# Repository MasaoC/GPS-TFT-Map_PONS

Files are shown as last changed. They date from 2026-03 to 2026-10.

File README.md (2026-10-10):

# GPS(GNSS)-TFT-map_PONS=Pilot Oriented Navigation System v7
ponsv6image


人力飛行機のパイロットが使いやすいことを目標とした航法装置です。琵琶湖の鳥人間コンテストに特化しています。
GPS/GNSS navigation for human-powered aircraft, specialized for the Japan International Birdman Rally at Lake Biwa, Japan.

 * **現在開いている「v7」は2027、2028年向けに開発設計中のブランチで、正常に動作しない可能性があります。**
 * **このブランチ（`PONSv7.1`）が v7 系の開発先です。** BNO085 を降ろし、
   SCH16T を FPC で外付けした v7.1 基板用。BNO085 を搭載した初代 v7 基板用は
   [`PONSv7`](https://github.com/MasaoC/GPS-TFT-Map_PONS/tree/PONSv7) ブランチです。
 * **v3〜v6が実際にフライト利用したことがある安定版です。**

---

## PONS を導入するメリット

**飛んでいる間の道具であり、飛んだあとの計測器でもあります。**
当日の誘導と、次の機体の設計の両方に活用できます。

### 鳥人間コンテストに特化している点
* すべての機能において、パイロット中心の志向で作られています。
* コース取りはパイロットが画面を見る必要はなく、音声だけで左右の指示が分かります。必要な時に必要なだけ音で変化を知らせます。
  * **Auto 10km** が折返しを認識し、誘導する（→ [大会本番での使い方](#大会本番での使い方auto-10km-モード)）
* 付随機能が豊富
  * **バンク角警告**と**昇降計**が、高度を失う前に気づかせる
* 風を読んでルートを選ぶ。対気速度センサーなしで、機上で**風向・風速を推定**します（→ [風の推定](#風の推定)）。 飛行中も更新されるので、追い風帯を選ぶ・向かい風を避ける根拠になる
* **v7 では PONS Link で、ボートにも同じ画面/数字が出る**

### 次の機体の設計に返す

SD に残るログを `tools/` の解析にかけると、機体特性の分析やパイロット証言の裏付けができます
（→ [ツール (tools/)](#ツール-tools)）。実際に分かったことの例:

* **縦の癖** フゴイド運動の周期、操縦によるものか機体によるものか。
* **横の癖** 2026 機体「陽還」には周期 12.5 秒のはっきりした揺れがあり、
  2025 機体「白夜」には無かった。上反角とラダーの違いが癖として出ていた → 上反角や尾翼まわりの見直しへ
* **構造の設計荷重。** 巡航中の鉛直加速度は実測で最大 +0.18 / −0.25 G（荷重倍数 1.17 / 0.77）
  → 桁の設計荷重の裏取りへ

---

## ドキュメントの役割

| | 中身 |
|---|---|
| **[PONS_HPA v7 説明書](https://docs.google.com/document/d/1KvTG9RTmQfcqMZj5Lb0X9cOWW-vuLJjpPzH3PTkBcsk/)**（Google Docs） | パイロット / ボートマン向け。使い方 — 画面の見方、設定手順、警告音の意味、大会当日の運用。画面写真つき |
| **この README** | 開発者 / 自作する人向け。中身の話 — 設計判断とその理由、部品と発注、生成ツール、ログの形式、実測データ |
| **[ナビゲーション仕様](docs/pons_navigation.md)** | 開発者向け。ロジックの要約 — 方位と距離の出し方、Auto 10km、コース警報 |
| **[音仕様](docs/pons_sound.md)** | 開発者向け。音の仕様 — WAV / トーン / バリオの 3 系統、優先度、同時再生 |
| **[無線 PONS Link仕様](docs/pons_link.md)** | 開発者向け。無線の仕様書 — プロトコル・電波法・実測 |
| **[立ち上げ試験](docs/pons_link_bringup.md)** | 開発者向け。基板到着後の立ち上げ試験手順 |

**使い方だけ知りたい方は説明書をご覧ください。** 取り扱い上の注意、スイッチ・LED の説明、
バッテリーの充電手順もそちらにあります。この README は「なぜそう作ったか」を残す場所です。

---

## 目次

- [PONS を導入するメリット](#pons-を導入するメリット)（誘導 / 風 / 設計へのフィードバック）
- [概要 / Abstract](#概要--abstract)
- [スペック (v7)](#スペック-v7)
- [設計と根拠](#設計と根拠)（姿勢推定 ESKF / 風の推定 / PONS Link 無線）
- [画面と機能の仕様](#画面と機能の仕様)
- [警告音・警報](#警告音警報)
- [大会本番での使い方（Auto 10km モード）](#大会本番での使い方auto-10km-モード)
- [設計上の留意事項](#設計上の留意事項)
- [ハードウェア](#ハードウェア)（発注受付 / 使用部品 / 自作の手順）
- [ソフトウェアのビルド](#ソフトウェアのビルド)
- [SD カードの構成](#sd-カードの構成)（ログ形式 / 目的地・パイロン座標の追加）
- [ツール (tools/)](#ツール-tools)
- [着水（水没）後の処理](#着水水没後の処理)
- [開発者向け](#開発者向け) / [ライセンス](#ライセンス)

---

## 概要 / Abstract

* Arduino（arduino-pico）で書かれた、TFT に GNSS マップ・位置・速度・方位・姿勢を表示する航法装置です。
* 大阪大学 albatross にて使用実績あり
  （2024 追走ボート: v3 / 2025 追走ボート: v4 / 2025 機体搭載「白夜」: v5 / 2026 追走ボート: v6 / 2026 機体搭載「陽還」: v6β）。2025 年大会優勝。
  * **v7 はまだ実戦投入していません。** 基板製作中で、実結線試験もこれからです。
* 最新のソフトウェアバージョンは **0.987**（Build 20261010）。
* 3D プリントケースおよび基板データ（KiCad）あり。ケースは PLA_LW が軽量でおすすめです。
  **v7 用ケースは作成中**で、現状 `case_3Dmodel/` には v6 用のデータしか入っていません。
* PONS for HPA = Pilot Oriented Navigation System for Human-powered aircraft。

### v7 での主な変更点（v6 から）

* **PONS Link（機体⇄ボート テレメトリ無線）を追加。** 920MHz LoRa。
  同じ機体を 3 台つくり、設定で送信機（機体 1 台）と受信機（ボート／プラットフォーム 2 台）を切り替えます。
  パイロットに出ている航法画面を、ボート側でそのまま再現できます（→ [PONS Link](#pons-link機体ボート-テレメトリ無線)）。
* **BNO085 を標準搭載**にし、**気圧計とは別のバス（i2c1）**へ分離。v6 では BNO085 と気圧計が
  i2c0 を共用しており、BNO085 のクロックストレッチでバスがロックすると気圧計も道連れになる
  故障モードがありました。バスを分ければ道連れは起きません。
  ※ v7 の設計当初は SPI 接続にしていましたが、**基板に触れるとジャイロが化ける現象が
  SPI でしか起きなかった**ため、0.976 で **i2c1 固定**にしました
  （→ [docs/imu_i2c_bringup.md](docs/imu_i2c_bringup.md)）。
* **FLASH を 16MB**（W25Q128）に拡張。

## スペック (v7)

| 項目 | 値 |
|---|---|
| サイズ / 重量 | W59 × H81 × D20 mm。重量は **v7 実機での計測待ち**（参考値：v6β 62.4g） |
| TFT | 2.8 インチ **1000 ニト**（v5 の 600 ニトから向上し、晴天下でも視認可）。スイッチで輝度調整可 |
| GNSS | u-blox SAM-M10Q（基板天面配置）。位置精度 1.5m / 速度精度 0.05m/s / 更新レート 2Hz / Cold start 23 秒 |
| 気圧センサー | MS5611。温度・気圧を 2Hz で SD へ記録 |
| モーションセンサー | BNO085 **標準搭載**（v6 では 2 個中 1 個の β 試験版）。i2c1 接続（気圧計とは別バス） |
| 姿勢推定 | **ESKF**（GNSS + BNO085）。実験時の精度はロール・ピッチ 約 1°(95%)、ヨー 約 5°(95%) |
| バリオメーター | **KF**（BNO085 + MS5611）。標準で使用可 |
| 無線 | **PONS Link**。920MHz LoRa（E220-900T22S(JP)、技適取得済・免許不要）。1Hz 送信、実測到達距離 **350m**（要求 200m の 1.75 倍） |
| バッテリー | 860mAh。USB Micro-B で充電（5V1A で十分、空から満充電まで 2〜3 時間）。充電ステータス LED あり |
| 電池持続 | 高輝度 約 3 時間 / 低輝度 約 12 時間 |
| FLASH | 16MB（W25Q128）。ベクタ地図・起動ロゴ・フォントを内蔵 |
| SD 記録 | 緯度・経度・対地速度・時刻・GNSS 精度・捕捉数を 2Hz、気圧・温度、IMU 生ログ、設定と状態と電圧（→ [SD カードの構成](#sd-カードの構成)） |

PONS Link は受信モードで常用すると **+8.2mA**（低輝度で 1 時間ぶん短くなる計算）、
送信モードは **+4.3mA**（SF8・1Hz）です。受信モードのスリープは今後の実装予定で、実装すれば 8.2mA より下がります。

---

## 設計と根拠

ここから先は「なぜこの実装になっているか」の記録です。使い方は説明書を参照してください。

### 姿勢推定（ESKF）

BNO085 内蔵の姿勢推定は、加速度計が測る「比力」を鉛直とみなすため次の 2 つで系統的に誤ります。

* **定常旋回中はロールを過小評価する**（協調旋回では比力の横成分が厳密に 0 になり、加速度計にバンクが見えない）
* **加減速中はピッチがずれる**

また BNO085 単独の YAW 角の基準は「磁場のみ」で推定していましたが、磁場は機体や周辺電子機器の影響で
簡単に 30 度以上の誤差が出てしまい、YAW 角の絶対精度は著しく悪く使えませんでした
（0.983 で地磁気は初期ヨーからも外しました。下記）。

そこで GNSS の TT（航跡角度）と GS（対地速度）を観測に入れた自前の姿勢推定
（誤差状態カルマンフィルター＝ESKF）を実装しました。
対地加速度が分かると比力から遠心力・加減速分を差し引けるので、真の重力方向が求まります。
同時にセンサーの真方位角も求められます。

* 車載実測での単位前後加速度あたりのピッチ誤差：**BNO085 4.4〜5.6 → ESKF 0.2〜0.5 deg/(m/s²)**
* 傾斜台での絶対精度：**-0.46〜-0.63 度**、直交軸への漏れは 0.6 度以下

#### 初期化（0.983 で BNO085 の融合出力への依存を外しました）

0.982 までは初期姿勢を BNO085 の融合出力（GAME_ROTATION_VECTOR）から、初期方位を
地磁気補正付きの ROTATION_VECTOR から貰っていました。0.983 で両方やめ、
**生のジャイロと加速度だけで初期化する**ようにしています。

1. **ロール・ピッチ** … 静止（2 秒）中の平均加速度が重力方向なので、そこから水平を作ります。
   実ログ 5 セッションで GAME_RV とロール・ピッチが **0.05 度以内**で一致したので、
   BNO085 の融合出力は初期姿勢に何も足していませんでした。
2. **ヨー** … 対地速度が 3m/s を超えた最初の測位の**航跡**から入れます。しきい値が
   飛行速度（対気 5.8〜9.0m/s）より十分低いので、注入の瞬間に機体は必ず接地しており、
   **航跡＝機首方位が厳密に成立します**（横滑りできないのでクラブ角が入らない）。
   2025 大会の実機体ログでは発進から 2〜3 秒で条件を満たしていました。
   ヨーが入るまでは `yaw acc` が 180 度のままなので、画面は自動的に方位を灰色にします。
3. **待機中** … ヨーが入るまでは GNSS 速度観測を通しません（ヨー誤差がロール・ピッチへ
   転嫁されるため）。そのあいだ観測が無いので、静止しているあいだ重力方向へ寄せ続け、
   同時にジャイロのゼロ点を測ります。**プラットホーム上で何分待ってもロール・ピッチが保たれます。**

地磁気をやめたのは精度の理由です。2026-09-30 の実測で、地磁気由来の方位は
GNSS 航跡から **57.8 度**ずれていました（BNO085 自身は「25 度以内」と申告）。
GNSS 航跡は真方位なので磁気偏角の補正も要らなくなりました。

副産物として、この経路は**融合出力も地磁気も持たないセンサー**でもそのまま動きます
（→ [docs/imu_sch16t_plan.md](docs/imu_sch16t_plan.md)）。

#### 重力観測（0.984 で足しました）

0.983 で GRV をやめたことで、**GNSS が途絶している間はロール・ピッチを引き戻すものが
1 つも無くなりました**（ジャイロ積分だけになる）。そこを埋めるのがこれです。

準定常のとき、比力をワールド系へ回した値は (0, 0, g) になるはずなので、
**その水平 2 成分を「0 であるべき観測」として入れます**（2Hz）。

* **主ゲートは旋回レート。** `|f| ≒ g` では人力機のバンクを判別できません
  （5 度バンクの `|f|-g` は 0.0375 m/s² で、加速度計のスケール誤差 0.098 m/s² に埋もれる）。
  旋回レートなら 5 度バンクで 6.14 deg/s あり、ジャイロのゼロ点 0.1〜0.3 deg/s に対して
  20〜61 倍の余裕があります。**ジャイロだけで作れるので GNSS 断中も働きます**
* 2026-10-03 の走行 2 時間で検証：GNSS を途中で打ち切ると姿勢誤差の中央値が
  **21.3 → 1.3 度 / 74.9 → 1.8 度**。ゲートは走行中 58〜61%・静止中 97% 開いていました
* 60 秒ログの `gobs=` が観測を入れた累計回数です。**増えていなければゲートが閉じています**

#### Roll/Pitch/Yaw 機能の一括 ON/OFF（マスタースイッチ）

IMU/ESKF 画面の `Roll/Pitch/Yaw func` を OFF にすると、姿勢に関する機能が全て止まり、
見た目も動作も ESKF 導入前と同じ状態に戻ります（設定は SD に保存されます）。対象は次のとおり。

* **表示（8 項目）**：`Avg10s P`（10 秒平均ピッチ・大きい字）/ `P`（瞬時ピッチ）/ `R`（ロール）/
  `Rtrim`（自動トリム累積量）/ 風ベクトル矢印（中心の風向 3 桁を含む）と `W x.xm/s` / `Y95`（ESKF ヨー精度）/
  自機アイコンの機首向き回転 / 偏流角の点線
* **警報（4 項目）**：バンク警報（4°・1 秒継続）/ 地上ロールチェック（SET ROLL から 3°・60 秒）/
  地上ピッチチェック（SET PITCH から 3°・60 秒）/ `REMOVED FROM MOUNT` と赤ステータス丸
* **裏で走る処理（3 項目）**：自動ロールトリム / 風推定 / `imu_replaydata/` への 5Hz 記録

ESKF の計算自体は止めません（2 ページ目の診断表示を生かすためと、ON に戻した瞬間から使えるようにするため）。

### 風の推定

「ピッチ 0 度で 7.0m/s で飛ぶ」という設計前提からピッチ→対気速度を引き、
`風ベクトル = 対地速度ベクトル - 対気速度ベクトル` で求めます（対気速度の向き＝機首方位と仮定）。

ピッチ θ [度] から対気速度 V [m/s] への換算は次の式です。

```
V(θ) = V0 * sqrt( K / (K + θ) )        既定: V0 = 7.0 m/s, K = 10 度
```

近似曲線ではなく、定常飛行の釣り合いそのものです。揚力 = 重量 より
`½ρV²S・CL = W` なので `V ∝ 1/sqrt(CL)`、CL が迎角に対して直線なら
`CL(θ) ∝ (θ + K)` と書けます。**K は「揚力がゼロになるピッチまでの角度」**で、
K = 10 は「ピッチ -10 度で揚力ゼロ」を意味します。
0.969 までの区分線形（+5 度/5.8、0 度/7.0、-4 度/9.0 の 3 点）とは
最大 0.17m/s しか違いませんが、当てはめた範囲の外でも形が崩れません。

**係数は機体・重量・重心で変わるので、SD の `settings.txt` から機体ごとに設定できます。**
既定値は `settings.h` の `AIRSPEED_*` です。

| キー | 意味 | 既定 | 受け付ける範囲 |
|---|---|---|---|
| `airspeed_v0` | V0：ピッチ 0 度での対気速度 [m/s] | 7.00 | 3〜20 |
| `airspeed_k` | K：揚力がゼロになるピッチまでの角度 [度] | 10.00 | 3〜60 |
| `airspeed_min` | 推定の下限 [m/s] | 5.80 | 1〜20 |
| `airspeed_max` | 推定の上限 [m/s] | 9.00 | 1〜25 |

* 範囲外の値は端でクランプし、理由を `log.txt` に残します（黙って既定へ戻すと
  「書いたつもりで効いていない」状態になるため）。数値として読めない行は無視します。
* 読み込み後の実効値は起動時に `log.txt` へ残ります
  （`AIRSPEED MODEL v0=7.00 k=10.00 range 5.80..9.00`）。**まずここを見てください。**
* `settings.txt` は**装置が保存のたびに書き直します。** 書き込んだコメント行は消えるので、
  メモは別ファイルに残してください。値そのものは保持されます。
* 上下限は「この機体で起こり得ない対気速度を出さない」ための安全弁です。
  K を小さくしすぎると `K + θ` がゼロに近づいて発散しますが、そのときは上限で打ち切ります。

* **直進中しか更新しません。** 旋回中の人力飛行機は横滑りが大きく、横滑り角 beta があると
  風速の誤差が `対気速度 × sin(beta)` になります（beta=30 度なら 3.5m/s）。旋回中は直前の値を保持します。
* 表示されるまでに**直進が累計 10 秒**必要です（`WIND_LPF_SEC`）。
* ヨー精度の 95% 値が 10 度未満のときだけ表示されます。条件を満たさない間もその値（`Y95`）は常に見えます。
* **ヨーは補正対象外です。** 対気速度センサーが無いため、風によるカニ角を原理的に補正できません。
  またヨーは水平加速度がある間しか可観測にならないので、等速直進が続くと精度が落ちます。
  信頼できないと判定した間はグレー表示にし、自機アイコンも機首方向へ回しません。

### PONS Link（機体⇄ボート テレメトリ無線）

同じファームウェアの PONS を **3 台**つくり、SD カードの設定で役割を決めます。

| 置き場所 | モード | 役割 |
|---|---|---|
| 機体 | TX | パイロットの航法装置。これが本番 |
| 追走ボート | RX | 機体の画面を再現する。ボートマンが見る |
| プラットフォーム | RX → 途中で OFF | **予備機**。機体の PONS が壊れた／電池切れのとき TX へ切り替えて載せ替える |

目的は **パイロットに出ている航法画面をボート側でそのまま再現すること**です。
地図・対地速度・高度・姿勢・風・平均ピッチまで、送信側の画面がそのまま映ります。
コース警報やバンク角警告も、受信側が**受け取った値から自分で計算し直して**鳴らすので、
機体側と同じタイミングで同じ音が出ます。

これによって次の 3 つが得られます。

1. **飛行ログの冗長化。** 機体の水没・ロストでデータを失いません。受信側は姿勢・風まで
   `received/` に記録するので、機体の SD が失われても ESKF の解析ができます。
2. **風の共有。** ボートの PONS 単体では風を推定できません（対気速度が測れないため）。
   機体で推定した風速・風向を受け取ることで、**アシストするボートマンが風の状況を把握できます。**
3. **トリム量の共有。** 機体のピッチは刻々と変動しますが、その**平均値＝トリム量**は平均対気速度に
   対応します。これを見て**ボートマンが的確なエレベータートリム量を指示できます。**

#### 設計上の決めごと

* **通信は下り一方向だけ**で、ボートから機体へ返すものは何もありません。
  受信側の不具合が飛行中の機体へ波及する経路が**原理的に存在しません**。
  大会レギュレーション上も「操作には使えない」ことを設計で示せます。
* **受信が 10 秒途切れると**「RECEIVER MODE. NO SIGNAL.」を表示し、自機の情報表示へ戻ります。
  このとき**バリオを含めて全機能が動きます**。万一受信機モードのまま離陸しても使えるようにするためです。
* プラットフォーム機は機体が離れると当然ロストします。**これは想定どおり**で、ロストを画面と音声の
  両方で知らせたあと、人が OFF にする運用です。予備機である以上、電波が来ているかどうかは
  常にはっきり分かるほうがよいと考え、自動で静かにする仕掛けは入れていません。
* **受信モードでは色付きの枠**を出します。数値の意味が「機体」と「自機」で入れ替わるため、
  どの画面にいても分かるようにしてあります。切り替わりは音でも知らせます。
* 電池は `S50R40%` の形で**送信側と受信側の両方**を表示します。
* 目的地とナビモードは**送信側に自動で合わせます**（RAM 上のみ）。食い違うとコース警報だけが
  静かにずれるためです。上書きしたことは音声で知らせます。
* **送信機が 2 台いる**（機体用とボート用の取り違え）と受信側が検出して警報します。
* **ボート自身の位置**を明るい緑の小さな点で地図に重ねます（受信中のみ）。地図は機体を中心に
  描かれるため、そのままではボートが地図上に存在しないためです。2m/s 以上で進んでいるときは
  進行方向へ短い線が伸びます。ボート自身の航法には v6 以前の機体を併用してください。
* 地図の左上に**アンテナ本数（0〜3 本）**を出します。ロスト時は 0 本の上に赤い×が重なります。
  本数は「感度限界からの余裕」で決めているので、SF を変えても意味が保たれます。
  送信モードでは本数ではなく、飛行機アイコンから電波が出ている絵にしてあります
  （受信していないので強度を測れず、測ったように見せるべきでないため）。
* **リプレイ中とデモ中は無線を OFF として扱います**（0.985〜）。画面の数字が電波と
  無関係なので、枠・アンテナ本数・`NO SIGNAL` のポップアップ・`S50R40%` の 2 本立て電池は
  どれも出しません（出すと、そのとき送信機／受信機だったかのような画面になります）。
  送信も止まるので、デモの仮想機体が電波に乗ることもありません。理由は WIRELESS 画面の
  `Hold` 行に出ます。設定値は書き換えないので、デモを切れば次のスロットから戻ります。
* **受信したデータはリプレイできます。** リプレイ画面の `SOURCE` を `RECEIVED` に切り替えると、
  `received/` のログ（電源を入れるごとに 1 ファイル）を選べます。姿勢・風もそのまま再生され、
  再生中は `REPLAY RX` と表示されます。なお受信モード中はルートの飛行 CSV に**ボート自身の**
  データが記録されているので、画面に出ていなかったボート自身の画面もあとから再生できます。

#### 無線の設定

| 項目 | 値 |
|---|---|
| モジュール | E220-900T22S(JP)（920MHz LoRa、技適取得済・免許不要） |
| 帯域幅 / 拡散率 | 500kHz / **SF8**（設定で SF7〜SF11） |
| チャンネル | CH0〜12（920.8〜923.2MHz） |
| 送信出力 | 13dBm（20mW）。アンテナ 2dBi、EIRP 15dBm |
| 送信周期 | 1Hz |
| 1 回の送信時間 | 98.4ms（SF8・65 バイト。メーカーの送信時間計算表による） |
| 消費電流 | 送信機 平均 4.3mA（瞬間 43mA）／受信機 8.2mA 連続（スリープは実装予定） |

設定項目は `link_mode`（OFF / TX / RX）、`link_radio_ch`、`link_radio_prof`、`link_group` の 4 つです。

`link_group` は同じ会場に別チームの PONS がいても取り違えないための識別子で、**既定は 0**。
CH と SF が偶然一致すると他チームの機体を受信してしまうため、**0 以外を各機の SD に設定してください**
（3 台とも同じ値。値は SD の `settings.txt` にだけ書き、git には既定 0 しか入れていません）。
グループ違いの電波を受けたときは「無信号」ではなく `GROUP n FOUND` と表示します。
無信号と区別できないと、SD が飛んでグループが 0 に戻った事故に気づけないためです。

CH / SF / Group のどれかを変えて設定画面を出ると、
**「送信機と受信機の設定が一致していることを確認してください」**と音声で確認を促します。
送信側が電波状況を見て勝手に設定を変え、受信側へ伝え忘れる事故を想定しています。**送信機・受信機の両方で鳴ります。**

起動時とモード切替時に「送信機モード」「受信機モード」「リンクオフ」を
**音声で読み上げます**（0.985 から 3 状態すべて）。読み上げない状態があると
「何も言わない＝正常」と受け取られてしまうためです。0.984 までは OFF を無音にして
「無音＝OFF」と取り決めていましたが、無音は音量を絞っているだけの場合と区別が
付きませんでした。

#### 実測（2026-09）

| 条件 | 設定 | 到達距離 |
|---|---|---|
| 芝生（凹凸あり） | 500k SF5 | 約 100 m |
| 同上 | 500k SF8 | 約 190 m |
| **海辺・平坦なコンクリート・夜間** | **500k SF7** | **約 350 m** |

* 環境雑音は熱雑音 +7dB（BW500kHz で約 −104dBm）。屋内外でほとんど変わりません。
* **アンテナの置き方が拡散率より効きます。** 角度が 60° ずれると 6dB 失いますが、
  SF を 1 段上げても 2.5dB しか稼げません。アンテナは高く、偏波を揃えて設置してください。
* **水面での挙動は未確認**です（試験はコンクリートと芝生のみ）。

#### 電波法について

E220-900T22S(JP) は技適取得済みで、免許は不要です。ARIB STD-T108 の CH0〜12 を使います。
ボートから機体へ「操作」を送る機能は作りません。通信は下り一方向だけで、
上りの通信路そのものが存在しないため、遠隔で機体を変更する経路は物理的にありません。

設計の詳細・データシートの落とし穴・電波法の扱いは [docs/pons_link.md](docs/pons_link.md) に、
基板到着後の立ち上げ手順は [docs/pons_link_bringup.md](docs/pons_link_bringup.md) にまとめてあります。

---

## 画面と機能の仕様

しきい値と色の一覧です。画面写真つきの説明は説明書を参照してください。

* **画面上部**：左に対地速度 (m/s)。右の大きい枠は **平均ピッチ**（ラベル `Pavg`）。
  対地進路は地図を見れば分かるがピッチは他に得る手段が無いため、一番目立つ枠をこちらに使う。
  BNO085 非搭載機・姿勢機能 OFF・平均が未収束のときは従来どおり真方位（ラベル `TT`）。
  対地速度は 2.0m/s 未満でグレー表示。左上に `GS` と `sAcc`（速度精度、色分け）。
* **画面中央**：地図（ファームウェア内蔵のベクタ地図 ＋ SD の `mapdata.csv`）と TT の針。
  右上の枠が `Pavg` のときは、画面中央上部に真方位を `TT 232` の形で表示する。
  * 旋回角速度表示（1.5 秒平均 deg/sec）。1.0deg/s 超えで着色、左右端に表示。
  * 旋回すべき修正方向の表示（赤矢印）。コースズレ 15° 以上で表示・点滅。55° 超でもう 1 本出る。
  * コース警報 Arc：向かうべき方位 (TC=True Course) への赤線円弧。10〜60 秒放置で音声警報。
  * 過去の航跡は緑色の線。最大 500 地点（約 25km 分）を表示。
  * 琵琶湖付近にいる場合、タケシマ・北パイロン・南パイロンに向けて自動で線が引かれる。
    パイロンが表示され、折り返し目安の 10.975km 円が描かれる。
  * NORTH UP / TRACK UP 切替対応。
  * 30 度範囲表示：針の先の三角形（薄い線）が過去の針路から左右 15 度の範囲を示す。
    15 度を超えるたびに三角形が更新され、警告音＋「トラック」音声が鳴り 8 秒間点滅する。
* **画面左下（姿勢表示）**：上から順に、**風ベクトルの矢印** → `W 1.5m/s`（風速）→
  `Y95 4°`（ヨー精度の 95% 値）→ `P`（瞬時ピッチ）→ `R`（ロール）→ `Rtrim`（自動ロールトリムの累積補正量）。
  平均ピッチはヘッダー右の大きい枠へ移したので、ここには出ません。
  * ロールがバンク角警告のしきい値（4 度）を超えると**赤**。
  * ロールまたはピッチの絶対値が 10 度以上だと**グレー**（設置ミスを疑うべき値）。赤より優先。
  * `Rtrim` は累積が 1.5 度以上でオレンジ、3.0 度以上で赤。
  * 風の矢印は**風が吹いていく方向**を指し、地図と向きが揃う。長さは固定で強さは色で表す
    （2m/s 以下=緑 / 4m/s 以下=青 / 超=紫）。
  * 矢印の回転中心に**風向（真方位・3 桁）**を出す。こちらは気象通報と同じ
    **風が吹いてくる方向**なので、矢印の指す先とは 180 度逆を向く（南西の風なら `230`）。
    字の大きさと色は機首方位（自機アイコン下の 3 桁）に合わせてある。表示条件は矢印と同じ。
  * ヨーが十分信頼できるとき（95% 値 <10 度）、機首の先に**偏流角を示す点線**が出る。
  * 自機アイコンは、ESKF のヨーで機首を向けているとき**黒**、対地進路を向けているだけのとき**グレー**。
  * 較正が必要なときは `ESKF CALIBRATION REQUIRED!` を赤字で、未収束のときは `ESKF Not ready` を表示。
* **画面下部**：時刻（JST）と 最大 GS（過去 5 分・累計）と発生時刻。
  緯度・経度は v0.94 で削除した（飛行中に読む場面が無いため）。sAcc は左上へ移動。
* **画面下部 2**：目的地コース (True Course) / 目的地までの距離（km、直線距離）/ 捕捉衛星数（10 以上で緑）/ 電池残量 (%)
* **画面最下部**：目的地モード（FLY INTO / FLY AWAY / 10K INTO / 10K AWAY）/ 目的地名 / SD 認識表示（正常=緑、エラー=赤）
* **状態表示**：`Acc: XXm`（水平位置精度 1σ、10m 以上のとき表示）、`Scanning GNSS Signal`（起動直後）、
  `Weak GNSS Signal`（衛星数 0）、`NO GNSS connection !!`（GNSS 通信不可＝要再起動）
* **ロガー**：緯度/経度/対地速度/時刻を SD へ保存（GNSS 位置捕捉時、1 秒に 2 回）。気圧データも記録。
* **バリオメーター**：昇降計。設定画面でボリューム 0 にすると無音・非表示。
  デッドバンドは ±0.25m/s（BNO085+MS5611 の KF 融合時。BNO085 が応答しない場合は MS5611 単独へ
  フォールバックし ±0.6m/s）。v7 は BNO085 標準搭載なので全機で使えます。

### 設定画面

NAV 画面でスイッチ長押しで入ります。**項目の一覧と操作手順は説明書を参照してください。**
ここには、あとから理由を思い出せなくなる部分だけを残します。

各行の右端の丸が設定状態を示します。
**緑**＝本番推奨設定、**赤**＝本番では不可（デモ/リプレイが有効など）、
**オレンジ**＝本番でも許容だが既定から外れている。**本番前に赤が無いことを確認してください。**

* 地図の拡大率は NAV 画面でボタンの**ダブルクリック**でも変更できます
  （誤操作防止のためシングルクリックでは変わりません）。通常使用する zoom11 のとき緑、それ以外は赤。
* 設定は SD カードに保存し、次回起動時に自動読込します。ただし **DEMO / REPLAY モードは保存しません**。
  電源を入れ直せば必ず本番設定に戻る、という安全側の作りです。NAV 画面の scale（拡大率）は保存されます。
* 画面下部にバッテリーの目安持続時間と CPU 温度を表示します。
  CPU 55 度（外気温 35 度）までは動作確認済み。2026 年大会では CPU 最大 48 度でした。

#### リプレイモード

SD カードに保存された**飛行 CSV をそのまま再生**します。操作は説明書を参照してください。

* v5 までのように Python で NMEA へ変換する必要はありません。**列名で解釈する**ので、
  v5〜v6 のログも、後から列を足したログもそのまま読めます。
* **一覧の並びはファイル名順ではなく、SD カードへ書き込まれた順（ディレクトリの登録順）です。**
  過去大会のログなど上に出しておきたいものは、カードへ**最初にコピー**してください。
* 設定用の CSV はルート直下にあり、リプレイ一覧は `data/` と `received/` しか見ないので、
  設定ファイルを誤って再生対象にする経路がそもそもありません。
* **再生を続けられなくなったら、音を鳴らして取り消し、通常の GNSS に戻ります。**
  黙ってファイルを開き直し続けると、地図が固まったまま SD を叩き続けることになるためです。
  理由は `log.txt` に残ります。
  * `REPLAY canceled: file is not a flight log` … 開けない / ヘッダが無い / 空
  * `REPLAY canceled: SD not available` … SD カードが読めなくなった

#### IMU / ESKF 画面

2 ページ構成（短押し=カーソル移動、長押し=実行）。

1 ページ目は飛行前の点検手順の順に並べてあります。

1. `SET PITCH`：「いま機体のピッチは何度か」の申告値（-3.5〜+2.0 度、0.5 度刻み）
2. `SET ROLL`：同じくロールの申告値（±3.0 度、既定 0）。通常は 0 のままにする。
   横風でウィングロー保持のまま較正せざるを得ないときだけ使う。0 以外はオレンジ表示＋音声で警告。
3. `APPLY`：上の申告値で機体ゼロ点を較正。本番プラットホーム（-3.5 度）でもその値を申告すれば正しく較正できる。
   **ボタンを離してから 1 秒後に実行される**（スイッチを押す力でマウント上のデバイスが傾くため）。飛行中は実行できない。
4. `Roll/Pitch/Yaw func`：姿勢に関する機能の一括 ON/OFF

各行の右端に状態の丸が出ます。画面右上の丸が緑にならない原因をここで辿れます。
緑の条件は「ESKF が収束」「Roll/Pitch/Yaw func が ON」「Roll trim during flight が ON」
「自動トリムの累積が 1.5 度未満」の 4 つ。較正が必要なときは赤。

2 ページ目はセンサー生値と ESKF の内部状態（診断用）、および
`Roll trim during flight` / `Wind estimate` の ON/OFF（既定はどちらも ON）。

---

## 警告音・警報

旋回・航路系の警報:

* **旋回率警告音**：旋回率が 2deg/s を超えるとピピと高音（v6 では音程固定）。2.0m/s 以下では鳴らない。
* **航路 (TRACK) 警報**：左右 15° 範囲を超えて航路が変わると Chime 音＋「Track！」音声。
* **コース警報**：針路のズレが 10〜60 秒放置されると 4Chime ＋「針路、右(左)に旋回」音声。
  コース警報 Arc がピンク線 (TC) に到達すると鳴る。
  * 15° 未満のズレでは鳴らない。15° で 60 秒、90° 以上で 10 秒放置が条件。
    修正操作中は鳴らない。前回警報から 30 秒以内は再警報しない。GS が 2m/s 以下でも鳴らない。

目的地系の警報:

* **目的地自動更新音**：Auto 10km モードで 10K AWAY ↔ 10K INTO 切替時に 4Chime ＋音声。切替時に 1 回のみ。
* **目的地確認**：目的地まで 100km 以上あると 120 秒に 1 回、確認を促す音声。

電源系の警報:

* **電圧低下警報**：3.5V 未満で音声案内（60 秒に 1 回）。この警告のみ強制的に最低音量 60 で鳴る。
  * 画面モードにも無線モードにも依存せず鳴る。USB 充電中とリプレイ中は鳴らない。
  * **受信モードでは、機体（送信機）の電池低下も別の音声で知らせる**（`battery_low_sender.wav`）。
    本番では飛行中に交換できないが、試験飛行ではボートが先に気づいて降ろす判断ができる。

### バンク角警告と姿勢まわりの警報

* ロールの絶対値が 4 度を超えた状態が 1 秒以上続くと音声警報。
  2026 年大会の実測（45 分）では 3 回鳴る計算です（継続条件を付けないと 31 回鳴ってしまいます）。
  * 誤警報の連発を防ぐため、一度鳴ったら**ロールが 3 度未満に戻り、かつ 10 秒（音声の再生時間）経つまで**再警報しません。
    センサーのズレで 4 度超過が続いている場合は、時間が経っても鳴りません。
    起動時も「発報済み」の状態から始まるので、電源投入時点で既に 4 度を超えていても鳴りません。
* **待機中（静止・対地 1m/s 以下）は別建てで見張ります。** SET ROLL / SET PITCH からのズレが
  3 度を超えた状態が 60 秒続くと音声で知らせます（2 分に 1 回上限）。自動ロールトリムは対地 3m/s 超で
  しか働かず地上では動かないため、マウントのズレを直せる唯一のタイミングを別の仕組みで補います。
* **マウントから外すと検出します。** ロールかピッチが 30 度（右バンクのみ 40 度）を超えると
  「手に持って外した」とみなし、次に APPLY するまで地図と設定画面に赤で警告を出します。
  この状態は SD に保存され、電源を切って充電しても保持されます。
* **ただしこの検出は ESKF が回っている間しか働きません。** 電源を切ったまま外して付け直すと、
  傾きを観測できないので検出できません。そこで **最後に APPLY した日（JST）** を SD に残し、
  **日付をまたいでいたら** IMU / ESKF 画面の注意書きを `! CALIB IS FROM MM/DD` に変え、
  地上で一度だけ `eskf_calib_oldday.wav` を鳴らします。日付は 2 ページ目の
  `level offset` 行の右にも常に出ます（`--/--` は不明）。
  断定はしません（付けっぱなしで日をまたぐこともあるため）。地図表示・ヘッダの取り消し線・
  PONS Link の fault には**乗せません**。音を繰り返さないのは、プラットホームの上で鳴ったときに
  「止めるために APPLY」されると、正しかった較正が台の姿勢で上書きされてしまうためです。
  測位できていない場所で APPLY した場合は日付が「不明」になり、この判定は働きません。
* 同じ理由で **Roll trim during flight**（直進中のロール自動トリム、2 ページ目）があります。
  直進が 60 秒続くごとに評価し、**2 回続けて同じ向きに 0.5 度以上**のズレが出たときだけ
  0.5 度ずつゼロへ寄せます（累積上限 5 度）。2 回の一致を要求するのは、60 秒窓の平均ロールが
  実測で std 0.27 度ばらつき、1 回だけの判定ではノイズで補正してしまうためです。
  補正量は `log.txt` に記録されます。旋回中は一切働かないので、真のバンクは消えません。
* どちらも設定画面で OFF にできます。OFF にすると IMU / ESKF 行の丸がオレンジになります。

### 無線（PONS Link）関連（v7〜）

* 起動時とモード切替時に「送信機モード」「受信機モード」「リンクオフ」を読み上げ（3 状態すべて）。
* ミラー ⇄ NO SIGNAL の切り替わりを音で通知。復帰は短い和音、喪失は音声。
* 目的地を送信側に合わせて自動変更したとき、音声で通知。
* 送信機が 2 台いることを検出したとき、低音 3 回＋音声（設定ミスは飛ぶ前に気づく必要があるため）。
* CH / SF / Group を変更して設定画面を出たとき、設定一致の確認を促す音声。
* 無線モジュールが応答しないとき、音声。音声は本体 FLASH にあるので SD が無くても鳴ります。
  **飛行中にモジュールが死んだ場合も検出します**（10 秒ごとに応答を確かめ、
  30 秒で無応答と判定）。上りが無いので、これが無いと「送れているつもり」のまま
  飛び続けることになります。
* **機体の電池が低下したとき、受信側で音声**（60 秒に 1 回）。受信が切れれば止まります。
* 機体の SD / IMU / 較正未適用の異常は、立ち上がりで低音 2 回のみ（内訳は WIRELESS 画面）。
* **送信モードに入った直後、5 秒間チャンネルを聴いてから送り始めます**（送信前チェック）。
  合格なら上昇 2 音。問題があれば音声で知らせますが、**送信は止めません**
  （予備機を緊急で載せ替える場面で送信が始まらないほうが危険なため）。
  * `link_ch_busy.wav` … 同じチャンネルに他の送信機がいる（**送信機が 2 台**／他チームの PONS）
  * `link_ch_noisy.wav` … 雑音が高い。チャンネルを変える
  * 結果は WIRELESS 画面の `Preflt` 行と `log.txt` の `LINK PREFLIGHT:` に残ります

---

## 大会本番での使い方（Auto 10km モード）

* 目的地はパイロンではなく **PLATHOME** を選択し、Navigation Mode を **Auto 10km** にする。
* 自動で FLY AWAY（表示は `10K AWAY`）で始まる。プラットホーム上や上昇中はプラットホームから
  離れる方角（南東）を指すが正常で、数秒飛べば北西方面の指示に変わる。
* このモードはパイロンへは誘導せず、**プラットホームから離れる最短距離の方角（マゼンタ線=TC）** に
  誘導する設計。風は考慮していない。
* パイロンに向かいたい場合は、画面上の北パイロン・南パイロンへの線と True Track (TT) を見て
  パイロット自身が判断する。**2026 ルール**ではプラットホームから各パイロンへの TC はそれぞれ
  **328°（北）** と **258°（南）**（真方位。`navdata.h` の座標から計算した値）。
* 目的地から 10.475km 離れると自動更新音が鳴り `10K INTO` に切替。以降はパイロンを旋回したかに
  関係なくプラットホームへ戻る警告が出るので、**目視で折り返しを終えるまではコース警報を無視する**。
* 復路で目的地から 1.5km 以内に入ると再び `10K AWAY` に切替。同様に警告を無視して目視で
  1km パイロンを探して旋回する。
* 実際のパイロン位置は目安の 10.975km 円からズレる（2025 大会では 5km 通過で膨らんだ）。
  6km 過ぎたあたりから目視で探すこと。
* 目的地の `N_PILON` / `S_PILON` は、飛行中に急遽反対側のパイロンへ向かう場合に FLY INTO で
  直接誘導するためのもの（主にボート側での操作を想定）。
* 折り返しの状態（10K AWAY / 10K INTO）は SD カードに保存することで保たれます。飛行中/乗船中に
  再起動しても、直前のモードに復帰し、再開します。10K INTO のままプラットホームで電源を入れた場合には
  「1.5km 以内なら AWAY」のルールで自動的に復路→往路へモードが切り替わります。
  このとき目的地が変更された警告音声が鳴りますので、AWAY か INTO か正しいモードか確認を促します。

## 設計上の留意事項

使用者（パイロット/ボートマン）に向けた留意事項は、ここには記載しません。Google Docs の説明書を確認してください。

* 方位はすべて真方位（True）で、磁方位を廃止しました。機体に磁気コンパスを載せない方針になったため、
  磁方位と真方位が混在する意味が無くなったからです。
* **方位の精度は対地速度に依存する。** 移動速度が遅いと方位が大きく変化しやすい。
  徒歩ではばらつくが、ジョギング (3m/s) 以上で安定する。
* **航路 (TRACK) 警報が鳴っても、すぐに画面を注視しないこと。** 警告音は航路変化＝姿勢変化を
  知らせている。まずバンクなど機体姿勢の安定が最優先。姿勢が落ち着いてから修正方向・修正量の確認に使う。
* 稼働時は捕捉衛星数が 10sats 以上（緑色）、`sAcc: 0.2m/s` 以下になっていることを確認するとよい。
* パイロン座標は 2026 ルールに合わせてありますが、現実のパイロン位置はズレることがあるようです
  （SD カードで上書きできます。後述）。

---

## ハードウェア

### 発注受付

個人事業主として受注します。

* **フル機能**（GNSS ナビ・バリオ・無線・姿勢推定すべて）：1 個 4 万円（SD カード・ケース込）
* **GNSS ナビ機能のみ**（バリオ・無線・姿勢推定なし）：1 個 2 万円（製造・材料費が安くなるため）
* 2 個以上ご注文の場合は相応に割引します。
* 価格・納期・送料は個別にご案内します。見積もりをご希望の方は masaochiguchi@gmail.com までお問い合わせください。
* 納品前に動作確認します。納品後のサポートを希望される場合は別途ご相談ください。

### 使用部品 (v7)

| 部品 | 型番 | 備考 |
|---|---|---|
| マイコン | RP2350B (QFN-80) | 外付け FLASH 16MB（W25Q128） |
| GNSS | ublox SAM-M10Q | 基板表面実装 14 ドル |
| TFT | Newhaven NHD-2.8-240320AF-CSXP-F-ND Rev1B | 2.8 インチ 1000 ニト 29 ドル |
| バッテリー | マルツ DTP603048 860mAh | 1s、過充電・過放電保護回路付き 1850 円 |
| 充電コントローラー | MCP73831 | 秋月 90 円 |
| 気圧センサー | MS5611 | 気圧を 2Hz で記録 |
| モーションセンサー | BNO085 | v7 は標準搭載。i2c1 接続（気圧計の i2c0 とは別バス） |
| **無線モジュール** | **E220-900T22S(JP)** | 920MHz LoRa。技適取得済・免許不要。手実装 |
| **無線アンテナ** | **TX915-FPC-4510** | 2dBi。EIRP 上限 16dBm のため利得 3dBi 以下であること |

円安もあって部品総額は 1.3 万円程度、ケース・基板・細かい部品を入れると 1.6 万円ぐらいです（基板製造費を除く）。
GNSS 機能だけ残し、無線機能・KF 機能・バリオなど全て除去すれば、半額ぐらいにはなりそうです。

### 自作の手順

工夫して外注費を節約すれば１個あたり 1 万円と 10 時間程度の作業時間で作れそうですが、
時短と確実性を優先し JLC にて PCBA での発注を強く勧めます。PCBA を使うと１個あたりの材料費は約 2 万円です。
電子工作（PCBA とリフロー含む）経験者でないと苦戦すると思いますが、各自の責任で自作する場合は次の手順で作れます。

1. **JLCPCB に基板を 3 種類発注します。**
   * KiCad の JLCPCB プラグインを使うと、production フォルダに発注に必要な zip ファイル等が生成されます。
     kicad フォルダに 3 つプロジェクトがあります。
   * `mainboard` は PCBA Standard で片面発注をお勧めします。手で実装するには困難なパーツが多いです。推奨する発注設定は次のとおりです。
     * 軽量化とコスト削減：0.8mm,FR4 TG135,OSP
     * インピーダンス：JLC04081H-3313
     製造費の削減のため手実装が難しいパーツは裏面に集中させ、表面は手実装がしやすいパーツのみにしています。
     1 枚あたり約 1.4 万円になります。
     かなり工夫して手作業を増やせば 1 枚あたり約 5 千円に減らせますが作業時間が著しく増えてしまいます…。
   * `GNSSboard_SAM-M10Q` は Economy で発注し自身で実装ができます。節約できます。
     ただし SAM-M10Q はリフローが必要です。
   * `FPC` も JLCPCB で発注してください。ガーバー出力時には、必ず Stiffener も出力してください。
2. **Digikey・マルツ・秋月電子通商で部品を発注します**（→ 下の表）。
3. **基板が到着したら、残りの部品を手実装します。**
   * `mainboard` の `U12` E220-900T22S(JP) は、技適対応パーツが JLC にないため手実装。
     アンテナ (TX915-FPC-4510) は IPEX コネクタへ接続し、**カーボンや金属の陰にならない位置**へ固定します。
   * `mainboard` の `U6`,`U7` CUS-12TB Switch は、定格電流の都合で JLCPCB にないパーツのため手実装。
   * `GNSSboard_SAM-M10Q` のパーツ（リチウム二次電池・GNSS モジュール・コンデンサ・抵抗）は全て手実装。
     その際、SAM-M10Q は最初に**リフロー**してください。
4. `case_3Dmodel` にあるケースを 3D プリントします。**v7 用ケースは作成中で、現状は v6 用のデータしかありません。**
5. mainboard にリチウム電池 (860mAh) を接続します。mainboard をプラネジでケースに固定し、
   mainboard と GNSSboard_SAM-M10Q を FPC で繋ぎます。GNSSboard を隙間に固定します。
   アンテナを右側面の適当な部分に固定します。

### PCBA とは別に発注する部品（v7）

JLCPCB の PCBA では実装されないため、**別途購入して手実装する部品**の一覧です。数量は **PONS 1 台ぶん**です。

#### Digikey

| 用途 | 品名・型番 | 注文番号 | 数量 |
|---|---|---|:--:|
| TFT ディスプレイ | NHD-2.8-240320AF-CSXP-F | `NHD-2.8-240320AF-CSXP-F-ND` | 1 |
| GNSS モジュール | u-blox SAM-M10Q | `672-SAM-M10Q-00BCT-ND` | 1 |
| スピーカー | — | `GC0351M-ND` | 1 |
| スライドスイッチ | CUS-12TB | `563-1102-1-ND` | 2 |
| FPC コネクタ | Molex 2005280040 | `2005280040` | 1 |
| チップコンデンサ 0603 | 0.1µF `C0603C104K5RACTU` | — | 2 |
| チップ抵抗 0603 | 220Ω `RC0603FR-07220RL` | — | 1 |
| チップ抵抗 0603 | 470Ω `CRGCQ0603F470R` | — | 1 |
| プラスチックネジ | — | `145-50M025045I005-ND` | 4 |

* FPC コネクタは**基板側の反対側だけ**が必要です（もう一方は PCBA で実装済み）。
* 0603 のコンデンサ・抵抗は **GNSSboard 用**です。

#### マルツ

| 用途 | 品名・型番 | 数量 |
|---|---|:--:|
| LoRa モジュール（920MHz・技適取得済） | `E220-900T22S(JP)R2` | 1 |
| リチウムポリマー電池 860mAh | `DTP603048(PHR)` | 1 |
| LoRa アンテナ（2dBi） | `TX915-FPC-4510` | 1 |

* LoRa モジュールは技適対応品が JLCPCB に無いため、必ずここで買って手実装します（`U12`）。

#### 秋月電子通商

| 用途 | 品名・型番 | 数量 |
|---|---|:--:|
| MS リチウム二次電池（GNSS バックアップ） | `MS621FE FL11E` | 1 |
| ショットキーダイオード | `RB520S-30` | 1 |

* どちらも **GNSSboard 用**です。

## ソフトウェアのビルド

基板が組み上がったら、Arduino IDE で `GPS_TFT_map.ino` を開いてビルド・書き込みします。
ボードは **Generic RP2350** / Flash **16MB (no FS)** を選択してください。
必要なライブラリは `TFT_eSPI` / `SdFat` / `Adafruit_BNO08x` です。

* **`TFT_eSPI` は `User_Setup` を書き換えないと映りません。** サンプルは
  [TFT_eSPI/CopySetupFile_TFT_eSPI.h](TFT_eSPI/CopySetupFile_TFT_eSPI.h) にあります。
  パネル種別（ST7789 / ILI9341）の選択もここで行い、`settings.h` 側には分岐がありません。
* BNO085 は **i2c1 固定**です（0.976 で SPI 対応を削除）。詳細は [docs/imu_i2c_bringup.md](docs/imu_i2c_bringup.md)。
  普段使わない側は普段コンパイルされないため、壊れていても気づけません。

### 書き込み前の確認（`settings.h` 冒頭）

自分の機体に書き込む前に、`settings.h` 冒頭にある次の項目を確認してください。

* `RELEASE` — 有効にする。無効のままだと `setup1()` が `while(!Serial)` で待ち続け、実機が起動しません。
* `RELEASE_GNSS` — GNSS シミュレーション用の `DEBUG_GNSS_SIM_*` がすべてコメントアウトされているか。
* `BUILDDATE` / `BUILDVERSION` — 実際にビルドした日付・バージョンに更新する。
* どちらか抜けていると `#warning NOT RELEASE!` が出ます。これが唯一の保険なので、警告が出ていないか確認してください。

---

## SD カードの構成

| 場所 | 中身 |
|---|---|
| ルート直下 | **設定ファイルだけ**（`settings.txt` / `mapdata.csv` / `destinations.csv` / `override_pilon_coordinate.csv` / `logo.bmp`） |
| `data/` | 自機の飛行 CSV。**過去大会のデータもここに置きます** |
| `received/` | 無線で受け取った機体のログ（受信モードのときだけ） |
| `imu_replaydata/` | 姿勢（ESKF）の記録 |
| `imuraw/` | 生 IMU のバイナリ |
| `euler/` | 0.93 以前の姿勢ログ（読み込みのみ） |

リプレイ対象は `data/` と `received/` です。

**カードが無い・読めないときも飛べます。** 設定は `settings.txt` を読めないので
ファームウェアの既定値（**TRACK UP** / Navigation Mode **Auto 10km** / 目的地 **PLATHOME**）
になり、飛行ログと設定の保存だけが行われません。音声は本体 FLASH にあるので警報は鳴ります。

> **v6 以前のカードから移行する場合**：ルート直下にある飛行 CSV を `data/` フォルダへ移動してください。
> 移動しないとリプレイ一覧に出てきません。

microSD カードスロットはバネ式です。取り出す時は指で押し込めばカチッと音がして取れます。

### ログの記録項目

* **`data/` の飛行 CSV**（例：`data/2026-03-26_1519.csv`）：2Hz
  ```
  latitude, longitude, gs, TrueTrack, GNSS_Altitude, KF_Altitude, KF_Vspeed, pressure, voltage, numsat, date, time
  ```
  * `GNSS_Altitude` は GNSS のみ。`KF_*` は Kalman filter による推定（MS5611+BNO085+GNSS 融合）。
* **`imu_replaydata/`**（例：`imu_replaydata/20260324.txt`）：5Hz。
  ```
  time, roll, pitch, yaw, pitch_avg, roll_trim, yaw_acc95, wind_mps, wind_dir
  ```
  * ESKF の結果＝**画面に出ていた値そのもの**。リプレイ時にこれを読んで、そのとき画面に何が出ていたかを再現します。
  * 列名で解釈するので、後から列を足しても古いファイルが読めなくなることはありません。
* **`imuraw/`**（例：`imuraw/20260324.bin`）：生 IMU の 28 バイト固定長バイナリ。
  ジャイロ・加速度（各 50Hz）、GNSS 速度（2Hz）、気圧（約 4Hz）。PC 側の解析は `tools/imulog/` を参照。
  **地磁気（`id=0x03`）は 0.984 で記録をやめました**（方位は真方位だけを使うため）。
  過去ログを読めるよう ID は欠番として残してあり、**別の用途に再利用してはいけません**。
  * **測位できるまでは `imuraw/nofixNNN.bin`** に書き、日付が決まった時点で日付ファイルへ切り替えます。
    番号は起動ごとに繰り上がるので、複数日・複数起動が 1 ファイルに混ざることはありません。
  * ファイルを開くたびに先頭へ **BOOT レコード**（`id=0x00`）が 1 件入ります。起動ごとの
    ランダムな `boot_id` が入っており、**どこからが別の電源投入かを推測なしに判定**できます。
    測位前後で 2 ファイルに分かれても、同じ `boot_id` で突き合わせられます。
  * **`seq` の飛び＝取りこぼし ではありません。** ファイルが切り替わった箇所でも飛びます。
    実際に捨てられた件数は `/log.txt` の 60 秒ごとの `dropped=` が正です。
* **`euler/`**：**0.93 以前**の形式（`time, roll, pitch, yaw`、BNO085 由来）。現在は書き出しません。
  過去のログをリプレイするために読み込みだけ対応しています（`imu_replaydata/` が無い日はこちらを探します）。
* **`received/`**（v7〜）：**受信モードのときだけ**、無線で受け取ったテレメトリを記録します。
  列は飛行 CSV と同じ並びで、末尾に `rssi, seq, age_ms`、姿勢・風、
  そして `own_lat, own_lon, dist_m` が付きます。
  姿勢の列名は `imu_replaydata/` と同じにしてあるので、機体の SD が失われてもこちらで ESKF の解析ができます。
  * **原則として自機の GNSS は混ぜません**（無線で得た情報だけを置く場所です）。
    唯一の例外が末尾の `own_lat / own_lon / dist_m` で、**受信した瞬間のボート自身の位置と
    機体までの距離**です。RSSI と距離が同じ行に揃っていないと「距離 vs RSSI」が引けず、
    別ファイルに分けると `seq` で突き合わせる手間が増えるため、ここだけ例外にしています。
    測位できていなければ空欄になります。
  * これによりフライトログが二重化されます。機体が着水して SD が読めなくなっても、ボート側に同じ航跡が残ります。
* **`/log.txt`**：起動からの秒数、電圧、センサー類の初期化結果や GNSS 精度などのイベントログ。
  60 秒ごとに電圧・CPU 温度・センサーの受信レートを記録し、無線が有効なときは
  **通信レポート**（受信数・取りこぼし・RSSI）も残します。
  ```
  0:SD INIT
  2:BNO085 init OK
  2:MS5611 init OK
  2:VARIO: BNO085+MS5611 Kalman fusion enabled
  4:GNSS TIME: 2026-03-26 06:16:52 UTC
  6:SETUP DONE Battery: 4.15V
  6:Initial airdata: Temp=33.18 C, Press=1009.49 hPa, Alt=31.4 m
  60:volt=4.15V cpu=41.2C --:-- JST      ← 測位前は時刻を書かない
  120:volt=4.14V cpu=42.0C 15:18 JST
  148:GNSS FIXED fix=3 sats=0 hAcc=60.2m
  1303:ACC hAcc=1.4m vAcc=1.9m sAcc=0.19m/s fix=3 sats=21
  1480:ESKF APPLY done R+0.83 P-1.24 at 2026-03-26 06:41:03 UTC
  ```
  * 時刻は **GNSS の日時が確定してから**しか書きません。確定前は `--:--` になります
    （以前は 0 時として扱っていたため、測位していなくても `09:00 JST` と記録されていました）。
  * 行頭は**起動からの秒数**であって時刻ではありません。絶対時刻が要る行は
    それ自体に日時を持たせています（`GNSS TIME:` と `ESKF APPLY done`）。
    較正のオフセットは 60 秒ごとの `eskf ... lvl R+0.8 P-1.2` 行でも追えます。

### ログを Google Earth で可視化する方法

SD カード内の CSV ファイルを Google Earth に読み込むことができます。
`tools/logcsv2kml4earth.py` を使うと、指定フォルダにある複数の CSV をまとめて KML に変換できます。

### 目的地の追加（destinations.csv）

SD カードのトップディレクトリに `destinations.csv` を作成し、1 行に 1 目的地を
**名前（英語）, 緯度, 経度** のコンマ区切りで記述します。ヘッダー行は不要です。

```
KASAOKA03,34.495000,133.495000
TESTPOINT,35.412300,136.123413
```

* 名前は設定画面の Destination にそのまま表示されるので、画面幅に収まる短い英字が無難です。
* 緯度・経度は 10 進度（DD）。南緯・西経は負の値。
* `#` で始まる行と空行は無視されます。
* **内蔵の目的地（PLATHOME / N_PILON / S_PILON / TAKESHIMA）の後ろに追加されます。**
  同じ名前を書いても内蔵側は上書きされず、両方が並びます。
* 内蔵 4 件と合わせて最大 100 件（`MAX_DESTINATIONS`）。
* 読み込みは起動時の 1 回のみ。編集したら PONS を再起動してください。
* **次のいずれかに当てはまる行は捨てられます。** 打ち間違いが「(0,0) の目的地」として
  静かに登録されると、選んだときに誘導がギニア湾を指すためです。
  * コンマが足りない / 名前・緯度・経度のどれかが空
  * 緯度が ±90、経度が ±180 の範囲外
  * `0,0`（数値でない文字列も `0` になるため、ここで一緒に弾いています）
* 読み込み結果は `log.txt` に残ります（`DESTINATIONS: 6 added, 1 ignored` のような行）。
  **書いたはずの目的地が出ないときはここを見てください。**
* 配布 SD には `KASAOKA03` / `KASAOKA21` / `SHIRAHAMA34` / `SHIRAHAMA16` / `KARASU30` / `KARASU12` を初期登録済みです。

### パイロン座標の変更（override_pilon_coordinate.csv）

パイロンの座標は毎年変わり得ますが、大会直前にファームウェアを再ビルドするのは現実的ではありません。
SD カードのトップディレクトリに **`override_pilon_coordinate.csv`** を置くと、起動時にその値で上書きします。

```
# name,latitude,longitude
PLATHOME,35.294222,136.254333
N_PILON,35.377878,136.189907
S_PILON,35.274220,136.136183
PILON_1KM,35.297961,136.243624
```

* `#` で始まる行と空行は無視されます。
* 使える名前は `PLATHOME` / `N_PILON` / `S_PILON` / `PILON_1KM` / `TAKESHIMA` の 5 つ。
  **書いた地点だけが上書き**され、書かなかった地点はファームウェアの既定値のままです。
* `TAKESHIMA` は島そのものなので通常は書く必要がありません（仕組み上は指定できます）。
* 緯度・経度は 10 進度（DD）。緯度 ±90、経度 ±180 の範囲外や `0,0` は打ち間違いとみなして無視します。
* 適用結果は `log.txt` に記録されます（`PILON OVERRIDE S_PILON 35.274220 136.136183` のような行）。

**適用されたことの確認方法**：設定画面 → `Map data detail >` を開くと、`OSM(ODbL)` の内訳と
`FLSH` の一覧の間に、実際に使われている座標が表示されます。

```
COURSE SD OVERRIDE        ← 上書きが効いていればマゼンタで OVERRIDE、既定なら灰色で built-in
 PLA   35.294222, 136.254333
 NPIL  35.377878, 136.189907
 SPIL  35.274220, 136.136183
 1KM   35.297961, 136.243624
 TAKE  35.296584, 136.178054
```

上書きした座標は次の 2 つに同時に反映されます。

1. 設定画面で選べる内蔵目的地（`PLATHOME` / `N_PILON` / `S_PILON` / `TAKESHIMA`）
2. 地図上に描かれるパイロンのアイコンと、プラットホームからの基準線

なお **Auto 10km モードの折り返し判定はパイロン座標を使いません。**
「選択中の目的地（通常は PLATHOME）からの距離」で判定するので、影響するのは `PLATHOME` の座標だけです。

恒久的な変更としては [navdata.h](navdata.h) の `#define`（`PLA_*` / `PILON_NORTH_*` /
`PILON_SOUTH_*` / `PILON_1KM_*` / `TAKESHIMA_*`）を直してビルドし直すのが正しい手順です。
SD での上書きは、ビルドが間に合わない場合の運用手段という位置づけです。

### 地図データ

日本地図および琵琶湖周辺（沖島・竹生島・多景島など）の地形は、
**OpenStreetMap から生成したベクタ地図をファームウェアの FLASH に内蔵**しているため、
SD カードが無くても表示されます（`src/flashdata/vectormap_data.cpp`、`tools/vectormap/build_vectormap.py` で生成）。

* v6 の途中（0.93）で、Google Map API の bmp タイルを SD カードから読む方式は**廃止**しました。
  SD の読み出し待ちが無くなり、拡大率によらず描画が軽くなっています。
* 設定画面の `Map data detail >` で、FLASH 内蔵地図と SD (`mapdata.csv`) から読み込んだ地図の一覧を確認できます。
* Map data © OpenStreetMap contributors（ODbL 1.0）

#### 追加地図（独自地図）の作り方

独自地図とは、SD カードから読み込んだ緯度経度の列を地図（線）として表示する機能のことです。色の指定が可能。

1. Google Earth で PATH を作成し KML ファイルをダウンロード。**PATH の名前は英語で登録**してください。
2. `tools/kml_to_mapcsv.py` で KML から `mapdata.csv` を生成。
3. `mapdata.csv` を SD カードのトップディレクトリに配置。

**PATH 名の 1 文字目で線の色が決まります**：`r`=RED / `o`=ORANGE / `g`=GRAY / `m`=MAGENTA / `c`=CYAN / `b`=BLUE。
該当色がない場合は黒。例：`b_river` と指定すれば青色の線になります。

### WAV 音声ファイルの変更

**音声は本体 FLASH に焼き込んであります（0.982 以降）。SD カードには置きません。**
SD が無い・壊れている機体でも警報の音声が鳴るようにするためです。合計 32 本・
約 2.0MB・126 秒ぶんで、16MB FLASH のうち約 12% を使っています。

差し替えの手順:

1. リポジトリ直下の `wav/` にあるファイルを置き換える（16kHz / Unsigned 8bit PCM /
   メタ情報なし）。書き出しには Audacity を推奨します。設定から品質・ディザリングを
   「無し」にしてください。これをしないとノイズが入ります。ファイル長さは関係ありません。
2. `python3 tools/clean_wav8.py wav/*.wav` で無音トリムとラウドネスを揃える（任意）
3. **`python3 tools/gen_wav_flash.py` を実行**して `src/flashdata/wav_data.cpp` を作り直す
4. ファームウェアを書き込む

3 を忘れると音は変わりません。リリース前に `python3 tools/gen_wav_flash.py --check` を
走らせると、`wav/` と焼き込み済みデータが CRC32 で一致しているか確認できます。

焼き込んでいるファイル名は次のとおりです。

| 分類 | ファイル名 |
|---|---|
| ナビゲーション | `track.wav` / `course_left.wav` / `course_right.wav` / `destination_change.wav` / `destination_toofar.wav` / `fixed.wav` |
| 姿勢（ESKF） | `bank_warning.wav`（バンク角警告）/ **`eskf_calib_required.wav`（較正のやり直しが必要。地上でのみ 120 秒ごと）** / `guide_eskf_setting.wav`（IMU/ESKF 画面に入ったときの注意案内）/ `eskf_apply_done.wav`（較正完了）/ `eskf_calib_oldday.wav`（較正した日から日付をまたいだ。地上で起動ごとに 1 回）/ `roll_check.wav`・`pitch_check.wav`（待機中のロール・ピッチのズレ）/ `change_setroll_caution.wav`（SET ROLL を 0 以外にしたときの警告） |
| 無線（PONS Link） | `sender_mode.wav` / `receiver_mode.wav` / `link_no_signal.wav` / `link_no_module.wav` / `link_dup_sender.wav` / `link_override_dest.wav` / `link_setting_changed.wav` / `battery_low_sender.wav`（機体の電池低下を受信側で知らせる）/ `link_ch_busy.wav`・`link_ch_noisy.wav`（送信前チェック） |
| その他 | `battery_low.wav` / `opening.wav` |
| ネタ | `matane.wav` / `arigato.wav` / `baibai.wav` / `makenna.wav` / `tsuyoi.wav` |

---

## ツール (tools/)

* `tools/logcsv2kml4earth.py`：複数のフライトログ CSV をまとめて KML に変換（Google Earth 用）
* `tools/logcsv2tourkmz.py`：ログ CSV を Google Earth のツアー (KMZ) に変換
* `tools/kml_to_mapcsv.py`：Google Earth の KML から独自地図用 `mapdata.csv` を生成
* `tools/createmovie_csv2mp4.py`：ログ CSV からフライト動画を生成
* `tools/flight_preprocess.py` / `tools/flightanalysis/`：ログの前処理と飛行解析（スペクトル、横・方向安定性など）のプロット
  * `plot_vertical_accel.py`：鉛直加速度（G）と荷重倍数の推定。G は直接記録していないので
    `KF_Vspeed` の差分から出す（気圧の 2 階微分はノイズが信号を上回るため使えない）。
    平均化窓ごとの最大値・地上で実測したノイズ床・生の気圧列での裏取りまで出す
* `tools/vectormap/build_vectormap.py`：OpenStreetMap から内蔵ベクタ地図 `vectormap_data.cpp` を生成
* `tools/png2bmp.py`：PNG 画像を起動ロゴ用 bmp へ変換
* `tools/gen_link_icons.py`：PONS Link の電波アイコン（アンテナ本数・送信の弧）を生成
* `tools/gen_wav_flash.py`：`wav/*.wav` を本体 FLASH 用の `src/flashdata/wav_data.cpp` へ変換
  * `--check` で `wav/` と焼き込み済みデータを CRC32 照合（リリース前チェック用）
  * ソース中の `"wav/*.wav"` を全部突き合わせ、`wav/` に無い名前があればビルド前に止める
* `tools/clean_wav8.py`：`wav/` の音声の無音トリム・ヒス除去・ラウドネス統一
  （**実行後は `gen_wav_flash.py` を回すこと**。焼き直さないと音は変わらない）
* `tools/imulog/`：生 IMU ログ (`imuraw/*.bin`) の解析一式
  * `decode_imulog.py`：バイナリのデコード、セッション分割、時刻の復元
  * `eskf.py`：PC 上で動く ESKF（機上の `attitude.cpp` と同じ数式・同じマウント補正）
  * `compare_grv.py`：0.983 の変更（GRV/RV 依存の除去・重力観測）を実ログで検証する。
    走行後にこれを回すと、初期水平化と GRV の差／地磁気ヨーと GNSS 航跡の差／
    バリオ V/S の差／GNSS 断時の姿勢ドリフト／重力観測のゲート開口率が出る。
    **GRV と RV は推定に使わなくなった後も生ログに記録し続けているので比較できる。
    BNO085 を降ろすと比較対象が無くなるため、それまでに測っておく。**
  * `merge_flight.py`：生 IMU と飛行 CSV の結合、`plot_response.py` / `pitchtest_plot.py`：応答の可視化
  * `road_geometry.py`：走行データから路面の傾斜を逆算、`yaw_kml.py`：ヨーを KML で地図に重ねる
* `tools/sch16t_test/`：SCH16T-K01 の単独立ち上げスケッチ（**Raspberry Pi Pico 2** 用。
  機上のファームとは別物）。SPI を叩く前にフレーム組み立ての自己テストを走らせ、
  48bit フレームと CRC8 を Murata の事前計算値と照合する。**ここが NG なら配線を見るのは
  時間の無駄。** 読み出しレートとフィルターの決定もこれで実測する（→ `tools/sch16t_test/README.md`）
* `tools/attitude_test/`：`attitude.cpp` を PC 上で検証するテスト（`make` でビルドと実行）
  * 協調旋回でバンクを復元できるか / 加速度だけの水平化と GNSS 航跡によるヨー注入 /
    待機中の再水平化とジャイロバイアス学習 / 水平化前でもバリオ用の上方向が出るか /
    重力観測が直進では入り **5 度バンクの旋回では入らない**か / BNO085 断線時に安全側へ倒れるか

---

## 着水（水没）後の処理

1. 分解して取れる水分をすべて拭き取り、ネジのサビを除去する。
2. バッテリー端子と TFT 端子を取り外し、可能な範囲で拭いた後エタノール洗浄する。
   バッテリーはテープと回路部分を分解洗浄し、テープ保護して戻す。
3. 乾燥剤を入れたジップロックで TFT 内部などの水分を抜く（湿度 20% で 2〜3 日放置推奨）。
4. DIP スイッチは内部で錆が発生し接触不良になる恐れがあるため交換推奨。
   GNSS バックアップのリチウム二次ボタン電池は腐食するので、交換を推奨。
5. バッテリーは基板部分をクリーンナップして保護しなおし。異常な電圧値の履歴がなければ再利用可。

## 開発者向け

* 問い合わせ：開発者 大阪大学 albatross OB 7 期 MasaoC（masaochiguchi@gmail.com / LINE, X: masao_mobile）

## ライセンス

本リポジトリは 4 種類のライセンスで構成されています。

| 対象 | ライセンス |
|---|---|
| ソースコード（`*.ino` / `*.cpp` / `*.h` / `tools/*.py`） | MIT License（[LICENSE](LICENSE)） |
| 地図データ（`vectormap_data.cpp`） | ODbL 1.0（[LICENSE.ODbL](LICENSE.ODbL)） |
| `src/bno08x/Adafruit_BNO08x.{h,cpp}` | BSD 3-Clause（[src/bno08x/license.txt](src/bno08x/license.txt)） |
| `src/bno08x/sh2*` `shtp*` | Apache License 2.0（[src/bno08x/NOTICE.txt](src/bno08x/NOTICE.txt)） |

`src/bno08x/` は BNO085 のライブラリをリポジトリに取り込んだものです（Adafruit BNO08x v1.2.7 +
Hillcrest の SH-2 ドライバ）。**ライブラリ側に手を入れないと直せない不具合があり、その修正を
git で共有するため**に取り込みました。改変点は
[src/bno08x/PONS_VENDORING.md](src/bno08x/PONS_VENDORING.md) にすべて記録してあります。
再配布時は各ライセンスの帰属表示を保持してください。

地図データは OpenStreetMap 由来です。

> Map data (c) OpenStreetMap contributors — https://www.openstreetmap.org/copyright
> Licensed under the [Open Database License (ODbL) v1.0](https://opendatacommons.org/licenses/odbl/1-0/)

`vectormap_data.cpp` は座標列を格納したベクタ形式のため、ODbL における **Derivative Database**
（派生データベース）に該当し、share-alike の対象になります。再配布時は ODbL のままとし、
帰属表示を保持してください。ODbL 4.5(a) の Collective Database 免除により、
ファームウェアのソースコード本体は MIT のままで問題ありません。詳細は [LICENSE.ODbL](LICENSE.ODbL) を参照。

地図データの生成方法は [tools/vectormap/build_vectormap.py](tools/vectormap/build_vectormap.py) を参照してください。

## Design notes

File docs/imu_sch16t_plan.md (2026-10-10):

# SCH16T-K01-10 導入計画 — 変更が必要な箇所の洗い出し

BNO085 の加速度・ジャイロ精度に課題があるため、Murata **SCH16T-K01-10**（SPI）を導入し、
**設定で BNO085(I2C) / SCH16T(SPI) を選べる**ようにする。

この文書は**実装前の準備**。モジュールが届いたら
[tools/sch16t_test/](../tools/sch16t_test/) で単独テストを済ませ、そのあとここの順番で融合する。

**0.983 で §2.2（ESKF の GRV/RV 依存）と §2.3（バリオの GRV 依存）は先に片付けた。**
どちらも BNO085 のままで実ログによる無回帰確認ができたため、SCH16T が届く前にやっておいた。

- 単独テストのスケッチと手順 → [tools/sch16t_test/README.md](../tools/sch16t_test/README.md)
- 現状（BNO085 I2C）の立ち上げ記録 → [imu_i2c_bringup.md](imu_i2c_bringup.md)

---

## 0. 前提 — 「ドライバの差し替え」では済まない

2 つのセンサーは**出てくるものが違う**。

| | BNO085 | SCH16T-K01 |
|---|---|---|
| 生ジャイロ・加速度 | あり | あり（20bit, 1600 LSB/(°/s), 3200 LSB/(m/s²)） |
| 融合クォータニオン | **GRV / RV** | **無し** |
| 地磁気 | あり | **無し** |
| 動的校正（DCD）と申告精度 | あり | **無し** |
| 故障・飽和ステータス | quat の健全性のみ | **STAT_* が 10 本。CRC 付き 48bit フレーム** |
| ODR | レポートごとに要求 | 11.8kHz を間引いて 738Hz〜 |

**消えるものが 4 つある。うち 3 つは片付けた（1・2 は 0.983、3 は 0.984）。**

1. ~~**GRV** … バリオ KF の重力除去と姿勢 ESKF の初期化~~
   → **0.983 で依存を除去**（§2.2 / §2.3）。生の加速度から水平化する
2. ~~**RV** … ESKF の初期ヨー（磁北基準）~~
   → **0.983 で依存を除去**。GNSS 航跡から入れる。**精度も上がった**（磁気は 57.8 度ずれていた）
3. ~~**地磁気** … 生ログと比較表示に残るだけ~~
   → **0.984 で購読をやめた**。`IMULOG_ID_MAG`（0x03）は欠番（§2.4）
4. **DCD と申告精度** … 画面（IMU/ESKF 2/3 ページ）と長押し保存、EEPROM の保存記録。**未着手**

逆に**増えるもの**もあり、そちらは画面とログに出す先が必要になる
（STAT_SUM 系の故障ビット・飽和カウンタ・CRC エラー数・実 ODR）。

---

## 1. 抽象化の切り方 — **0.986 で完了**

分割前の `imu.cpp` は 1918 行で、大半が **BNO085 固有の「壊れやすい約束」**
（`sh2_close()`、i2c バス復旧、未使用ピンの park、レポート飢餓対策）だった。
0.984 で境界（[imu_sensor.h](../imu_sensor.h)）を作り、0.986 でファイルを割った。

| ファイル | 行数 | 中身 |
|---|--:|---|
| [imu.cpp](../imu.cpp) | 801 | バリオ KF・気圧/GNSS 観測・`imu_feed_*()`・V/S と高度のゲッター。**チップ非依存** |
| [imu_bno08x.cpp](../imu_bno08x.cpp) | 1248 | BNO085 ドライバ。バス・リセット・レポート受信・DCD 校正・復旧・融合出力のゲッター |
| [imu_sch16t.cpp](../imu_sch16t.cpp) | 127 | **骨組みだけ**（0.987）。全部「載っていない」を返す。中身は §4 の 6 |

★ **移動は行範囲のコピーで行い、本文は 1 行も書き換えていない**（挙動を変えないため）。
両者に跨る `imu_update()` だけ組み直し、`imu_drv_poll()` の戻り値
DEAD / WAIT / SERVICED を分割前の 3 分岐に 1 対 1 で対応させた。

★ **新しいドライバもファイル全体を `#if IMU_SENSOR_DEFAULT == ...` で囲うこと。**
Arduino は .cpp を全部コンパイルするので、囲わないと `imu_drv_*` が多重定義になる。

★ 副産物として **park 処置が v7.1 では自動的に消えた**（§3 の残り 1 件）。
`imu_bus_park_unused_pins()` はドライバの中だけで、外から呼ばれていない。

### 0.984 で入れた境界 — [imu_sensor.h](../imu_sensor.h)

1. **能力ビット** `imu_caps()` … そのチップから何が出るか
   （`IMU_CAP_QUAT` / `MAGYAW` / `MAG` / `LINACC` / `CAL` / `STATUS`）。
   **融合出力に触る画面とログを全部これで囲んだ**ので、SCH16T でビットを落とせば
   表示とログが自動的に縮退する。囲まないと「0 を本物として出す」ことになり、
   姿勢比較の行は **0 が「水平で北向き」というもっともらしい値**になる
2. **feed の口** `imu_feed_gyro()` / `imu_feed_accel()` …
   ドライバはこの 2 つを正しいレートで呼べばよい。中で姿勢 ESKF の伝播と
   バリオの蓄積へ配る。**SCH16T のドライバが書くべきチップ非依存のコードは無い**
3. 生ログの `imulog_push()` は**ドライバ側に残した**。レコードの `s_us` と `acc` が
   チップ固有で、境界へ移すと退避済みの過去ログとバイト互換でなくなる

### 0.986 で入れた口 — `imu_drv_*`（[imu_sensor.h](../imu_sensor.h)）

`imu_drv_setup` / `imu_drv_poll` / `imu_drv_service_if_due` / `imu_drv_present` /
`imu_drv_alive`、それに `imu_feed_reset`（復旧時に溜めた比力を捨てる）。

★ **当初案の `recover` は入れなかった。** BNO085 では復旧が途絶判定と同じ状態機械で
動くので `imu_drv_poll()` の中に収まり、外から復旧だけ叩く用途も無い。
`setup` も戻り値を持たせず、成否は `imu_drv_present()` が答える。

### まだやっていない

- **`imu_sch16t.cpp` の中身**（§4 の 6）。骨組みは 0.987 で置いたので
  **`PONS_BOARD` を V71 にするとリンクまで通る**（基板が届く前に新基板向けの
  ビルド全体を確かめられる）。`#warning` が「飛ばすな」の見張り
- `settings.txt` の `imu_sensor` キー。**値が効かない設定を先に作ると嘘になる**ので
  ドライバと同時。
  ★ そもそも要るかを再検討すること。0.986 で `IMU_SENSOR_DEFAULT` は
  `PONS_BOARD` から導くようにしたので、**基板が決まればセンサーも決まる**。
  「3 台で混在させるための宣言」という当初の動機は、基板ごとにファームを分ければ消える

### ★ ドライバが実装すべき surface（0.986 に実測）

`PONS_BOARD` を V71 にしてリンクすると、未定義は **28 個だけ**だった。
これが `imu_sch16t.cpp` の仕事の全量で、**BNO085 の内部に触っているコードは
他に 1 つも残っていない**（境界が閉じている証拠）。内訳は
`imu_drv_*`(5) / `imu_caps` / `imu_sensor_name` / 融合出力 3（euler・linaccel・
mag_accuracy）/ レート 5 / 校正と申告精度 9 / 健全性 4。

★ SCH16T では能力ビットが落ちるので、**融合出力系は「無い」を返す実装でよい**
（画面とログは `imu_caps()` で囲ってある）。0.987 の骨組みがその形になっている。

★ **生ジャイロ・生加速度のレート（`get_imu_gyro_hz` / `get_imu_accel_hz`）は
能力ビットで囲っていない**（どのチップにも必ず有るため）。骨組みは 0 を返すので、
本物のドライバで**必ず埋めること**。でないと 60 秒ログの `raw GYR=0.0 ACC=0.0` が
「飢餓」に見える。

★ 能力ビットと feed の口の**実際の定義は [imu_sensor.h](../imu_sensor.h) にある**。
ここに写すと必ず食い違う（0.984 の実装で `IMU_CAP_LINACC` が増えて番号がずれ、
この計画書の案だけが古いままになっていた）。

★ **`imu_service_if_due()` の役割が変わる。** BNO085 では
「読まないとレポートが溜まってジャイロが化ける」ための飢餓対策だが、
SCH16T は**こちらが SPI で取りに行く**方式なので飢餓が起きない
（読まなければ DRY が立ったままになるだけ）。
**ただし CLAUDE.md とコード中の飢餓対策コメントは消さないこと。** BNO085 に戻す可能性がある。

---

## 2. 変更が必要な箇所

### 2.1 設定・ビルド

| 場所 | 変更 | 状態 |
|---|---|---|
| [settings.h](../settings.h) | `IMU_SENSOR_BNO085` / `IMU_SENSOR_SCH16T` の列挙、既定値、感度・CRC・初期化待ち・COMP_ID、SPI ピンの枠 | **0.984 で実装**（ピンは未定のまま `#error` で止める） |
| [mysd.cpp](../mysd.cpp) | `settings[]` に `imu_sensor` キー。setter/getter は `link_mode` と同じ形 | ドライバと同時 |
| [display_tft.cpp](../display_tft.cpp) | 設定画面に選択 UI | ドライバと同時 |

★ 読み出しレートとフィルターは**まだ決めていない**（§5 の (2)）。単独テストで実測して決める。

★ **切替は「起動時のみ有効」にすること。** 動作中に切り替えると `imu_setup()` のやり直しになり、
バス初期化・ESKF リセット・バリオ KF の再初期化が絡む。
`link_mode` と同じく「SD に保存して次回起動から」が安全。

### 2.2 姿勢 ESKF — **0.983 で完了**

GRV / RV への依存は外した。**生のジャイロと加速度だけで初期化できる。**

| | 0.982 まで | 0.983 |
|---|---|---|
| 初期ロール・ピッチ | GRV の静止平均 | **静止中の平均加速度から水平化**（`level_toward_gravity`） |
| 初期ヨー | RV（地磁気）＋偏角補正 | **GNSS 航跡から注入**（`init_yaw_from_track`） |
| 待機中の維持 | 不要だった（GRV が常時重力基準） | **静止中の再水平化＋ジャイロバイアス学習** |
| 速度観測 | 初期化直後から | **ヨー設定までゲート** |

削除したもの: `attitude_on_grv()` / `attitude_on_rv()` / `apply_declination()` /
`ESKF_INIT_USE_RV` / `ESKF_RV_ACC_MAX_DEG` / `ESKF_MAG_DECLINATION_DEG` /
`ESKF_INIT_YAW_SIGMA_DEG`（→ `ESKF_YAW_UNKNOWN_SIGMA_DEG` と `ESKF_YAW_INIT_SIGMA_DEG` に分割）。
`attitude_yaw_from_mag()` は `attitude_get_yaw_source()` に置き換えた。

#### 実ログでの検証（20260930 の 52 分 + 20260818 の 5 セッション）

| 項目 | 結果 |
|---|---|
| 加速度水平化 vs GRV のロール・ピッチ | **差 0.05 度以内**（最大 0.4 度）。GRV は初期姿勢に何も足していなかった |
| 航跡ヨーの注入 | 要求方位に厳密一致。**ロール・ピッチの変化 0.0000 度** |
| 地磁気ヨー vs GNSS 航跡 | **57.8 度ずれ**（20260930・現マウント。BNO085 は「25 度以内」と申告） |
| eskf.py 新旧比較（現ファームのログ） | ロール・ピッチ差の中央はほぼ 0。ヨーは GNSS 航跡基準で**散らばりが改善**（s5: sd 23.8→13.3 度） |

★ **ヨーには両経路に共通の +14〜24 度の系統オフセットが残る。** 車載時の
デバイスの取り付けヨー角（車軸と平行でない）で説明がつき、**新旧で同じなので回帰ではない**。
機体では airframe に合わせて取り付けるので出ないはず。**実機で確認する項目。**

#### 残る挙動差（既知・許容と判断）

- **GNSS があるのに対地速度が 3m/s を超えない状態が続くと、ESKF に観測が 1 つも入らない。**
  0.982 までは測位が来た時点で観測が入っていた。ボートがアイドルで漂っているときなどに該当する。
  運用速度（追走ボートは 7〜8m/s）に乗れば自動的に解消する。**§6 の Phase 2 で消える。**
- **注入した航跡が間違っていれば（受信不良・取り付けヨー角）、その誤差はロール・ピッチにも回る。**
  σ=15 度ぶんは吸収するが、それ以上は収束待ちになる。`ESKF_YAW_INIT_ARM_FIXES=2` で
  単発の化けは弾いている。

### 2.3 バリオ KF — **0.983 で完了**

[imu.cpp:397 付近](../imu.cpp) の上方向の出どころを GRV から ESKF の姿勢へ移した。
**式は変えていない** — `attitude_get_up_sensor()` が返すのは回転行列の第 3 行で、
`compute_earth_z_accel()` が GRV から作っていた係数と同じもの。

実ログでの V/S の差:

| ログ | V/S 差 sd | \|max\| | \|差\|>0.1m/s | 高度差 \|max\| |
|---|---|---|---|---|
| **20260930 s1（52 分・トンネル込み）** | **0.021** | **0.432** | **0.81%** | **0.15 m** |
| 20260818 s1 | 0.025 | 0.176 | 1.02% | 0.12 m |
| 20260818 s2 | 0.012 | 0.073 | 0% | 0.02 m |
| 20260818 s3 | 0.060 | 0.319 | 8.99% | 0.26 m |

V/S 自体の sd は GRV 0.320 / ESKF 0.319 で同一（20260930）。
20260930 s1 だけ「静止中の再水平化＋バイアス学習」を入れた実装どおりで測り直してある
（入れる前は sd 0.030 / >0.1 が 1.66% / 高度差 0.33m だった。**維持ロジックが効いている**）。
20260818 の 3 件は維持ロジック無しの値なので、実装どおりならもう少し良くなる。

★ **最大差の 2 件はどちらも「その前後 3 秒に使える測位が 0 件」の瞬間だった。**
ESKF の観測は速度だけなので、GNSS が無い間ロール・ピッチには重力の錨が無い
（GRV には BNO085 内部の重力融合が常時あった）。傾き誤差 θ の a_k への効きは
g(1−cosθ) で θ=1 度 → 0.0015、5 度 → 0.037 m/s² と**二乗で効く**ので、
数度までなら無害。バリオ KF のバイアス状態もゆっくりした誤差を吸う。

#### 残る挙動差（既知・許容と判断）

- ~~ESKF が水平化できていないあいだ、バリオは気圧のみに劣化する~~
  ★★ **これは誤りだった。劣化ではなく「完全停止」で、2026-10-01 に実機で発覚した。**
  機序: **バリオ KF の初期 P は対角なので、predict を一度も通らないと P[1][0] が 0 の
  ままになる。気圧観測のゲインは K[1] = P[1][0]/S なので 0 で、速度状態が構造的に
  1 度も動かない。** 高度 kf_x[0] は K[0] で追従するため「センサーは生きているのに
  V/S だけ 0 で固まる」という見え方になった。既存の縮退経路は**高度にしか効かない。**
  しかも水平化は静止 2 秒が条件なので、**手持ちテストでは成立しない**
  （実ログ 38 秒で |ω| 中央 5.13deg/s、2 秒連続の静止区間が 1 つも無かった）。
  → **対策済み**（`up_lp_` による常時の重力方向＋「上方向が無くても predict は止めない」）。
  再発防止テストは `tools/attitude_test/yaw_test.cpp` の E。

  ★ 教訓として残す: **「観測だけで状態が動く」と思ってはいけない。**
  共分散の非対角は predict でしか作られないので、predict を止めると
  その状態は観測から切り離される。

**Phase 2（別途・任意）: ESKF に重力観測を足す。** → 詳細は §6。

★ **`KF_R` / `KF_Q_VEL` / `KF_Q_BIAS` の再測定は SCH16T へ切り替えるときに行う。**
0.983 の時点では重力除去の出どころが変わっただけで、上表のとおり V/S はほぼ同一なので
BNO085 のままなら再調整は不要と判断した（走行中の V/S sd も 0.263 → 0.263 で変化なし）。
SCH16T はノイズ特性が違うので、そのときに測り直す。

### 2.4 生 IMU ログ

[src/imulog.h](../src/imulog.h) の ID のうち **MAG / GAMERV / RV / LINACC が出なくなる**。
**MAG（0x03）は 0.984 で先に止めた**（地磁気は推定にも表示にも使っていないため）。

- 形式は変えず「出ない」だけにするのが安全。`decode_imulog.py` は種別ごとに分けているので空になるだけ
- ★★ **止めた ID を別の用途に再利用してはいけない。** 退避済みの過去ログ
  （〜2026-10-03）は id でレコードを解釈するので、別の意味を割り当てると
  **古いログが静かに誤デコードされる**。`src/imulog.h` に欠番として残してある
- ★ **BOOT レコードに「どちらのセンサーで録ったか」を残すこと。**
  でないと後から解析するときスケールも単位も判断できない。
  `s_us` の枠は `BUILDDATE` で埋まっているので、`acc` の枠か新 ID を使う
- [tools/imulog/decode_imulog.py](../tools/imulog/decode_imulog.py) … `KINDS` の追加とスケールの扱い

### 2.5 画面（[display_tft.cpp](../display_tft.cpp) — `BNO085` の言及 35 箇所）

| 箇所 | 変更 |
|---|---|
| `display_tft.cpp:1182,1215` | 起動診断の `print_boot_check("BNO085:", imu)` → センサー名を可変に |
| `display_tft.cpp:2036-2150` | **IMU/ESKF 2/3 ページを SCH16T 用に差し替える。** 申告精度 acc/gyr/mag・`cal cfg`・DCD 保存 UI が全部意味を失う。代わりに STAT_SUM 系の故障ビット・飽和カウンタ・CRC エラー数・実 ODR を出す |
| `display_tft.cpp:3975,4094-4153` | `"Mode: BNO085 only"` / `"-- BNO085 IMU --"` / GRV・LACC・RV のレート表示 / `mag_acc` |
| `display_tft.cpp:1765-1916` | ESKF と BNO085 の比較ページ。SCH16T では比較対象が無いので**意味が変わる**（残すなら「生値 vs ESKF」に） |
| `display_tft.cpp:1549,1871` | 「BNO085 非搭載機」の分岐 → 「姿勢センサー非搭載」に一般化 |

校正関連 UI（長押し SAVE）は SCH16T では無効化する。

★ **この差し替えは基板を待たずに確かめられる**（0.987 から）。`settings.h` の
`IMU_CAPS_DEBUG_MASK` を `0` にすると、**BNO085 を載せたまま**「融合出力の無い
チップ」を再現できる。見るのは 3 点 — IMU/ESKF 2/3 ページが**真っ白にならないか**
（早期 return すると下の `pushSprite` に届かず操作不能になる）、融合出力の欄が
**0 を本物として出さないか**（姿勢比較の 0 は「水平で北向き」に見える）、
校正の行が消えず `(n/a)` になるか（消すとメニューの添字がずれる）。
既定でないと `#warning` が出るので、戻し忘れは気づける。

★ 0.987 に静的監査を通した結果、**融合出力のゲッターに未ガードの呼び出しは無かった**
（`display_tft.cpp` の 2 箇所は値を埋めてから `imu_caps()` の中でしか使っていない）。

### 2.6 校正・EEPROM

- `imu.cpp` の `ImuCalRec`（EEPROM に DCD 保存記録）は SCH16T では不要
- `settings.txt` の `calib_date` の意味が変わる
- ★ **自前のジャイロ ZRO は 0.983 で入れた（実装済み・PC テスト済み）。
  ただし実機検証は SCH16T を載せてからでないとできない。**
  BNO085 は静止出力が厳密に 0 なので、学習しても `bg_ = 0` になって変化が見えない。
  **SCH16T に替えた瞬間に初めて意味を持ち、同時に必須になる。**
  フラッシュ保存はしない。
  `attitude.cpp` の `learn_gyro_bias()` が静止中に毎回測り直す（→ `settings.h` の
  `ESKF_BIAS_LEARN_SAMPLES`）。
  **保存しない理由**: SCH16T の offset drift velocity は ±0.01(deg/s)/min（0.5K/min 時）で、
  起動後の昇温（実測 CPU 20→36℃）で動く。焼いた定数は次の起動では合わない。
  一方 bias instability は 0.3〜0.5 deg/h しかないので、**その飛行の中では一度測れば
  最後まで有効**。毎回測り直すのが正しく、EEPROM を触らないので実装も軽い。

### 2.7 ログ・診断出力

[GPS_TFT_map.ino:1031 付近](../GPS_TFT_map.ino) の 60 秒ログ。

- `rate GRV=.. LACC=.. RV=..` / `cal cfg=..` / `quat grvbad=.. grvjump=.. rvbad=..`
  → SCH16T では別の指標（実測 ODR / CRC エラー / STAT ビット / 飽和回数）
- `imu gapmax=` は **SCH16T でも有用**（SPI を叩けていない時間）。そのまま残す

### 2.8 無線（PONS Link）

- [lora_link/link_proto.h](../lora_link/link_proto.h) に IMU 種別は入っていない。
  ミラーは roll/pitch/yaw を送るだけなので**影響は小さい**
- 受信側で「送信機がどっちのセンサーか」を出したいなら `status` の空きビットを 1 つ使う

### 2.9 ドキュメント

- **CLAUDE.md の「破ると静かに壊れる約束」のうち BNO085 関連 7 項目**
  （`sh2_close()`、GPIO42/44 の park、GPIO41、i2c 固まり、レポート飢餓など）は
  **BNO085 を選んだときだけ有効**。見出しにその条件を書く
- [README.md](../README.md) のスペック表と「v7 での主な変更点」
- [imu_i2c_bringup.md](imu_i2c_bringup.md) は BNO085 専用として残す
- 新規 `docs/imu_sch16t_bringup.md`（実機立ち上げの記録用）

---

## 3. ハードウェア — **v7.1 基板で確定（2026-10-07）**

**SCH16T 実装時は BNO085 をセンサーごと基板から降ろす**（2026-10-01 決定）。
これでピンの競合が消えたので、空いた SPI1 の正規割り当てをそのまま使う。
**ネットリストから確認済みで、`settings.h` の `SCH16T_PIN_*` が正本。**

★ **基板の選択は `settings.h` の `PONS_BOARD`**（`PONS_BOARD_V7` / `PONS_BOARD_V71`）。
下の表と同じ対応がそこに 1 つだけ置いてあり、ピン定義と `IMU_SENSOR_DEFAULT` は
そこから分かれる。0.986 までは「新基板では〜」という散文の断り書きが
5 ファイル 20 箇所に散っていた。

| GPIO | ネット | 役割（v7.1） | v7 では |
|---|---|---|---|
| 41 | `SPI1_CS` | SCH16T の CS | E220 の M0/M1 |
| 42 | `SPI1_SCK` | SCK | i2c1 と 0Ω 連結（R46/R47 は消滅） |
| 43 | `SPI1_TX_MOSI` | MOSI | `IMU_I2C_SA0_PIN` |
| 44 | `SPI1_RX_MISO` | MISO | i2c1 と 0Ω 連結 |
| 45 | `SCH16T_RESET` | EXTRESN（負論理） | BNO_INT |
| 46 | `SCH16T_SYNC` | DRY_SYNC（入力） | BNO_NRST |
| 47 | `LORA_M01` | **E220 の M0+M1 を結線して 1 本で駆動** | BNO_PS0/WAKE |

- SCH16T は基板実装ではなく **J7（Molex 200528-0080, 8pin FPC）経由の外付け**。
  `kicad/IMU_murata/` のブレイクアウトと 1:1 ケーブルで繋がる
- 41〜44 は RP2350 の SPI1 の正規割り当てなのでハードウェア SPI が使える。
  arduino-pico では **`SPI1`**（`SPI` は spi0）。GPIO46 が SPI1_SCK の代替機能でもあるので
  **`SPI1.setSCK(42)` を明示する**

### v7.1 で動かす前に直すコード

**4 つとも済んだ**（0.986）。3 つは `PONS_BOARD` のスイッチ、1 つはファイル分割で。

| 場所 | 状態 |
|---|---|
| `e220.h` の `E220_MODE_PIN`（41 → 47） | **済**。`#if PONS_BOARD == PONS_BOARD_V71` |
| `settings.h` の `IMU_PS0_WAKE_PIN` ほか BNO085 のピン | **済**。v7 だけで定義し、v7.1 では存在しない（使うと未定義で止まる） |
| CLAUDE.md の GPIO41 / 42・44 の約束 | **済**。【v7 のみ】を付け、正本を `PONS_BOARD` の表にした |
| `imu_bus_park_unused_pins()` の 42/44 を `INPUT_PULLUP` | **済**（0.986）。§1 のファイル分割で `imu_bno08x.cpp` の中だけになり、v7.1 ではファイルごと `#if` で消える。外から呼んでいる箇所は無い |

★ `PONS_BOARD` を `PONS_BOARD_V71` にすると、いまは
**`#error`（ドライバが無い）で止まる**。これが切替点の見張りになっている。

★ **「設定で BNO085 / SCH16T を選べる」の意味。** センサーを物理的に降ろすので
同一基板で両方を切り替えることはできない。設定は「この機体にどちらが載っているか」の
宣言になる（3 台の機体で混在させるため）。§2.1 の「起動時のみ有効」はそのままでよい。

## 4. 進め方の順番

1. ~~`tools/attitude_test` にテストを足し、`attitude.cpp` の GRV 依存を外す~~ → **0.983 で完了**
2. ~~バリオ KF の重力除去を ESKF 由来に切替~~ → **0.983 で完了**（§2.3）
3. ~~Phase 2（§6）: ESKF に重力観測を足す~~ → **0.984 で完了**
   （2026-10-03 の走行 2 時間で検証。GNSS 断時の姿勢誤差 中央 21.3→1.3 / 74.9→1.8 度）
3.5. ~~MAG の購読停止と、抽象化の境界（[imu_sensor.h](../imu_sensor.h)）~~ → **0.984 で完了**（§1）
4. 単独テスト（[tools/sch16t_test/](../tools/sch16t_test/)）で SCH16T の性能を確定。
   **読み出しレートの選択（§5 の (2)）もここで決める**
5. ~~残りの抽象化（ファイル分割・`imu_drv_*`）を入れて、**BNO085 のまま無回帰を確認**~~
   → **0.986 で完了**（§1）。`imu_sensor` 設定キーだけ据え置き（要否の再検討つき）。
   ★ 「抽象化しただけで挙動が変わっていない」状態をここでコミットしてある。
   SCH16T を足したあとの不具合を切り分けるための足場なので、**先に進む前に
   実機で一度飛ばしておくこと**
6. SCH16T ドライバを足す → **`KF_R` / `KF_Q_VEL` 再測定**
7. 画面・ログ・ドキュメント（§2.4〜2.9）

★ **Phase 2 を SCH16T より前に置く理由（2026-10-01 に判断）:**

- **BNO085 が載っているうちにやるほうが検証できる。** GRV は「常時重力基準」の
  参照値なので、重力観測が正しく働いているかを突き合わせられる。
  降ろしてしまうと比較対象が無くなる
- 0.983 で GRV を外した結果、**GNSS 断中はロール・ピッチに錨が 1 つも無い**状態に
  なっている（§6.1 の実測で 2 分 2〜4 度）。この穴を抱えたまま
  センサー交換という大きな変更を重ねたくない
- Phase 2 は**両センサー共通で効く**ので、先にやれば SCH16T 側で作り直す必要がない

★ 5 と 6 を分けるのが重要。**「抽象化しただけで挙動が変わっていない」状態を作っておくと、
SCH16T を足したあとの不具合が「抽象化のせい」か「SCH16T のせい」か切り分けられる。**

## 5. SCH16T の仕様（実装に必要な分）

**2026-10-01 にフルデータシート（Doc.No.11624 Rev.6, 65 ページ）で全件照合済み。**
検証の詳細と、PX4 / 先駆者ライブラリとの相違点は
[tools/sch16t_test/README.md](../tools/sch16t_test/README.md) の「検証状況」節にある。

| 項目 | 値 |
|---|---|
| SPI | mode 0（CPOL=0/CPHA=0）、48bit フレーム、SCK **0.095〜10.5MHz**（下限もある） |
| フレーム | `TA[47:38]`（上位 2bit=CS / 下位 8bit=レジスタ）`\| RW[37] \| FT[35] \| DATA[27:8] \| CRC8[7:0]` |
| CRC8 | 多項式 0x2F・初期値 0xFF・XOR out なし・bit 47〜8 が対象 |
| **応答** | **1 フレーム遅れて返る**（SafeSPI アウトオブフレーム）。先頭に捨てフレームが必要 |
| ステータス | 応答の [36]IDS [35]CE [34:33]S1:S0（00=正常 01=エラー 10=飽和 11=初期化中） |
| 感度（20bit 既定） | ジャイロ 1600 LSB/(°/s)、加速度 3200 LSB/(m/s²)、ACC3 1600、温度 100 LSB/°C |
| レンジ | ±327.68 °/s、±163.84 m/s²（ACC3 ±260 m/s²）。**設定 `'000'` は書いてはいけない** |
| ODR | 間引きなし 11.8kHz / 5.9k / 2.95k / 1.475k / **737.5Hz** |
| フィルター | LPF0 68Hz（既定）/ LPF1 30 / LPF2 13 / LPF3 280 / LPF4 370 / LPF5 235 / LPF7 バイパス |
| 初期化 | リセット → **32ms**（NVM）→ 設定 → `EN_SENSOR` → **215ms** → ステータス 1 周 → `EOI` → **3ms** → ステータス 2 周 → 検証 |
| 品種 ID | **`COMP_ID = 0x0023` が SCH16T-K01。** `ASIC_ID` はシリコンのリビジョンなので品種判定に使えない |
| 出力 | `*_1` = 補間（実効 ODR 極大・ジッタ<2.6µs）、`*_2` = デシメーション（DRY が紐づく）、`*_3` = 広レンジ補助加速度 |

### ★ 統合設計に効く 2 点（今回の照合で判明）

**(1) `EOI` を書くとソフトリセットと `SYS_TEST` 以外の R/W レジスタが全部ロックされる**（Table 80）。
リセットしない限り解除できず、ロック後に書くと `CE`（コマンドエラー）が立つ。

→ **設定画面からフィルターやレンジを実行中に変えることはできない。**
`imu_sensor` の切替を「起動時のみ有効」にする方針（§2.1）と同じ扱いにする。
逆に言えば **EOI を立てておけば設定が壊れない**ので、立てない選択はしないこと。

**(2) LPF ごとに「最小推奨読み出しレート」がある**（§5.5 Table 16）。
下回るとフィルター阻止域のノイズが折り返して帯域内に入る。

| LPF | カットオフ | 最小推奨読み出しレート |
|---|---|---|
| LPF2 | 13Hz | 150Hz |
| LPF1 | 30Hz | 200Hz |
| **LPF0（既定）** | **68Hz** | **500Hz** |
| LPF3/LPF5 | 280 / 235Hz | 1000Hz |
| LPF4 | 370Hz | 2000Hz |

→ **現状の BNO085 は 50Hz でレポートを要求している。同じ感覚で SCH16T を 50Hz で読むと
折り返す。** 選択肢は 3 つあり、実装前に決める必要がある。

1. **LPF2（13Hz）にして 150Hz 以上で読む** — HPA の運動帯域は 5Hz 以下なので帯域は足りる。
   Core0 の負荷は 150Hz × 8 フレーム。素直
2. LPF0 のまま 500Hz 以上で読み、ソフトで間引く — 帯域は広いが Core0 の負荷が増える
3. デシメーション出力（`*_2`）を DRY 割り込みで読む — ジッタ最小。ただし 737.5Hz が下限で、
   その全数を読むのは PONS には過剰

データシートが「水平検出・測位用の IMU」に推奨しているのは
**「既定設定（LPF0・補間出力）を最小推奨レートで読む」**＝ 選択肢 2。
ただし PONS の用途では 1 が妥当に見える。**単独テストで両方のノイズを実測して決める。**

### まだ触っていないもの

- **`CTRL_ST`（セルフテスト）** — ビット配置は判明済み（Table 78）。`RATE_STC_CTRL[11:9]` の
  リセット値が `3b111` など 0 でないビットがあるので、ここも read-modify-write が必要。
- `CTRL_*_FLAG_*`（飽和フラグのフィルター設定）— 既定 0 のまま。

### ★ 破ると静かに壊れる約束（SCH16T 側。CLAUDE.md に足す候補）

- **`CTRL_USER_IF` と `CTRL_ST` は read-modify-write すること。** リセット値が 0 でない
  ビットがある。`CTRL_USER_IF` を素で書くと `MISO_SR_CTRL` / `DRY_SR_CTRL` を 0 に落とし、
  データシートが *"not supported by Murata"* と書いている側の設定になる。
  **PX4 のドライバはこれを踏んでいる**ので、あちらを参考にするときは注意。
- **読み出しは 1 フレーム遅れる。** 先頭の捨てフレームを落とすと、
  全軸が 1 つ前のレジスタの値になる（`gx` に前回の何かが入る、という形で静かに壊れる）。
- **`DYN_*` に `'000'` を書かないこと**（CTRL_RATE / CTRL_ACC12 では "Undefined"）。
- **`DRY_SYNC` を出力にしないこと。** SYNC 入力との兼用ピン。
- **`EOI` 後は設定を変えられない。** 変えたければリセットからやり直す。

### 期待される改善（比較の基準）

| 項目 | BNO085 実測 | SCH16T データシート typ |
|---|---|---|
| `\|a\|/g` | 0.985〜0.992（約 −1%） | 1.000 に乗るはず |
| 加速度ノイズ | σ = 0.0008 g（2Hz LPF 後） | オフセット ±0.01 m/s² |
| ジャイロ | 申告精度 0 のまま・ZRO 温度ドリフト | オフセット XY ±0.1 / Z ±0.01 °/s、ノイズ密度 XY 0.0004 °/s/√Hz |

BNO085 側の数値は `tools/imulog/` の解析より
（→ `memory/vertical-g-estimation.md`）。`|a|` はノルムなので回転不変で、
マウント角のずれに依らずスケール誤差を比較できる。

---

## 6. Phase 2 — ESKF に重力観測（levelling update）★ **0.984 で完了・実機検証済み**

0.983 で GRV を外したときに**残した穴**を埋める作業。**両センサー共通で効く**ので
SCH16T より先にやった（BNO085 が載っているうちなら GRV を参照値にして検証できる）。

### 6.1 なぜ必要だったか

ESKF の観測は **GNSS 速度だけ**（`H = [0 I 0 0]`）なので、ロール・ピッチは
`d(dv)/dt = −[Rf]×dθ` の結合を通して*間接的に*しか拘束されない。
つまり **GNSS が無い間、重力の錨が 1 つも無い**（BNO085 の GRV が内部で担っていた）。
`eskf.py` の `gnss_cutoff` で測ると GNSS 断 2 分で 2〜4 度ずれ、
**バンク警報のしきい値 4 度**（`BANK_WARN_DEG`）に届く。誤警報にも見逃しにも効く。

同時に消えた穴が 2 つ:

1. トンネル等の GNSS 断（0.983 のバリオ V/S 差の最大値 2 件は、どちらも
   「前後 3 秒に測位 0 件」の瞬間だった）
2. 「GNSS はあるのに対地速度が 3m/s に届かない」と観測ゼロ（§2.2 の残存挙動差）

### 6.2 何をしたか

準定常のとき、比力をワールドへ回した `f_w` は `(0,0,g)` になるはずなので、
**その水平 2 成分を期待値 0 の観測として入れる**（2Hz）。実体は `attitude.cpp` の
`level_update()`、定数は `settings.h` の `ESKF_LEVEL_*`。

★ **ゲートが本体。** 無条件に入れると協調旋回でバンクを過小評価し、GRV と同じ
間違い＝ ESKF が存在する理由を壊す。主ゲートは**旋回レート**で、`|f| ≒ g` は
粗い健全性チェックにしか使わない（5 度バンクの `|f|-g` は 0.0375 m/s² で、
加速度計のスケール誤差 0.098 m/s² に埋もれる）。**導出と数値はすべて
`settings.h` の `ESKF_LEVEL_*` のコメントにある**（ここには書き写さない）。

60 秒ログに `gobs=` で累計回数が出る。**0 のままならゲートが閉じている。**

### 6.3 検証結果

| 検証 | 結果 |
|---|---|
| **実機 2 時間（2026-10-03 走行）GNSS 断時の \|誤差\|** | 中央 **21.3° → 1.3°** / **74.9° → 1.8°** |
| 同・ゲート開口率（実機 `gobs=` 実測） | 走行中 **58〜61%** / 静止中 **97%** |
| オフライン（20260818 s1、短い窓） | 中央 5.04° → 2.44° |
| 協調旋回 20 度（`main.cpp`、真値既知） | **19.34° で Phase 2 前と完全に同一** |
| 5 度バンク相当の旋回レートで観測が入るか（`yaw_test` F2） | **30 秒で 0 回** |
| 直進・静止で観測が入るか（F1） | 10 秒で 20 回（2Hz どおり） |
| GNSS 無しでロール・ピッチの錨になるか（F3） | 0.5°/s のオフセットで 2 分、ロール変化 **0.00°** |
| GNSS 常時のときの姿勢変化 | 中央 0.21〜0.29°。**旋回レートで層別しても一様**＝ゲート漏れなし |

★ **「静止中の再水平化」(0.983) は残した。** 役割が違う:

- 再水平化（相補フィルタ・50Hz・時定数 1 秒）… 待機中の維持。同ブロックの
  `reset_covariance` が毎サンプル P を戻すので `level_update` が溜めた情報はどうせ
  捨てられる。実効の引き戻しはこちらが担う
- `level_update`（正式な観測・2Hz）… 飛行中と GNSS 断中の錨

1 つに統合するのは、待機中の挙動（`yaw_test` の D1/D2）を再検証してからにする。

### 6.4 実装時に踏んだもの（記録）

- **ヨーレートの更新をゲートより後ろに置いていた。** ゲートが 1 サンプル前（20ms 前）の
  値で判定し、**旋回の入り口で観測が 1 回漏れた**（F2 が捕まえた）。伝播の直後・
  ゲートの直前へ移した
- **`f_w` が下向きのときのガードが無かった。** H は `f_w ≒ (0,0,+g)` のまわりで
  線形化してあるので、下向きだと符号が逆になり補正が誤差を広げる。`fw[2] < 0.5g` で弾く
- **`bg_` が学習クランプを超える。** `level_update` が相関経由で `bg_` を微調整するため
  （実測 +0.003 deg/s）。クランプは「学習器が書く値」に対するものなので正常。
  D3 の判定を実態に合わせた

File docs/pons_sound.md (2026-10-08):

# PONS の音 — 仕様の要約

PONS の音は **3 系統**あり、**1 つのスピーカーで同時に鳴る**。
この文書はその 3 つの関係と、どれがどれを止めるのかだけを短くまとめたもの。
音声ファイルの一覧は §9、音声を持たない音は §10 にある。
どんなときに何が鳴るかの説明は [../README.md](../README.md) の「警告音・警報」にもある。

実装は [../src/sound.cpp](../src/sound.cpp)、キューは [../mysd.h](../mysd.h)。

---

## 1. 3 つの音

| 系統 | 何の音か | 出し方 |
|---|---|---|
| **WAV** | 「バッテリー低下」などの日本語音声 | 本体 FLASH に焼いた音声を再生（0.982 以降。SD ではない） |
| **トーン** | 操作音・警告のピピッ音 | Sin 波を指定の周波数・長さで |
| **バリオ** | 昇降計。上昇＝断続ビープ / 下降＝連続低音 | Sin 波を常時 |

**3 つとも 16kHz の割り込みの中で足し算して 1 本の PWM に出している。**
だから基本は**全部同時に鳴る**。止め合うのは
**WAV 対 WAV**（§3）と **WAV 対 `solo_play` トーン**（§4）の 2 つだけ。

## 2. どの Core が何をするか

```
Core0（画面・センサー・判断）              Core1（SD・音）
  enqueueTask(createPlayWavTask(...))  ──▶  タスクキュー ──▶ 再生開始
  update_vario()  ← バリオだけ Core0 が直接パラメータを書く
```

- **Core0 は「鳴らして」と頼むだけ。**実際に鳴らすのは Core1。
- **音声のために SD は読まない（0.982 以降）。** それでも Core1 専用なのは、
  再生バッファとタイマー割り込みの状態を動かすから。Core0 から呼ぶと
  `loop_sound()` と衝突して音が壊れる。見張りは `ASSERT_CORE1`
  （SD 用の `ASSERT_SD_CORE1` とは別。流用すると「SD access from Core0」と
  嘘のログが出て、読む人を SD の方へ誤誘導する）。
- キューは 40 本。溢れると**捨てられて二度と鳴らない**（USERLED が点灯して知らせる）。
- **バリオだけ例外**で、Core0 の `update_vario()` が 100ms ごとに周波数と断続周期を
  直接書き換える。キューを通らないので、キューが混んでいてもバリオは遅れない。
- 音を出す 16kHz の割り込みは（Core1 で登録しても）**Core0 で動く**。

## 3. 優先度

WAV とトーンは `priority`（数字が大きいほど優先）を持つ。実際に使っている値:

| 値 | 例 |
|---|---|
| 4 | 測位完了 `fixed.wav` |
| 3 | 目的地切替、バンク警告、ESKF 関連の案内 |
| 2 | コース逸脱 `course_left/right.wav`、無線モードの通知 |
| 1 | 電池低下、目的地が遠すぎる、操作音 |

優先度で止め合うのは **WAV 対 WAV** と **WAV 対 `solo_play` トーン**（§4）の 2 つだけ。
**通常のトーンとバリオは優先度で止まらない**（どちらも WAV と足し算されるだけなので、
潰し合わない）。

### WAV 対 WAV

```
新しい WAV を鳴らしたい
  ├ 同じ音声を再生中              → 何もしない（頭から鳴り直さない）
  ├ 再生中の方が高優先            → 新しい方を pending に置いて待つ
  └ 新しい方が同等以上            → 再生中を pending に退避して割り込む
                                     （終わったら pending の中で一番高いものを再生）
```

- pending は **2 件まで**。両方埋まっているときは、新しいほうが既存の最低優先度より
  高ければ入れ替え、そうでなければ**新しいほうを捨てる**。
- pending から復帰した WAV は**もう一度は退避されない**。
  退避すると必ず先頭から鳴り直すので、放っておくと冒頭の断片だけが繰り返される。
- **pending は優先度だけでなく `min_volume` も運ぶ。** 落とすと復帰時に既定の 0 に
  戻り、`battery_low.wav` の最低音量 60 が消える（§5 の★を参照）。
  0.981 までこれが落ちていた。
- **「同じ音声か」の判定は `WAV_ENTRIES[]` の添字で見る。名前のポインタでは比べない。**
  同じ `"wav/track.wav"` でも別の .cpp に書かれたリテラルは別アドレスになり得るので、
  ポインタ比較では**いつ静かに外れてもおかしくない**（0.981 まで `strcmp` と
  ポインタ比較が混在していた）。

### 排他グループ — 言い替えられた音声は pending に残さない

pending は「割り込まれた音声をあとで鳴らし直す救済」だが、**いまの状態を読み上げる
音声にとっては救済が害になる**。古い読み上げがあとから流れると、機体が**もう事実では
ないことを喋る**。

そこで `startPlayWav()` / `createPlayWavTask()` は `excl_group`（`settings.h` の
`WAV_EXCL_*`）を取る。同じグループの音声は「ひとつの状態の言い替え」とみなし、

- 新しい方が来たら、**同じグループの pending を捨てる**
  （新しい方自身が pending に回る場合も捨てる。残すと 2 回喋る）
- 新しい方が古い方に割り込むとき、古い方を**pending に退避しない**

`WAV_EXCL_NONE`（既定）は従来どおりの救済。**「鳴らさない」指定ではない** —
自分が割り込まれる側になる判定（優先度）は何も変わらない。

| グループ | 対象 |
|---|---|
| `WAV_EXCL_LINKMODE` | `sender_mode.wav` / `receiver_mode.wav` / `link_off.wav`（無線モードの読み上げ） |

★ 入れた経緯: 無線モードは設定画面で OFF→SENDER→RECEIVER の回転式なので、
**RECEIVER へ行くには SENDER を必ず通る。** 0.984 まで通過した `sender_mode.wav` が
`receiver_mode.wav` に割り込まれて pending に入り、**受信モードにした直後の機体が
「送信モード」と読み上げていた。** 読み上げは飛行前の操作ミスに気づく手段なので、
これは目的の反転。**状態を読み上げる音声を足すときは排他グループを付けること。**

## 4. 同時に鳴るか、止まるか

| 組み合わせ | どうなる |
|---|---|
| WAV ＋ バリオ | **同時に鳴る** |
| トーン ＋ バリオ | **同時に鳴る** |
| WAV ＋ 通常トーン | **同時に鳴る**（優先度も見ない。短い操作音が音声を潰さないため） |
| WAV ＋ `solo_play` トーン | **排他**。下記 |

`solo_play` は「この音を先に聞かせてから音声を流したい」ときに使う。
コース逸脱警告が `ピピピ → course_left.wav` の順で鳴るのはこれ。
使っているのは **コース逸脱警告** と **Auto10km の折返し通知（往路→復路・復路→往路の両方）** だけ。
Auto10km の 2 つは**必ず同じ指定にすること。**片方だけ通常トーンにすると、同じ
「目的地が切り替わった」通知なのに一方は音声と重なって鳴り、聞き分けを誤る。

```
solo_play トーン中に WAV が来た
  ├ WAV の方が高優先  → トーンを一時停止 → WAV → トーン再開
  └ WAV が同等以下    → WAV を pending へ → トーン完走 → WAV
```

## 5. 音量

設定画面に **音量**（`sound_volume`）と **バリオ音量**（`vario_volume`）があり、独立している。

- `sound_volume = 0` … WAV とトーンが鳴らない。
  WAV はアンプも ON にしない（ポップノイズ防止）が、**トーンはアンプを ON にしてから
  無音を出す**（`startNextToneEntry()` が音量を見ていない）。実害はポップ音だけ
- `vario_volume = 0` … バリオが鳴らない
- `vario_inhibit = true` … バリオを完全に無効化。**SD の `settings.txt` でしか設定できず、
  設定画面からは変更できない**（バリオ非搭載機向け）

**`min_volume`（最低保証音量）** を指定した音は、`sound_volume` が小さくても
その値まで引き上げて鳴らす。

★ **これを付けてよいのは電池切れの警告だけ**（`battery_low.wav` と
`battery_low_sender.wav`、値は 60）。**持ち主が機体から離れていても電池切れに
気づけるように**という目的だけで入れた仕組みで、他の警告にも付けると
「音量を絞ったのに全部の警告が大音量で鳴る」ことになり、絞った意味が無くなる。

★ **pending を経由しても `min_volume` を落とさないこと。** `battery_low.wav` は
優先度 1（最低）なので、他の WAV とぶつかれば**必ず** pending を通る。そこで 60 が
抜けると `sound_volume = 0` の機体ではアンプが上がらず、**電池切れの警告が完全に
無音になる**。0.981 まで pending が `min_volume` を持っておらず、復帰再生は既定の 0 に
なっていた。0.982 で SD 無しのときの代替ビープ（トーン側は音量を保持していた）を
消したので、この経路が唯一の警告になった。

上昇音は下降音より小さく出る。小型スピーカーは高音の能率が高く、
同じ振幅だと上昇側だけうるさくなるため `VARIO_ASCEND_VOL_PCT` で絞ってある。

## 6. バリオの鳴り方

`update_vario()` が 100ms ごとに昇降率を見て決める。

```
上昇率 > デッドバンド   → 断続ビープ。速いほど高く、間隔が短い
下降率 > デッドバンド   → 連続低音。  速いほど低い
その間（デッドバンド内）→ 無音
```

実際の値（KF 融合時。デッドバンド ±0.25m/s）:

| 昇降率 | 上昇 | 下降 |
|---|---|---|
| 0.25 m/s | 804Hz　ON 120ms / OFF 2572ms | 554Hz 連続 |
| 0.5 m/s | 900Hz　ON 120ms / OFF 1280ms | 530Hz 連続 |
| 1.0 m/s | 1100Hz　ON 120ms / OFF 580ms | 480Hz 連続 |
| 1.5 m/s 以上 | 1300Hz　ON 120ms / OFF 346ms | 430Hz 連続 |

- **デッドバンドは 2 段階**。BNO085 と MS5611 が両方生きていれば ±0.25m/s、
  BNO085 が応答しなければ MS5611 単独にフォールバックして ±0.60m/s に広げる。
- **上昇・下降とも 1.5m/s で振り切り**（それ以上速くても音は変わらない）。
- **この定数は音と画面で共用している。**VSI のグレー線も同じデッドバンドを見るので、
  片方だけ変えると「線は出ているのに鳴らない」になる。
- **V/S の供給元とデッドバンドの選択は `imu.cpp` の `vario_vspeed_mps()` /
  `vario_deadband_mps()` / `vario_source_ok()` に集約してある。**
  0.983 までは定数だけ共用で、**どちらを選ぶかの判定式が音（`get_imu_alive()`）と
  画面（`get_imu_ok()`）で別**だった。`update_vario()` と `draw_vsi()` から
  センサーの生死を直接見ないこと。
- **無線のミラー中は送信機（機体）の V/S で鳴る。** 受信モードは送信機の画面と音を
  再現するもので、自機のセンサーの有無で分岐してはいけない。0.983 まで受信機の
  BNO085 が応答しないと自機の気圧 V/S へ落ちており、**ボートの波の上下動で
  バリオが鳴った**（デッドバンドは送信機の `LINK_ST_IMU_ERROR` で選ぶ）。
  詳細は [pons_link.md](pons_link.md) §5。

## 7. WAV の持ち方と条件

**16kHz / 8bit unsigned PCM / モノラル。**
**音声は本体 FLASH に焼いてある（0.982 以降）。SD は読まない。**
SD が無い・壊れている機体でも警報の音声が鳴るようにするため。
32 本・約 2.0MB・126 秒で、16MB FLASH の約 12%。

**この 2.0MB のせいで Arduino IDE の Flash Size が 2MB だとリンクが通らなくなった。**
16MB（no FS）にすること。詳しくは [../CLAUDE.md](../CLAUDE.md) のビルド節。

- 原本はリポジトリ直下の `wav/`。実機が読むのは
  `src/flashdata/wav_data.cpp`（`tools/gen_wav_flash.py` の生成物）。
  **音声を差し替えたら生成し直すこと。忘れると古い音のまま焼ける。**
  リリース前は `tools/gen_wav_flash.py --check` で CRC32 照合できる。
- RIFF ヘッダは生成時に取り除いてある。0.981 までのように
  「先頭 44 バイトを読み飛ばす」処理は実機側に無い。
  ヘッダ長は固定ではない（`LIST` や `fact` チャンクが入ると 44 にならない）ので、
  生成側で `data` チャンクを正しく切り出している。
- 16KB（約 1 秒）ずつダブルバッファへ `memcpy` する。**割り込みは RAM だけを読む。**
  FLASH はメモリマップされているので割り込みから直接読むこともできるが、
  16kHz の割り込みハンドラ（`__not_in_flash_func`）が XIP を触る形にしたくないので、
  供給元だけを差し替えてバッファ構成は残してある。
- アンダーラン（次チャンクが間に合わない）経路は残っているが、`memcpy` なので
  原理的には起きない。Core1 が長時間止まったときに無音で固まらないための受け皿。
- **`good_sd()` で音の出る条件を絞らないこと。** 0.982 までは 7 箇所に
  「SD が無ければビープで代替」があり、**SD が壊れた機体では警報がぜんぶビープになって
  種類が区別できなかった**。いまは SD の有無に関係なく全部喋る。
  - ただし起動時の 500Hz ×10（`display_tft.cpp`）は別物で、
    **SD 故障を音で知らせる唯一の手段**。起動音と重なって鳴る。消さないこと。
- **焼いていない音声名を要求した**場合だけ 500Hz ×2 と
  `ERR wav not in flash` のログ。生成ツールがソース中の `"wav/*.wav"` を
  全部突き合わせてビルド前に止めるので、通常は起こらない。

## 8. 触るときの注意

- **警報を描画関数の中に書かない。** その画面を出しているときしか鳴らなくなる。
  発報は `loop()` の最上位へ（[../CLAUDE.md](../CLAUDE.md)）。
- **同じ音を連続で積まない。** WAV は同一ファイルの再要求を弾くが、
  トーンは弾かないのでキューが埋まる。
- `enqueueTaskWithAbortCheck()` は**キューにある同じ種類のタスクを消してから**積む。
  古い警告が残って二重に鳴るのを防ぐためのもの。
  - ★ **消す範囲は「自分と同じか、自分より低い優先度」まで**（0.970 から）。
    種別だけで消していたころは、設定画面の**音量確認音（優先度 1）が、コース逸脱警報や
    Auto 10km の折返しチャイム（優先度 2/3）まで巻き添えで消していた**。
    0.965 で警報が画面によらず鳴るようになり、音量をいじっている最中に警報が来る
    組み合わせが現実に起こるようになったので直した。
  - ★ **トーン列にはもう使っていない**（0.970 から）。消す側に回ると、チャイムの 2 秒の間に
    別の警報が発報したとき、**向こうの 4 音だけが消えて音声だけが残る**。
    コース逸脱と Auto 10km の折返しは、いまはどちらも普通の `enqueueTask()` で積んでいる。
    Core0 は単スレッドなので、4〜5 音は必ず連続してキューに入る。
  - いまの唯一の利用者は設定画面の音量確認音（[../src/button.cpp](../src/button.cpp)）。

## 9. 音声ファイル一覧

原本はリポジトリ直下の `wav/`（SD には置かない）。
`min` は最低保証音量（空欄 = 指定なし）。「内容」は実際に喋っている文言。

### 起動・操作

| ファイル | 優先度 | min | いつ鳴るか | 内容 |
|---|:--:|:--:|---|---|
| `opening.wav` | 1 | | 起動時。起動アニメーションの最初 |ポンズ|
| `matane.wav` | 1 | | 設定画面を抜けるとき。下の 5 つから起動秒数で 1 つ選ぶ |またね|
| `baibai.wav` | 1 | | 〃 |ばいばい|
| `arigato.wav` | 1 | | 〃 |ありがとう|
| `makenna.wav` | 1 | | 〃 |負けんな|
| `tsuyoi.wav` | 1 | | 〃 |強い|

### 航法・警報

| ファイル | 優先度 | min | いつ鳴るか | 内容 |
|---|:--:|:--:|---|---|
| `fixed.wav` | **4** | | GNSS が測位した瞬間（未測位→測位のエッジ） |測位しました|
| `track.wav` | 1 | | 真方位が基準から 15° 以上変化（対地速度 2m/s 以上のときだけ） |トラック|
| `course_left.wav` | 2 | | コース逸脱の積算値が上限に達した（左へ修正） |進路左に旋回、進路左に旋回|
| `course_right.wav` | 2 | | 〃（右へ修正） |進路右に旋回、進路右に旋回|
| `destination_change.wav` | 3 | | Auto 10km の折返し。往路→復路・復路→往路の両方 |自動で目的地が更新されました、ご注意ください。|
| `destination_toofar.wav` | 1 | | 目的地が 100km 以上離れている（120 秒ごと） |目的地から100km以上離れています。適切な目的地を設定してください。|
| `bank_warning.wav` | 3 | | ロールがバンク角警告のしきい値を超えた |バンク！バンク！|
| `battery_low.wav` | 1 | 60 | 自機のバッテリー低下 |バッテリー低下|

### 姿勢・較正

| ファイル | 優先度 | min | いつ鳴るか | 内容 |
|---|:--:|:--:|---|---|
| `eskf_calib_required.wav` | 3 | | 較正のやり直しが必要な状態が続いている。**地上で静止しているときだけ** 120 秒ごと |姿勢の較正をやり直してください|
| `roll_check.wav` | 3 | | 地上でロールが大きい（搭載の傾きを疑う値） |長時間のロールを検出しています。設定は合っていますか。|
| `pitch_check.wav` | 3 | | 地上でピッチが申告値から外れている |長時間のピッチを検出しています。設定は合っていますか。|
| `guide_eskf_setting.wav` | 3 | | 設定画面で ESKF 較正メニューに入ったとき |セットピッチが現在の地面の傾斜角と一致しているかどうか。セットロールが現在の機体の角度と一致しているかどうか。本体の向きが進行方向に向いていて固定されているか。これら3軸が合っているか確認してから、校正を実行。APPLYしてください。|
| `change_setroll_caution.wav` | 3 | | 設定画面で申告ロールを 0 から動かした瞬間（1 回だけ） |これはロール画を0度以外で校正する機能です。ウィングローで待機中にロール角を再校正しなければいけない状況で使います。機体が水平でロール角を0度に校正することを基本としてください。|
| `eskf_apply_done.wav` | 3 | | ESKF の較正（APPLY）が完了した |現在の機体姿勢とESKFピッチ・ロール角が一致しているか確認してください。|
| `eskf_calib_oldday.wav` | 3 | | 最後に較正した日から**日付をまたいでいる**（JST）。**地上で静止しているとき、1 回の電源投入につき 1 度だけ**。直前に 1319Hz ×2 が鳴る |最後の校正から時間が経過しています。一度マウントから外した場合は再度校正してください。|

### 無線（PONS Link）

`link_*` はすべて `link_alert()` 経由なので **優先度 3 で固定**。
最低音量を付けているのは `battery_low_sender.wav` だけ（上記の理由）。

`link_alert()` は第 2〜4 引数にトーンの周波数・長さ・回数も取るが、これは
**`wav` に `nullptr` を渡す「音声を用意していない警告」専用**（送信機の異常フラグ受信）。
0.982 までは「SD が無ければこのトーンで代替」という役割も兼ねていた。
音声が FLASH に移って代替が不要になったが、**引数ごと消さないこと。**

| ファイル | 優先度 | min | いつ鳴るか | 内容 |
|---|:--:|:--:|---|---|
| `sender_mode.wav` | 2 | | 送信（TX）モードで起動した／TX へ切り替えた |パイロット用・送信モード|
| `receiver_mode.wav` | 2 | | 受信（RX）モードで起動した／RX へ切り替えた |観測用・受信モード|
| `link_off.wav` | 2 | | 無線 OFF で起動した／OFF へ切り替えた（0.985〜） |リンクオフ|
| `link_no_signal.wav` | 3 | | 受信機で、機体からの電波が途絶えた。**リプレイ中・デモ中は鳴らさない** |受信が途切れました。自機の情報を表示します。|
| `link_dup_sender.wav` | 3 | | 受信機で、同じグループの送信機が 2 台いると判定した。**続いている間は 1 分ごとに繰り返す**（1 回きりだと聞き逃したら二度と鳴らないため） |送信機が２台あります|
| `link_no_module.wav` | 3 | | 無線モジュールが応答しない（リプレイ中・デモ中も鳴る） |無線モジュールが応答しません|
| `link_setting_changed.wav` | 3 | | CH / SF / グループを変えたまま設定画面を出た |送信機と受信機の設定が一致していることを確認してください。|
| `link_override_dest.wav` | 3 | | 受信機で、機体側の目的地・ナビモードに自動で合わせた |警告。送信機に合わせるため目的地と誘導モードを自動で変更しました。|
| `link_ch_busy.wav` | 3 | | 送信前チェックで、同じチャンネルに他の送信機を見つけた |同じチャンネルに他に送信機がいます。設定を確認してください。|
| `link_ch_noisy.wav` | 3 | | 送信前チェックで、チャンネルの雑音が高かった |このチャンネルはノイズが多いです。チャンネル変更を検討してください。|
| `battery_low_sender.wav` | 3 | 60 | 受信機で、**送信機（機体）の**バッテリー低下を検知した |送信機側のバッテリーが低下しています。|

★ モードの読み上げ 3 つ（`sender_mode` / `receiver_mode` / `link_off`）には約束が 2 つある。
**OFF を無音に戻さないこと**（理由は [pons_link.md](pons_link.md) §1）と、
**`WAV_EXCL_LINKMODE` を必ず付けること**（理由は §3「排他グループ」）。

### 注意

- **音声名はコードに直接書いてある。**名前を変えると、その音声は二度と鳴らない。
  ただし **`tools/gen_wav_flash.py` がソース中の `"wav/*.wav"` を全部突き合わせ、
  `wav/` に無い名前があればビルド前に止める**ので、打ち間違いは実機まで届かない。
  0.981 までは実機で `ERR wav missing` が出るまで気づけなかった。
- **焼いていない音声名を要求したときだけ** 500Hz ×2 のエラー音が鳴り、
  `log.txt` に `ERR wav not in flash: <名前>` が残る（SD があれば）。
  上のビルド前チェックを通していれば起こらない。
- 0.982 で SD 由来のエラー経路（`ERR wav missing` / `ERR wav open` /
  `ERR wav too small`、およびカード層エラーコードでの切り分け）は**まとめて消えた**。
  音声は FLASH にあるので「無い」「開けない」「壊れている」が原理的に起こらない。
- 全 31 ファイルがコードから参照されていて、未使用のものは無い
  （未参照があると生成ツールが警告する）。

## 10. 音声ファイルを持たない音

**音声の無い音のほうが種類は多い。**下は WAV を使わない音の一覧。

### 操作音（優先度 1。設定画面の操作を確かめるためのもの）

| 音 | 何のとき |
|---|---|
| 1046Hz ×1（80ms） | 短押し |
| 1046Hz ×2（50ms） | 長押し |
| 1568Hz ×1（80ms） | ダブルクリック／設定項目の決定 |
| 1568Hz ×1（60ms） | 設定値を変更した |
| 440Hz ×1（200ms） | いまは実行できない操作（飛行中の APPLY など） |
| 2793 → 1046 → 440Hz | 音量設定。高中低を鳴らして音量を体感させる |
| 294Hz ×2（優先度 2） | Auto 10km と目的地の組み合わせが禁止されていた |

### 警報・状態（音声を用意していないもの）

| 音 | 優先度 | 何のとき |
|---|:--:|---|
| 500Hz ×10（150ms） | 1 | 起動時に SD カードを読めなかった。**起動音に重なって鳴る**（SD 故障を音で知らせる唯一の手段） |
| 500Hz ×2（200ms） | 1 | 焼いていない音声名を要求した（通常は起こらない。上の §9 参照） |
| **2093Hz ×1（60ms）** | 1 | **ESKF 較正の受付**。ボタンを離した合図（ここから 1 秒静止で較正） |
| **1568 → 2093Hz** | 1 | **ESKF 較正（APPLY）完了**。`eskf_apply_done.wav` の直前に鳴らす |
| **1319Hz ×2（90ms）** | 1 | **較正した日から日付をまたいだ**。`eskf_calib_oldday.wav` の直前に必ず鳴らす（代替ではなく常に鳴る。「これから何か言う」という注意の引き方） |
| **784 → 392Hz（下降）** | 3 | **GNSS モジュールの断線**。`GNSS_LOST_ALERT_MS`（30 秒）ごとに繰り返す。★ 下降はこれ専用。他の警報はすべて上昇か同音の連打なので、「何かが失われた」と形で分かる |
| **392 → 784Hz（上昇）** | 2 | **GNSS モジュールの復帰**。上の下降と同じ 2 音を逆向きにして対にしてある |
| 330Hz ×2 | 3 | リプレイを中止した（ファイルが飛行ログでない／SD が無い） |
| 370Hz ×2 | 3 | 送信機の異常フラグを受信した |
| 880 → 1318Hz | 2 | 受信機で、途絶えていた電波が復帰した |
| 1568 → 2093Hz | 2 | 送信前チェックに合格した |
| 392Hz ×2 | 2 | 送信前チェックを実行できなかった（モジュール無応答など） |
| 3136Hz ×3 または ×5 | 1 | 真方位が 15° 変化。`track.wav` と一緒に鳴らす（30° 超で 5 回） |
| 2093Hz ×2（80ms） | 1 | 旋回角速度が 2.0deg/s 以上（対地速度 2m/s 以上） |
| 2793 / 3136Hz ×4（solo） | 2 | コース逸脱。`course_left/right.wav` の直前 |
| 2793 / 3136Hz ×4（solo） | 3 | Auto 10km の折返し。`destination_change.wav` の直前 |

## 11. 音で知らせていない警告

画面には出るが**音は一切鳴らない**ものがある。飛行中は画面を注視できないので、
ここに挙がっているものは「見ていなければ気づけない」と考えること。

| 表示 | 状態 |
|---|---|
| `ESKF Not ready` | 姿勢推定がまだ収束していない（通常は数秒で消える） |
| `Rtrim` がオレンジ／赤 | 自動ロールトリムの累積が大きい（1.5°／3.0°） |
| `Acc: XXm` | 水平位置精度が 10m 以上 |

自動ロールトリムが適用された瞬間も、ログと設定保存だけで音は鳴らない。

### ★ 充電中かつマウント外れのときは、音を止める（0.979〜）

**`USB 接続` かつ `マウントから外れた姿勢`**（`OFF_MOUNT_DEG` = 30 度／右バンクのみ 40 度）の
あいだ、次の 4 つは**音だけ**止める。机に置いて充電すると、ロール +78 度・ピッチ −80 度の
ような姿勢になって延々と鳴ってしまうため。

| 止める音 |
|---|
| `bank_warning.wav`（バンク角） |
| `roll_check.wav`（地上ロール） |
| `pitch_check.wav`（地上ピッチ） |
| `eskf_calib_required.wav`（較正のやり直し） |

- **表示とログは止めない。** ログには `(MUTED: charging + off mount)` を付けるので、
  「条件は成立していたが鳴らさなかった」ことが後から分かる
- 地図に **`IN MUTE DUE TO` / `CHARGING + OFF MOUNT`** を赤枠で点滅表示して、
  なぜ静かなのかを画面で示す
- **解除操作は無い。** 機体に載せて水平に戻した瞬間に自動で復活する。
  覚えて解除するミュートは、当日に忘れると全ての警報が無音になるため作らない
- **USB を AND 条件にしてあるのは、机の上で意図的に回して音を確認したいため。**
  充電せずに置けば従来どおり鳴る
- **ミラー中は抑制しない。** ミラー中の `BANK WARN` は機体のロールで判定するので、
  ボート自身の姿勢で黙らせてはいけない
- GNSS 断線のトーンは**抑制しない**（マウントに依存しない故障なので）

**`ESKF CALIBRATION REQUIRED!` だけは例外で、音も鳴らす。**
姿勢表示・バンク角警告・自動ロールトリムがまとめて信用できなくなる状態で、
地上で気づかないまま飛ぶと取り返しがつかないため。
ただし **鳴るのは地上で静止しているときだけ**で、飛行中は鳴らさない
（飛行中に較正はできず、対処できない警告で注意をそらすほうが危険）。
画面表示のほうは 3 秒のうち 1 秒だけ点滅させ、万一飛行中にこの状態になっても
地図を隠し続けないようにしてある。あわせて **ヘッダーの `Pavg` に赤い横バーを重ねて**、
その数字が信用できないことを示す（GNSS 0 個で速度・方位が無効になるときと同じ見た目）。

### 較正した日から日付をまたいだとき（0.970〜）

こちらは上とは**わざと強さを変えてある**。マウントから外したことを検出したのではなく、
「**電源を切っている間に外して付け直したかもしれない**」という推測でしかないためで、
付けっぱなしで日をまたぐことも普通にある。

| | `ESKF CALIBRATION REQUIRED!` | 日付をまたいだ |
|---|---|---|
| 根拠 | ロール/ピッチ 30 度超を**観測した** | 日付が違うだけ（**推測**） |
| 音 | 地上で 120 秒ごとに繰り返す | 地上で**起動ごとに 1 回だけ** |
| 地図表示 | 赤字で点滅 | **出さない** |
| 設定画面 | 赤字 `!! REMOVED FROM MOUNT` | オレンジ `! CALIB IS FROM MM/DD` |
| ヘッダーの `Pavg` | 赤い取り消し線 | **引かない**（値は読める） |
| PONS Link | ボートへ fault として飛ぶ | **飛ばさない** |

★ **音を繰り返さないのは意図的。**2 分おきに鳴らすと、プラットホームの上で鳴ったときに
「止めるために APPLY する」人が出る。APPLY は静止していれば通ってしまうので、
**正しかった較正が台の姿勢で上書きされる**。一度伝えたら、あとは人の判断に任せる。

---

初版 2026/09/14 / 更新 2026/09/21（0.971）

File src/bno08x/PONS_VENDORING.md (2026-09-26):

# Adafruit_BNO08x をリポジトリに取り込んだ理由と、ローカル改変の一覧

## 取り込み元

| | |
|---|---|
| ライブラリ | **Adafruit BNO08x v1.2.7**（Arduino ライブラリマネージャ版） |
| 同梱 | CEVA/Hillcrest の SH-2 ドライバ（`sh2*.c/h` `shtp.c/h`）。Adafruit がそのまま同梱している |
| 取り込み日 | 2026-09-22（PONS 0.972） |
| 置き場所 | `src/bno08x/`（Arduino は `src/` 以下を再帰的にコンパイルする） |

`Adafruit_BusIO` は**取り込んでいない**。一般的なライブラリで、ここで問題を踏んだことが 1 度も無いため。
インストール済みのものがそのまま使われる。

## なぜ取り込んだか

このライブラリの内部に対して、**ソース側で直さないと解決しない問題を複数踏んでいる**。
ライブラリフォルダを直接編集しても git に残らず、他の機体・他の PC で再現できない。
3 台運用で「この 1 台だけ挙動が違う」は最悪の壊れ方なので、リポジトリに入れて固定した。

**`#include <Adafruit_BNO08x.h>` と書いてはいけない。**山括弧だと Arduino が
インストール済みの方を拾い、ここの改変が効かないまま静かにビルドが通る。
`imu.cpp` のように `#include "src/bno08x/Adafruit_BNO08x.h"` と相対で書くこと。
**ビルドが正しいかは `<build-path>/sketch/src/bno08x/*.o` があることで確かめられる**
（インストール版が使われていると `<build-path>/libraries/Adafruit_BNO08x/` 側に出る）。

## ローカル改変の一覧

**改変したら必ずここに追記すること。**上流へ戻す/更新するときの唯一の手掛かりになる。

### (1) `Adafruit_BNO08x.cpp` — `spihal_wait_for_int()` の待ちの粒度

`delay(1)` 刻みをやめ、最初の 3ms はスピン、その先は 200µs 刻みにした。総予算 500ms は据え置き。

元の実装は 1ms 刻みで待つ。`spihal_read()` が 1 パケットにつき **2 回**、
`spihal_write()` でも 1 回通るので、**145 パケット/秒では最大 290ms/秒 Core0 が止まる**。
I2C 経路（`i2chal_read`）は INT を待たず `delay` も無いため、この負荷は
**SPI へ移ってから初めて現れた**（0.944 の I2C 構成では起きていなかった。
レート・ポーリング周期・クロックはすべて同一で、違いはバスだけ）。

実害は次のとおり。

- GRV が要求 15Hz に対し **11Hz** まで痩せる。GRV はバリオの**重力方向の基準**そのもの
  （`VARIO_USE_RAW_ACCEL=1` の経路で生比力を地球座標へ回すのに使う）。
  遅れると重力の引き算が斜めになり、傾けたときに**偽の鉛直加速度**が入って V/S が暴れる
- Core0 が遅くなるので、同じく Core0 が回している **MS5611 のレートも道連れ**で落ちる（44→36Hz）

転送そのものは 1MHz × 約 30 バイト = 0.25ms で、待ちが 8 倍重い。
**SPI クロックを上げても効かない。速度ではなく待ち方の問題。**

### (2) `Adafruit_BNO08x.cpp` — `spihal_read()` の計測カウンタ

`pons_pkt_max` / `pons_pkt_toobig` / `pons_hdr_change` を追加した。
60 秒ログの `spi pktmax=… toobig=… hdrchg=…` に出る。**消さないこと。**

- `pktmax` … 観測した最大パケット長。**384 → 768 に広げた根拠がこれ**（実測 276）
- `toobig` … `packet_size > len` で**読み出さずに戻った**回数。**1 でも出たら異常**
- `hdrchg` … ヘッダ読みと本体読みで長さが食い違った回数。SPI は ① ヘッダ 4 バイト
  ② INT 待ち ③ 本体、と別トランザクションなので、その隙に中身が変わりうる

### (3) `sh2_hal.h` — 受信バッファを 384 → 768 へ

`SH2_HAL_MAX_TRANSFER_IN` と `SH2_HAL_MAX_PAYLOAD_IN`。

**上流の既定 384 では余裕が 39% しか無い**（実測 pktmax=276）。
Core0 が長く止まるとレポートが溜まってパケットが大きくなる。
そして超えたとき、両 HAL とも

```c
if (packet_size > len) return 0;   // ★ パケットを排出しない
```

で戻るため、**パケットがデバイス側に残り、次も同じ判定になる**。
排出する実装に直すのが本筋だが、SPI は 1 トランザクションで読み切る必要があり
（部分読みしても次の CS アサートで先頭に戻る）、捨てるための一時バッファが
結局同じ大きさ要る。**広げるほうが素直**と判断した。
RAM は shtp.c の `inPayload[]` と `inTransfer[]` が各 +384 バイト増えるだけ。

> ### ★ (1) と (2) は 0.976 で撤去した（SPI をやめたため）
> PONS は BNO085 を **i2c1 固定**で運用することに決めた（触るとジャイロが化ける
> 問題が SPI でしか起きなかった）。SPI HAL の改変はすべて死んだコードになったので、
> **上流のままに戻した**。上流を更新するときに当て直す必要はない。
> 中身が必要になったら `git show 0.975 の commit -- src/bno08x/Adafruit_BNO08x.cpp`。
>
> - **(1) `spihal_wait_for_int()` の待ちの粒度** … `delay(1)` 刻みだと
>   145 パケット/秒で最大 290ms/秒 Core0 が止まり、GRV が 15Hz→11Hz へ痩せた。
>   最初の 3ms をスピン、その先を 200µs 刻みにして解消していた。**SPI 限定の問題。**
> - **(2) `pons_pkt_max` / `toobig` / `hdr_change` カウンタ** …
>   `spihal_read()` の中だけで更新されるため **i2c1 では常に 0** で、
>   「0 だから健全」と誤読される表示になっていた。`.ino` の 60 秒ログからも外した
>   （`imu gapmax=` だけ残した）。

### (4) `Adafruit_BNO08x.cpp` / `.h` — `_init()` の失敗箇所を外へ出す

上流の `_init()` は `sh2_open()` でも `sh2_getProdIds()` でも `false` を返すだけで、
どちらで落ちたのか分からない。実機の `[IMU] BNO085 recovery FAILED` から
原因を絞れなかったので、グローバル 2 つに記録するようにした。

```c
uint8_t pons_init_fail_step;    // 0=成功 1=spi/i2c begin 2=sh2_open 3=sh2_getProdIds
int32_t pons_init_fail_status;  // SH2 のステータスコード（sh2_err.h）
```

`imu.cpp` が復旧失敗ログに載せる。**これが次の (5) の発見に直結した。**

### (5) 改変なし — `sh2_close()` を呼ぶのは PONS 側（重要）

**上流のライブラリは、2 回目以降の `begin_SPI()` / `begin_I2C()` が必ず失敗する。**

`shtp.c` の SHTP インスタンスプールは

```c
#define MAX_INSTANCES (1)
static shtp_t instances[MAX_INSTANCES];
static shtp_t *getInstance(void) {
    for (int n = 0; n < MAX_INSTANCES; n++)
        if (instances[n].pHal == 0) return &instances[n];   // 空きの判定は pHal==0
    return 0;
}
```

で、`pHal` を 0 に戻すのは `shtp_close()`（＝`sh2_close()`）だけ。ところが
`Adafruit_BNO08x::_init()` は `sh2_open()` を呼ぶだけで close しない。
したがって 2 回目は `getInstance()` が 0 → `shtp_open()` が 0 →
`sh2_open()` が `SH2_ERR` → `_init()` が false。

**実機 2026-09-23 で `[IMU] BNO085 recovery FAILED` が毎回出ていたのはこれ。**
リセット後に INT は返っていた（＝チップは生きていた）のに、再初期化だけが
構造的に失敗していた。**つまり通信途絶からの復旧は一度も成功したことがなかった。**

ライブラリ側は直していない。**`imu.cpp` の `imu_bus_begin()` が再オープンの前に
`sh2_close()` を呼ぶ**ことで回避している。上流を更新してもこの回避は残すこと。
`spihal_close()` / `i2chal_close()` は実質何もしないので、相手が無応答でも安全。

## 手を付けていない既知の問題

**`packet_size > len` でパケットを排出しない**（上流のまま。上記 (3) 参照）。
768 に広げて当たりにくくしたが、当たったときに抜けられない構造は残っている。
`toobig` が 1 でも出たら、そこを直す必要がある。

**`sh2.c` の全オペレーションが `timeout_us` を宣言していない**（= 0 = 無限待ち）。
`sh2_getFrs` / `sh2_setFrs` / `sh2_getMetadata` などが応答しないと戻ってこない。
現状は呼ぶ側で回避している（メタデータ読み出しは `#ifndef RELEASE` に隔離、
FRS は使わない）。取り込んだので直せる状態にはあるが、**必要になるまでは触らない**。

## 上流を更新するときの手順

1. 新しい版の `src/*` を `src/bno08x/` へ上書き
2. 上の「ローカル改変の一覧」を 1 件ずつ当て直す
3. `<build-path>/sketch/src/bno08x/*.o` が出ていることを確認
4. 実機で `rate GRV=15.0 LACC=15.0 RV=5.0` が出ることを確認
5. 通信途絶からの復旧が効いているかを確認する（上の (5) の回避が効いている証拠）。
   `imu_update()` で一時的に `bno085_ok = false` にすれば復旧経路に入るので、
   `[IMU] BNO085 recovery OK` が出ることを見る。**ここが
   `FAILED ... init_step=2` なら `sh2_close()` の呼び出しが外れている。**

## ライセンス

- `Adafruit_BNO08x.{h,cpp}` … **BSD 3-Clause**（`license.txt`。Copyright (c) 2019 Bryan Siepert for Adafruit Industries）
- `sh2*.{c,h}` `shtp.{c,h}` … **Apache License 2.0**（Hillcrest Laboratories, Inc.。`NOTICE.txt` と各ファイル冒頭）

どちらも原文を同梱してある。**帰属表示を消さないこと。**

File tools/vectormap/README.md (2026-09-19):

# 内蔵ベクタ地図の生成

`vectormap_data.cpp`（ファームウェアに焼き込む地図データ）を OpenStreetMap から生成する。

以前の `tools/mapimage/`（Google Maps API で BMP タイルを作り SD カードに置く方式）を
置き換えたもので、**API キー不要・SD カード不要**になっている。

## できあがるもの

| | |
|---|---|
| 出力 | `../../src/flashdata/vectormap_data.cpp`（軽量版・約 1.3 MB）または `vectormap_data_hires.cpp`（16MB 版） |
| 収録範囲 | 飛行エリア 7 箇所を高精細＋本州広域＋日本全国 |
| 地物 | 海岸線・水面・高速道路・幹線道路・鉄道 |
| ライセンス | ODbL（`../../LICENSE.ODbL` を参照） |

## 準備

```sh
pip install shapely osmium fiona pyproj requests
```

入力データを 2 つ落とす（合計 3GB 強）。

```sh
# 1. OSM の日本抽出（道路・鉄道・水面）。日付を固定すること（latest だと結果が変わる）
curl -O https://download.geofabrik.de/asia/japan-260816.osm.pbf

# 2. 海岸線。高ズーム用（1.3GB）と低ズーム用（23MB）で精度が違うので両方要る
curl -O https://osmdata.openstreetmap.de/download/land-polygons-split-4326.zip
curl -O https://osmdata.openstreetmap.de/download/simplified-land-polygons-complete-3857.zip
unzip land-polygons-split-4326.zip
unzip simplified-land-polygons-complete-3857.zip
```

### ★ 一度作れば、巨大な入力データは消してよい

入力の切り出し結果はすべてキャッシュされる。**キャッシュが残っていれば、
LOD の閾値や収録範囲を変えて作り直すのに元データは要らない。**

| キャッシュ | 中身 | 元データ |
|---|---|---|
| `pbf_scan.pickle`（137MB） | 水面・高速・幹線・鉄道の全国分 | `japan-*.osm.pbf`（2.5GB）|
| `cache/land_*.pickle` | 海岸線を bbox で切り出したもの | land polygons shp（1.3GB / 23MB）|
| `cache/c*_*.json` | Overpass の応答（`--pbf` を使うなら不要）| — |

`--pbf` を省いても `pbf_scan.pickle` があればそちらを使う。
海岸線も同様に、キャッシュがあれば `--land-shp*` の指定は要らない。

```sh
# 元データを消したあとの作り直し（キャッシュだけで完結する）
python3 build_vectormap.py --source-date 2026-08-16
```

**キャッシュに無い範囲を新しく足すとき**（`SITES` に飛行エリアを追加した、
LOD の bbox を広げた、など）だけ、元データを取り直すこと。

## 生成

地図は **2 種類**あり、ファームウェア側は `settings.h` の `VECTORMAP_HIRES` で
コンパイル時にどちらか一方だけを焼く。両方のデータファイルが自分で自分を
`#ifdef` で無効化するので、Arduino が src/ 配下を全部コンパイルしても重複定義にならない。

### 軽量版（既定・FLASH 2MB 設定で入る）

書き込みが速いので、無線などのデバッグ中はこちら。

```sh
python3 build_vectormap.py \
  --pbf japan-260816.osm.pbf \
  --land-shp simplified-land-polygons-complete-3857/simplified_land_polygons.shp \
  --land-shp-hires land-polygons-split-4326/land_polygons.shp \
  --source-date 2026-08-16
# → ../../src/flashdata/vectormap_data.cpp （LOD 0,1,2,3）
```

### 16MB 版

**ボード設定を「16MB (no FS)」にしないとリンクで溢れる。** 書き込み時間も素直に伸びる。

```sh
python3 build_vectormap.py --variant hires \
  --pbf japan-260816.osm.pbf \
  --land-shp simplified-land-polygons-complete-3857/simplified_land_polygons.shp \
  --land-shp-hires land-polygons-split-4326/land_polygons.shp \
  --source-date 2026-08-16
# → ../../src/flashdata/vectormap_data_hires.cpp （LOD 0,1,2,3,4）
```

生成したら `settings.h` の `//#define VECTORMAP_HIRES` のコメントを外す。
未生成のまま有効にすると `#error` で止まる（リンクエラーで悩まないようにしてある）。

軽量版との違いは 2 つだけ。

1. **最大ズーム専用の LOD を 1 段足す**（4 → 5 段）。軽量版の LOD0 は zoom13 で
   1px の誤差になるよう作ってあるが、`scalelist` の最大は scale=200（画面幅 1.2km）で、
   そこでは同じ誤差が 3.8px になる。**段の中でここだけ精度が足りていない。**
2. **LOD1/LOD2 の周辺マージンを広げる**、LOD3 に幹線道路を戻す。

`src/vectormap.h` の `VM_LOD_COUNT` も `VECTORMAP_HIRES` で 4/5 が切り替わる。
**データ側の配列長と必ず一致させること。**

pbf の走査に 10〜15 分かかるが、結果は `pbf_scan.pickle` にキャッシュされるので、
しきい値や収録範囲だけ変えて作り直すときは数分で終わる。

`--pbf` を省くと Overpass API から取得する（追加インストールが少なくて済むが、
広い範囲では時間がかかり公開サーバへの負荷も大きい。小範囲の試作向け）。

## 飛行エリアを追加する

`build_vectormap.py` の `SITES` に 1 行足すだけ。

```python
SITES = {
    "biwako": (34.95, 135.80, 35.60, 136.40),   # (lat_min, lon_min, lat_max, lon_max)
    ...
}
```

高ズーム（LOD0/1）はここに挙げた範囲だけを収録する。全国を高精細で持つと
フラッシュに入らないため、実際に飛ぶ場所を列挙する方式にしている。

追加したら `gnss.cpp` の `DEMO_SITES` にも足すと、実機のデモ飛行で表示を確認できる。

## 容量を減らしたいとき

効く順に:

1. **LOD1 の周辺マージンを詰める** — 全体の半分以上を占める。`bboxes` の `± 0.35 / 0.45` を小さくする
2. **`VM_TRUNK` を外す** — `trunk` に加え `primary` も含むため点数が最多
3. **LOD2 の収録範囲を狭める**

生成時にクラス別・LOD 別の内訳が表示されるので、それを見て判断する。
同じ内訳は実機の MAPLIST 画面（設定 → Map detail）でも確認できる。

## パラメータの考え方

`tol_scale` と `cull_scale` を混同しないこと。1 つの LOD が複数のズーム段を
兼ねるとき、この 2 つは逆方向の要求を持つ。

- **`tol_scale`（簡略化の許容誤差）** … その LOD が担当する**最も細かいズーム**に合わせる。
  粗い側に合わせると、細かい側で海岸線がガタガタに見える。
- **`cull_scale`（面積・長さの足切り）** … 担当する**最も粗いズーム**に合わせる。
  細かい側に合わせると、広域表示では見えない小島まで大量に抱え込む。

## ライセンス

生成される `vectormap_data.cpp` は ODbL の Derivative Database に該当する。
再配布時は ODbL のままとし、帰属表示を保持すること。
詳細は `../../LICENSE.ODbL` を参照。

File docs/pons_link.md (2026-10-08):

# PONS Link — 機体⇄ボート テレメトリ・ダウンリンク

同一ファームウェアの PONS を 3 台つくり、設定で役割を決める。

| 役割 | 台数 | 置き場所 |
|---|---|---|
| 送信機 (TX) | 1 | 機体 |
| 受信機 (RX) | 2 | 追走ボート／プラットフォーム |

目的は、**パイロットに出ている航法画面をボート側でそのまま再現すること**。
通信は**下り一方向のみ**で、受信側から機体へ返すものは何も無い。

---

## 1. 役割とモード

設定ファイルの `link_mode` で決める（`OFF` / `TX` / `RX`）。3 択のトグルなので
**「送受同時 ON」を表現できない**。取り違えは起動時の音声で気づく。

- `TX` — 従来どおり自機を表示しつつ、1Hz でテレメトリを送信する
- `RX` — 受信したテレメトリで画面をミラー表示する。送信はしない
- `OFF` — 無線を使わない

### グループ ID

同じ会場に**別チームの PONS** がいたときに取り違えないための識別子。

CH と SF が偶然一致すると、magic も ver も CRC も通ってしまう。つまり今までは
**「CH/SF の一致」が事実上のペアリング**だった。同じ機体を他チームに頒布している以上、
これだけでは足りない（受信側が他機の飛行をミラーし、`received/` にも他機のログが残る）。

- **既定は 0。ソースにも SD の雛形にも 0 しか書かない。** 実際の値は各機の
  `settings.txt`（`link_group`）にだけ置く。**git に載るのは仕組みだけで値ではない。**
- 他チームが既定 0 のままなら、こちらが 0 以外にするだけで分離できる
- 電波の設定ではなく**ペイロードの中身**なので、変更してもモジュールへの書き込みは要らない
- 範囲は 0〜255。ただし**設定画面の長押しは +1 ずつ**なので、実運用では
  小さい値（1〜20 程度）にすること。SD が飛んで 0 に戻ったとき現地で押し戻せる

**★ グループ違いは「無信号」と区別して表示する。**
`Signal : GROUP 3 FOUND` のように、**電波は届いていてグループだけ食い違っている**ことを出す。

同じ CH/SF/Group に**送信機が 2 台**いると判定したときは、地図に
`DUP SENDER !! / 2 TX ON SAME CH/GROUP` の赤いポップアップを出す。
この状態ではミラー表示が 2 機ぶんのテレメトリを交互に映すので、
**画面の値そのものが信用できない**。地図を覆ってでも知らせる。
判定は最後に検出してから 30 秒で消えるので、2 台目を止めれば
**再起動せずに直ったことを確認できる**。音声は聞き逃しに備えて 1 分ごとに繰り返す。
ここを黙って無反応にすると、SD が 0 に戻った事故が距離不足や故障と区別できなくなる。

> セキュリティではなく**衝突回避**。仕組みは公開されているので、
> 値を知られたくないという以上の保護にはならない。

**★ 受信機側の「全 Ch/SF 自動スキャン」は採らなかった。**
「無信号のとき、実は Ch や SF の設定違いだった」を機械的に見つける案を検討したが、
やめた理由は 3 つ。

1. **単に遠いだけの場合に、聴取をやめてしまう。** 13ch × 5SF = 65 通りを 1 通り 2 秒
   でも 130 秒かかる。その間ずっと本来の設定を聴いていない。復帰を一番知りたい
   タイミングで、一番聴いていないことになる
2. **第三者の信号を掴む。** 920MHz 帯は Wi-SUN スマートメーター等と共用なので、
   「何か受かった」だけでは判断材料にならない。掴んだものが PONS かどうかは
   結局 magic + ver + group で見るしかない
3. **設定違いは飛ぶ前に潰すべきもの**で、飛行中に自動で直す種類の問題ではない

代わりに、**設定を変えた時点で人に確認させる**（次項）ことと、
**グループ違いを無信号と区別して表示する**ことの 2 つで対処する。
どちらも聴取を止めないし、飛行中に勝手に設定が変わることもない。

### 設定を変えたら伝える

`Ch` / `SF` / `Group` は **3 台すべてで一致していないと通信できない**。
1 台だけ変えて伝え忘れると、症状は「無信号」になり、現場では距離や故障と区別が付かない。

- 設定画面に常設で `^ 3 units must match` を出す（変更後に警告するより、変更する前に見せる）
- 無線画面を出るときに 3 つのどれかが変わっていたら、**音声で知らせて SD ログに残す**
  （`wav/link_setting_changed.wav`「送信機と受信機の設定が一致していることを確認してください」。
  ファイルが無ければ 500Hz×2 が鳴るので無音にはならない）
- **送信機・受信機のどちらでも鳴らす。** 受信機側を触って戻し忘れる事故も同じだけ起こるし、
  受信機は 2 台あるぶん取り違えやすい

### 3 台の役割

| 置き場所 | モード | 役割 |
|---|---|---|
| 機体 | TX | パイロットの航法装置。これが本番 |
| 追走ボート | RX | 機体の画面を再現する。ボートマンが見る |
| プラットフォーム | RX → 途中で OFF | **予備機**。機体の PONS が壊れた／電池切れのとき TX へ切り替えて載せ替える |

プラットフォーム機は機体が離れると当然ロストする。**これは想定どおり**で、
ロストを画面と音声の両方で知らせたあと、**人が OFF にする**運用にする。
「ロストしたら自動で静かにする」ようにはしない ― 予備機である以上、
電波が来ているかどうかは常にはっきり分かるほうがよい。

**起動時とモード切替時に、3 状態すべてを音声で読み上げる**
（`sender_mode.wav` / `receiver_mode.wav` / `link_off.wav`）。読み上げない状態があると
「何も言わない＝正常」と受け取られ、無線が OFF になっていることに気づけない。

0.984 までは TX / RX だけ読み上げて**無音を「OFF」の意味**にしていたが、
**無音は「音量を絞っている」「音声が焼けていない」とも区別が付かない**。
モードは回転式で**目的のモードを通り過ぎて OFF まで回してしまう**ことがあり、
その症状は相手側の「無信号」だけなので自機では分からない。
0.985 で `link_off.wav` を足した。**OFF を無音に戻さないこと。**

### 送信機の重複検出

送信機が 2 台同時にいるのは異常事態（機体用とボート用の取り違え等）。
**`seq` の逆行**で検出する。送信機が 1 台なら `seq` は必ず増えるので、
減る・止まるのは 2 台いる証拠になる。10 秒以内に 3 回たまったら警告する
（送信機の再起動でも 1 回だけ起きるため、間隔が空いたら数え直す）。

> 送信元 ID を載せて比較する案は却下した。既定値が 3 台とも同じになるため、
> 「設定を触っていない 2 台がどちらも TX」という**一番ありそうな誤設定で
> 黙って失敗する**。運用に依存しない `seq` のほうが確実。

**検出できるのは受信機だけ。** 送信機は送信の合間スリープしていて受信できない。

---

## 2. 無線とハードウェア

モジュールは **E220-900T22S(JP)**（920MHz LoRa、技適取得済・免許不要）。
RP2350 から UART で直結する。

| 信号 | RP2350 | 備考 |
|---|---|---|
| UART1 TX → E220 RXD | GPIO8 | |
| UART1 RX ← E220 TXD | GPIO9 | |
| E220 AUX → RP | GPIO30 | 状態通知。100nF を GND へ |
| E220 M0 + M1（結線） | v7: GPIO41 / v7.1: **GPIO47** | `settings.h` の `PONS_BOARD` で切り替わる。v7.1 のネット名は `LORA_M01`。どちらも U12.5/U12.6 を 1 本で駆動 |
| E220 VDD | +3V3 直結 | **VCC は開放**（排他利用）。10µF + 100nF |
| E220 ANT | — | IPEX コネクタを使用 |

- **M0 と M1 は結線して GPIO 1 本で駆動する。** 使うのは mode 0（通常送受信）と
  mode 3（Config/DeepSleep）の 2 つだけなので、データシート 5.3 が明示的に許している。
  WOR は使わない。
- **M0/M1 はモジュール内部で 80kΩ プルアップ**されている。外部プルアップ不要で、
  フローティングでも mode 3 に落ちるため電源投入時に勝手に送信することはない。
- **ピーク電流は 43mA ではなく約 150mA。** 43mA は送信時の平均で、モジュール内部の
  ピーク給電はこれに達する。3.3V レギュレータの余裕とバルクコンデンサを確保すること。

### 無線パラメータ

| 項目 | 値 |
|---|---|
| 帯域幅 | 500 kHz |
| 拡散率 | **SF8（既定）**。設定で SF7〜SF11 |
| チャンネル | **CH0〜12（920.8〜923.2MHz）に限る** |
| 送信出力 | 13dBm（20mW） |
| 送信方法 | **通常(Fixed-block)送信。宛先は `FF FF <ch>`＝ブロードキャスト（→ §6）** |

`link_radio_prof` は `0=SF7 / 1=SF8 / 2=SF9 / 3=SF10 / 4=SF11`。
SF を 1 段上げると 2.5dB 強くなるが、**送信時間＝送信電流が倍々に増える**。

**CH13 以上を使ってはいけない。** CH0〜12 は 1 回の送信ごとの休止が 50ms 固定で、
400ms 制限も「休止＝送信時間の 10 倍」も 1 時間 360 秒の総量制限もかからない。
CH13〜30 はこれらが全部かかり、サブパケット長も 32B に強制される。

---

## 3. タイミングと省電力

本体は低輝度で約 72mA、電池は 860mAh。

- **送信は 1Hz。連射しない。** 1 回落ちても実用上困らず、連射は送信電流と
  電波占有時間を素直に倍にするだけ。

### 送信時間と消費電流（ペイロード 65B・BW500kHz）

**SF8 の 98.4ms はメーカー公開の「E220-900T22X(JP) LoRaデータ送信時間計算表」の値**。
他の SF はそこからの概算で、**同じ表から取り直すこと**（下の注意を読むこと）。
消費電流はデータシートの 送信 43mA @13dBm / 受信待機 8.2mA / mode 3 2.5µA から。

| SF | 送信時間 | 1Hz 運用の平均電流 | 電波占有率 |
|---|---|---|---|
| SF7  | 約 55 ms  | 約 2.4 mA  | 5.5% |
| **SF8（既定）** | **98.4 ms（実値）** | **4.3 mA** | 9.8% |
| SF9  | 約 180 ms | 約 7.8 mA  | 18% |
| SF10 | 約 340 ms | 約 14.7 mA | 34% |
| SF11 | 約 600 ms | 約 25.8 mA | 60% |

> ### ★★ 実測（2026-09-27）: **AUX Low の実時間は表の約 1.5 倍**
> `link_tx_tick()` が AUX の立ち下がり〜立ち上がりを測るようにしたので、
> 「モジュールが実際に塞がっている時間」が取れる（60 秒ログの `airmax=`）。
>
> | | 表の送信時間 | **実測 AUX Low** |
> |---|---|---|
> | SF9（prof=2） | 180 ms | **250〜276 ms** |
>
> 差は **ARIB のキャリアセンスとモード遷移**ぶん。同じ比率なら SF11 は
> 表 600ms に対して **900ms 前後**になる見込みで、**1 秒周期に対して余裕が
> ほとんど無い**（占有率も 60% ではなく 90% 近く）。SF11 を常用するなら
> 送信周期の見直しが要る。`LINK_TX_DONE_MS` はこの実測から 1000ms にしてある。
>
> ★ **この時間ぶん、mode 3 への切替を待つこと。** 0.976 までは書き込みから
> 約 17ms で `MODE_CONFIG` を立てていた。送信完了の **230ms も前**である。
> 「送信中の切替はハードが先送りする（5.3）」という前提で待っていなかったが、
> 実機では**受信側が 93% 落とした**（送信側 `noRf=0`・受信側 `bad=0`・
> RSSI −46〜−64dBm、つまり届けば確実に受かる距離）。**待つこと。**
>
> **完了まで待つようにした結果（同日・10 分連続）**:
> `rx` が毎分 +59〜60（送信 60 発）、`gaps=0`、`bad` は増えず、
> `bytes` は毎分 +3960（= 66B × 60 発）。**取りこぼしゼロ。**
> 打ち切られた送信は受信側で「`PL` は見つかるが CRC が合わない」＝ `bad` として
> 現れる。**`bad` が増えているのに `rx` が少ないときは、まずここを疑う。**

> ★ **この電波占有率は Core0 の占有率ではない。**
> `e220_sleep()` は送信完了を待たない。mode 3 への切替は AUX が High のときしか
> 効かないので、送信中に M0/M1 を上げておけば**ハードウェア側が勝手に先送りし、
> 送信を終えてから mode 3 に入る**（データシート 5.3）。
> したがって **SF を上げても Core0 が止まる時間は増えない。**
>
> Core0 を止めていたのは送信時間ではなく、**起床と後始末の待ち**だった:
> `e220_wake()` の `wait_aux_idle(50)` ＋ `e220_send()` の `wait_aux_idle(10)` ＋
> `e220_sleep()` の `flush()`（68B @115200 で約 5.9ms）で、最悪 60ms 前後。
> **SF には依存しない。** これを 2026-09-23 に `link_tx_tick()` の
> 状態機械（IDLE → WAKING → DRAINING）へ分解して、待ちを無くした。
>
> 代償はモジュールが mode 0 に居る時間が 2 周回ぶん（約 130ms）伸びること。
> 受信待機 8.2mA なので平均 +1mA 程度で、TFT と RP2350 の消費に対しては誤差。

> ★ SF8 以外は「SF が 1 段上がるごとに送信時間が約 1.8 倍」という LoRa の性質から
> 外挿しただけの概算。一般の LoRa 計算式（CR4/5・プリアンブル 8 を仮定）だと
> SF8 で 53.9ms となり、**メーカー表の 98.4ms と 1.8 倍ずれる**。
> どの仮定が違うのか 1 点からは特定できなかったので、
> **他の SF もメーカー表の値に置き換えること。**

- **送信機の瞬間電流は 43mA**（モジュール内部のピーク給電は約 150mA）。
  平均は SF8 で **4.3mA**。本体 72mA に対して 6% で、電池持ちへの影響は小さい。
- **受信機は瞬間・平均とも 8.2mA**（常時 mode 0）。受信中も待機中も同じ。
  本体 72mA に対して 11%、電池持ちで約 1 時間ぶん短くなる。
  → **受信機のスリープは今後実装予定**（§9）。実装すれば 8.2mA より確実に下がる。
- SF を 1 段上げると **感度は 2.5dB、送信時間と電流は約 1.8 倍**。
  SF8→SF10 は +5dB と引き換えに 4.3mA→約 14.7mA になり、
  **電波占有率も 10%→34% へ上がる**。1Hz を保てる上限は SF11 あたり
  （約 600ms + 休止 50ms で 1 秒スロットの 2/3 を使う）。
- 1 回の送信ごとに 50ms の休止が入る（CH0-12 の規定）。

### 上りの通信を持たない理由

ACK や KEEPALIVE を持つと、受信機 2 台ぶんの衝突回避、送信機側の受信待機、
状態機械の分岐がすべて必要になる。得られるのは「受信機がいない間の送信電力の
節約」だけで、送信は SF8 で平均 4.3mA しかない。**払うコストに見合わない。**

安全上も、上りが無ければ**受信機側の不具合が飛行中の機体へ波及する経路が
原理的に存在しない**。大会レギュレーション上も説明しやすい。

---

## 4. UART と電波に載せるもの

| | |
|---|---|
| 通常運用 (mode 0) | **115200 8N1** |
| 設定時 (mode 3) | **9600 8N1 固定**（レジスタ設定に関わらず） |

**9600 では `write()` が Core0 を 37.5ms 止める**（68 バイト、ハード FIFO 32B、
arduino-pico に送信バッファは無い）。115200 なら 3.1ms。マップ描画 64ms と
合わせて許容できないため 115200 を使う。

**★ 1 回の `write()` にまとめて渡すこと。分割して書かない。**
E220 は「一定時間データが来ない」ことをパケットの区切りとみなす
（115200bps で >2ms、9600bps で >5ms）。途中で途切れると
**1 回のテレメトリが 2 回の電波発射に分裂**し、占有時間も電力も倍になる。
`write()` はブロックするので、まとめて渡す限り隙間はできない。

### ペイロード

`LinkTelem`（**65 バイト固定**、`lora_link/link_proto.h`）。
`static_assert(sizeof(LinkTelem) == 65)` でビルド時に止めてある。
65 バイトという数値は送信時間・送信電流・電波法の検討がすべて前提にしているので、
項目を足して黙って伸びると検討が全部ずれる。

| 位置 | 内容 |
|---|---|
| ヘッダ 8B | `magic0='P'` / `magic1='L'` / `ver` / `type` / `seq`(u16) / **`group`** / `rsv[3]`（必ず 0） |
| 時刻 9B | 年月日時分秒 + 1/100 秒（GNSS） |
| 位置・対地 12B | 緯度・経度 ×1e-7 度、対地速度 0.01m/s、真方位 0.01 度 |
| 高度・気圧 8B | GNSS 高度 / KF 高度（0.1m）、KF 昇降速度（0.01m/s）、気圧（0.1hPa） |
| 姿勢 11B | ロール・ピッチ・ヨー・平均ピッチ・ロールトリム（0.01 度）、ヨー精度95%（度） |
| 風 3B | 風速（0.1m/s）、風向（0.01 度、吹いていく方向） |
| 機体状態 6B | 電圧、捕捉数、水平精度（0.1m）、fix フラグ |
| ナビ設定 2B | `dest_index` / `nav_mode`（受信側が突き合わせて自動追従する） |
| 検査 6B | `have`（RHAVE_*）/ `status`（LINK_ST_*）/ `crc16` |

**版数は `LINK_PROTO_VER`。構造体レイアウトを変えたら必ず上げる。**
現在は **v3**（使われていなかった `tx_us`＝送信側 micros を `group` + 予備 3 バイトへ
置き換えた。受信側は自分の `millis()` で経過を測っており、`tx_us` を読む場所は 1 つも無かった）。
版が違うフレームは捨てるので、古いファームの機体を新しい受信機がミラーすることは無い。

異物の排除は **magic + ver + type + CRC16** の 4 つ。
**グループ ID はこの検査には含めない**（→ §1）。
検査で弾くと「電波は来ているがグループが違う」を無信号と区別できなくなるため、
`link_telem_valid()` は通し、表示に使うかどうかを **link.cpp が別に判断する。**

数値の丸めとクリップは `link_pack_*()` に 1 か所へ集めてある。
**NaN は 0 に落とす**（姿勢推定が発散したときに極値を送るより無害）。

受信側は受け取った内容を `received/` の CSV へ 1Hz で残す。
**姿勢・風の列名は `imu_replaydata/` と同じ**にしてあるので、
機体の SD が死んでも（`status` の `LINK_ST_SD_ERROR` がまさにその状態）
ボート側のログで ESKF の解析ができる。

`received/` は「無線で得た情報だけ」を置く場所だが、**末尾の
`own_lat / own_lon / dist_m` だけが例外**で、受信した瞬間の**ボート自身**の位置と
機体までの距離が入る。RSSI と距離が同じ行に揃っていないと飛行後に
「距離 vs RSSI」が引けず、別ファイルに分けると `seq` で突き合わせる手間が増えるため。
要求 200m の裏取り、SF を上げるべきかの判断、アンテナ位置の A/B 比較が
この 1 ファイルで完結する。ボートが測位できていなければ空欄になる。

**ペイロードを増やすと受信窓と送信電流の両方に直接効く。安易に足さないこと。**

`status` に載せるのは**「受信側からは知りようがない、送信機自身の健康状態」だけ**
（SD エラー・IMU エラー・トリム未適用・電池低下）。
飛行の警告（コース警告・バンク角警告・バリオ音）は**受信側がミラー値から自分で
再計算する**。計算が 1 本のままなので、送信側と受信側で挙動がずれる余地が無い。

---

## 5. 受信モードの画面と安全

- **どの画面にいても色付きの枠を出す。** 受信モードであることが常に分かるように。
  ★ ナビ部分（backscreen）の枠は**右辺だけ描かない**。`x = VSI_X` 以降は VSI が
  占める領域で、VSI は backscreen の push より**後**に TFT へ直接 push されるため、
  右辺だけが「出てすぐ消える」点滅になる（0.978 で修正）。
  ★ ヘッダー左上にあった `RX` バッジは 0.978 で削除した。塗り矩形が対地速度 m/s の
  桁の真上に乗って**読めなくしていた**。受信モードは枠の色で分かる。
- 地図の左上に**電波アイコンと役割アイコン**（船／飛行機）。受信モードは役割アイコンを点滅させる。
  **アイコンは送信モードでも出す。** 上りが無い以上、機体は届いたかどうかを
  知りようがないので、せめて「モジュールが生きていて送出できている」ことは見せる。
  枠とポップアップは受信モードだけ（表示の意味が入れ替わるのは受信側なので）。
- 電池は `S50R40%` の形で**送信側と受信側の両方**を出す。
  **送信機（機体）の電池低下は音声でも知らせる**（`wav/battery_low_sender.wav`、60 秒ごと）。
  本番では飛行中に交換できないが、試験飛行ではボートが先に気づいて降ろす判断ができるため。
  受信が切れると `link_sender_status()` が 0 を返すので、古い状態のまま鳴り続けることはない。
  SD／IMU／較正未適用の 3 つは従来どおり立ち上がりの低音 2 回だけにしてある
  （音声を増やすほど、本当に聞くべきものが埋もれる）。
- **10 秒受信が無ければ**「RECEIVER MODE. NO SIGNAL.」のポップアップを出し、
  自機の情報表示へ戻る。3〜10 秒の間は点滅させて「切れかけ」を示す。
- **NO SIGNAL 中もバリオを含めて全機能が動く。** 万一受信機モードのまま
  離陸しても使えるようにするため。
- ミラー ⇄ NO SIGNAL の遷移は音で知らせる。画面の数値の意味が
  「機体」と「自機」で入れ替わる瞬間なので、見ていなくても気づけるようにする。
- **目的地とナビモードは送信側に合わせて自動で上書きする**（RAM 上のみ）。
  食い違うとコース警告だけが静かにずれる。上書きしたことは必ず音声で知らせる。

### 電波アイコン

携帯電話と同じアンテナ本数表示。**枠 3 本（長さ違い）を常に描き、中を 0〜3 本ぶん塗る。**
塗りだけにすると 0 本・1 本のときに何の絵なのか読めなくなるため。

本数は**絶対値ではなく「限界からの余裕」で切る**。到達距離を決めているのは
`RSSI − 限界` であって RSSI そのものではないし、SF を上げれば限界も下がるので、
固定値のしきい値では SF を変えた瞬間に意味を失う。

```
限界 RSSI ≒ 環境雑音(実測 −104dBm) + SF の SNR 閾値
          = −111dBm (SF7)、SF が 1 上がるごとに −2.5dB
```

| 余裕 | 本数 | 色 | SF8 での目安 |
|---|---|---|---|
| 30dB 以上 | 3 | 緑 | > −83dBm |
| 20dB 以上 | 2 | 緑 | > −93dBm |
| 10dB 以上 | 1 | 橙 | > −103dBm |
| それ未満 | 0 | 橙 | ≦ −103dBm |
| 受信なし／モジュール無応答 | 0 + **赤い×** | 灰 | — |

- 判定に使うのは**直近 10 秒の平均 RSSI**。1 発ぶんは数 dB ふらつくので、
  瞬時値だと本数がちらついて読めない。
- 切れているときは 0 本アイコンの上に**赤い×**を重ねる。
  「弱い（0 本）」と「切れている」を色だけで区別させないため。
- 判定に使うアイコンは `src/flashdata/link_icons.cpp`（19×15 の 1bit マスク）。
  絵は `tools/gen_link_icons.py` で生成する。色は描画時に与えるので、
  同じ絵を強度に応じて緑／橙に塗り分けられる。

**★ 送信モードにアンテナ本数を出してはいけない。絵そのものを分ける。**

送信側には受信の手段が無い。強度を測っていないのに本数を出すと、
**測ったように見せることになる**。そこで送信モードは
**飛行機アイコンから出ていく電波の弧**（`ICON_TX0..3`）へ置き換える。

| 状態 | 絵 | 色 |
|---|---|---|
| 送出の直後（`LINK_TX_PULSE_MS` = 600ms 以内） | 弧 3 本 | 緑 |
| それ以外（待機中） | 弧 1 本 | 緑 |
| **一度も送れていない／モジュール無応答** | 弧 0 本 ＋ **赤い×** | 灰 |

弧は強度ではなく**脈動**である。1Hz 送信なので、**1 秒に 1 回膨らむのが正常**。
膨らみが止まったら送れていない。これなら「測っていないものを見せない」まま、
モジュールが生きて送出できていることだけを伝えられる。

### 送信前チェック（プリフライト）

**送信モードに入った直後だけ、3 秒間 mode 0 で聴いてから送り始める。**

> 当初は 5 秒だったが 3 秒へ短縮した。他機の PONS は 1Hz 送信なので **3 発ぶんの
> 受信機会**が残る。同じ CH に送信機が 2 台いる状況は、どちらも同じ格納庫内の
> 至近距離で RSSI が非常に強く、1 発でもほぼ確実に受かる。長くして拾えるのは
> 遠くの他チームの弱い電波で、それは警告する対象でもない。
> 雑音サンプルは 1 回目 500ms・以降 300ms 間隔で **9 個**取る。
確かめるのは 2 つ。

| 見るもの | 判定 | 対処 |
|---|---|---|
| 雑音の**中央値** > −100dBm | `NOISY` | ずっとうるさい。チャンネルを変える |
| 雑音の**最大値 − 中央値** > 8dB | `BUSY` | 断続的に誰かが出ている |
| 同じグループの PONS を受けた | `DUP SENDER` | **送信機が 2 台いる。** 設定を直す |
| 別グループの PONS を受けた | `PONS grp n` | 他チームと同じ CH/SF。どちらかが変える |

判定の文言は WIRELESS 画面の `Preflt` 行に出るもの（`DUP SENDER -96dBm` /
`PONS grp3 -96dBm` / `BUSY (bursts)` / `NOISY -96 dBm` / `NOT MEASURED` /
`OK (-104 dBm)`）。地図のポップアップは 2 行に分かれた別の文言で、
`ANOTHER SENDER` / `ON THIS CHANNEL !!` のように出る。
受信側の「送信機 2 台」検出も同じ `DUP SENDER` の語を使う（→ §5）。

**★ これは送信機が「送信機が 2 台いる」を自分で確かめられる唯一の機会。**
通常運転の送信機は送信の合間 mode 3 で寝ていて何も聴かないので、この検出は
受信機の `seq` 逆行に頼るしかなかった（→ §1「送信機の重複検出」）。
予備機の設定ミスで一番起こりやすく、一番まずい状態を、飛ぶ前に機体側で潰せる。

**★★ 問題が見つかっても送信は止めない。** 予備機を緊急で TX に切り替えて
載せ替える場面で、送信が始まらないほうが危険だから。E220 は ARIB のキャリアセンスが
必須実装なので、混雑していればモジュール側が自動で送信を待つ。
ここは「気づかせる」仕組みであって、飛行を止める仕組みではない。

- 中央値と最大値を分けるのは、**「ずっとうるさい」と「たまに誰かが出る」で対処が違う**ため。
  別 SF や他方式の送信はデコードできないので、最大値の突出でしか気づけない。
- しきい値 −100dBm は実測の環境雑音 −104dBm（→ §8）から 4dB の余裕。
- 走るのは「起動時に TX だった」「TX に切り替えた」「TX 中に CH/SF を変えた」
  「**WIRELESS 画面の `Preflight: re-run` を長押しした**」の 4 つ。
  Group を変えても走らない（電波の設定ではなくペイロードの中身なので）。
  手動の再実行を用意したのは、立ち上げ試験で「アンテナを動かして測り直す」を
  何度もやるため。従来は CH を変えて戻す遠回りしか手段が無かった。
  TX 以外では走らないので、選んでも低い音（440Hz）で断る。
- **受けたフレームは数えるだけで、`s_rx` にも `received/` にも入れない。**
  入れると送信機がミラー表示を始めてしまう。
- **雑音の取得が連続 2 回失敗したら、窓の最後まで回さずに打ち切る。**
  `e220_read_noise()` は応答待ちでブロックするので、無応答のまま 10 回呼ぶと
  Core0 が止まり、GNSS の FIFO（1024B / 38400bps ≒ 267ms）が溢れて NAV-PVT を
  取りこぼす。事前に `e220_alive()` を見てはいるが、**それだけでは塞げない**
  （→ 下「モジュールの生存確認」）。実際に叩いてみないと分からないので、
  叩く回数のほうを縛ってある。
  雑音を 1 つも取れなかった場合も、途中で打ち切った場合も**合格にはしない**
  （`NOT MEASURED`）。「静かだった」と「測れなかった」を混同させないため。
  途中まで取れた値から `NOISY` / `BUSY` を出すのは構わない（警告を弱める方向には倒さない）。
- 点検中は送信アイコンを**橙の弧 1 本**にする。そのままだと「弧 0 本＋赤い×」＝
  送れていない、に見えて故障と区別が付かない。

音は 3 通り。合格＝上昇 2 音、他機がいる＝`link_ch_busy.wav`、
雑音が高い＝`link_ch_noisy.wav`、測れなかった＝低い 2 音。
**対処が違うので音を分けてある**（チャンネル変更か、他チームとの調整か）。

### モジュールの生存確認

**`e220_alive()` は「設定を書いて読み返せたか」だけでは足りない。**
照合が走るのは `e220_setup()` と `e220_reconfigure()` のときだけなので、
それだけだと**飛行中にコネクタが抜けてもずっと OK のまま**になる。そのとき何が起きるか。

- `e220_send()` は UART へ書き込むだけで成功する。AUX はモジュール未実装・断線対策で
  内部プルアップを入れてあるため、居なくても High（アイドル）に見えて素通りする。
- `Sent` は 1 秒ごとに増え続け、地図の電波アイコンも脈動し続ける。
  **画面上は完全に正常なまま、電波は一度も出ていない。**
- **上りが無いので、ボートが無信号になるまで機体側では気づけない。**

そこで「問い合わせて返事があるか」を生存の根拠にする。返事＝生きている証拠は 2 つ。

| 証拠 | 誰が記録するか |
|---|---|
| 環境ノイズ取得の応答 | `e220_read_noise()`。こちらから聞ける往復はこれだけ |
| テレメトリを 1 発受け取った | `e220_recv()`。受信機はこれで足りる |

どちらかがあればカウンタを 0 に戻し、**連続 3 回返事が無ければ無応答**とみなす。
そうなると `Module : NO RESPONSE`、地図のアイコンは**赤い×**、`link_no_module.wav`。

- **送信機は 10 秒ごとにこちらから叩く。** 送信の合間は mode 3 で寝ていて、
  送信そのものからは生死が分からないため。起こして聞いてすぐ寝かせる（生きていれば数 ms）。
- **受信機は、受信できている間は叩かない。** 受かっていること自体が証拠なので、
  実際に問い合わせるのは無信号のときだけになる。
  「電波が届いていない」のか「自分のモジュールが死んだ」のかを区別するためのもの。
- 一度でも落ちたら応答待ちを 200ms → 30ms に詰める。無応答が続いても Core0 を
  止めないため。返事があれば元に戻る。
- **送信は止めない。** 無応答と判定しても `e220_send()` は今までどおり書き込む。
  判定のほうが誤っている可能性があるので、下りを自分から切らない。

### ボート自身の位置

ミラー中の地図は**機体**を中心に描くので、ボート自身は地図上に存在しない。
追走ボートにとっては「機体と自分がどれだけ離れているか」が知りたい情報なので、
自分の位置だけを小さく重ねる。

- **3px の点。** 機体マーカーより明らかに小さくして主役を取らせない
- **2m/s 以上のときだけ**進行方向へ 5px の線を伸ばす。
  停船中の GNSS の方位はでたらめなので、出すとかえって誤解を招く
- **色は明るい緑。** 飛行軌跡も緑（濃い）で、しかもミラー中の軌跡は機体のものなので、
  同じ色にすると埋もれて見つけられない
- ボート自身の航法は v6 以前の機体に任せる。受信機はあくまで「機体の画面の再現」

### 受信ログのリプレイ

`received/` は**リプレイ画面から再生できる**。一覧の `SOURCE` を
`RECEIVED (radio)` に切り替えると、走査するフォルダが `received/` に変わる。

- **一覧に出すのは常にどちらか一方だけ。** 混ぜないので、ページ計算も
  ファイル番号も「1 フォルダぶん」のままでよい（既存の計算に手を入れていない）
- 一覧の**並びはファイル名順ではなく、ディレクトリの登録順**（＝SD へ書かれた順）。
  上に出したいものはカードへ先にコピーする
- 走査するのは `data/`（自機）と `received/`（受信）だけ。設定用の CSV は
  ルート直下にしか無いので、**除外リストを持たなくてよい**
- 受信ログには**姿勢・風の列がそのまま入っている**ので、飛行 CSV のように
  `imu_replaydata/` を日付で引きに行く必要が無い。
  **★ 引きに行ってはいけない。** そこにあるのは**ボート自身の姿勢**なので、
  機体の航跡にボートのロール・ピッチが黙って合成される。
  判定は「CSV 自身が roll 列を持っているか」だけ
- 再生中は `REPLAY` ではなく **`REPLAY RX`** と出す。自機の飛行ではなく
  機体の飛行だと分かるようにするため
- **リプレイ中はミラーしない**（`link_mirror_active()` が false を返す）。
  再生を選んだのに生の受信データが出続けると「再生できない」ように見えるため。
  生データは `received/` に残り続けるので、再生を優先しても失うものは無い
- **★ リプレイ中は送信もしない**（`link_tx_tick()` が早期 return。0.978）。
  `apply_replay_row()` は `stored_latitude` / `stored_fixtype` など
  **実センサーの格納変数そのものを上書きする**ので、TX のまま再生すると
  **過去の飛行を「いまの飛行」としてボートへ流す**。`fixflags` も立つため
  受信側からは正常な現在位置と見分けがつかない。
  地上での確認作業で電波を出す理由も無い（ARIB 的にも占有しない）。
  ボート側は 10 秒後に `NO SIGNAL` になるが、それが「送っていない」正しい表示

> 受信モード中、**ルートの飛行 CSV にはボート自身のデータが記録されている**
> （位置・速度・方位は生のグローバル、気圧と高度は `_raw` の accessor）。
> つまり **画面に一度も出ていなかったボート自身の画面**も、あとから再生できる。

### ★ リプレイ中・デモ中は無線を「OFF 扱い」にする

データの経路（ミラーと送信）は 0.978 で切ってあったが、**画面の飾りと音は
`link_mode_setting` で分岐したままだった**。そのため RECEIVER / SENDER のまま再生すると、
**あたかもそのとき送信機／受信機だったかのような画面**になっていた（受信枠・
`RECEIVER MODE. NO SIGNAL.` のポップアップ・艇アイコン・S/R の 2 本立て電池）。
ミラー中の原則を裏返しただけの同じ間違いで、基準も同じ
**「その表示は、いま画面に出している数字の話か」** —
出してよいのは**その数字の出どころ**だけで、**いま電波が出ているか／届いているかは出さない。**

判定は **2 つの述語だけ**（[link.h](../link.h)）。条件を呼び出し側に書き写さないこと。

| | 中身 | 使う場所 |
|---|---|---|
| `link_rf_suppressed()` | リプレイ中 or デモ中 | `link_tx_tick()`、WIRELESS 画面の `Hold` 行 |
| `link_live_ui_ok()` | その否定 | `link_mirror_active()`、`draw_link_overlay()`、ヘッダの枠、S/R 電池、`link_watch_mirror_transition()` |

- **`link_mode_setting` は書き換えない。** SD に保存される設定なので、デモのために
  OFF を代入すると**翌日そのまま無線が黙って飛ぶ**。抑止は振る舞いだけ
- **自機 CSV の再生は「OFF 扱い」で正しい。** 当時 OFF だったか SENDER だったかは
  記録に無いが、TX の表示は「いま電波が出ているか」であって**数字の性質ではない**ので、
  再現しなくても失う情報が無い。CSV に列を足す必要も無い
- `received/` の再生で「他機のデータだ」と分かるのは **`REPLAY RX` バッジ**の仕事。
  当時のアンテナ本数まで再現する手は残っている（`received/` には `rssi` 列が
  **既に書かれていて**、リプレイ側に列定義が無いだけ）が、`have` ビットを
  1 つ消費するので、必要になるまで足していない
- **デモも送信しない。** デモは `stored_*` を上書きしないので**フライト CSV には
  残らない**のに、`link_push_telemetry()` は `get_gnss_lat()` など accessor 経由なので
  **仮想機体はそのまま電波に乗っていた**。`fixflags` だけ実 GNSS 由来なので、屋外で
  fix がある機体がデモを出すと**ボートには「本物の飛行」として届く**。
  **記録に残らないものだけが電波に出る**、一番たちの悪い非対称だった
- **デモ中はミラーもしない。** 許すと `get_gnss_lat()` が「ミラー → デモ」の順に見るため、
  **受信中は機体・切れた瞬間に仮想機体**へ黙って化ける
- **受信（RX）の電波そのものは止めない。** `received/` に書き続けるのはボートの本来の
  仕事で、害が無いうえ失うと二度と戻らない。送信を止めるのは**嘘の電波を出す**から
- **音は「生の事実」だけ残す。** 送信機の異常・電池・モジュール無応答は再生中も鳴らす
  （画面に何を出していても現実に起きている）。止めたのは
  `link_watch_mirror_transition()` だけ — あれは「**いま画面に出ている数値の意味が
  入れ替わった**」という音なので、電波で動かない画面では嘘になる。
  **前回値を更新せずに return する**ので、再生をやめた直後の 1 回でちゃんと知らせる
- 地図の送信アイコンの「リプレイ中は灰色の弧 1 本」（0.978）は畳んだ。
  **役割アイコンが出ること自体が「そのとき送信機だった」に見える**。
  止めている事実は WIRELESS 画面の `Hold : replay (no TX)` に出る

### ★ ミラー中に「自機の状態」を混ぜない

画面の数値が機体のものに入れ替わっても、**警告やその値の品質表示は自機のまま残りやすい**。
0.983 の実機テストで 6 か所見つかった（受信中のボートで、機体は健全なのに
`ESKF CALIBRATION REQUIRED!` が出て 平均ピッチに取り消し線が入っていた）。

判断の基準は **「その警告は、いま画面に出している数字の話か」**。

| 出しているもの | ミラー中に見るべきもの |
|---|---|
| 較正のやり直し（赤字 / Pavg の取り消し線） | **送信機の** `LINK_ST_NEEDS_APPLY`（`link_sender_status()`） |
| `ESKF Not ready` | 出さない（自機の収束状況は無関係。しかも `return` するので**ミラーした姿勢が丸ごと消える**） |
| VSI のバー・**バリオ音** | 送信機の V/S。自機の MS5611 / BNO085 の有無で分岐しない |
| `sAcc` / `vAcc` / `fixtype` / 気圧 V/S・気圧高度 | **`--`**。LinkTelem が運ぶのは `hAcc` / `numsat` / `fixOK` / 気圧そのものだけ |
| APPLY を許すか（`eskf_calib_allowed()`） | 自機の静止判定。`get_gnss_mps()` は**機体の速度**なので使えない |
| 自機のハードウェア診断（センサー OK/NG・イベントレート・バイアス・DOP・PRN） | 自機のまま。ただし**見出しに `(RX unit)` を付けて区別する** |

実体は `display_tft.cpp` の `eskf_display_needs_apply()` / `gnss_acc_unknown()` と、
`imu.cpp` の `vario_source_ok()` / `vario_vspeed_mps()` / `vario_deadband_mps()`。
**`attitude_needs_apply()` / `get_gnss_sacc_mmps()` / `get_imu_ok()` を描画側から
直に呼ばないこと。**

バリオは**音と VSI の線が同じ関数を通る**ようにしてある。0.983 までは
`src/sound.cpp` が `get_imu_alive()`、`display_tft.cpp` が `get_imu_ok()` と
**別々に分岐していた**（定数は共有していたので気づきにくい）。ミラー中に
自機の気圧 V/S へフォールバックすると、**ボートの波の上下動でバリオが鳴る**。

`sAcc` / `vAcc` を accessor 側（`gnss.cpp`）で 0 に差し替える手は**使わない**。
受信機自身の GNSS 詳細画面で自機の測位品質を見たい場面があり、そこまで潰れる。
同じ理由で、自機の値が要る診断ページでは `*_raw()`（`get_imu_vspeed_raw()` /
`get_airdata_pressure_raw()`）を使う。

### ミラー中に止めること

**受信した機体の値を自機の推定へ入れてはいけない。**

- 自機のカルマン（`imu_kalman_gnss_update`）— 気圧基準と GNSS オフセットが壊れ、
  受信をやめた後まで残る
- `imu_replaydata/` の記録 — 受信した機体の日時のファイルに自機の姿勢を書いてしまう

---

## 6. E220 を扱う上での落とし穴

### ★ モード切替の「あと」も AUX の立ち上がりを待つ

**これが v7 立ち上げで最も長く嵌まった罠。**

データシート 5.4 の 4 番と図 36 のとおり、**モード遷移ではハードウェアの
セルフチェックが走り、その間 AUX は Low**、完了で High に戻る。
`set_mode()` は切替の**前**だけでなく**後**も待たなければならない。
待たずに喋りかけると、**書き込みが黙って捨てられる**。エラーも返らない。

症状が厄介で、**まったく別の原因に見える**。

- mode 0 の状態レジスタ読み出しが、**どのコマンド形式でも・どの送信モードでも**
  「返事ゼロ」になる → 書式を疑って何日も溶かす。実際は**一度も届いていない**
- mode 3 の読み出しは**偶然通る**。`set_baud()` の `end()/begin()` や
  `e220_setup()` の `delay(120)` が、たまたま間を作っているため
- 起床直後の送信で `AUX stuck LOW` が毎回出る。無線が混んでいるように見えるが、
  実際は**こちらが早すぎるだけ**

同じ理由で、**起床直後に最初の問い合わせを叩かないこと**。
プリフライトは 1 回目のサンプルを `LINK_PF_SAMPLE_MS` だけ後ろへずらしてある。

### ★ mode 3 へ潜ったあと、すぐ喋りかけない（`enter_config_mode()` を通す）

AUX の待ちだけでは足りない。`set_mode()` が返ってきた時点でも、

- モジュール内部がコマンドを受け付けるのはもう少し後
- `set_baud()` の `end()/begin()` が線を一度落とすので、**直後の 1 バイト目が化ける**

ので、**切り替えたあとに `E220_CFG_SETTLE_MS`（30ms）待つ**。
この 3 手順は `enter_config_mode()` にまとめてある。**自分で並べ直さないこと。**

**実機で踏んだ症状（2026-09-23）**

設定画面で **CH を変えた瞬間**から `Module NO RESPONSE` になり、
そのあと Mode を切り替えても復帰しなかった。ログはこう出ていた:

```
32:E220 regfail op=C1 addr=00 len=6 got=3 ERR(FFFFFF) [FF FF FF 00 00 00] AUX=1
32:E220 cfg: readback differs or unread, writing (persist=0)
32:E220 regfail op=C1 addr=00 len=6 got=5 ERR(FFFFFF) [00 F0 FF FF FF 00] AUX=1
32:E220 cfg: READBACK failed after write
32:E220 reconfigure ch=7 prof=1 persist=0 -> alive=0 AUX=1
32:LINK ERROR: radio module not responding
```

`AUX=1`（＝ビジーではない）なのにエラー応答と化けが返る。
書式の問題に見えるが、**そうではない**。

切り分けの決め手は、**同じ mode 3 のレジスタ読みでも `e220_ping()` は通っていた**こと。
復帰経路の `LINK: module responds but unconfigured` が出ていた＝ping は成功していた。
両者のコードの差はこの待ちの有無**だけ**だった（ping には最初から入れてあった）。

起動時だけ成功していたのは、`e220_setup()` が手前に `delay(120)` を置いていて、
それが偶然この待ちの代わりをしていたため。**起動時に動くので気づきにくい。**

なお `e220_reconfigure()` は失敗したら **mode 0 へ抜けて 1 回だけやり直す**。
ここが false のままだと `s_alive` が落ち、次に誰かが設定を変えるまで
誰も再試行しない（＝「一度失敗したら戻らない」）ため。

### 状態レジスタ（0xA0〜0xA4）は Strict Mode でしか読めない

環境ノイズ `0xA3` はここにある（表 17）。そして表 24 に
「レジスタ読み出しコマンド**(Strict Mode でのみ使用可)**」と明記されている。
10.1 が「mode 3 では両モードで読める」と言うのは **9.1 の設定レジスタ
（0x00〜0x0A）**の話で、状態レジスタは含まない。
無効時に読むと `FF FF FF`（無効レジスタのエラー応答）が返る。

`0x09` bit6 が Strict Mode 切替フラグで、**不揮発**。
`ensure_strict_mode()` が毎起動で読み、**無効なときだけ**書く。
3 台運用で個体差が出ると最悪なので、焼けば勝手に揃う形にしてある。
既に有効なら書かないので、書換えは 1 台につき生涯 1 回。

### ver.1 互換の環境ノイズコマンドは使わない

6.8 の `C0 C1 C2 C3 00 02` は、**実機（firmware v2.0）で返事がゼロ**だった。
しかも直後に AUX が Low へ落ちる＝**6 バイトが電波として出ている**。
送信すべきでない機体が送信するので、退路を残さないこと
（`s_strict` が false なら `e220_read_noise()` は何もせず false を返す）。

正しいのは表 24 の形式で、**mode 0 のまま**使える。

```
送信: FF FF C1 A3 01
応答: FF FF C1 A3 01 <値>        dBm = 値 - 256
```

**長さは 1 レジスタずつ。**`0x02` で 0xA3 と 0xA4 をまとめて読もうとすると
返事が来ない（6.15 の「取得レジスタの範囲指定が正しくない場合」に当たる）。

### ★ mode 3 へ潜って環境ノイズを読もうとしない

mode 3 では `0xC0` は「レジスタ書き込みコマンド」なので、ver.1 のコマンド列が
**addr=0xC1・長さ=0xC2(194) の書き込み**と解釈され、モジュールが残り 194 バイトを
待ち続けて**以後のコマンドを全部無視する**（実機で踏んだ）。
また 6.4 のとおり mode 3 は無線部が止まっているので、仮に読めても値は 0 で意味がない。

### 「返事が無い」は「書式が違う」かもしれない

6.15 に、状態レジスタ取得コマンド専用の但し書きがある。

> コマンドとして解されない場合(単に宛先チャンネル部分が間違っている場合や
> 取得レジスタの範囲指定が正しくない場合)に**エラー応答はありません**

つまり**無言はモジュールの故障を意味しない**。切り分けログでは必ず
「何バイト届いたか（`got`）」を出すこと。0 と 0 以外で対処が正反対になる。

### コマンドの応答を先頭決め打ちで読まないこと

受信データやモード切替時のゴミが応答の前に乗る。**実測で 1 バイトのゴミが乗り、
`got=4 [F8 C1 08 01]` と 1 バイトずれて値が FIFO に残った**。

`reg_xfer()` は当初「`3+len` バイト受け取ったら読むのをやめる」作りで、
**ゴミが 1 バイトでも乗ると構造的に必ず失敗していた**。
**バイト数で打ち切らず、応答の並びが見つかるまで読み続ける**こと。

### 送信方法（REG3 bit6）について

現在は **1＝通常(Fixed-block)送信モード**で運用している。
送信時にペイロードの前へ宛先 3 バイト（ADDH/ADDL/CH）を付ける必要があり、
ブロードキャストは `FF FF <ch>`（4.3）。

> 以前この節には「必ずトランスペアレント（bit6=0）にすること。さもないと
> ノイズ取得コマンドが送信データと誤解されて電波が出る」と書いてあったが、
> **これは誤りだった。**真因は上記の AUX 待ちで、送信モードとは無関係。
> 透過モードでも同じ症状が出ていた。現在の構成は実機で検証済み
> （2 回連続起動で `n=10` / `-> 0x00`）なので、理由なく戻さないこと。

### 書込みコマンド `0xC0` は不揮発なので書換え寿命がある

起動時はまず `0xC1` で読み返し、一致していれば書かない。

- 起動時の 1 回だけ `0xC0`（不揮発）
- **設定画面での変更は `0xC2`（RAM のみ）**。CH を 0→12 と回すだけで 13 回に
  なるため。設定の正本は SD の `settings.txt` 側なので、次回起動時に
  同じ値が書き直される

### AUX は未接続・モジュール不在だと入力が浮いて Low に見える

「ビジー」と誤読すると永久に待つので、内部プルアップを入れて
居ないときは High（アイドル）に見えるようにする。

### 環境ノイズの取得は mode 0 のまま行う＝受信と同じ UART を使う

ここで受信バッファを捨てると、**電波を確かめるための画面が受信を殺す**
（設定画面は 1Hz で問い合わせ、テレメトリも 1Hz で届く）。
応答とテレメトリを同じ組み立てバッファに入れ、応答の 6 バイトだけを抜くこと。
バッファを捨ててよいのは mode 3 に入っている間だけ。

なお **AUX が Low のときは問い合わせ自体を見送る**（5.3）。ビジー中の書き込みは
取りこぼされるため。5.4 の 3 番のとおり **受信バッファにデータがあると AUX は Low**
なので、受信モードでテレメトリが届いている最中は雑音を測れないことがある。
画面は `---` を出す（0 を「0dBm」と表示しない）。送信前チェックは TX モードで
テレメトリが入って来ない状況なので、ここは実機で 10/10 取れている。

---

## 7. 電波法

- **E220-900T22S(JP) は技適取得済み**で免許不要。920.6〜928.0MHz、最大 13dBm(20mW)
- **アンテナ利得は 3dBi 以下**（EIRP が 16dBm を超えられないため）。
  使用する `TX915-FPC-4510` は 2dBi
- **CH0〜12 に限る**（→ §2）
- キャリアセンス（LBT）はモジュールが必須機能として実装しており無効化できない
- **ボートから機体へ「操作」を送る機能は作らない。** 上りの通信路そのものが
  存在しない（→ §3）ので、遠隔で変更する経路は物理的に作れない

---

## 8. 実測

| 条件 | 設定 | 到達距離 | 限界RSSI |
|---|---|---|---|
| 芝生（凹凸あり） | 500k SF5 | 約 100 m | −89 dBm |
| 同上 | 500k SF8 | 約 190 m | −99 dBm |
| **海辺・平坦なコンクリート・夜間** | **500k SF7** | **約 350 m** | −100〜−110 dBm |

- **壊れフレーム（`bad`）を数えている。** magic(`PL`) は合ったのに ver/type/CRC の
  検証に落ちた数で、WIRELESS 画面の `Rx/Miss` 行と 60 秒ログの `bad=` に出る。
  `Miss`（seq の欠番）は「化けた」と「来なかった」を合算した数なので、
  この 2 つを並べて初めて原因が切り分けられる。
  **マージナルなリンクは全損より先に必ず `bad` として現れる**ので、
  アンテナ調整では一番効く指標になる。
  - `bad` が増える → 信号は届いている。SNR 不足。向き・位置・SF を見直す
  - `bad` が増えず `Miss` だけ増える → 圏外・CH 違い・送信機が送っていない
- **リンク余裕（`mgn`）を dB で出している。** WIRELESS 画面の `Noise` 行。
  アンテナ本数（0〜3）と**同じ根拠**（`link_rssi_margin_db`）から出しているので
  食い違わない。本数は 3 段階しかなく、置き場所を少し変えたときの差が読めないため、
  A/B 比較には dB の数字を使う。
- 環境雑音は**熱雑音 +7dB（BW500kHz で約 −104dBm）**。屋内外でほとんど変わらない
- **要求 200m を 1.75 倍で満たした**
- 限界 RSSI は「環境雑音 + SF の SNR 閾値」と**見通しの良い地点でのみ**一致する。
  SF7・海辺の −110dBm は理論値 −111dBm とほぼ一致したが、芝生の SF8 は
  −99dBm で止まった。後者は感度ではなく地形（フレネル半径・多重反射）で
  切れている。**アンテナ本数の表示は理論値を基準にしているので、
  地形が悪い場所では 1 本のまま切れることがある**（→ §5）
- **1 回目と 2 回目の差（100m→350m）は SF では説明できない。**
  SF5→SF7 の利得は 5dB で距離にすると 1.3〜1.8 倍にしかならず、
  残りを説明するにはさらに 6〜17dB 相当が要る。
  設置条件（平坦なコンクリート／アンテナの置き方）か地点の雑音差か、その両方。
  **この 2 回のデータでは切り分けられない**

### アンテナは SF より効く

**アンテナの角度で RSSI が変動し、パケットロストが始まる**（実測）。
偏波ミスマッチの損失は 45°ずれで 3dB、60°で 6dB、80°で 15dB。
**SF を 1 段上げても 2.5dB** しか稼げない。

低いアンテナ同士では、ある距離から先は損失が距離の 2 乗ではなく **4 乗**で増える
（2 波地面反射）。受信電力は `(h1×h2)²` に比例するので、
**高さ 1m/1m → 2m/2m で +12dB、1m/1m → 3m/10m で +30dB**。
プラットフォームは 10m の高さがあるので、アンテナを最上部に出すだけで
最大の効果が無料で得られる。

---

## 9. 未確認

立ち上げ試験の手順は [pons_link_bringup.md](pons_link_bringup.md) にある。

- **受信機のスリープ。** 現状は常時 mode 0 で 8.2mA。送信が 1Hz と分かっている以上、
  受信窓を絞れば下げられる。**実装予定**。位相同期の取り方（起動直後の取得フェーズ、
  時計のドリフト、ロスト後の再取得）が設計課題
- **SF8 以外の送信時間。** SF8 の 98.4ms だけメーカー表で確認済み。
  他はメーカー表から取り直すこと（→ §3）
- **水面での挙動。** 試験はコンクリートと芝生だけで、水面の反射は未確認
- 基板到着後の実結線試験（設定書き込み → 送受 → RSSI 取得）
- 機体の姿勢変化に耐えるアンテナ取り付け方法

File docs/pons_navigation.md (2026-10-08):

# PONS ナビゲーション — 仕様の要約

パイロットに「**いま、どちらへ向かって漕げばよいか**」を 1 つの方位で示すための仕組み。
この文書は**ロジックだけ**を短くまとめたもの。画面写真つきの操作説明は Google Docs の説明書、
しきい値と色の一覧は [../README.md](../README.md) にある。

実装は [../navdata.cpp](../navdata.cpp)（計算）と [../GPS_TFT_map.ino](../GPS_TFT_map.ino)（判断・発報）、
[../display_tft.cpp](../display_tft.cpp)（描画）の 3 つに分かれている。

---

## 1. 前提

- **方位はすべて真方位（True）。** 磁方位は廃止した。機体に磁気コンパスを積まないため。
- 位置は GNSS のみ。**推測航法はしない**（測位が途切れたら最後の位置のまま止まる）。
- **風は一切考慮しない。** 示すのは常に対地の幾何であって、偏流を打ち消す針路ではない。
- 高度はナビゲーションに使わない。すべて水平面の 2 次元で考える。

## 2. 計算の土台

| 量 | 式 | 実装 |
|---|---|---|
| 2 点間の距離 [km] | Haversine（地球半径 6371km の真球） | `calculateDistanceKm()` |
| 2 点間の真方位 [rad] | 球面三角法（`atan2`） | `calculateTrueCourseRad()` |
| 緯度→画面 Y | メルカトル `Y = ln(tan(π/4 + φ/2))` | `latitudeToMercatorY()` |
| 緯度経度→画面 XY | 上記 ＋ 拡大 ＋ 画面上方向への回転 | `latLonToXY()` |

メルカトルは等角なので、**画面上の km/px は東西・南北で等しく `scale / cos(緯度)`** になる。
距離スケールバーも円も同じ係数で描いている。

## 3. 目的地

`extradestinations[]` に登録された地点の 1 つを `currentdestination` で選ぶ。

- 固定の 4 つ … `PLATHOME` / `N_PILON` / `S_PILON` / `TAKESHIMA`
- SD の `destinations.csv` にある分を後ろに追加（最大 100）

座標は `navdata.h` の `#define` が既定値で、SD の `override_pilon_coordinate.csv` があれば
起動時に上書きする。**上書きした値は目的地・地図のアイコン・基準線・センターラインの
すべてが同じ変数を見る**ので、1 か所直せば全部そろって変わる。

## 4. ナビゲーションの出力

毎回の GNSS 更新で `nav_update()` が 2 つだけ更新する。

```
dest_dist … 現在地 → 目的地 の直線距離 [km]
truec     … 現在地 → 目的地 の真方位 [deg]（モードにより 180 度反転）
```

`truec` がすべての表示・警報の入力になる。画面では
フッターの `TC`、地図のマゼンタの誘導線、赤い修正矢印、コース警報の円弧がこれを使う。
測位できていない間は `TC---` / `---km` を出す（内部の位置が (0,0) のため）。

**判断は画面モードによらず動く。** Auto 10km のフェーズ判定・コース警報・旋回角速度は
`loop()` 最上位の `nav_alarm_tick()` にまとめてあり、設定画面や詳細画面を出していても止まらない。
描画だけが地図画面の担当。加えて、**設定画面はボタン操作が 3 分無ければ自動で地図画面へ戻る**
（設定画面を出したまま離陸してしまった場合の保険。`SETTING_IDLE_TIMEOUT_MS`）。

## 5. 3 つのナビモード

設定の `navigation_mode` で選ぶ。

| モード | `truec` | 用途 |
|---|---|---|
| `FLY INTO` | 目的地への方位 | 目的地へ向かう |
| `FLY AWAY` | 目的地への方位 **+180°** | 目的地から最短で離れる |
| `Auto 10km` | フェーズにより上記を自動で切り替える | 大会本番 |

`FLY AWAY` は「その地点から真っ直ぐ遠ざかる」モードであって、
**どこか別の点へ誘導するものではない**。

## 6. Auto 10km の状態機械

目的地は **PLATHOME を選ぶ前提**。距離は「現在地 ↔ 選択中の目的地」で測る。

```
        距離 > 10.475 km
  AWAY ──────────────────▶ INTO      AWAY: truec = 目的地方位+180（離れる）
    ▲                        │        INTO: truec = 目的地方位（戻る）
    └────────────────────────┘
        距離 < 1.5 km
```

- 判定は GNSS 更新のたびに**距離そのもの**を見る（通過を記憶するのではない）。
- しきい値は公式ルールの 10.975km / 1.0km に対し、潮流などのズレを見込んで
  それぞれ 500m 内側に取ってある。
- 切り替わると 4 音のトーンと `destination_change.wav` が鳴る。
- フェーズは SD の `auto10k_status` に保存する。**飛行中に再起動しても復路のまま復帰する**
  （距離だけでは往路と復路を区別できないため）。
- リプレイ再生中の遷移は表示だけ変え、保存値には触れない。

**このモードはパイロンへは誘導しない。** パイロンへ向かうかどうかは、
画面の基準線と TT を見てパイロットが判断する。

設定画面には歯止めがあり、`N_PILON` / `S_PILON` / `TAKESHIMA` を選んだまま
Auto 10km にしようとすると、エラー音とともに `FLY INTO` に戻される
（[../src/button.cpp](../src/button.cpp) の `is10K_NotAllowed_Destination()`）。

## 7. コース逸脱の警報

「ズレを積算して、一定量たまったら鳴らす」方式。時間で積むので GNSS が 1Hz でも 2Hz でも同じ。

```
ズレ角 steer_angle = truec − 実際の進路(TT)      （-180〜+180 に正規化）

毎回 dt 秒ぶんだけ index を増減する：
  対地速度 < 2m/s、または衛星 0      → index = 0（発動しない）
  正しい向きへ修正中                  → index −= 15 × |旋回角速度| × dt
  15°以上ズレていて修正していない      → index += min(|ズレ角|, 90) × dt
  ズレが 15°未満                      → index = 0
index は 0〜900 に飽和。900 に達したら音声（course_right / course_left）＋トーン。
発報後は 30 秒鳴らさない。
```

つまり **15° のズレを放置すると 60 秒、90° 以上なら 10 秒**で鳴る。
画面ではこの index が赤い円弧の長さになるので、鳴る前から「たまってきた」ことが見える。

## 8. 旋回角速度

直近 4 サンプルの真方位の変化量の合計を、その 4 サンプルの実経過時間で割る（`update_degpersecond()`）。
2Hz なら 1.5 秒ぶんの平均。360°またぎは ±180 に正規化する。
0.5deg/s 未満は表示しない。この値はコース警報の「修正中かどうか」の判定にも使う。

## 9. 航跡

約 50m ごとに 1 点、最大 500 点（約 25km 分）をリングバッファに保存して緑線で描く。
間隔は対地速度から決める（停止中は最大 15 秒に 1 点）。**SD には別に 2Hz で記録している**ので、
この 500 点は表示専用。

## 10. 琵琶湖コースの表示

PLA から緯度経度とも ±0.6° 以内、かつ縮尺が一定以上のときだけ描く。

- PLA → 北/南パイロンの青い基準線、PLA → 竹島の緑線
- PLA 中心の 10.975km 円と 1.0km 円
- 北/南パイロンの中間方位（**センターライン**、オレンジ）を 1km〜10.975km の間だけ
- パイロン座標から毎回計算するので、**座標を上書きすれば線も円も一緒に動く**

現在の座標での値（`navdata.h` から計算）:

| | 真方位 | PLA からの距離 |
|---|---|---|
| 北パイロン | 328° | 10.99 km |
| 南パイロン | 258° | 10.95 km |
| センターライン | 293° | － |

## 11. 保存される設定

`navigation_mode` / `destination`（名前で保存）/ `auto10k_status` / `scaleindex` / `upward_mode`。
**DEMO と REPLAY は保存しない**（電源を入れ直せば必ず本番設定に戻る）。

**SD を読めないときは既定値のまま動く。** 0.984 でその既定値を
**TRACK UP / Auto 10km / PLATHOME** にした（それ以前は NORTH UP / FLY AWAY）。
カードが壊れた機体でも本番の組み合わせで飛べるようにするため。

## 12. 既知の制約

- Auto 10km の判定距離は**選択中の目的地**から測るが、地図に描かれる 10.975km 円は
  **常に PLA 中心**。上の歯止めは 3 つの固定目的地しか見ていないので、
  `destinations.csv` で追加した地点を選ぶと両者がズレたまま飛べてしまう。

---

初版 2026/09/12 — 更新 2026/10/08

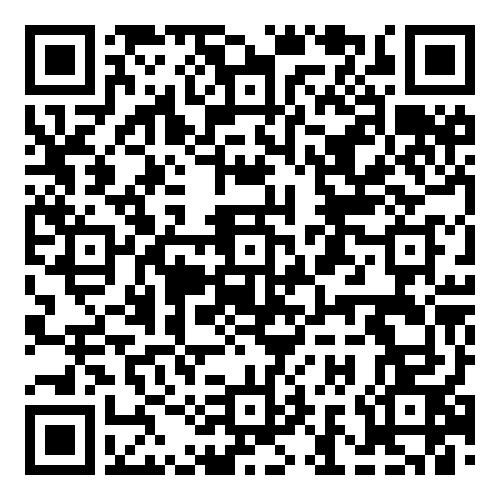
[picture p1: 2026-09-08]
docs/QR_pons_v7.png

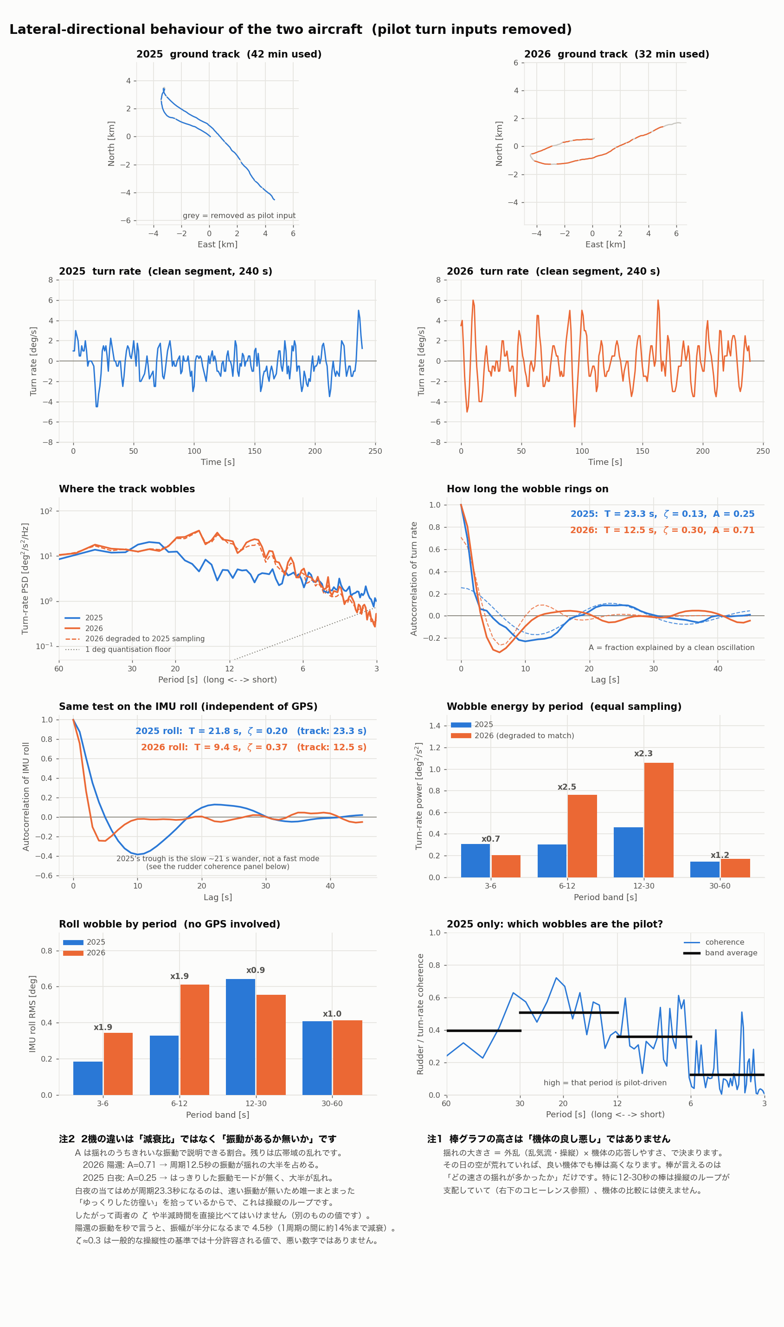
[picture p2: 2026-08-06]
tools/flightanalysis/lateral_modes.png

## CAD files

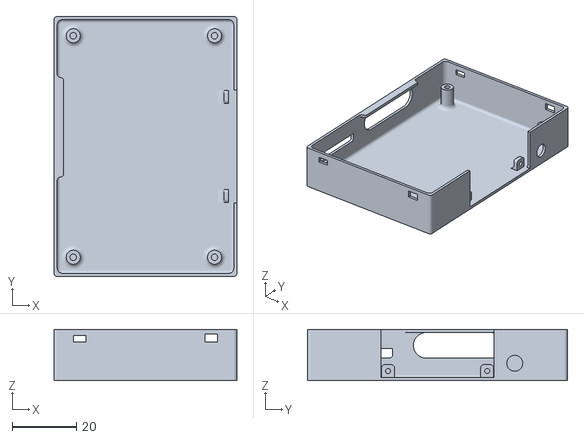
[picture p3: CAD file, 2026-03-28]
case_3Dmodel/case_v6_body.stl
57.0 x 81.0 x 16.0

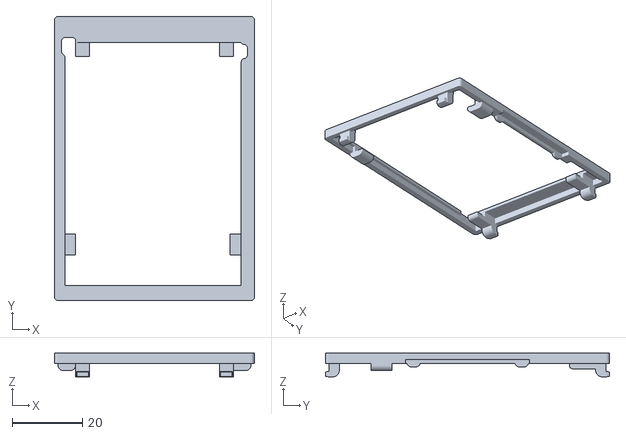
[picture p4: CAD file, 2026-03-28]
case_3Dmodel/case_v6_cap.stl
57.0 x 81.0 x 6.80

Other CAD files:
case_3Dmodel/case_for_v6.f3z

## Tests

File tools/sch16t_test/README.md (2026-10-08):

# SCH16T-K01-10 単独テスト（Raspberry Pi Pico 2）

PONS 本体から**完全に独立**した立ち上げ用スケッチ。
`sch16t_test.ino` を Pico 2 に焼いて、シリアル（115200）から 1 文字コマンドで操作する。

目的は 3 つ。

1. SafeSPI2 の 48bit フレームで会話できることを確認する
2. 初期化シーケンス（リセット → 設定 → EOI → 検証）を通す
3. **BNO085 と同じ土俵の数値を実測する** — 静止バイアス・ノイズ・`|a|/g` のスケール誤差・実 ODR

---

## 配線

| SCH16T | Pico 2 | 備考 |
|---|---|---|
| MISO | GP16 | SPI0 RX |
| CS | GP17 | スケッチが手動で叩く |
| SCK | GP18 | SPI0 SCK |
| MOSI | GP19 | SPI0 TX |
| EXTRESN | GP20 | Low でリセット。内部プルアップあり |
| DRY_SYNC | GP21 | **入力にする。出力にしないこと**（SYNC 入力との兼用ピン） |
| 3V3 | 3V3(OUT) | V3P3 と VDDIO の両方へ |
| GND | GND | |

`TA9` / `TA8` は `kicad/IMU_murata/` のブレイクアウト上で GND に落ちている想定
（データシート: *"Connect to ground for default '0' address"*）。
**未確認なら最初に `a` で走査する。**

配線は短くすること。長いジャンパだと 10MHz で落ちる。スケッチは 1MHz で始まる。

**v7 本体では J7（8pin FPC）経由で繋がる。** ブレイクアウトの J1 とピン順が一致しているので
1:1 ケーブルでよい。本体側の GPIO は
`CS=41 / SCK=42 / MOSI=43 / MISO=44 / EXTRESN=45 / DRY=46`（SPI1 の正規割り当て）。

| pin | 1 | 2 | 3 | 4 | 5 | 6 | 7 | 8 |
|---|---|---|---|---|---|---|---|---|
| | +3V3 | RESET | MOSI | CS | SCK | SYNC | MISO | GND |

**ブレイクアウトの R2（CS–GND の 4.7k）は実装しない。** CS は負論理なので、
プルダウンすると MCU が駆動していない間セレクト状態になる。R1（EXTRESN プルアップ）は実装する。

## ビルド

```sh
"/Applications/Arduino IDE.app/Contents/Resources/app/lib/backend/resources/arduino-cli" \
  compile -b rp2040:rp2040:rpipico2 --build-path /tmp/sch16tbuild tools/sch16t_test
```

書き込みは Arduino IDE から（ボード **Raspberry Pi Pico 2**）。

## コマンド

| | |
|---|---|
| `h` | ヘルプと現在の設定 |
| `a` | TA (TA9:TA8) を走査。**応答しないときまずこれ** |
| `i` | ID と設定レジスタを読む |
| `t` | `SYS_TEST` に書いて読み返す（**データシート推奨の疎通確認**） |
| `r` / `R` | 初期化（ソフト / EXTRESN ハードリセット） |
| `s` | ステータス全ダンプ＋フレーム統計 |
| `m` / `M` | 静止測定 10 秒 / 60 秒 |
| `G` | **ジャイロ感度の実測**（90°/360° 回して積分）。ジャイロのスケール検証はこれだけ |
| `d` | DRY_SYNC で実 ODR を測る |
| `c` | 連続表示（人が読む形式） |
| `v` | CSV 出力（ログ取り用） |
| `p` | `*_1`（補間）と `*_2`（デシメーション）の生値比較 |
| `k` | SPI クロック 1→2→5→10MHz |
| `f` | フィルター 68→30→13Hz |
| `e` | デシメーション 738→1475→2950→5900→none Hz |
| `z` | 1 フレームだけ生で投げて中身を見る（配線確認） |

---

## 手順

### 0. 起動メッセージ

電源を入れると、**SPI を叩く前に**フレーム組み立ての自己テストが走る。

```
[self] フレーム組み立て 10 件 OK（Murata の事前計算値と一致）
```

ここが NG なら CRC かビット位置を壊している。**配線を見るのは時間の無駄なので、
先にスケッチを直す。** 期待値は Murata の BSD コードにある事前計算フレームの写し。
守れるのは「将来の編集による退行」だけで、元の読み方の誤りは検出できない。

### 1. 会話の確立

`z` を打つ。

- **全部 0x0000** … MISO が来ていない。配線・電源・CS を疑う
- **全部 0xFFFF** … MISO が Hi-Z のままプルアップに引かれている。CS が効いていない
- `crc OK` が出る … フレーム層は成立している

次に `t`。`SYS_TEST`（0x37）への書き込み／読み返しが全パターン一致すれば、
**フレーム層・CS・CRC がすべて成立している**ことの証明になる
（データシート Table 84 がこの手順を疎通確認として指定している）。

次に `i`。**`COMP_ID = 0x0023` なら SCH16T-K01**（Table 86）。`ASIC_ID` はシリコンの
リビジョンなので品種判定には使わない。部品は K01 で確定なのでスケッチは
`1600` / `3200` LSB 固定だが、`COMP_ID` は毎回見て違えば警告を出す（`i` / `r` / `m` / `h`）。

★★ **他品種はジャイロの感度だけが 16 倍違い、加速度は共通。**
だから `m` の 1g 検証では**原理的に検出できない**（`|a|/g` は 1.000 に乗る）。
ジャイロのバイアスとノイズが 1/16 に小さく出る ＝ **判断材料が都合のいい方向へ外れる。**
警告が出たら数値を使わず `G` で感度そのものを測る（根拠は下の「PX4 との相違点」）。

応答が無ければ `a` で TA を走査する。応答フレームの `SA` が要求の `TA` と
一致するかも見ている（別個体が答えていないかの確認）。

### 2. 初期化

`r`（または `R`）。`[init] SUCCESS` と `STAT_SUM = 0xFFFF (all OK)` が目標。

`STAT_SUM` の 0 のビットが異常箇所。`s` で個別レジスタを見る。
**ステータスは 2 周読まないと初期化中のラッチが残る**ので、スケッチはそうしてある。

★ **ID とシリアルの読みは CRC と CE だけで判定する。** `S1:S0` は「センサーの測定状態」で
**EOI の前は 11（初期化中）**なので、そこで弾くと起動直後の ID 読みが毎回
「フレームが壊れている」になる。`check_comp_id()` も EOI の後に置いてある。

### 3. 静止性能（本題）

水平な机に置いて動かさず `M`（60 秒）。出てくる数値と期待値:

| 項目 | データシート typ | BNO085 実測（比較対象） |
|---|---|---|
| ジャイロ バイアス | XY ±0.1 / Z ±0.01 °/s | 申告精度 0 のまま・ZRO ドリフトあり |
| ジャイロ ノイズ密度 | XY 0.0004 °/s/√Hz | — |
| 加速度 オフセット | ±0.01 m/s² | — |
| **`\|a\|/g`** | 1.000 に乗るはず | **0.985〜0.992（約 −1%）** |
| 加速度 ノイズ | — | σ = 0.0008 g（2Hz LPF 後） |

`|a|` はノルムなので**回転不変**。傾いて置いてあってもスケール誤差の比較に使える
（BNO085 側の値も同じ方法で出したもの。→ `memory/vertical-g-estimation.md`）。
★ **ただしこれが確かめているのは加速度の感度だけ。** 加速度の LSB は品種に依らないので、
`|a|/g` が 1.000 に乗ってもジャイロの裏付けには一切ならない。

ノイズ密度の欄は `sd/sqrt(fc)`（`fc` は LPF の公称カットオフ）の概算。
**`fs/2` を帯域に使ってはいけない** — 68Hz LPF を 500Hz で読むと `fs/2` は 250Hz だが
ノイズが通っているのは 68Hz 前後なので、密度が 35% ほど小さく出る。
実 ENBW は `fc` の 1.0〜1.6 倍なので真値はこの 0.8〜1.0 倍。桁が合っているかだけを見る。
`f` でフィルターを変えて sd が帯域の平方根で動くかを確認すると、測れていることの裏が取れる。

出力の冒頭に品種・感度・LPF・dec・SPI クロック・TA が全部書かれるので、
**ログだけ残しておけば後から条件が再現できる。**

★ **読み出しレートが足りないとノイズを過大評価する。**
データシート §5.5 Table 16 に LPF ごとの「最小推奨読み出しレート」がある
（LPF0 68Hz → 500Hz、LPF1 30Hz → 200Hz、LPF2 13Hz → 150Hz）。
これを下回るとフィルターの阻止域のノイズが折り返して帯域内に入る。
スケッチは実測レートをこの値と比べて警告を出す。出たら `k` で SPI を速くするか
`f` でフィルターを下げる。**バイアスと 1g スケール誤差は折り返しの影響を受けない。**

### 3.5 ジャイロ感度の実測（`G`）

★ **ジャイロのスケールを端から端まで確かめられる唯一の手段。**
1g 検証は加速度の感度しか見ていないので、`LSB_PER_DPS`・DYN ビット・20bit の符号拡張の
どれが間違っていても通ってしまう。他品種が挿さっている場合もここでしか出ない。

1. 基板を机に平らに置く（Z 軸が鉛直）
2. `G` → 案内が出たら何かキーを押す → 静止 1 秒でバイアスを取る
3. **ゆっくり**きっちり 90°（または 360°）回して止める
4. もう一度キーを押す

生の LSB を時間積分した値 `[LSB·s]` を回した角度で割れば、そのまま `LSB/(°/s)`。
角度を実測する必要はない（机の角に押し当てて 90°、一周で 360°）。
回した軸の「÷90°」か「÷360°」の列が **1600 近辺なら正しい**（K01・DYN=`010`）。
16 倍ずれていたら K01 ではない部品が挿さっている。`i` で `COMP_ID` を確認する。

最大レートが ±300°/s に近いときは速すぎる（飽和の疑い）のでやり直す。

### 4. ODR

`d`。設定どおりの周期（既定の dec=738 なら 1355µs）で DRY が立つこと。

**DRY は「出力レジスタ更新 → 最初の読み出し」の間だけ High** なので、
読まずに放置するとパルスが出ない。スケッチは読みながら数えている。

★★ **読み出しが ODR より遅いと、この値は ODR ではなく読み出しレートになる。**
更新ごとに 1 パルスではなく、読むごとに 1 パルスになるため。
`dec=NONE`(11.8kHz) や 5900Hz は 1MHz SPI では原理的に追いつかないので、
「期待値」と食い違っても故障ではない。
`DRY 回数 ≒ 読み出し回数` になったらスケッチが明示的に警告を出す。
出たら `k` で SPI を速くするか `e` で dec を落として測り直す。

`d` は初期化後でないと意味が無い（`DRY_DRV_EN` が必要）ので、未初期化だと断る。

### 5. ログ取り

`v` で CSV が流れる。ヘッダは

```
t_us,gx_dps,gy_dps,gz_dps,ax_mps2,ay_mps2,az_mps2,temp_c,ok
```

ターミナルのログ機能でファイルへ落とせば、そのまま Python で解析できる。
PONS 側の `tools/imulog/` の解析と突き合わせるならこの形式で揃える。

### 6. 温度ドリフト

電源投入直後から `M` を 10 分おきに繰り返し、温度（出力の最後）とジャイロバイアスを並べる。
BNO085 で問題になったのはここ（ZRO の温度ドリフトが GRV に効く）。

---

## 検証状況（2026-10-01 / 2026-10-05 に再確認）

**フルデータシート（Doc.No.11624 Rev.6, 65 ページ）で全件照合済み。推測で書いた箇所は無い。**

データシート §6.6 Table 27 には**実フレームの 16 進値**が載っている。
スケッチの `crc8_frame()` / `req_read()` / `reg_write()` / `build_filt()` を
そのままホストでコンパイルして突き合わせた結果:

| 照合先 | 件数 | 結果 |
|---|---|---|
| データシート Table 27 の 48bit フレーム | 41 | **全一致** |
| [smplboards-SCH16T](https://github.com/HTY2003/smplboards-SCH16T) の読み出しフレーム（48bit 全ビット） | 38 | **全一致** |
| 同・書き込みフレームの上位 40bit（`REQ_SET_*` と `REQ_SOFTRESET`） | 9 | **全一致**（2026-10-05 再照合） |

このうち代表 10 件は `selftest_frames()` に焼いて**起動時に自動照合**する。
守れるのは将来の編集による退行だけ（同じ出典から持ってきた値なので、
元の読み方の誤りは検出できない）。

先駆者のライブラリは Murata の C コード例からの移植で、CRC8・フレーム組み立て・
`SPI48_DATA_INT32`・ダミーフレーム・SPI mode 0 / 10MHz・EXTRESN の 2ms リセットまで
こちらと同一だった。フィールドマスクも一致している（`ERROR_FIELD_MASK = 0x001E00000000`
＝ ステータスビットが `[36:33]`）。

確定した内容:

| 項目 | 値 | 出典 |
|---|---|---|
| フレーム | `TA[47:38]`（上位 2bit が CS、下位 8bit がレジスタ）/ `RW[37]` / **`FT[35]`** / `DATA[27:8]` / `CRC8[7:0]` | §6.2 Table 21 |
| `FT` bit35 | **Frame Type**。次の MISO フレーム幅（1 = SPI48BF）。PX4 が常時 1 にしていたビットの正体 | §6.2 Table 21 |
| CRC8 | 多項式 0x2F（Koopman 0x97）・初期値 0xFF・XOR out なし・bit 47〜8 が対象 | §6.5 Table 25 |
| 応答 | **1 フレーム遅れる。** 「ダミー読みで前フレームの応答を受け取る」と明記 | §6.5 / Table 84 |
| ステータス | `[36]IDS [35]CE [34:33]S1:S0`。S は 00=正常 01=エラー 10=飽和 11=初期化中 | §6.4 Table 22-24 |
| 待ち時間 | NVM 読み **32ms** / EN_SENSOR 後 **215ms** / EOI 後 **3ms** | §5.2 |
| 感度（20bit） | RATE `'010'`=1600 LSB/(°/s)（K01）、ACC12 `'001'`=3200 LSB/(m/s²)、ACC3 `'000'`=1600、温度 100 LSB/°C | Table 63-65 |
| 品種判定 | **`COMP_ID` = 0x0023 が SCH16T-K01。** `ASIC_ID` はシリコンのリビジョンで品種判定には使えない | Table 85/86 |
| 温度 | 16bit 幅。20bit フィールドの**上位に詰まっている**ので `>>4` してから /100 | PX4 と Murata 由来ライブラリの両方が `SPI48_DATA_INT32(x) >> 4`。コメントも同文 |
| ステータスレジスタ | すべて 16bit で、20bit フィールドの**下位に詰まっている**（だから 0xFFFF と比較できる） | PX4 の `SPI48_DATA_UINT16` + `!= 0xFFFF` |
| レジスタ幅 | CTRL_FILT_\* 9bit / CTRL_RATE・CTRL_ACC12 15bit / CTRL_ACC3 3bit → **ベタ書きで潰せる非ゼロのリセット値ビットが無い** | PX4 の `Murata_SCH16T_registers.hpp` |
| SCK | 既定モードで **0.095〜10.5MHz**（下限がある）。25.5MHz は `MISO_HI_SPD=1` が必要 | Table 12 |

### 先駆者・PX4 との相違点（こちらが正しいと判断した箇所）

**`CTRL_USER_IF` は read-modify-write が必要。**
リセット値が 0 ではない（`FTREE_TDEL=2b10` / `MISO_SR_CTRL=1` / `DRY_SR_CTRL=1` = **0x200C**）。
PX4 は `DRY_DRV_EN`(0x0020) を素で書くので `MISO_SR_CTRL` と `DRY_SR_CTRL` を 0 に落とす
（データシートがその側を *"This option is not supported by Murata"* と明記している）。
ついでに `FTREE_TDEL` も 2.5ms → 0.078ms に変わる。
Murata 由来ライブラリの `setDRY()` は読んでから書いており、こちらもそれに合わせた（`set_dry()`）。

**PX4 の定数名は紛らわしいが値は正しい。** `RATE_RANGE_300 = 0b001` は実際には
±327.68 °/s（測定レンジ ±300）で、感度 1600 LSB/(°/s)。`ACC12_RANGE_80 = 0b001` は
±163.84 m/s²（測定レンジ ±80）で 3200 LSB/(m/s²)。値としては既定＝最も広いレンジで正しい。
なお **`'000'` は CTRL_RATE / CTRL_ACC12 では "Undefined" で書いてはいけない。**

**RATE の DYN には `'010'` を書く（`'001'` ではない）。**
両者は同じレンジだが、Murata 由来ライブラリは 1600 LSB に `'010'` を書き、逆変換
（`convertBitfieldToRateSens`）では `'001'` を未定義（0）にしている。`'010'` なら
「書いた値 → 感度」が 1 対 1 になり、`verify_sensitivity_readback()` の照合が成立する。
PX4 は `'001'` を書いて実機で動いているので、どちらでも動く。

**ベタ書きの検証は「潰していない」ことを保証しない。**
`want == got` でも、0 を書いて 0 が読めたなら非ゼロのリセット値を潰していても一致する。
幸い PX4 のヘッダのレジスタ幅から、ベタ書きしている 6 本には潰せる非ゼロのリセット値
ビットが無いと確認できた。該当するのは `CTRL_USER_IF`（対処済み）と `CTRL_ST`（未使用）だけ。

**48bit は 1 回の `SPI.transfer(tx, rx, 6)` で送る。`transfer16()` を 3 回ではない。**
arduino-pico 4.5.1 の `transfer16()` は 1 ワードごとに戻るので**ワード間で SCK が止まる**。
6 バイトの `transfer()` なら TX FIFO（8 段）へ先に積むので 48bit 連続する。

**品種が違うとジャイロ感度だけが 16 倍変わり、加速度は変わらない。**
Murata 由来ライブラリは `SCH16T_K10` クラスで `convertRateSensToBitfield` だけを上書きし
（`100/200/400` ↔ `1600/3200/6400`）、加速度側は上書きしていない。PX4 も `probe()` の
リビジョン判定でジャイロだけスケールを変えている（加速度は両方 `1/3200`）。
使うのは K01 で確定なので分岐は入れていないが、**1g 検証ではこの違いを検出できない**ため
`COMP_ID` の確認は残した。違っていたら `G` の実回転で測る。

### まだ入れていないもの

- **`CTRL_ST`（セルフテスト）。** ビット配置は判明した（Table 78。`RATE_STC_CTRL[11:9]` の
  リセット値が `3b111` など 0 でないビットがある）が、連続セルフテストの解釈に踏み込むので
  単独テストの段階では触らない。ここも read-modify-write が必要。
- `CTRL_*_FLAG_*`（飽和フラグのフィルター設定）。既定 0 のまま。

## 出典

- Murata SCH16T データシート Doc.No.11624 Rev.6（フル版・CONFIDENTIAL。社内で保管）
- [smplboards-SCH16T](https://github.com/HTY2003/smplboards-SCH16T)（Murata の C コード例からの移植）
- [PX4-Autopilot SCH16T ドライバ](https://github.com/PX4/PX4-Autopilot/tree/main/src/drivers/imu/murata/sch16t)

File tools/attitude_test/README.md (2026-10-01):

# attitude.cpp の数学を PC 上で検証する

`attitude.cpp`（機上の姿勢 ESKF）を実機に焼かずに検証するためのハーネス。
**`attitude.cpp` を変更したら必ず実行すること。** 移植ミス・符号ミスはここで捕まる。

```sh
cd tools/attitude_test
make            # 3 本ぜんぶビルドして実行する
```

## テストの中身

| | 何を見るか |
|---|---|
| `main.cpp` → `test` | **協調旋回**。合成データを流し、真のバンク角 20 度を復元できるか（許容 1.5 度） |
| `yaw_test.cpp` → `yaw_test` | **水平化・航跡ヨー・待機中の維持**（0.983 で GRV/RV 依存を外したときに追加） |
| `dead_test.cpp` → `dead_test` | **IMU 断線・未接続**。安全側（`ready=false`）に倒れるか |

`yaw_test` が見ているもの:

- **A** 加速度だけで水平化できるか（GRV なし）。上方向が測った比力と平行か。
  ヨー未設定のあいだ `yaw_acc95` が 180 度に張り付くか（表示が灰色になる条件）
- **C** ヨー未設定のあいだ GNSS 速度観測を**通さない**か
  （通すとヨー誤差がロール・ピッチへ転嫁される）
- **B** GNSS 航跡でヨーを入れると、要求方位に一致し **ロール・ピッチが動かない**か
- **D** 待機中の維持 — 0.2deg/s のジャイロオフセットで 10 分静止させてもロールが保たれるか、
  静止中に機体を傾け直したら追従するか、学習したバイアスがクランプで頭打ちになるか

旧 `decl_test.cpp`（地磁気偏角の符号）は 0.983 で**対象そのものが無くなった**ので
`yaw_test.cpp` に置き換えた（初期ヨーに地磁気を使わなくなった）。

## 仕組みと、間違えやすいところ

- `Arduino.h` は実機ヘッダの最小スタブ。`attitude.cpp` を無改造でコンパイルするために置いてある。

- ★★ **`settings.h` はこのディレクトリにもあるが、実際には使われていない。**
  `attitude.cpp` の `#include "settings.h"` は引用符形式なので、コンパイラはまず
  **attitude.cpp 自身のディレクトリ（リポジトリ直下）** を見る。Makefile の `-I.` はその後。
  （2026-10-01 に `#error` を仕込んで確認。発火しなかった）
  つまり**テストは実機と同じ定数で走っている** — それ自体は望ましい。
  **定数を変えたいときは直下の `settings.h` を直すこと。** ここを編集しても効果は無い。

- ★ **合成データはセンサー座標で渡すこと。** `attitude.cpp` はセンサー座標を受け取り、
  出力の段でマウント回転（`attitude.h` の `imu_body_euler_rad`）を掛ける。
  `main.cpp` の `body_to_sensor()` がその変換。
  以前はここで機体座標のまま流し込み、出力側の `pitch+90` で辻褄を合わせていたため、
  マウントを変えるたびにテストが偽の FAIL を出した（2026-09-22 に廃止）。
  **いまは出力ロールがそのまま機体バンク。** 式を写し取って引き算しないこと。

- PC 側の同等品は [`tools/imulog/eskf.py`](../imulog/eskf.py)。
  **同じ数式の二重実装なので、片方を直したらもう片方も必ず合わせること**（CLAUDE.md の約束）。
  0.983 では水平化（`level_toward_gravity`）・航跡ヨー（`set_heading`）・
  待機中の再水平化とバイアス学習まで両方に入れてある。

## 期待される出力（0.983 時点）

```
--- 協調旋回（旋回中のバンク復元）---
真のバンク角 : 20.00 deg
ESKF 出力ロール     : 19.34 deg  (誤差 -0.66)
結果: PASS — C++ 版も真のバンクを復元した
```

★ 誤差 0.66 度は 0.982 の 0.15 度より大きい。**これは合成データ特有の過渡**で、
このシナリオは「静止 → 直後に 25.6deg/s の旋回開始」という、ヨーを注入した瞬間に
いちばん荒い機動が始まる作り方になっている。実機の離陸は直進なので、
旋回の前に直線を 10 秒挟むと誤差は **0.00 度**になる（2026-10-01 に確認）。
許容 1.5 度に対して余裕があるのでシナリオは変えていない。

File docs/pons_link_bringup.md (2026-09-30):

# PONS Link 立ち上げ試験手順（v7 基板到着後）

無線まわりは**まだ一度も実機で動かしていない**。ソフトはコンパイルが通っているだけで、
配線・レジスタ書込み・送受のどれも未検証。ここを飛ばして飛行試験へ進まないこと。

**無線以外にも未検証のものがある。**実機で最後に通したのは 0.944 で、そのあと
BNO085 の SPI 化・MS5611 の i2c0 分離・GNSS 設定の ACK 確認・SD のフォルダ構成変更が
入っている。フェーズ A にまとめたので、**無線より先にそこを通す**こと
（起動していないのか電波が飛んでいないのか、後から切り分けるのは高くつく）。

**原則：一度に 2 つ変えない。** 症状が出たときに、どちらが原因か分からなくなる。
`EasyE220-900T22/E220_PITFALLS.md` §4 に、前回それで詰まった実例がある。

必要なもの：PONS v7 を 2 台以上、テスター、USB シリアル（`Serial` のログを見る）、
巻尺かスマホの GPS（距離の確認用）。

---

## フェーズ A：無線以外で、実機初投入になるもの（30 分）

**ハードウェアで最後に確認したのは 0.944。**それ以降に無線以外でも大きく変わっており、
どれも v7 基板では一度も動かしていない。無線の前に、ここが通ることを先に確かめる。
無線が動かないときの切り分けが楽になる（「そもそも起動していない」を除外できる）。

確認はほぼ SD の `/log.txt` で足りる。**起動直後の 20 行ほどを読むだけ**で、
センサー 3 つと GNSS 設定の成否がすべて分かるようになっている。

### A-1 BNO085 が SPI で動くか（★ 0.950 で I2C から変更。一度も通電していない）

| # | 確認 | 合格 |
|---|---|---|
| A-1-1 | **JP1 が 2-3（GND）** か。＝ PS1=0（I2C） | BNO085 は i2c1 固定（0.976）。**HIGH ではない** |
| A-1-2 | `log.txt` に `BNO085 init OK` | 失敗時は `BNO085 begin FAILED (SPI1) stage=…` が出る。**`stage` で切り分ける**（下記） |
| A-1-3 | `VARIO: BNO085+MS5611 Kalman fusion enabled` | 片方だけなら該当センサーが見えていない |
| A-1-4 | 60 秒ごとの `rate GRV=15.0 LACC=15.0 RV=5.0 MS5611=…` | 設定値より低ければ配信飢餓。バリオが暴れる原因になる |
| A-1-5 | `BNO085 enableReport aborted at … (slow bus)` が**出ない**こと | 出たら SPI の信号品質を疑う（配線長・GND） |
| A-1-6 | IMU 詳細画面でロール・ピッチが手の動きに追従するか | 符号と軸の向きも一緒に確認する |

**`begin FAILED` が出たときの読み方**

`stage=1(no-INT)` … H_INTN が一度もアサートされなかった。**SPI のデータ線はまだ無関係。**
BNO085 がそもそもブートしていないか、SPI モードで起動していない。疑う順は
**JP1(PS1) の位置 → 3V3 → NRST(GPIO46) → 半田**。
PS1=0 のまま PS0=1 だと **UART モード**で起動し、H_INTN は永久に来ない。

`stage=2(no-SHTP)` … INT は来たので**チップは生きていて SPI モードにいる**。
`sh2_open()` / `getProdIds()` が通らないので、**MISO/MOSI/SCK/CS の配線か接触**を疑う。
GPIO41=CS / 42=SCK / 43=MOSI / 44=MISO。MISO と MOSI の入れ違いが定番。

同じ行に `INT= RST= PS0=` の実測値も出る。正常なら RST=1、PS0 は 0（WAKE 保持）。

> **既知：基板に H_CSN(GPIO41) のプルアップが無い。**そのためソフトが
> NRST を打つ前に CS を HIGH で駆動している（`imu_bus_select_protocol()`）。
> これを外すと、リセット〜ブートの 400ms の間 CS が浮いて **BNO085 が起動しない**
> （v7 の初回通電で実際に踏んだ症状が `stage=1(no-INT)`）。
> **次の基板改訂で 10k プルアップを入れること。**

**わざと外して確かめる（ここが今回いちばん危ない変更）**

- **BNO085 を外して電源を入れる。** 画面が真っ暗のまま固まらず、**1.7 秒ほどで
  起動が進む**こと。固まるならライブラリの無限ループに落ちている
  （ライブラリの `sh2_*` は全オペレーションがタイムアウト無限なので、
  ソフト側の INT 生存確認だけが頼り）。
- 飛行中を模して、動作中に BNO085 の電源を抜く。`[IMU] BNO085 comm timeout` →
  1 分後に `[IMU] BNO085 recovery FAILED (no INT)` が出て、**地図が止まらない**こと。
- 戻すと `[IMU] BNO085 recovery OK` で復帰するか。
- **デバッグビルド（`RELEASE` を外す）でも起動が最後まで通るか。**
  そちらだけ `sh2_getMetadata()` を呼ぶので、通れば SPI が安定している証拠になる
  （`ACCEL meta range=… res=…` が出る）。ここで固まるなら信号品質が足りていない。

### A-2 MS5611（i2c0 単独・400kHz。v7 で BNO085 と分離）

| # | 確認 | 合格 |
|---|---|---|
| A-2-1 | `MS5611 init OK` | `MS5611 not found` なら i2c0(GPIO32/33) の配線 |
| A-2-2 | `MS5611 PROM CRC NG (calc n want m)` が**出ない**こと | 出たら係数が化けている。プルアップとバス長を疑う |
| A-2-3 | `Initial airdata: Temp=… Press=… Alt=…` が妥当な値か | 気温が室温、気圧が 1000hPa 前後 |
| A-2-4 | 机から持ち上げてバリオが鳴るか | 上昇=断続ビープ / 下降=連続低音 |

**わざと外して確かめる（気圧センサー 1 個の不調が音響警報を全停止させていた経路）**

- 動作中に MS5611 の SDA を外す。数秒で `MS5611 lost (I2C). airdata disabled, will retry`
  が出て、**その後もバンク角警告やコース警報が鳴り続ける**こと。
  鳴らなくなったらタスクキューが溢れている（この修正が効いていない）。
- 戻すと 30 秒以内に `MS5611 recovered` が出て、バリオが復活するか。

### A-3 GNSS の設定が通っているか（0.964 で追加。**起動直後の 1 行を見るだけ**）

| ログ | 意味 |
|---|---|
| `GNSS CFG OK 2Hz/PVT/SAT/DOP/Air1g (prt=ack)` | 5 つとも通った。正常 |
| `GNSS CFG NO ACK: RATE2HZ …` | 測位レートが 1Hz のまま。ログ密度も旋回角速度も半分になる |
| `GNSS CFG NO ACK: … AIRBORNE1G` | **動的モデルが地上のまま飛ぶ。**症状は「方位の追従が鈍い」だけで画面に出ない |

`prt=none` は正常なこともある（CFG-PRT の ACK は旧ボーレートで返るため）。

### A-4 SD のレイアウト変更（0.961 で `data/` `received/` へ整理）

- 飛行 CSV が **`data/YYYY-MM-DD_HHMM.csv`** にできるか（ルート直下ではない）
- リプレイ選択画面の `SOURCE` を切り替えて、`data/` と `received/` の両方が見えるか
- ~~WAV を 1 つリネームして起動する~~ … 0.982 で音声を本体 FLASH へ移したので
  この確認は無効（SD に `wav/` は無い）。代わりに **SD を抜いて起動し、
  `opening.wav` が鳴ること**と **500Hz×10 の SD エラービープが重なって鳴ること**を見る。
- **デバッグビルドで `!!! SD access from Core0` と
  `!!! Core1-only function called from Core0` がシリアルに出ない**こと
  （出たら Core1 専用の約束が破れている。前者は SDIO バスハング、
  後者は再生バッファの破壊につながる）

### A-5 画面が収まっているか（★ 実機でしか分からない。項目が増えている）

| # | 確認 |
|---|---|
| A-5-1 | **設定画面の `Save & Exit` が切れていないか。** 15 項目 × 16px = 240px でちょうど。長らく保留になっていた確認 |
| A-5-2 | WIRELESS 画面の `Return` が見えるか（`Preflight: re-run` を足して 1 行増えた） |
| A-5-3 | WIRELESS 画面の `SF : 11  (600ms 60%)` と `Noise : -104 dBm  mgn +15dB` の右端が切れていないか（どちらも今回追加した情報で行が伸びた） |

### A-6 警報まわり（0.963〜0.967 で動きが変わった）

- **地図画面以外でも警報が鳴るか。** 設定画面を出したままにして、コース警報・
  旋回音が鳴ること（0.965 で発報を `loop()` 最上位へ移した）。
- **設定画面を 3 分放置すると地図へ戻る**か。別れの音声が鳴り、
  `SETTING SCREEN TIMEOUT -> MAP (180s idle)` がログに出る。
- **ESKF 較正のやり直し要求。** マウントから外して戻すと
  `ESKF CALIBRATION REQUIRED!` が **3 秒に 1 秒だけ点滅**し、ヘッダの `Pavg` に
  **赤い横バー**が重なるか。地上で静止していれば 120 秒ごとに
  `eskf_calib_required.wav` が鳴り、`ESKF CALIBRATION REQUIRED (on ground)` が残る。
  **持ち歩いている間（静止していない）は鳴らない**こと。
- **音量 0 の確認。** 設定で音量を 0 にしても `battery_low.wav` は鳴る（最低保証音量 60）。
  一方で**無線の警告は鳴らなくなる**こと（0.965 で電池切れ以外から外した）。

---

## フェーズ 0：通電前（15 分）

モジュールを壊してからでは遅いので、電源を入れる前に済ませる。

| # | 確認 | 合格 |
|---|---|---|
| 0-1 | E220 の VDD と GND がショートしていないか | テスターで数 kΩ 以上 |
| 0-2 | **VCC（7番）が開放**か | 導通なし。VDD と繋いでいたら剥がす |
| 0-3 | M0/M1 が結線されて 1 本になっているか | 導通あり |
| 0-4 | M0/M1 が **GPIO41** に繋がっているか | i2c1 固定なので 41。0Ω（R50/R52）の実装と一致すること。`R53` は外す（H_CSN と切る） |
| 0-5 | AUX が GPIO30 に来ているか | 導通あり |
| 0-6 | TX/RX が交差しているか（RP の TX=GPIO8 → E220 の RXD） | 入れ替わりは一番よくある間違い |
| 0-7 | アンテナ（IPEX）が挿さっているか | **アンテナ無しで送信しない。** モジュールを壊す |

> 0-4 を間違えると、BNO085 の I2C クロック線を無線のモード切替で叩くことになる。

---

## フェーズ 1：モジュールが応答するか（1 台・10 分）

無線設定画面（設定 → WIRELESS）を開く。

1. `link_mode` を **OFF のまま**、電源投入。
2. 画面の `Module` を見る。

| 表示 | 意味 | 次にすること |
|---|---|---|
| `Module : OK` | 設定の書込みと読み返しが一致した。**配線は正しい** | フェーズ 2 へ |
| `Module : NO RESPONSE` | 応答なし | 下の切り分けへ |

### NO RESPONSE のときの切り分け

`e220_setup()` は「mode 3 へ入る → 9600 で読む → 書く → 読み返す」の順に動く。
どこで落ちているかは `Serial` のログと、次の順で切り分ける。

1. **AUX の実測。** テスターで GPIO30 を見る。アイドルなら 3.3V。
   0V に張り付いていたら、配線ミスかモジュール不在。
   ソフトは内部プルアップを入れてあるので、**未接続なら 3.3V に見える**はず。
   0V ならモジュールが繋がっていて、かつビジーだということ。
2. **M0/M1 の電圧。** 起動直後は mode 3（HIGH）のはず。
3. **TX/RX の入れ替わり。** 0-6 をもう一度。
4. 起動時の `LINK ERROR: radio module not responding` が SD のシステムログに出ているか。

---

## フェーズ 2：環境ノイズ（1 台・10 分）

**送信する前に、その場所が静かかを測る。** ここで雑音が高ければ、
あとで距離が出なくても地形のせいなのかノイズのせいなのか切り分けられる。

1. `link_mode` を **RX** にする。
2. 無線設定画面の `Noise` を読む。

| 値 | 判断 |
|---|---|
| −100 〜 −110 dBm | 正常。熱雑音 +数 dB で、実測どおり |
| −90 dBm 前後 | 何かが出ている。Wi-SUN スマートメーターなど。CH を変えて比べる |
| `---` | 取得できていない。**REG3 bit6 が 1（固定送信）になっている疑い**（→ 仕様書 §6） |

3. **CH を 0〜12 まで回して、一番静かな CH を控える。** 本番でその CH を使う。
   1 CH あたり数秒でよい。

> ★ このとき `Rx/Miss` が増えないことも確認する。増えるなら、
> 近くに別の PONS が送信している。

---

## フェーズ 2.5：送信前チェック（2 台以上・15 分）

**送信モードに入ると、送り始める前に 3 秒間チャンネルを聴く**（仕様書 §5）。
ここが正しく動くかを、電波が届く机の上で確かめる。

> **測り直したいときは WIRELESS 画面の `Preflight: re-run` を長押しする。**
> アンテナの向きや置き場所を変えながら何度も測るための入口で、
> CH を変えて戻す遠回りは不要。TX 以外では低い音（440Hz）で断られる。

1. フェーズ 2 で**一番静かだった CH** を選び、`link_mode` を **TX** にする。
   地図に `CHECKING CHANNEL... 3s` が出て、送信アイコンが**橙の弧 1 本**になるか。
   **赤い×が出たら NG**（点検中を「送れていない」と誤表示している）。
2. 3 秒後に**上昇 2 音**が鳴り、WIRELESS 画面が `Preflt : OK (-104 dBm)` になるか。
   直後から `Sent` が 1 秒ごとに増え始めるか。

| 結果 | 判断 |
|---|---|
| `OK` ＋ 上昇 2 音 | 正常 |
| `NOT MEASURED` ＋ 低い 2 音 | 雑音が取れていない。**REG3 の RSSI バイトを疑う**（→ フェーズ 2 の `---`） |
| `NOISY` | その CH は使わない。フェーズ 2 の測定と合っているか確かめる |

### わざと失敗させて、検出できることを確かめる

**★ ここが本番。**「送信機が 2 台いる」は、通常運転では受信機しか検出できない。
このチェックだけが送信機側でそれを確かめられるので、必ず動作を見ておくこと。

- **同じグループの送信機** … 3 台目を**同じ CH・SF・Group** で TX にしてから、
  本機を TX に切り替える。WIRELESS 画面が `Preflt : DUP SENDER -96dBm` になり
  `link_ch_busy.wav` が鳴るか。地図にも `ANOTHER SENDER` / `ON THIS CHANNEL !!`
  の 2 行が出るか。**確認したら必ず戻す。**
- **別グループの PONS** … 3 台目の Group だけ変えて同じことをする。
  `Preflt : PONS grp3 -96dBm` になるか。上と**別の表示になる**こと（対処が違うため）。
- **雑音の高い CH** … フェーズ 2 で −90dBm 前後だった CH を選んで TX にする。
  `NOISY` と `link_ch_noisy.wav` が出るか。

### 受信機側でも「送信機 2 台」を検出できることを確かめる

上は**送信機側**（飛ぶ前の点検）での検出。飛行中に検出できるのは**受信機だけ**なので、
そちらも見ておくこと。

1. 送信機 2 台を**同じ CH・SF・Group** で TX にし、3 台目を RX にする。
2. 受信機の地図に `DUP SENDER !! / 2 TX ON SAME CH/GROUP` の赤いポップアップが出るか。
   `link_dup_sender.wav` が鳴るか（聞き逃しても 1 分後にまた鳴る）。
3. `log.txt` に `LINK ERROR: another sender detected (seq went backwards N times)` が残るか。
   60 秒レポートの末尾が ` DUP_SENDER` になるか。
4. **送信機 1 台を止める。30 秒でポップアップが消えるか**
   （消えなければラッチが残っている＝再起動しないと確認できない状態に戻っている）。
- **設定変更で再実行** … TX のまま WIRELESS 画面で CH を変える。
  その場でチェックが走り直すか（`checking... 5s` に戻る）。
- **モジュール無応答** … E220 を**通電したまま外して** TX にする。1 秒以内に
  `NOT MEASURED` で終わり、**地図の更新が飛ばない**こと。
  ★ このとき `e220_alive()` はまだ OK のままである（照合は起動時にしか走らない）。
  つまり事前チェックを素通りして実際に測りに行く経路を通る。連続 2 回の失敗で
  打ち切る作りになっていないと、ここで Core0 が 2 秒止まって GNSS を取りこぼす。
  外したまま 30 秒ほど置くと、生存確認が効いて `Module : NO RESPONSE` になり、
  `link_no_module.wav` が鳴り、地図のアイコンが**赤い×**になるか。

### 落とし穴

- **警告が出ても送信は止まらない。** これは仕様（仕様書 §5）。
  警告のあと `Sent` が増え続けることを必ず確認する。増えないなら実装が誤って
  送信を止めている。予備機を緊急で載せ替える場面で送信が始まらないのが一番危険。
- 点検中は**送信していない**。この 3 秒間はボート側が `NO SIGNAL` のままでよい。

---

## フェーズ 3：2 台で送受（20 分）

**机の上、1〜2m 離して**行う。ここで動かなければ屋外へ出ても意味がない。

1. 1 台を **TX**、もう 1 台を **RX**。**CH・SF・Group の 3 つを全部そろえる**
   （1 つでも違うと受からない）。Group は既定 0 のままでもここでは動く。
2. TX 側の地図画面：飛行機アイコンの左に**電波の弧**が出て、**1 秒に 1 回膨らむ**か。
   膨らまない＝送れていない。無線設定画面の `Sent` が増えているかも見る。
3. RX 側の地図画面：**枠がティール**になり、**アンテナが 3 本**立つか。
4. RX 側の無線設定画面：

| 項目 | 期待 |
|---|---|
| `Signal` | 至近なので −40 〜 −60 dBm、`3/3` |
| `Rx/Miss` | Rx が 1 秒に 1 ずつ増える。**Miss は増えない** |
| `Sender` | `OK`（機体側の SD/IMU が正常なら） |

5. RX 側の画面が TX 側と**同じ値**になっているか（対地速度・高度・気圧・電圧）。
6. TX の電源を切る → **10 秒後**に「RECEIVER MODE. NO SIGNAL.」が出て、
   アンテナが**0 本＋赤い×**になり、枠が**赤**に変わるか。音声も鳴るか。
7. TX を戻す → 復帰音が鳴り、枠がティールに戻るか。

### ここで確認しておきたい落とし穴

- **無線設定画面を開いたまま** `Rx/Miss` が正常に増え続けるか。
  （環境ノイズの問い合わせと受信が同じ UART を共有しているため。
  ここが止まるなら受信バッファの扱いに問題が残っている）
- CH または SF を**片方だけ**変えて、**受からなくなる**ことを確認する。
  受かってしまうなら設定がモジュールに入っていない。
- **Group を片方だけ変える。** 受信側が `Signal : GROUP n FOUND` になることを確認する。
  ここが `searching...` のままなら、グループ違いを無信号と区別できていない
  （SD が飛んで 0 に戻った事故に気づけなくなる）。確認したら戻す。
- ★ **送信中に TX 側のモジュールだけを外す**（本体の電源は入れたまま）。
  一番危険な壊れ方の再現なので必ず見ておくこと。
  - 30 秒以内に TX 側が `Module : NO RESPONSE` になり、`link_no_module.wav` が鳴り、
    地図の電波アイコンが**赤い×**になるか。
  - ここが「弧が脈動したまま」なら生存確認が効いていない。**画面上は正常なまま
    電波が出ていない**状態になり、上りが無いので機体側では永久に気づけない
    （仕様書 §5「モジュールの生存確認」）。
  - このとき**地図の更新が飛ばない**こと。無応答の問い合わせで Core0 が止まると
    GNSS を取りこぼす。
  - 戻すと 10 秒以内に `OK` へ復帰し、RX 側の `Rx` がまた増え始めるか。
- **設定を変えて WIRELESS 画面を出たとき、音声が鳴る**ことを確認する
  （`wav/link_setting_changed.wav`。0.982 以降は FLASH にあるので SD の有無に関係なく鳴る）。
  **送信機・受信機の両方で鳴ること。** 受信機で鳴らないなら実装がモード依存になっている。
- 3 台目を **TX** にして電源を入れ、RX 側の地図に
  `DUP SENDER !!` / `2 TX ON SAME CH/GROUP` の赤いポップアップと
  `link_dup_sender.wav` が出るか。**確認したら必ず戻す。**
  （詳しい手順はフェーズ 2.5 の「受信機側でも『送信機 2 台』を検出できることを確かめる」）

---

## フェーズ 4：SD ログ（10 分）

RX 側の SD を抜いて中身を見る。

- `received/YYYY-MM-DD_HHMM.csv` ができているか
- 列が `…,rssi,seq,age_ms,roll,pitch,yaw,pitch_avg,roll_trim,yaw_acc95,wind_mps,wind_dir`
- `seq` が 1 ずつ増えているか（飛んでいたら電波側で落ちている）
- グループ違いの機体のデータが**混ざっていない**か（フェーズ 3 で Group を試した区間）
- **姿勢が入っているか。** 空欄なら送信側の ESKF が収束していない
- 風の列は屋内では空欄でよい（推定できていないため）
- システムログに 60 秒ごとの `LINK RX: …` が出ているか

---

## フェーズ 5：屋外・距離（半日）

**ここから先はアンテナの置き方が SF より効く。** 偏波が 60° ずれるだけで 6dB 落ちる
（SF を 1 段上げても 2.5dB）。まずアンテナの向きを決めてから距離を測ること。

1. **見通しの良い平坦な場所**で、両方のアンテナを**同じ向き**に立てる。
2. 50m ごとに離れながら、RX 側の `Signal`（10 秒平均）と `Rx/Miss` を記録する。
3. **アンテナを 90° 倒して**同じ地点で測り直す。落ち幅を記録する。
   → ケース設計でアンテナをどう固定すべきかの根拠になる。
4. パケットが落ち始めた距離と、そのときの RSSI を記録する。

| 記録する項目 |
|---|
| 距離 / `Signal`(10秒平均) / アンテナ本数 / `Rx/Miss` / アンテナの向き / 地面の様子 |

### 合格ライン

- **200m で `Miss` がほとんど増えない**こと（要求距離）
- 350m 付近で落ち始めるなら、前回の実測（海辺・SF7）と整合する

### SF8 か SF10 かの判断

先に基準を決めておく。**距離が足りているなら SF8 のまま**にする。

| 200m での結果 | 判断 |
|---|---|
| `Miss` がほぼ 0、アンテナ 2〜3 本 | **SF8 で確定。**上げる理由が無い |
| `Miss` が数 % 出る、1 本 | まずアンテナの向き・高さを直す。それでも駄目なら SF10 |
| 全く届かない | SF ではなく配線・設定・アンテナを疑う。SF で 5dB 稼いでも足りない差 |

SF10 にすると平均電流が 4.3mA → 約 14.7mA、電波占有率が 10% → 34% になる。
**得られるのは 2.5dB × 2 段 = 5dB（距離にして 1.3〜1.8 倍）だけ**であることを
忘れないこと。同じ 5dB は、アンテナの向きを直すか高さを 2 倍にすれば無料で手に入る。

---

## フェーズ 6：水面（未実施・要計画）

過去の試験はコンクリートと芝生だけ。**水面の反射は未確認**（仕様書 §9）。

- 低いアンテナ同士では、ある距離から先は損失が距離の 2 乗ではなく **4 乗**で増える
- 受信電力は `(h1×h2)²` に比例する。**1m/1m → 2m/2m で +12dB**
- **プラットフォームは 10m ある。** アンテナを最上部に出すだけで最大の効果が無料で得られる
- ボート側のアンテナも、できるだけ高く・機体と同じ偏波で

---

## 本番前チェックリスト（3 台）

| | 機体 | 追走ボート | プラットフォーム |
|---|---|---|---|
| `link_mode` | **TX** | RX | RX（途中で OFF にする） |
| `link_radio_ch` | フェーズ 2 で決めた CH。**3 台とも同じ** | 同左 | 同左 |
| `link_radio_prof` | フェーズ 5 で決めた SF。**3 台とも同じ** | 同左 | 同左 |
| `link_group` | **0 以外**。3 台とも同じ | 同左 | 同左 |
| 起動時の音声 | 「送信機モード」 | 「受信機モード」 | 「受信機モード」 |
| 目的地・ナビモード | ここが正 | 自動で機体に合う | 自動で機体に合う |

- **`link_mode` が TX の機体が 2 台無いこと。** 起動音声で 3 台ぶん確認する
- **`link_group` を 0 以外にすること。** 0 のままだと、同じ会場の他チームの PONS が
  同じ CH/SF だった場合に**他機の飛行をミラーし、`received/` にも他機のログが残る**。
  3 台とも同じ値であることを WIRELESS 画面で 1 台ずつ目視確認する
  （値は SD の `settings.txt` にだけ書く。git には既定 0 しか入っていない）
- プラットフォーム機は**予備機**。機体の PONS が壊れたら TX へ切り替えて載せ替える
- **3 台とも、起動直後の `log.txt` を 1 度は見ておく。**`BNO085 init OK` / `MS5611 init OK` /
  `GNSS CFG OK 2Hz/PVT/SAT/DOP/Air1g` の 3 行が揃っていること（フェーズ A）。
  ここが欠けていても画面には出ないまま飛べてしまう
- 電池はどれも満充電。受信機は +8.2mA で 1 時間ぶん短くなる

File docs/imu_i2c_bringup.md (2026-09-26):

# BNO085（i2c1）の手引き

対象: PONS v7 / 0.976 以降。

**0.976 で SPI 対応を削除し、i2c1 固定にした。**「触るとジャイロが化ける」現象
（触診で約 0.8 件/分、`gx=+v gy=-v gz=-v` の署名）が **SPI でしか起きず、I2C では
一度も再現しなかった**ため。SPI に戻す必要が出たら 0.975 の `imu.cpp` / `settings.h`。

この文書は 0.944（i2c0 + ブレイクアウト）との差と、v7 の i2c1 で踏んだ落とし穴の記録。

---

## 0. 前提 — 0.944 の「I2C で動いていた」は今とは別物

0.944 を根拠に「I2C なら動くはず」と考えないこと。**共通しているのは
`begin_I2C()` を呼ぶことだけ**で、ハードウェアもバスもアドレスの決め方も違う。

| | 0.944 | 現在 (0.975) |
|---|---|---|
| 実装 | GY-BNO080 ブレイクアウト | **v7 自作基板のベア IC** |
| バス | i2c0 `GPIO32/33` — **MS5611 と共用** | **i2c1 `GPIO34/35` — BNO085 専用** |
| クロック | 400kHz（`airdata_setup()` が設定済み） | 400kHz（`imu_setup()` が独立に `begin()`/`setClock()`） |
| アドレス | 0x4B（モジュール側で strap） | 0x4B（**MCU が `GPIO43`=SA0 を HIGH 駆動**） |
| プロトコル選択 | モジュール側で固定 | **PS1 = JP1 を GND、PS0 = `GPIO47` を LOW** |
| H_INTN | `IMU_INT_PIN -1`（未接続） | `GPIO45`。**I2C では読まない**（プルアップだけ入れる） |
| H_CSN | 無し | **基板上で未接続**（`R53` 外し。I2C では don't care） |
| 旧 SPI1 の SCK/MISO | 無し | **`GPIO42`/`GPIO44` が I2C バスとショート。`INPUT_PULLUP` で停める**（§4.2） |
| リトライ | `begin_I2C()` を 5 回（間に `delay(200)`） | **3 回。毎回 NRST を打ち直す** |

**バス分離の効果**: 0.944 は i2c0 を MS5611 と共用していたので、生レポートの
バス占有率（約 20%）が MS5611 の読み出しと競合していた。現在は i2c1 が専用なので、
**MS5611 のレートと BNO085 のレートは互いに影響しない**。

---

## 1. ソフトウェアの挙動の差（I2C 経路）

### 1.1 レポートの引き取り方が変わった

| | 0.944 | 現在 |
|---|---|---|
| 呼び出し | `imu_update()` が `sh2_service()` を **1 回** | `imu_service_if_due()` に集約 |
| 周期 | `IMU_POLL_INTERVAL_US` = 4ms | 同じ 4ms |
| 1 回の排出量 | 1 パケット | **最大 8 パケット**（`IMU_DRAIN_MAX_PACKETS`） |
| 呼ばれる場所 | `loop()` だけ | `loop()` ＋ **長いブロッキング処理の中から**（地図描画・E220 の待ち・起動画面の各待ち） |

`sh2_service()` は 1 回で 1 パケットしか処理しない（`shtp_service()` はループしない）。
0.944 は 4ms に 1 パケットしか掃けず、ブロックのあとで追いつけなかった。

**I2C 固有の打ち切り条件**: SPI は H_INTN で「まだ溜まっているか」が分かるが、
I2C では分からないので `_report_count == 0` で打ち切る。
→ **副作用**: advertisement やコマンド応答だけを処理した回はレポート数が 0 になるので、
まだ溜まっていても打ち切る。次の 4ms で拾うので実害は無いが、SPI と挙動が違う。

### 1.2 通信途絶の検出 — しきい値は同じ、ガードが増えた

しきい値は 0.944 も現在も **1 秒**（`imu_update()` 内）。
現在は手前に**呼び出し間隔のガード**がある:

> `imu_update()` の呼び出し間隔が 500ms 以上空いていたら、その回の判定を見送る。

これが無いと「データが来ない」と「こちらが見ていなかった」を区別できず、
**生きている BNO085 をリセットしに行って殺す**。2026-09-23 に SPI で実際に起きた。

### 1.3 復旧 — **0.944 の復旧も壊れていた。ただし一度も発火していなかった**

0.944 の `imu_try_recovery()` は NRST を打って `begin_I2C()` を呼び直すが、
`sh2_close()` を呼んでいない。取り込んだ SH-2 ドライバの SHTP インスタンスプールは
`MAX_INSTANCES=1` で空き判定が `pHal == 0`、それを 0 に戻すのは `shtp_close()` だけ。
**つまり 0.944 でも 2 回目の `begin_I2C()` は必ず失敗する。**

0.944 でこれが露見しなかったのは、`_last_sensor_event_ms` が
**`setup()` の間ずっと 0 のままだった**ため。途絶判定は
`_last_sensor_event_ms > 0` が条件なので、`loop()` の 1 回目では発火せず、
そこで初めてレポートが届いて時刻が入る。誤発報の入口が無かった。

現在は `sh2_close()` を `imu_bus_begin()` の冒頭で呼ぶので**復旧が実際に成功する**
（SPI で検証済み: `recovery OK (INT wait 12ms)`）。
I2C でも同じコードを通る。

| | 0.944 | 現在 |
|---|---|---|
| 形 | **ブロッキング**（NRST + 400ms で Core0 が 410ms 止まる） | 状態機械（`imu_reset_start()`/`imu_reset_poll()`。1 ループも止めない） |
| `sh2_close()` | **無し → 必ず失敗** | あり |
| 生存確認 | 無し | `begin_I2C()` の中の `detected()` が果たす（**自前で二重に探査しないこと**。§5.5） |
| 失敗ログ | `recovery FAILED` だけ | `FAILED (stage=N(no-ACK/no-SHTP) init_step=N sh2=N)` |

### 1.4 バスと初期化の順序（現在）

```
imu_bus_select_protocol()   PS0=LOW（プロトコル選択）/ SA0=GPIO43 を HIGH（0x4B）
                            H_INTN=GPIO45 と GPIO42/44 を INPUT_PULLUP（§4.2）
                            ★ GPIO41 は触らない（E220 の M0/M1 専用）
imuWire.begin() / setClock(400k)
imu_reset_blocking()        NRST を LOW→HIGH、ブート 400ms 待ち
[3 回まで] begin_I2C() → 失敗ならバス復旧 + NRST を打ち直して再試行
imu_enable_reports()        レート設定は settings.h に一元化
sh2_getCalConfig / setCalConfig(ACCEL|GYRO|MAG)
```

**PS1/PS0 はリセット時にラッチされる**ので、この順序を崩さないこと。

### 1.5 バスに関係なく変わったもの（I2C でも効く）

- **クォータニオンの健全性チェック** `quat_sane()`: `|q|²` が 1±0.02 を外れた GRV/RV を
  採用しない。カウンタは `quat grvbad= grvjump= rvbad=`。
  `grvjump` は**捨てずに数えるだけ**（速い手振りでも起こるため）。
- **校正設定**: `sh2_setCalConfig(ACCEL|GYRO|MAG)` を起動時に揃える。
  0.944 は触っていなかった（`calcfg=0x05`＝mag のみ＋accel のまま）。
  ログは `cal cfg=0x07 acc= gyr= mag=`。
- **DCD 保存**: 起動から 20 秒経過し精度 3 に達したとき 1 回だけ `sh2_saveDcdAndReset()`。
- **マウント補正**: 0.944 は Euler の組み替え（`display_roll = sensor_pitch` 等）。
  現在は**クォータニオン回転** `IMU_MOUNT_Q*`。v7 は IC が基板裏面・1 番ピンが天で、
  機体水平時にセンサーがジンバルロックに入るため、Euler では原理的に直らない。
  **この 4 つの値は v7 基板で実測したもので、SPI/I2C で共通。**
- **ESKF**: ヨー分散に上限（1σ=180 度）、自動ロールトリムに GNSS 速度の鮮度ゲート。

---

## 2. 取り込みライブラリの改変 — I2C への影響

`src/bno08x/PONS_VENDORING.md` の一覧を I2C の観点で読み替えたもの。

| 改変 | I2C への影響 |
|---|---|
| (1) `spihal_wait_for_int()` の待ちの粒度 | **0.976 で上流へ戻した**（SPI HAL のみで死んでいたため） |
| (2) `pons_pkt_max` / `toobig` / `hdr_change` カウンタ | **0.976 で撤去**（`spihal_read()` の中だけで、i2c1 では常に 0 だった） |
| (3) `sh2_hal.h` の受信バッファ 384 → 768 | **効く。** `shtp.c` の `inPayload[]`/`inTransfer[]` は共有。RAM +768B |
| (4) `pons_init_fail_step` / `pons_init_fail_status` | **効く。** `_init()` のどこで落ちたかが分かる |
| (5) `sh2_close()`（PONS 側の回避） | **効く。** これが無いと復旧が必ず失敗する |

> ### ★ 60 秒ログの `spi pktmax=...` は 0.976 で削除した
> あれは `spihal_read()` でしか更新されず、i2c1 では常に 0 だった。
> 「0 だから健全」と誤読されるだけなので外し、`imu gapmax=` だけ残した。
> I2C で同じことを知りたければ `i2chal_read()` にカウンタを足す必要がある。

> ### ★ `packet_size > len` の取りこぼしは I2C にもある
> `i2chal_read()` も上流のまま `return 0` で**パケットを排出せずに諦める**。
> バッファを 768 に広げて当たりにくくしただけで、構造は残っている。
> ただし I2C では INT を見ずにポーリングしているので、詰まると
> `_report_count == 0` が続いて 1 秒で途絶判定 → 復旧（今は成功する）に入る。
> **I2C ではカウンタが無いので、症状は「時々 recovery が走る」としてしか見えない。**

---

## 3. 標準の Adafruit ライブラリに戻したらどうなるか（I2C）

### 3.1 まずビルドが通らない（2 箇所）

| 箇所 | 参照しているもの |
|---|---|
| `imu.cpp` `imu_bus_begin()` | `pons_init_fail_step`（`sh2_close()` の要否判定に**使っている**） |
| ~~`GPS_TFT_map.ino` の 60 秒ログ~~ | 0.976 で `pons_pkt_*` の参照を削除したので、もう問題にならない |

前者は単なるログ用ではない。`sh2_open()` まで通って `getProdIds()` で落ちた場合も
SHTP インスタンスは取られているので、そこを区別しないと次回 `sh2_close()` を
呼び忘れる。**消すなら代わりの判定を用意すること。**

### 3.2 受信バッファが 384 に戻る

`i2chal_read()` は `packet_size > len` で捨てる。SPI で実測した最大パケットは
**276 バイト**（`pktmax=276`。同じレポート構成なら SHTP パケットは I2C でも同じ）。
384 でも即座に破綻はしないが余裕が 108 バイトしかない。
レートを上げる・レポートを増やすと当たりに近づく。

### 3.3 残るもの / 戻るもの

- **`sh2_close()` の復旧修正は `imu.cpp` 側なので残る。** ライブラリを戻しても復旧は動く。
- `spihal_wait_for_int()` のレート低下対策は SPI 専用なので I2C には関係ない。

### 3.4 include の書き方に注意

`imu.cpp` は `#include "src/bno08x/Adafruit_BNO08x.h"` と**相対パス**で書いてある。
`<Adafruit_BNO08x.h>` と山括弧に戻すと、インストール済みのライブラリを拾い、
**ローカル改変が効かないまま静かにビルドが通る**（CLAUDE.md）。
戻すなら意図して戻すこと。

---

## 4. I2C でテストする前のチェックリスト

### 4.1 ハードウェア

- [ ] **JP1（PS1）を 2-3（GND）へ**。1-2（+3V3）から変更する。
      ★ **I2C は PS1=0。HIGH ではない。** 取り違えるとラッチされて起動しない。
- [ ] **R46 / R47（0Ω）を実装**して H_SCL / H_SDA を i2c1（`GPIO34/35`）へ繋ぐ。
- [x] **i2c1 の外部プルアップ 4.7kΩ（`GPIO34/35`）** — 実装済み（2026-09-27 確認）。
- [x] **`R53` は外してある** → `GPIO41` は H_CSN と切れ、**E220 の M0/M1 専用**。
      BNO085 の H_CSN は基板上で未接続（I2C では don't care）。

### 4.2 ソフトウェア（すでに入っている。確認だけ）

- [x] **`GPIO42` / `GPIO44` を `INPUT_PULLUP` で停める**（`imu_bus_park_unused_pins()`）。
      **High-Z のまま放置してはいけない。** R46/R47 で H_SCL/H_SDA に繋がっており
      `GPIO34/35` とショートしているので、RP2350 のパッドが Low 側へ張り付くと
      外部 4.7kΩ と分圧して約 2.1V（VIH 2.31V 未満）＝ **Low に見えてバスが死ぬ**。
      実機 2026-09-27: `stage=2(no-SHTP) SDA=0 SCL=0` で 5 回中 4 回起動失敗。
      **出力にすると I2C バスを殺すので、出力にはしないこと。**
- [x] **`GPIO41` に触らない**（E220 の M0/M1 専用）。0.975 まで
      `imu_bus_select_protocol()` が HIGH 駆動しており、**無線を mode 3 へ
      叩き落としていた**（IMU 復旧からも呼ばれるので飛行中に効く）。
- [ ] `IMU_I2C_ADDR 0x4B` と `IMU_I2C_SA0_PIN 43` の整合（SA0=HIGH → 0x4B）。
- [ ] **バスが固まったら NRST だけでは戻らない。** `imu_i2c_bus_recover()` を
      リトライの **NRST より先に**通すこと（ペリフェラルを外して SCL を 9 回叩き
      STOP を作る）。RP2350 の I2C ブロックは NRST では初期化されないため、
      入れていないと **3 回のリトライが全部同じ理由で失敗する**。

### 4.3 焼いた直後に見るログ

| 行 | 読み方 |
|---|---|
| `BNO085 begin FAILED (i2c1) stage=1(no-ACK) SDA=.. SCL=.. addr=0x4B` | **アドレスが応答しない。**JP1(PS1) / R46・R47 / 3V3 / NRST / 半田を疑う。バスの波形以前の問題 |
| `... stage=2(no-SHTP)` | ACK は返る＝チップは居て I2C モードにいる。SHTP が成立しない（クロック・プルアップ・ノイズ） |
| `BNO085 init OK` + `calcfg=0x07` | 正常。校正設定も揃った |
| `rate GRV=15 LACC=15 RV=5 MS5611=44` | 設定どおり。**落ちていたら飢餓**（`gapmax` を見る） |
| `BNO085 i2c bus recover -> SDA=1 SCL=1` | リトライで出る。**0 のままならバスが解けていない** |
| `imu gapmax=` | BNO085 を引き取れた最長間隔。数十 ms 以内であること |
| `quat grvbad= grvjump= rvbad=` | **今回のテストの主目的**。触ったときに増えるかを見る |
| `[IMU] BNO085 recovery OK/FAILED (stage=..)` | 途絶が起きたときだけ。`stage=1(no-ACK)` なら配線 |

### 4.4 テストの主目的

**基板に触れた（ボタンを押さなくても、皮膚が接触して角度が変わるだけで）ときの
ジャイロのスパイク（SPI で約 0.8 件/分）が I2C で消えるか。**

**結果（2026-09-27）: I2C では一度も再現しなかった**ので、I2C 運用に確定した。
`quat grvbad=0 grvjump=0 rvbad=0` が続き、SPI で見えていたスパイクは消えた。

- 判定材料: `quat grvbad` / `grvjump`、バリオ設定画面の Linear acceleration の暴れ、
  生ログ（`imuraw/*.bin`）を `tools/imulog/decode_imulog.py` で確認
- 比較のため、**SPI のときと同じ持ち方・同じ触り方で同じ時間**測ること
- 消えなかった場合、容量結合ではなく IC か実装（はんだ・デカップリング）側の疑いが濃くなる

---

## 5. 加速度計の校正（バスとは無関係。ただし v7 実機で実際に出た）

### 症状

Vario 詳細画面で **`LinAccel[body]` は 3 軸ほぼ 0 なのに `VertAccel` だけ −1.5 付近**に落ち着く。
ロール・ピッチは正しく 0 を指しているので、姿勢の問題には見えない。

### 原因 — 引いている重力が違うだけ

| 表示 | 引いている重力 |
|---|---|
| `LinAccel[body]` | BNO085 の `LINEAR_ACCELERATION`。**BNO085 自身の適応的な重力推定**を引いた値 |
| `VertAccel` | 生比力を世界座標へ回して **固定値 `GRAVITY_MPS2` = 9.80665** を引いた値 |

加速度計にスケール／バイアス誤差があると、**前者は誤差ごと引いて打ち消す**ので静止時に
きれいに 0 になり、**後者は誤差がそのまま残る**。

実測（`nofix008`、静止 184 窓の平均。2026-09-27）:

```
|a|                          = 8.2243 m/s^2   ← 本来 9.807。加速度計が低く出ている
|LinAccel|                   = 0.0585         ← ほぼ 0
BNO085 が引いた重力の大きさ  = 8.2219
8.2219 - 9.80665             = -1.5848        = VertAccel の実測値
```

**`LinAccel` ≒ 0 は「加速度計が正常」の証拠にならない。**
構造上、静止時のスケール／バイアス誤差を打ち消すので見えない。
**`VertAccel` のほうが診断に使える。**

### 校正ずれの実測（nofix004 + nofix005、静止 7011 サンプル）

静止時の `|a|` は姿勢に関係なく常に 9.807 でなければならないが、実測は

```
|a| の範囲  8.094 .. 10.862 m/s^2   → 広がり 2.77 m/s^2
```

楕円体（対角スケール＋オフセット）のあてはめ（残差 1.0000 ± 0.0008）:

| 軸 | オフセット | スケール誤差 |
|---|---|---|
| **X** | **+1.31 m/s²** | −2.7% |
| Y | +0.28 | **判定不能**（下記） |
| Z | +0.01 | +3.2% |

水平では重力がセンサー −X を向くので、**X の +1.31 のバイアスがほぼ丸ごと出る**。
予測 −9.807×0.973 + 1.31 = −8.23 に対し実測 −8.09〜−8.28 で一致。

> **Y 軸の数字は信用しないこと。** そのログでは Y の範囲が −0.89〜+1.08 しかなく、
> **重力が Y 方向を向いた姿勢が一度も無い**。観測情報が無いのにあてはめは数字を返す。

### 直し方

1. `cal acc=` を 60 秒ログで見る。**3 になっていなければ校正が終わっていない。**
2. 基板を**各軸が上下を向く 6 姿勢**で数秒ずつ静止させる。**Y 軸を忘れないこと**
   （上の実測でも Y だけデータが無かった）。
3. `acc` が 3 に達すると `imu_try_save_dcd()` が 1 回だけ不揮発へ保存する
   （条件: 起動 20 秒以降 かつ `_acc_accuracy >= 3`）。
4. それでも 3 に届かないなら、過去の悪い校正データが残っている疑い。
   ドライバに `sh2_clearDcdAndReset()`（`src/bno08x/sh2.h`）がある。
   **呼び出しコードは未実装。**

### バリオへの影響

バリオ KF は状態にバイアス項 `kf_x[2]` を持つので、**一定のオフセットは吸収される**。
ただし今回の誤差は**姿勢で変わる**（水平 −1.6 / 機首下げ 82 度 +0.05 / 別姿勢 +0.41）ので、
ピッチやバンクが変わる場面では吸収しきれない。**精度の上限がここで決まる。**

---

### 5.5 ★ アドレス探査を二重にしてはいけない（0.976 で踏んだ）

**症状**: 起動が 5 回中 4〜5 回失敗する。

```
BNO085 begin FAILED (i2c1) stage=2(no-SHTP) init_step=1 sh2=0 SDA=0 SCL=0 addr=0x4B
```

**原因**: `imu_bus_begin()` が `begin_I2C()` の前に自前でアドレス ACK を確認していた。

arduino-pico の **0 バイト書き込みは I2C ペリフェラルを使わない**。ピンを SIO に
切り替えて**ビットバンギングで叩く**（`Wire.cpp` の `_probe()`）。そのビット幅は

```
delay = (1000000 / _clkHz) / 2      → 400kHz なら 1µs、100kHz なら 5µs
```

そして `begin_I2C()` → `Adafruit_I2CDevice::begin()` → `detected()` が
**まったく同じ `_probe()` をもう一度**叩く（間の `_wire->begin()` は
`if (_running) return;` で何もしない）。

結果、**同じビットバンギング探査が背中合わせで 2 回**走り、
**1 回目は通って 2 回目が落ちる**という形で毎回失敗していた。

**対処**: 自前の探査を削除した。**保護は `detected()` 自身が果たす**（`_init()` へ
進む前に false を返すので `sh2_getProdIds()` には到達しない）。

`IMU_I2C_HZ` は **400kHz のまま**でよい（真因は二重探査だった）。
**再発したときは、まずこれを 100000 に下げて切り分ける**（ビット幅が 1µs → 5µs）。

> 外部プルアップ 4.7kΩ は実装済みなので、**立ち上がり時間の問題ではない。**
> 探査がペリフェラルを使わずビットバンギングしている側の問題。

---

## 6. SPI へ戻す場合（非推奨）

0.976 で SPI のコードは削除した。戻すなら 0.975 の `imu.cpp` / `settings.h` /
`e220.h` / `src/bno08x/Adafruit_BNO08x.cpp` を見ること。ハード側は
**JP1 を 1-2（+3V3）へ戻す**。`E220_MODE_PIN` が `GPIO41` から動かせないため、
**`R53` を戻して H_CSN を繋ぐと E220 と衝突する**点に注意。
そして何より、**触るとジャイロが化ける問題が戻る。**

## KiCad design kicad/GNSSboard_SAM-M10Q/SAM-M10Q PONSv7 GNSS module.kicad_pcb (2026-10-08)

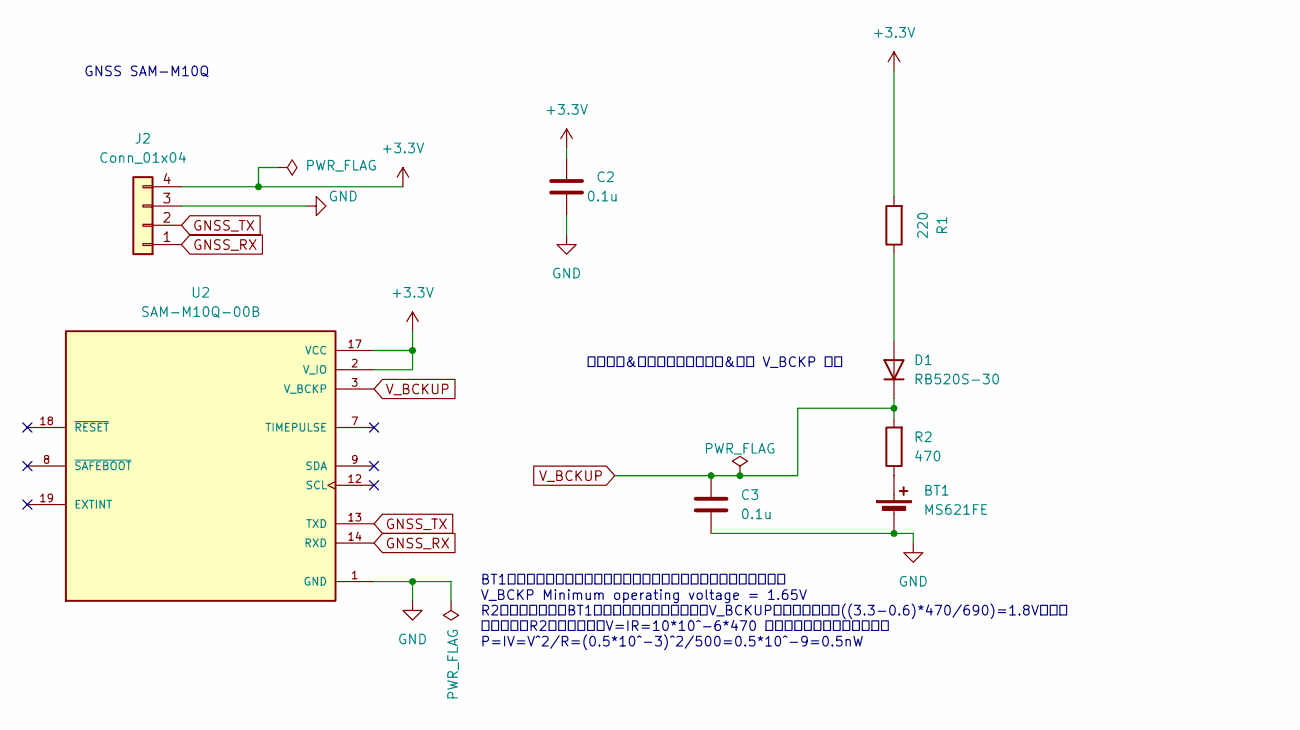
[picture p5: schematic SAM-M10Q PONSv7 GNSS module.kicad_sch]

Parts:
BT1: MS621FE; BatteryHolder_Seiko_MS621F
C2, C3: 0.1u; C_0603_1608Metric_Pad1.08x0.95mm_HandSolder
D1: RB520S-30; D_SOD-523
J2: Conn_01x04; FPC_CON 4p 1mm
R1: 220; R_0603_1608Metric_Pad0.98x0.95mm_HandSolder
R2: 470; R_0603_1608Metric_Pad0.98x0.95mm_HandSolder
U2: SAM-M10Q-00B; XCVR_SAM-M10Q-00B; PARTREV R03

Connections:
+3.3V: C2.1, J2.4, R1.2, U2.2 (V_IO), U2.17 (VCC)
GND: BT1.2 (-), C2.2, C3.2, J2.3, U2.1 (GND), U2.4 (GND), U2.5 (GND), U2.6 (GND), U2.10 (GND), U2.11 (GND), U2.15 (GND), U2.16 (GND), U2.20 (GND)
GNSS_RX: J2.1, U2.14 (RXD)
GNSS_TX: J2.2, U2.13 (TXD)
unnamed: BT1.1 (+), R2.1
unnamed: D1.2 (A), R1.1
V_BCKUP: C3.1, D1.1 (K), R2.2, U2.3 (V_BCKP)

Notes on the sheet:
GNSS SAM-M10Q
突入電流&バッテリー電流制限&最小 V_BCKP 対策
BT1が放電しきっていると、モジュールが起動しないバグがあった。 V_BCKP Minimum operating voltage = 1.65V R2抵抗によって、BT1バッテリーが空っぽでも、V_BCKUPに電圧が生じる((3.3-0.6)*470/690)=1.8Vぐらい 放電時は、R2の電圧降下はV=IR=10*10^-6*470 で、電圧降下はほとんどない P=IV=V^2/R=(0.5*10^-3)^2/500=0.5*10^-9=0.5nW

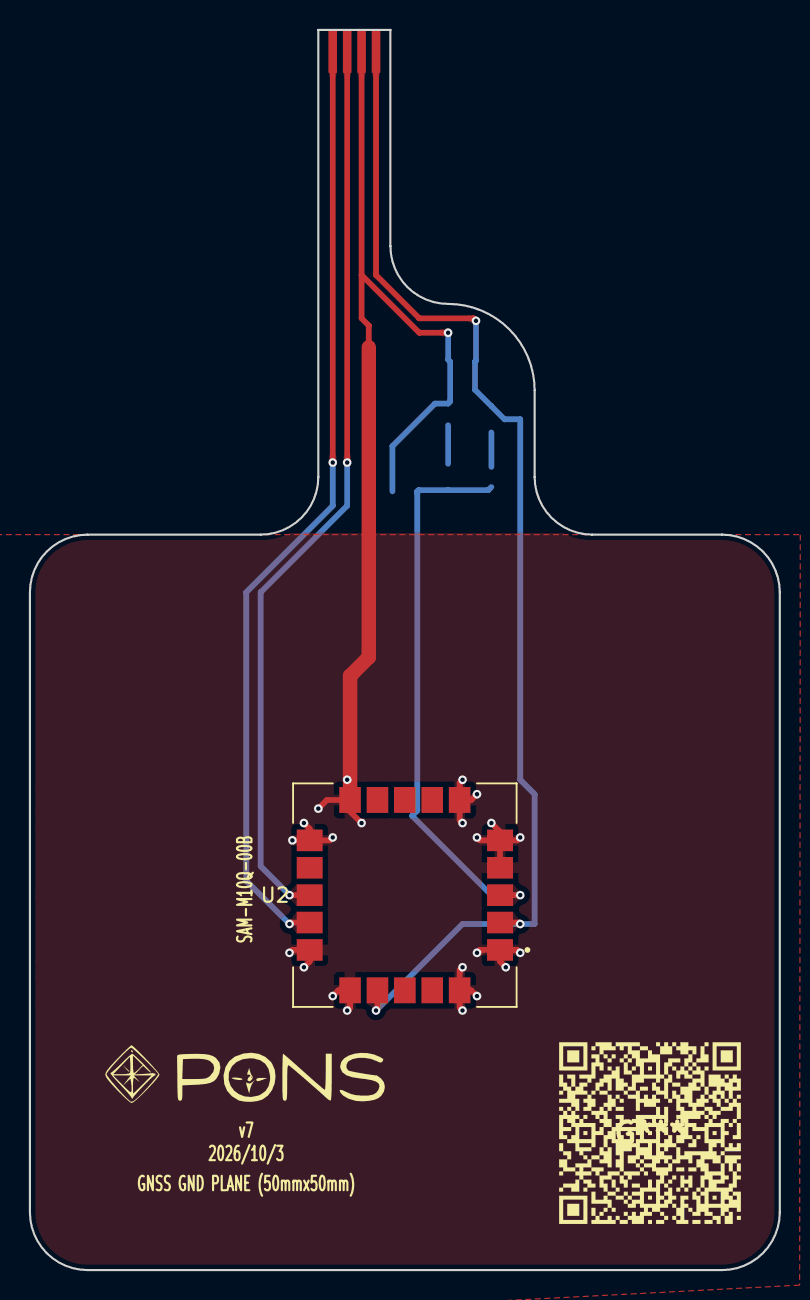
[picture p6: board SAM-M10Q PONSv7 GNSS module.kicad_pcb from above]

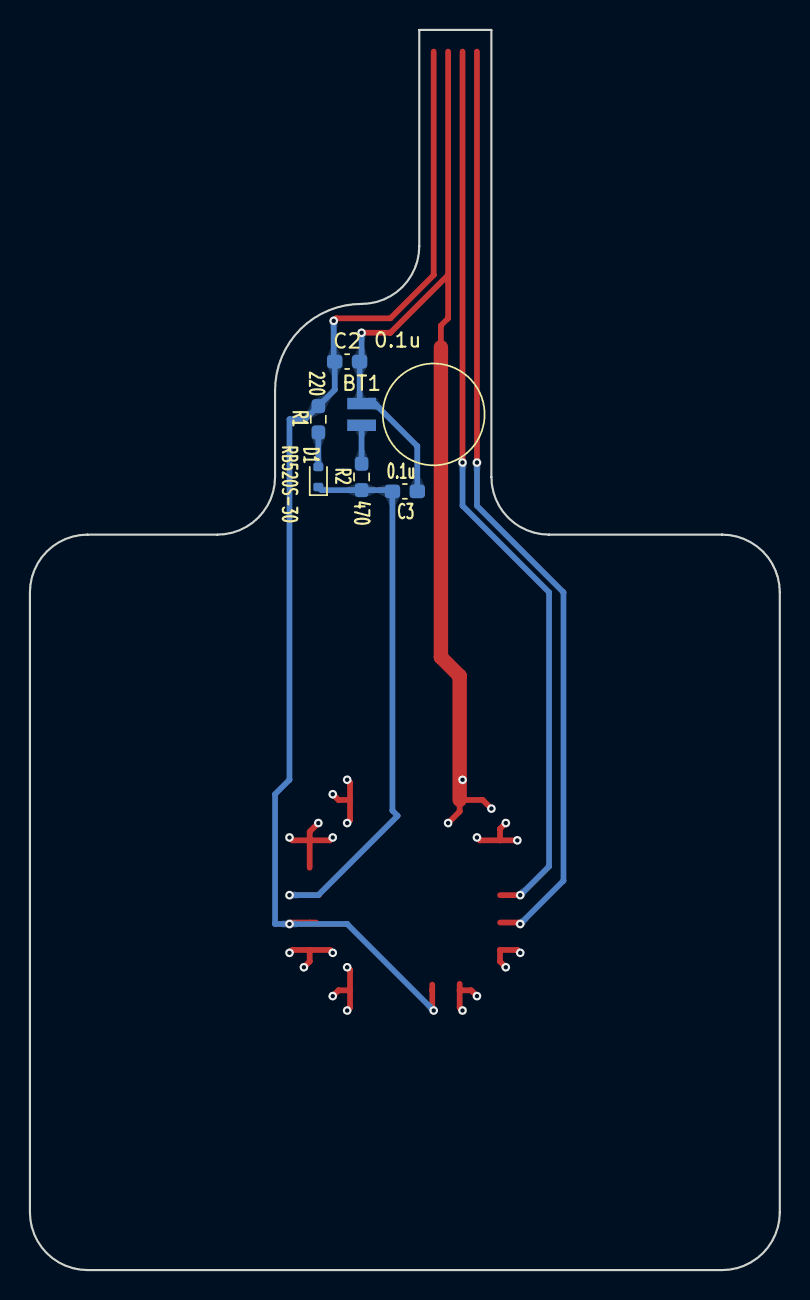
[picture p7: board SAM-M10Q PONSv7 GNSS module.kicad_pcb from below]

Board: 2 copper layers, 52.0 x 86.0 mm, 8 parts (6 on the bottom side), 7 nets.

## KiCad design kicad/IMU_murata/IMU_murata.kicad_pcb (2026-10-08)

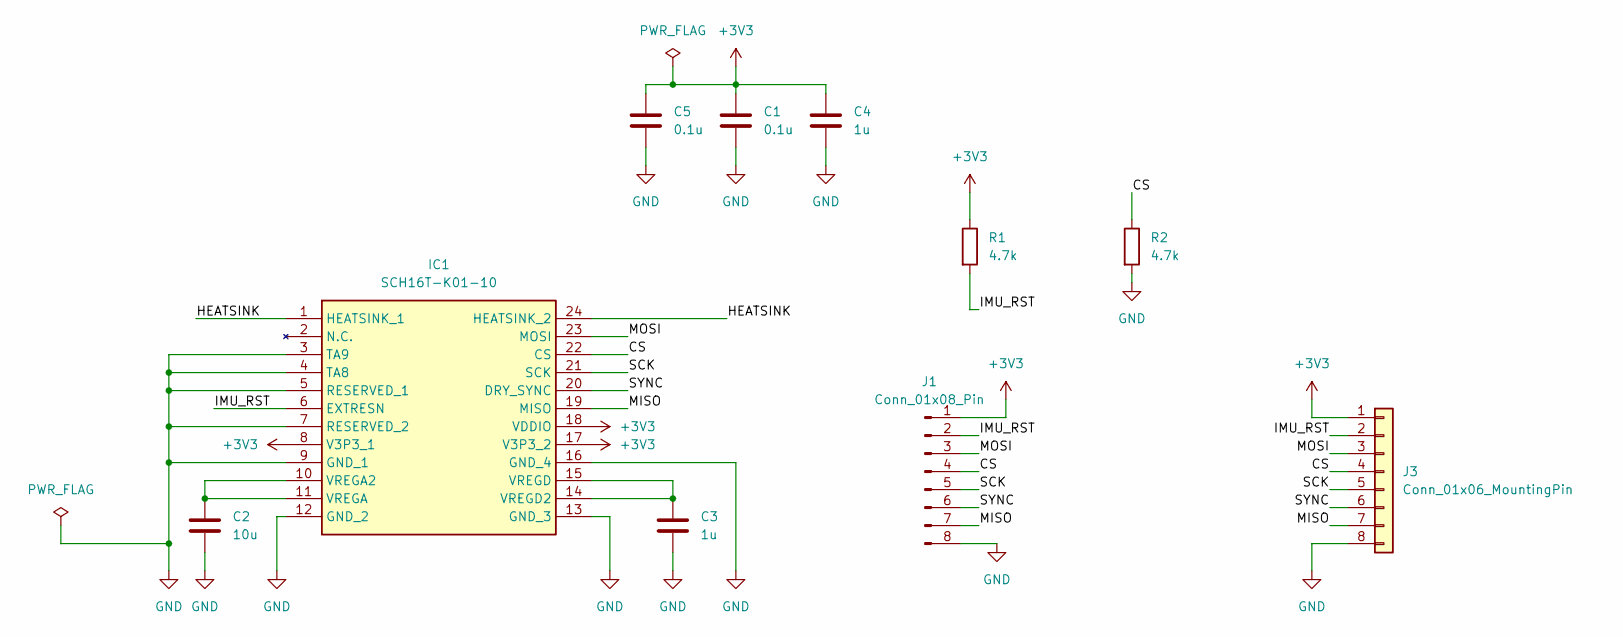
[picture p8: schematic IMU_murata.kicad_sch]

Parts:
C1, C5: 0.1u; C_0603_1608Metric
C2: 10u; C_0603_1608Metric
C3, C4: 1u; C_0603_1608Metric
IC1: SCH16T-K01-10; SCH16TK0110; Mouser Part Number 81-SCH16T-K01-10
J1: Conn_01x08_Pin; PinHeader_1x08_P2.54mm_Vertical
J3: Conn_01x06_MountingPin; FPC_CON 8p 1mm
R1, R2: 4.7k; R_0603_1608Metric

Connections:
+3V3: C1.1, C4.1, C5.1, IC1.8 (V3P3_1), IC1.17 (V3P3_2), IC1.18 (VDDIO), J1.1, J3.1, R1.1
/CS: IC1.22 (CS), J1.4, J3.4, R2.1
/HEATSINK: IC1.1 (HEATSINK_1), IC1.24 (HEATSINK_2)
/IMU_RST: IC1.6 (EXTRESN), J1.2, J3.2, R1.2
/MISO: IC1.19 (MISO), J1.7, J3.7
/MOSI: IC1.23 (MOSI), J1.3, J3.3
/SCK: IC1.21 (SCK), J1.5, J3.5
/SYNC: IC1.20 (DRY_SYNC), J1.6, J3.6
GND: C1.2, C2.2, C3.2, C4.2, C5.2, IC1.3 (TA9), IC1.4 (TA8), IC1.5 (RESERVED_1), IC1.7 (RESERVED_2), IC1.9 (GND_1), IC1.12 (GND_2), IC1.13 (GND_3), IC1.16 (GND_4), J1.8, J3.8, R2.2
unnamed: C2.1, IC1.10 (VREGA2), IC1.11 (VREGA)
unnamed: C3.1, IC1.14 (VREGD2), IC1.15 (VREGD)

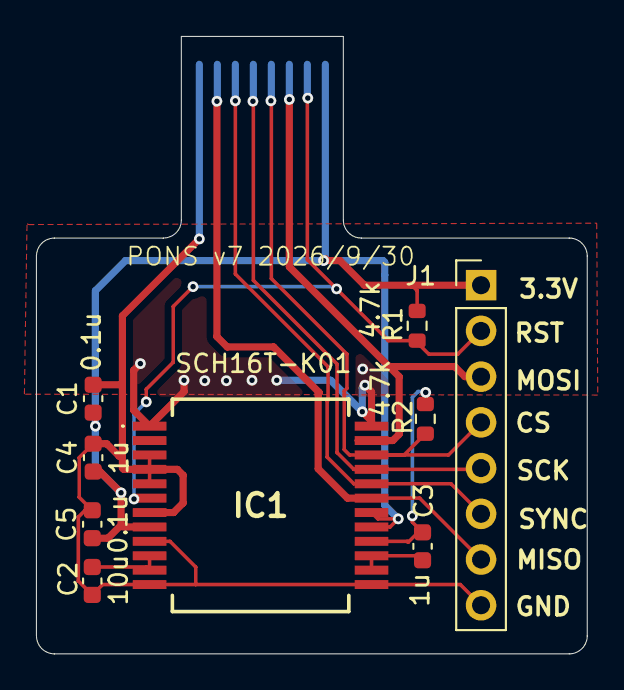
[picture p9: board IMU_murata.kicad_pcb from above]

Board: 2 copper layers, 30.6 x 34.3 mm, 10 parts (1 on the bottom side), 11 nets.

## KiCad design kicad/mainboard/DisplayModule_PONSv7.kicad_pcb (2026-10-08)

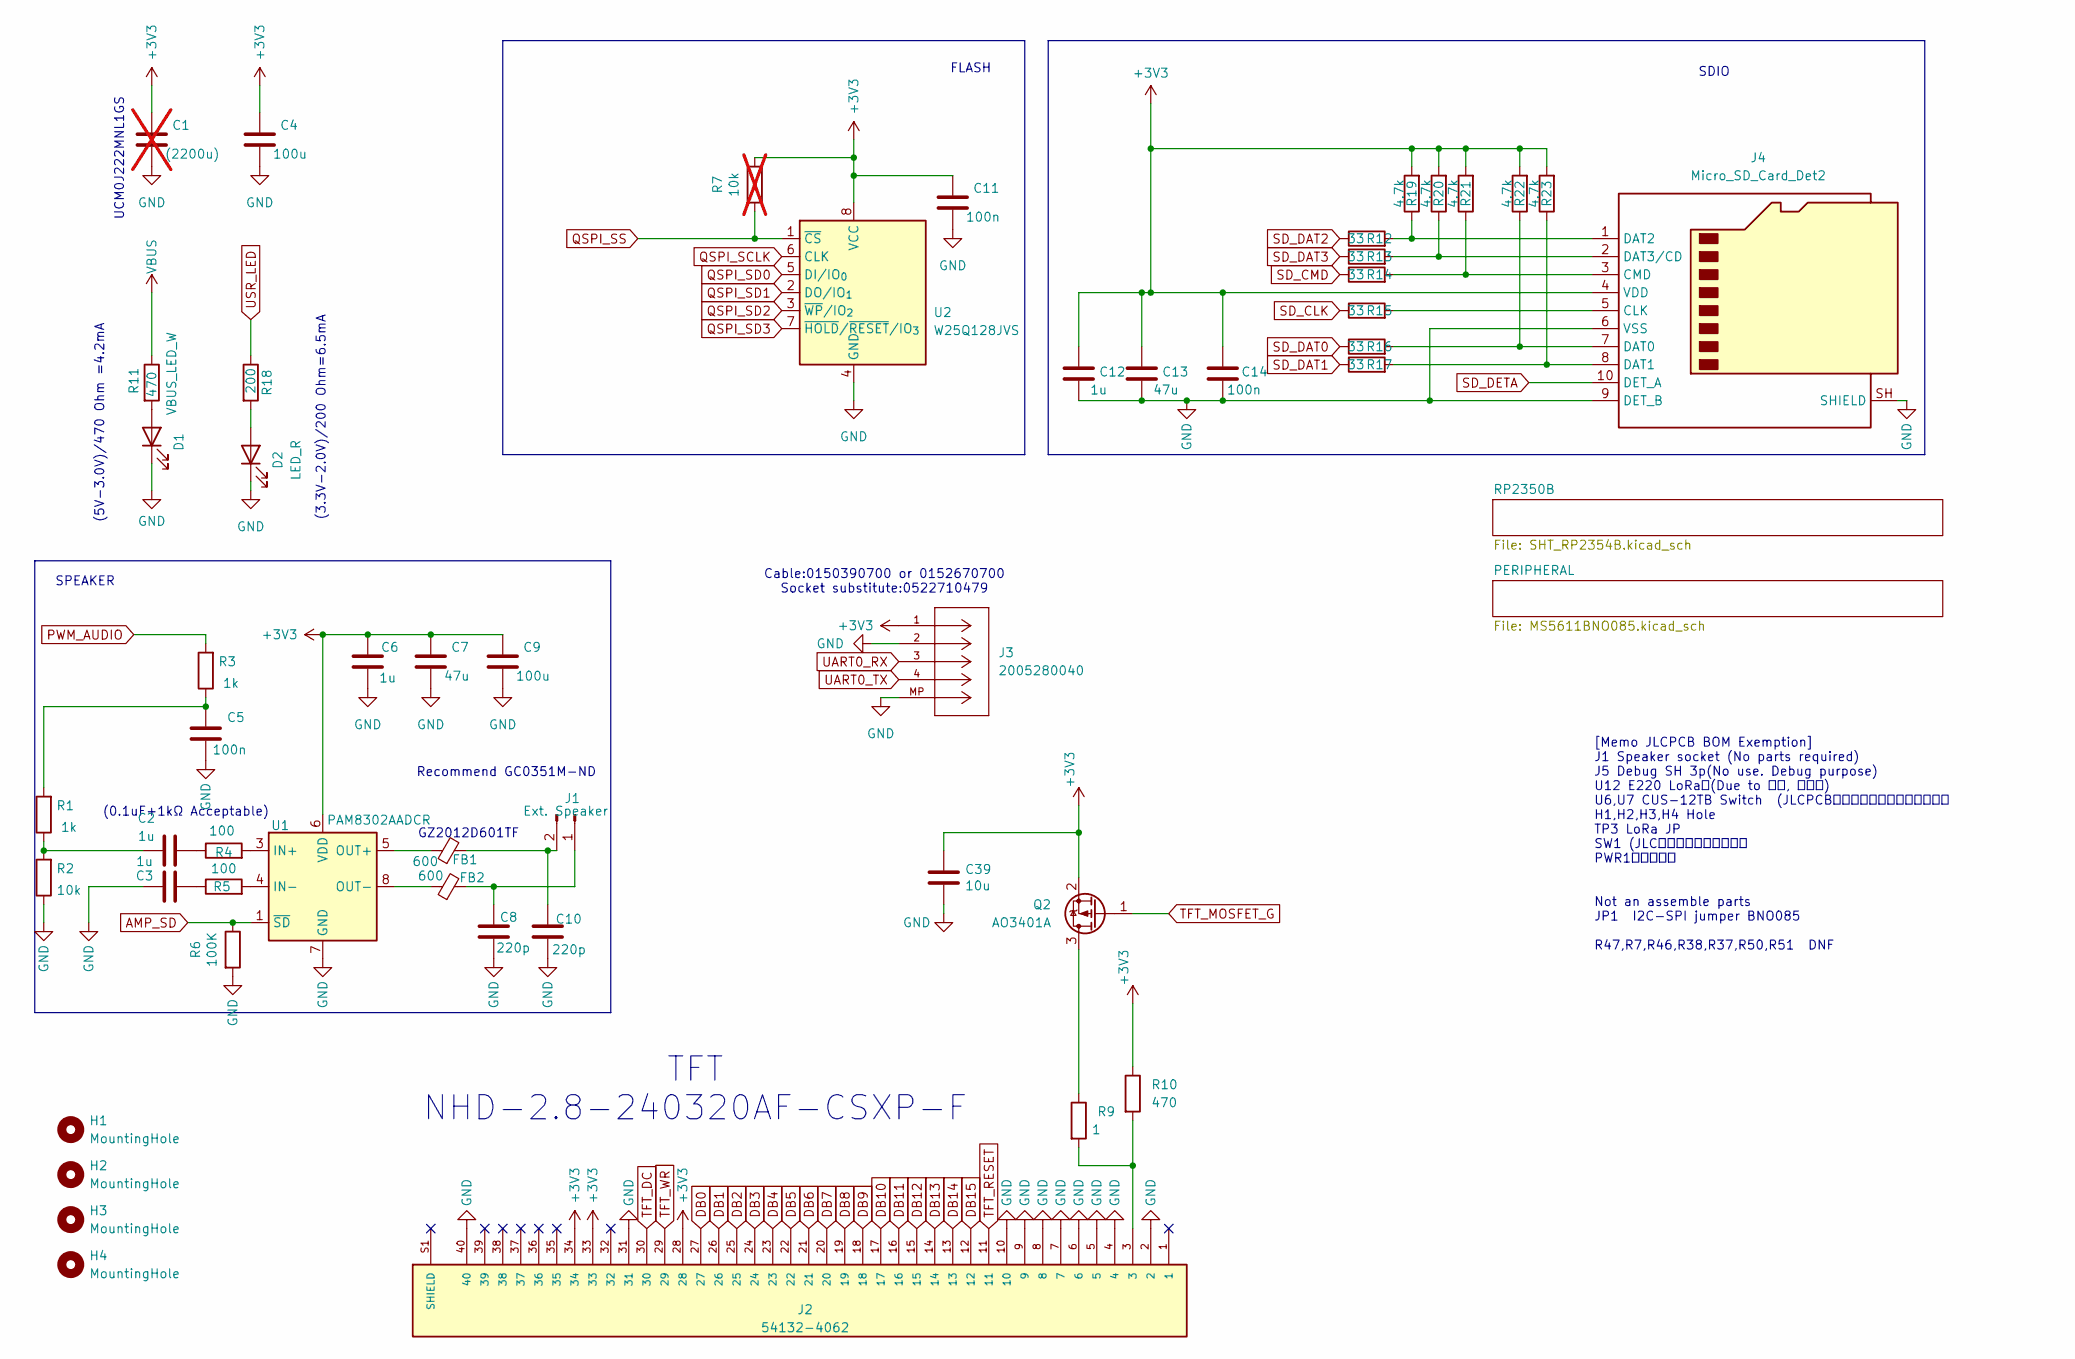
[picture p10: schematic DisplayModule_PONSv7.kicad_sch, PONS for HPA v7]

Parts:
C1: (2200u); CP_Elec_10x10.5; not fitted
C2, C3, C6, C12: 1u; C_0402_1005Metric_small_pads; LCSC C52923
C4, C9: 100u; C_1206_3216Metric; LCSC C15008
C5, C11, C14: 100n; C_0402_1005Metric_small_pads; LCSC C1525
C7, C13: 47u; C_0805_2012Metric; LCSC C16780
C8, C10: 220p; C_0402_1005Metric_small_pads; LCSC C1530
C39: 10u; C_0402_1005Metric_small_pads; LCSC C15525
D1: VBUS_LED_W; LED_0603_1608Metric_Pad1.05x0.95mm_HandSolder; LCSC C2290
D2: LED_R; LED_0603_1608Metric_Pad1.05x0.95mm_HandSolder; LCSC C2286
FB1, FB2: 600; L_0805_2012Metric; LCSC C1017
H1, H2, H3, H4: MountingHole; MountingHole_2.7mm_M2.5
J1: Ext. Speaker; PinHeader_1x02_P2.54mm_Vertical
J2: 54132-4062; MOLEX_54132-4062; PARTREV G; LCSC C505102
J3: 2005280040; Molex_200528-0040_1x04-1MP_P1.00mm_Horizontal; MANUFACTURER_PART_NUMBER 2005280040; LCSC C563728
J4: Micro_SD_Card_Det2; microSD_HC_Hirose_DM3AT-SF-PEJM5; LCSC C114218
Q2: AO3401A; SOT-23
R1, R3: 1k; R_0402_1005Metric; LCSC C11702
R2: 10k; R_0402_1005Metric; LCSC C25744
R4, R5: 100; R_0402_1005Metric; LCSC C25076
R6: 100K; R_0402_1005Metric; LCSC C25741
R7: 10k; R_0603_1608Metric_Pad0.98x0.95mm_HandSolder; LCSC C25744; not fitted
R9: 1; R_0603_1608Metric; LCSC C22936
R10, R11: 470; R_0402_1005Metric; LCSC C25117
R12, R13, R14, R15, R16, R17: 33; R_0402_1005Metric; LCSC C25105
R18: 200; R_0402_1005Metric; LCSC C25087
R19, R20, R21, R22, R23: 4.7k; R_0402_1005Metric; LCSC C25900
U1: PAM8302AADCR; SO-8_3.9x4.9mm_P1.27mm; LCSC C112137
U2: W25Q128JVS; SOIC-8_5.3x5.3mm_P1.27mm; LCSC C97521

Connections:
+3V3: C1.1, C4.1, C6.1, C7.1, C9.1, C11.1, C12.1, C13.1, C14.1, C39.1, J2.28, J2.33, J2.34, J3.1, J4.4 (VDD), Q2.2 (S), R7.1, R10.1, R19.2, R20.2, R21.2, R22.2, R23.2, U1.6 (VDD), U2.8 (VCC); also elsewhere on the board
AMP_SD: R6.1, U1.1 (~SD); also elsewhere on the board
DB0: J2.27; also elsewhere on the board
DB1: J2.26; also elsewhere on the board
DB2: J2.25; also elsewhere on the board
DB3: J2.24; also elsewhere on the board
DB4: J2.23; also elsewhere on the board
DB5: J2.22; also elsewhere on the board
DB6: J2.21; also elsewhere on the board
DB7: J2.20; also elsewhere on the board
DB8: J2.19; also elsewhere on the board
DB9: J2.18; also elsewhere on the board
DB10: J2.17; also elsewhere on the board
DB11: J2.16; also elsewhere on the board
DB12: J2.15; also elsewhere on the board
DB13: J2.14; also elsewhere on the board
DB14: J2.13; also elsewhere on the board
DB15: J2.12; also elsewhere on the board
GND: C1.2, C3.1, C4.2, C5.1, C6.2, C7.2, C8.2, C9.2, C10.2, C11.2, C12.2, C13.2, C14.2, C39.2, D1.1 (K), D2.1 (K), J2.2, J2.4, J2.5, J2.6, J2.7, J2.8, J2.9, J2.10, J2.31, J2.40, J3.2, J3.MP, J4.6 (VSS), J4.9 (DET_B), J4.SH (SHIELD), R2.1, R6.2, U1.7 (GND), U2.4 (GND); also elsewhere on the board
unnamed: C2.1, R1.1, R2.2
unnamed: C2.2, R4.1
unnamed: C3.2, R5.1
unnamed: C5.2, R1.2, R3.1
unnamed: D1.2 (A), R11.2
unnamed: D2.2 (A), R18.2
unnamed: C8.1, FB2.2, J1.1
unnamed: C10.1, FB1.2, J1.2
unnamed: J2.3, R9.2, R10.2
unnamed: J4.5 (CLK), R15.2
unnamed: J4.3 (CMD), R14.2, R21.1
unnamed: J4.7 (DAT0), R16.2, R22.1
unnamed: J4.8 (DAT1), R17.2, R23.1
unnamed: J4.1 (DAT2), R12.2, R19.1
unnamed: J4.2 (DAT3/CD), R13.2, R20.1
unnamed: Q2.3 (D), R9.1
unnamed: R4.2, U1.3 (IN+)
unnamed: R5.2, U1.4 (IN-)
unnamed: FB1.1, U1.5 (OUT+)
unnamed: FB2.1, U1.8 (OUT-)
PWM_AUDIO: R3.2; also elsewhere on the board
QSPI_SCLK: U2.6 (CLK); also elsewhere on the board
QSPI_SD0: U2.5 (DI/IO_{0}); also elsewhere on the board
QSPI_SD1: U2.2 (DO/IO_{1}); also elsewhere on the board
QSPI_SD2: U2.3 (~WP/IO_{2}); also elsewhere on the board
QSPI_SD3: U2.7 (~HOLD/~RESET/IO_{3}); also elsewhere on the board
QSPI_SS: R7.2, U2.1 (~CS); also elsewhere on the board
SD_CLK: R15.1; also elsewhere on the board
SD_CMD: R14.1; also elsewhere on the board
SD_DAT0: R16.1; also elsewhere on the board
SD_DAT1: R17.1; also elsewhere on the board
SD_DAT2: R12.1; also elsewhere on the board
SD_DAT3: R13.1; also elsewhere on the board
SD_DETA: J4.10 (DET_A); also elsewhere on the board
TFT_DC: J2.30; also elsewhere on the board
TFT_MOSFET_G: Q2.1 (G); also elsewhere on the board
TFT_RESET: J2.11; also elsewhere on the board
TFT_WR: J2.29; also elsewhere on the board
UART0_RX: J3.3; also elsewhere on the board
UART0_TX: J3.4; also elsewhere on the board
USR_LED: R18.1; also elsewhere on the board
VBUS: R11.1; also elsewhere on the board

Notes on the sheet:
UCM0J222MNL1GS
SDIO
[Memo JLCPCB BOM Exemption] J1 Speaker socket (No parts required) J5 Debug SH 3p(No use. Debug purpose) U12 E220 LoRa (Due to 技適, 手実装) U6,U7 CUS-12TB Switch (JLCPCBにないパーツのため手実装） H1,H2,H3,H4 Hole TP3 LoRa JP SW1 (JLCにないパーツのため） PWR1（コスト） Not an assemble parts JP1 I2C-SPI jumper BNO085 R47,R7,R46,R38,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
(5V-3.0V)/470 Ohm =4.2mA
(3.3V-2.0V)/200 Ohm=6.5mA
Recommend GC0351M-ND
Cable:0150390700 or 0152670700 Socket substitute:0522710479
SPEAKER
FLASH
GZ2012D601TF
(0.1uF+1kΩ Acceptable)
TFT NHD-2.8-240320AF-CSXP-F

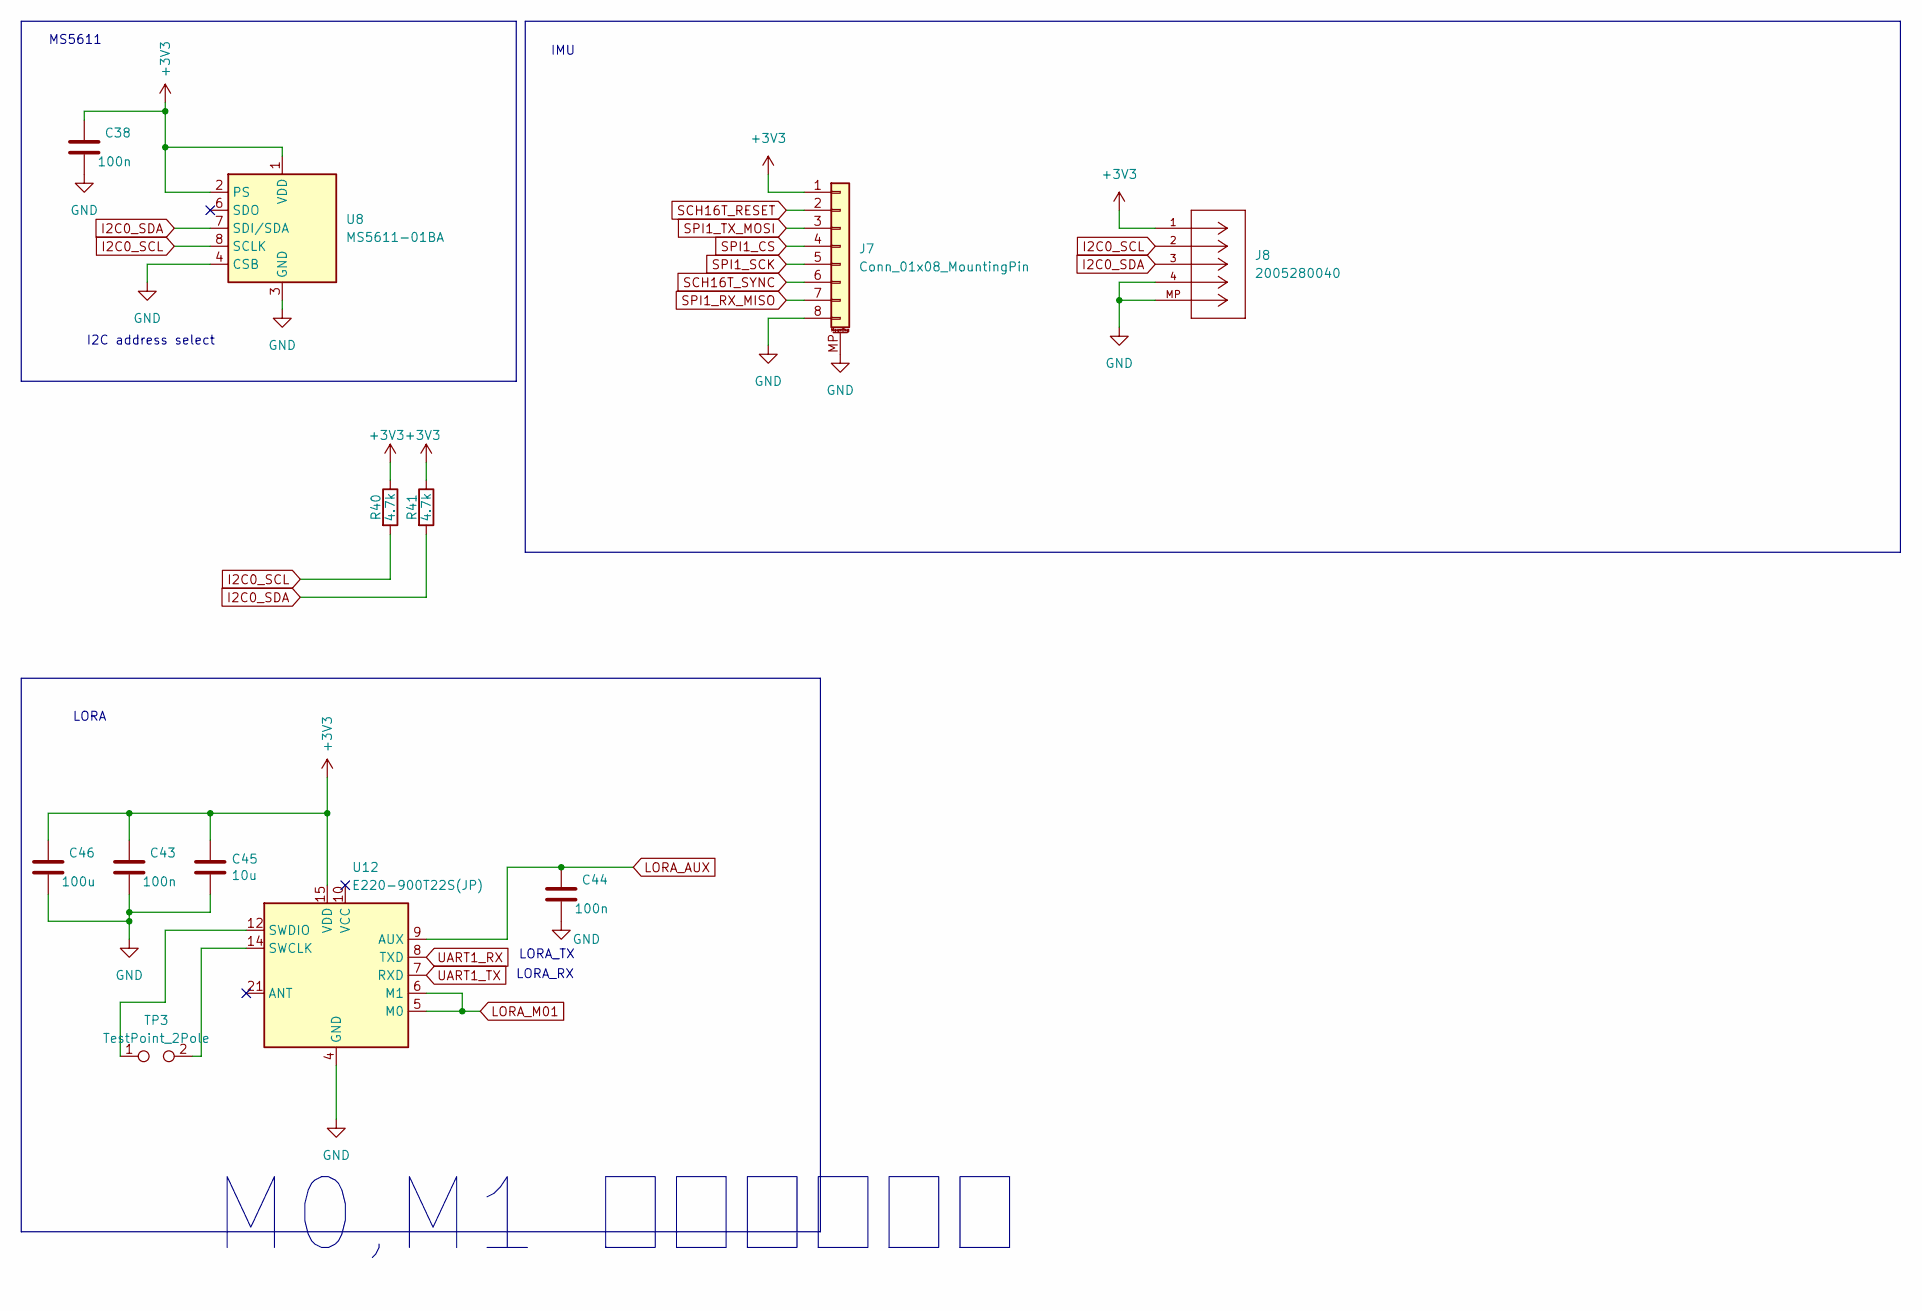
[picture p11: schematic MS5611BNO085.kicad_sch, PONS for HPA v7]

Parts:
C38, C43, C44: 100n; C_0402_1005Metric_small_pads; LCSC C1525
C45: 10u; C_0402_1005Metric_small_pads; LCSC C15525
C46: 100u; C_1206_3216Metric; LCSC C15008
J7: Conn_01x08_MountingPin; Molex_200528-0080_1x08-1MP_P1.00mm_Horizontal
J8: 2005280040; Molex_200528-0040_1x04-1MP_P1.00mm_Horizontal; MANUFACTURER_PART_NUMBER 2005280040; LCSC C563728
R40, R41: 4.7k; R_0402_1005Metric; LCSC C25900
TP3: TestPoint_2Pole; TestPoint_2Pads_Pitch2.54mm_Drill0.8mm
U8: MS5611-01BA; LGA-8_3x5mm_P1.25mm; LCSC C15639
U12: E220-900T22S(JP)

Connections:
+3V3: C38.1, C43.1, C45.1, C46.1, J7.1, J8.1, R40.1, R41.1, U8.1 (VDD), U8.2 (PS), U12.15 (VDD); also elsewhere on the board
GND: C38.2, C43.2, C44.2, C45.2, C46.2, J7.8, J7.MP (MountPin), J8.4, J8.MP, U8.3 (GND), U8.4 (CSB), U8.5 (CSB), U12.1 (GND), U12.2 (GND), U12.3 (GND), U12.4 (GND), U12.11 (GND), U12.13 (GND), U12.19 (GND), U12.20 (GND), U12.22 (GND); also elsewhere on the board
I2C0_SCL: J8.2, R40.2, U8.8 (SCLK); also elsewhere on the board
I2C0_SDA: J8.3, R41.2, U8.7 (SDI/SDA); also elsewhere on the board
LORA_AUX: C44.1, U12.9 (AUX); also elsewhere on the board
LORA_M01: U12.5 (M0), U12.6 (M1); also elsewhere on the board
unnamed: TP3.2, U12.14 (SWCLK)
unnamed: TP3.1, U12.12 (SWDIO)
SCH16T_RESET: J7.2; also elsewhere on the board
SCH16T_SYNC: J7.6; also elsewhere on the board
SPI1_CS: J7.4; also elsewhere on the board
SPI1_RX_MISO: J7.7; also elsewhere on the board
SPI1_SCK: J7.5; also elsewhere on the board
SPI1_TX_MOSI: J7.3; also elsewhere on the board
UART1_RX: U12.8 (TXD); also elsewhere on the board
UART1_TX: U12.7 (RXD); also elsewhere on the board

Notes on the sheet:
I2C address select
LORA_TX
LORA_RX
LORA
M0,M1 ピン変更あり
IMU
MS5611

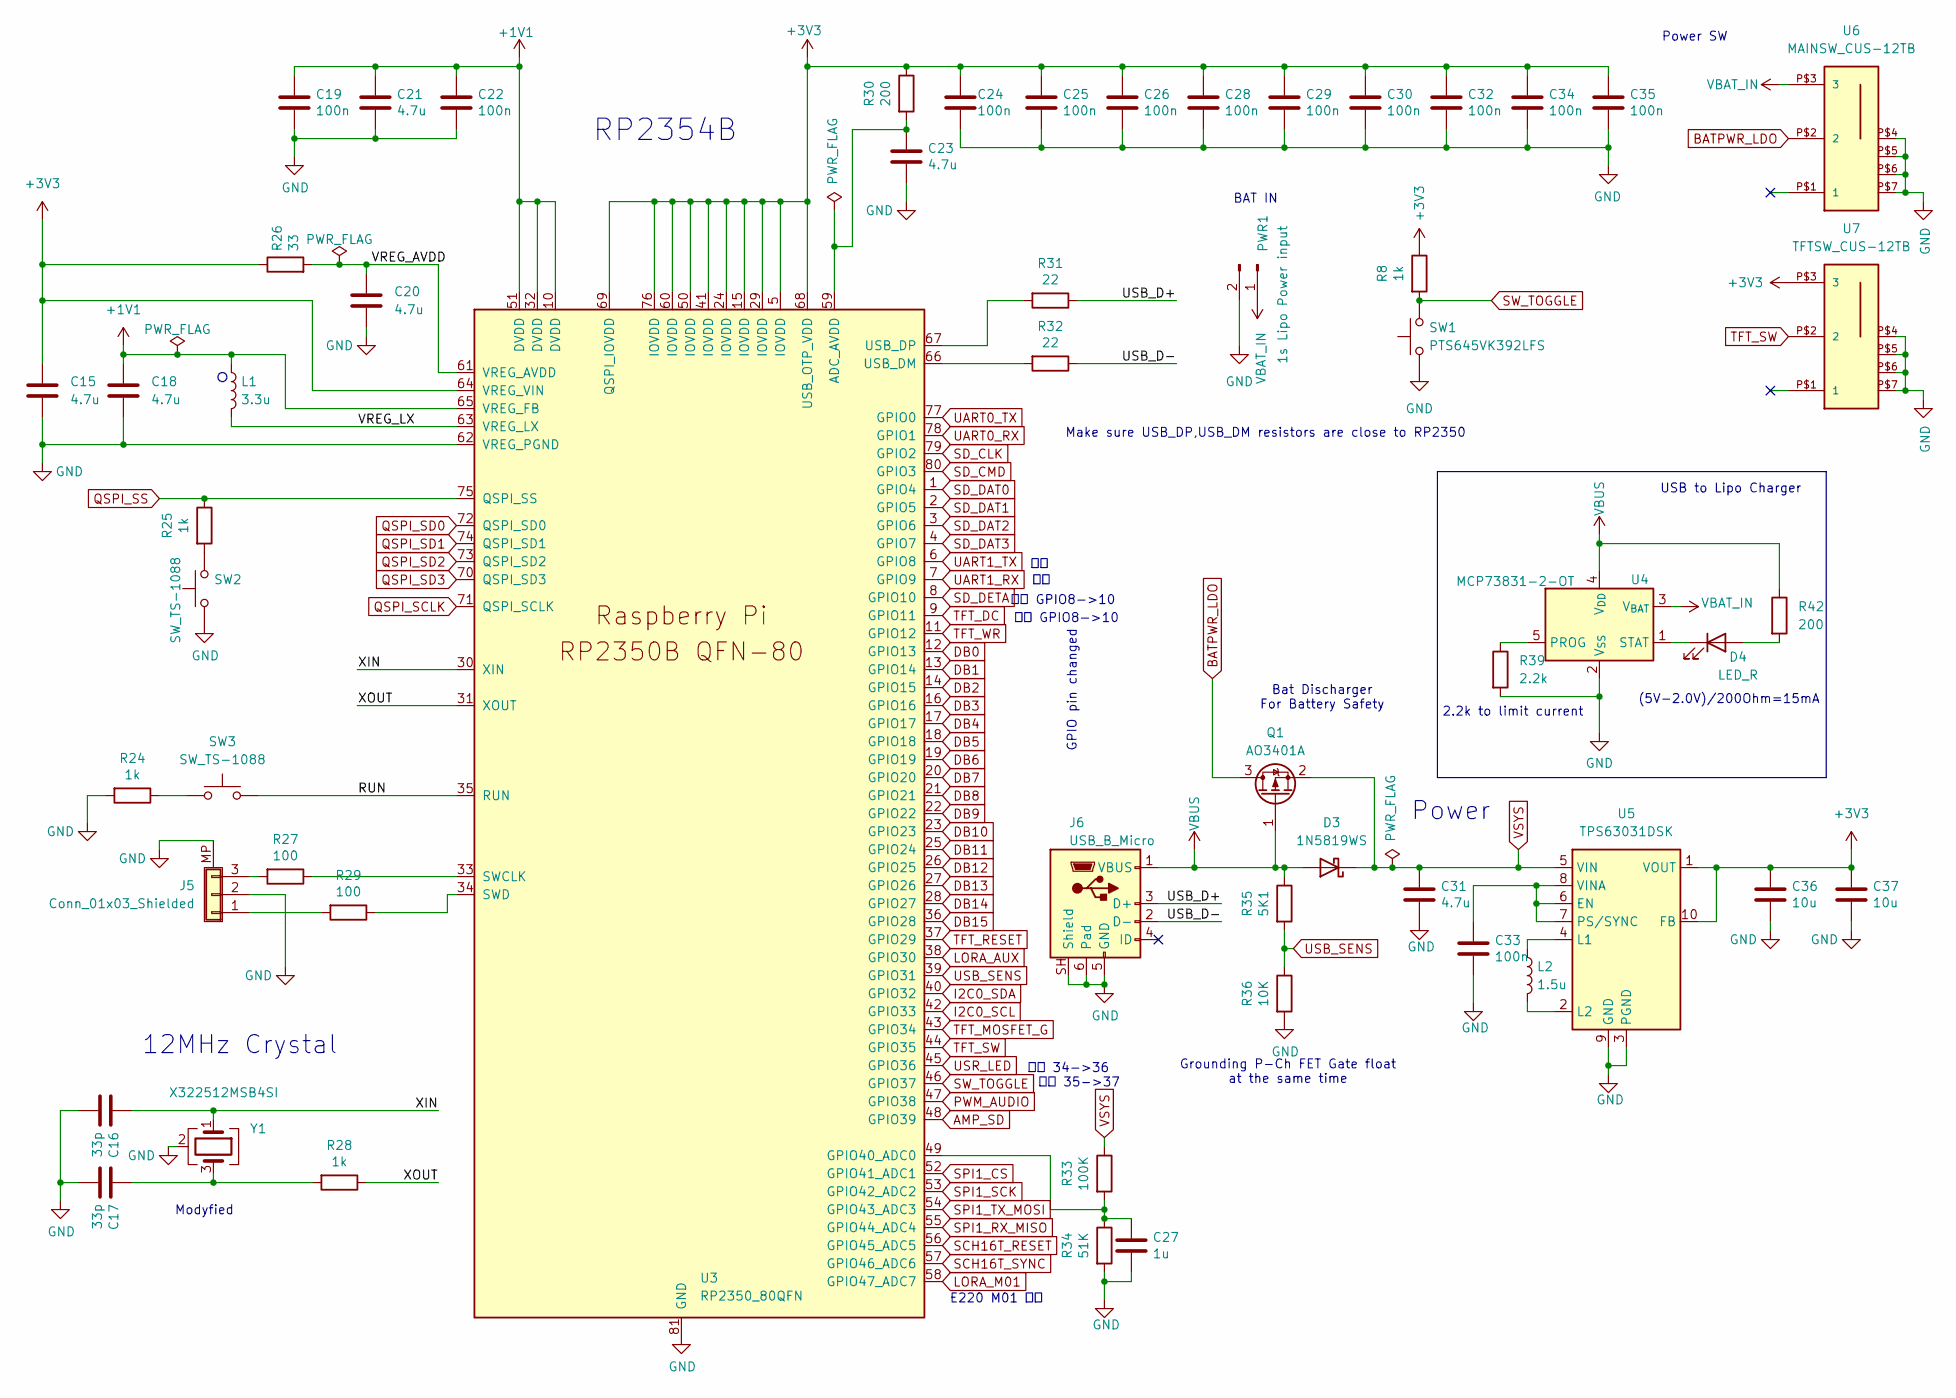
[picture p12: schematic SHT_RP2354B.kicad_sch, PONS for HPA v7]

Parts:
C15, C18, C20, C21, C23, C31: 4.7u; C_0402_1005Metric_small_pads; LCSC C23733
C16, C17: 33p; C_0402_1005Metric_small_pads; LCSC C1562
C19, C22, C24, C25, C26, C28, C29, C30, C32, C33, C34, C35: 100n; C_0402_1005Metric_small_pads; LCSC C1525
C27: 1u; C_0402_1005Metric_small_pads; LCSC C52923
C36, C37: 10u; C_0402_1005Metric_small_pads; LCSC C15525
D3: 1N5819WS; D_SOD-323; LCSC C191023
D4: LED_R; LED_0603_1608Metric_Pad1.05x0.95mm_HandSolder; LCSC C2286
J5: Conn_01x03_Shielded; JST_SH_BM03B-SRSS-TB_1x03-1MP_P1.00mm_Vertical; LCSC C160389
J6: USB_B_Micro; USB_Micro-B_Amphenol_10103594-0001LF_Horizontal; LCSC C428495
L1: 3.3u; L_pol_2016; LCSC C42411119
L2: 1.5u; L_APV_ANR3015; LCSC C701165
PWR1: 1s Lipo Power input; JST_PH_S2B-PH-K_1x02_P2.00mm_Horizontal; LCSC C173752
Q1: AO3401A; SOT-23; LCSC C15127
R8, R24, R25, R28: 1k; R_0402_1005Metric; LCSC C11702
R26: 33; R_0402_1005Metric; LCSC C25105
R27, R29: 100; R_0402_1005Metric; LCSC C25076
R30, R42: 200; R_0402_1005Metric; LCSC C25087
R31, R32: 22; R_0402_1005Metric; LCSC C25092
R33: 100K; R_0402_1005Metric; LCSC C25741
R34: 51K; R_0402_1005Metric; LCSC C25794
R35: 5K1; R_0402_1005Metric; LCSC C25905
R36: 10K; R_0402_1005Metric; LCSC C25744
R39: 2.2k; R_0402_1005Metric; LCSC C25879
SW1: PTS645VK392LFS; SW_Tactile_SPST_Angled_PTS645Vx39-2LFS; LCSC C285519
SW2, SW3: SW_TS-1088; TS-1088-AR02016; LCSC C720477
U3: RP2350_80QFN; RP2350-QFN-80-1EP_10x10_P0.4mm_EP3.4x3.4mm_ThermalVias; LCSC C42415655
U4: MCP73831-2-OT; SOT-23-5; LCSC C424093
U5: TPS63031DSK; WSON-10-1EP_2.5x2.5mm_P0.5mm_EP1.2x2mm; LCSC C15516
U6: MAINSW_CUS-12TB; CUS-12TB
U7: TFTSW_CUS-12TB; CUS-12TB
Y1: X322512MSB4SI; Crystal_SMD_3225-4Pin_3.2x2.5mm; LCSC C9002

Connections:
+1V1: C18.1, C19.1, C21.1, C22.1, L1.1, U3.10 (DVDD), U3.32 (DVDD), U3.51 (DVDD), U3.65 (VREG_FB)
+3V3: C15.1, C24.1, C25.1, C26.1, C28.1, C29.1, C30.1, C32.1, C34.1, C35.1, C36.1, C37.1, R8.1, R26.1, R30.1, U3.5 (IOVDD), U3.15 (IOVDD), U3.24 (IOVDD), U3.29 (IOVDD), U3.41 (IOVDD), U3.50 (IOVDD), U3.60 (IOVDD), U3.64 (VREG_VIN), U3.68 (USB_OTP_VDD), U3.69 (QSPI_IOVDD), U3.76 (IOVDD), U5.1 (VOUT), U5.10 (FB), U7.P$3 (3); also elsewhere on the board
/RP2350B/RUN: SW3.2, U3.35 (RUN)
/RP2350B/USB_D+: J6.3 (D+), R31.1
/RP2350B/USB_D-: J6.2 (D-), R32.1
/RP2350B/VREG_AVDD: C20.1, R26.2, U3.61 (VREG_AVDD)
/RP2350B/VREG_LX: L1.2, U3.63 (VREG_LX)
/RP2350B/XIN: C16.1, U3.30 (XIN), Y1.1
/RP2350B/XOUT: R28.1, U3.31 (XOUT)
AMP_SD: U3.48 (GPIO39); also elsewhere on the board
BATPWR_LDO: Q1.3 (D), U6.P$2 (2)
DB0: U3.12 (GPIO13); also elsewhere on the board
DB1: U3.13 (GPIO14); also elsewhere on the board
DB2: U3.14 (GPIO15); also elsewhere on the board
DB3: U3.16 (GPIO16); also elsewhere on the board
DB4: U3.17 (GPIO17); also elsewhere on the board
DB5: U3.18 (GPIO18); also elsewhere on the board
DB6: U3.19 (GPIO19); also elsewhere on the board
DB7: U3.20 (GPIO20); also elsewhere on the board
DB8: U3.21 (GPIO21); also elsewhere on the board
DB9: U3.22 (GPIO22); also elsewhere on the board
DB10: U3.23 (GPIO23); also elsewhere on the board
DB11: U3.25 (GPIO24); also elsewhere on the board
DB12: U3.26 (GPIO25); also elsewhere on the board
DB13: U3.27 (GPIO26); also elsewhere on the board
DB14: U3.28 (GPIO27); also elsewhere on the board
DB15: U3.36 (GPIO28); also elsewhere on the board
GND: C15.2, C16.2, C17.2, C18.2, C19.2, C20.2, C21.2, C22.2, C23.2, C24.2, C25.2, C26.2, C27.2, C28.2, C29.2, C30.2, C31.2, C32.2, C33.2, C34.2, C35.2, C36.2, C37.2, J5.2, J5.MP (Shield), J6.5 (GND), J6.6 (Pad), J6.SH (Shield), PWR1.2, R24.2, R34.2, R36.2, R39.2, SW1.1, SW2.1, U3.62 (VREG_PGND), U3.81 (GND), U4.2 (V_{SS}), U5.3 (PGND), U5.9 (GND), U5.11 (PGND), U6.P$4, U6.P$5, U6.P$6, U6.P$7, U7.P$4, U7.P$5, U7.P$6, U7.P$7, Y1.2 (G), Y1.4 (G); also elsewhere on the board
I2C0_SCL: U3.42 (GPIO33); also elsewhere on the board
I2C0_SDA: U3.40 (GPIO32); also elsewhere on the board
LORA_AUX: U3.38 (GPIO30); also elsewhere on the board
LORA_M01: U3.58 (GPIO47_ADC7); also elsewhere on the board
unnamed: C17.1, R28.2, Y1.3
unnamed: D4.2 (A), R42.2
unnamed: D4.1 (K), U4.1 (STAT)
unnamed: J5.1, R29.2
unnamed: J5.3, R27.2
unnamed: R24.1, SW3.1
unnamed: R25.2, SW2.2
unnamed: C23.1, R30.2, U3.59 (ADC_AVDD)
unnamed: C27.1, R33.2, R34.1, U3.49 (GPIO40_ADC0)
unnamed: R27.1, U3.33 (SWCLK)
unnamed: R29.1, U3.34 (SWD)
unnamed: R32.2, U3.66 (USB_DM)
unnamed: R31.2, U3.67 (USB_DP)
unnamed: R39.1, U4.5 (PROG)
unnamed: C33.1, U5.6 (EN), U5.7 (PS/SYNC), U5.8 (VINA)
unnamed: L2.1, U5.4 (L1)
unnamed: L2.2, U5.2 (L2)
PWM_AUDIO: U3.47 (GPIO38); also elsewhere on the board
QSPI_SCLK: U3.71 (QSPI_SCLK); also elsewhere on the board
QSPI_SD0: U3.72 (QSPI_SD0); also elsewhere on the board
QSPI_SD1: U3.74 (QSPI_SD1); also elsewhere on the board
QSPI_SD2: U3.73 (QSPI_SD2); also elsewhere on the board
QSPI_SD3: U3.70 (QSPI_SD3); also elsewhere on the board
QSPI_SS: R25.1, U3.75 (QSPI_SS); also elsewhere on the board
SCH16T_RESET: U3.56 (GPIO45_ADC5); also elsewhere on the board
SCH16T_SYNC: U3.57 (GPIO46_ADC6); also elsewhere on the board
SD_CLK: U3.79 (GPIO2); also elsewhere on the board
SD_CMD: U3.80 (GPIO3); also elsewhere on the board
SD_DAT0: U3.1 (GPIO4); also elsewhere on the board
SD_DAT1: U3.2 (GPIO5); also elsewhere on the board
SD_DAT2: U3.3 (GPIO6); also elsewhere on the board
SD_DAT3: U3.4 (GPIO7); also elsewhere on the board
SD_DETA: U3.8 (GPIO10); also elsewhere on the board
SPI1_CS: U3.52 (GPIO41_ADC1); also elsewhere on the board
SPI1_RX_MISO: U3.55 (GPIO44_ADC4); also elsewhere on the board
SPI1_SCK: U3.53 (GPIO42_ADC2); also elsewhere on the board
SPI1_TX_MOSI: U3.54 (GPIO43_ADC3); also elsewhere on the board
SW_TOGGLE: R8.2, SW1.2, U3.46 (GPIO37)
TFT_DC: U3.9 (GPIO11); also elsewhere on the board
TFT_MOSFET_G: U3.43 (GPIO34); also elsewhere on the board
TFT_RESET: U3.37 (GPIO29); also elsewhere on the board
TFT_SW: U3.44 (GPIO35), U7.P$2 (2)
TFT_WR: U3.11 (GPIO12); also elsewhere on the board
UART0_RX: U3.78 (GPIO1); also elsewhere on the board
UART0_TX: U3.77 (GPIO0); also elsewhere on the board
UART1_RX: U3.7 (GPIO9); also elsewhere on the board
UART1_TX: U3.6 (GPIO8); also elsewhere on the board
USB_SENS: R35.2, R36.1, U3.39 (GPIO31)
USR_LED: U3.45 (GPIO36); also elsewhere on the board
VBAT_IN: PWR1.1, U4.3 (V_{BAT}), U6.P$3 (3)
VBUS: D3.2 (A), J6.1 (VBUS), Q1.1 (G), R35.1, R42.1, U4.4 (V_{DD}); also elsewhere on the board
VSYS: C31.1, D3.1 (K), Q1.2 (S), R33.1, U5.5 (VIN)

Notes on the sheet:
Make sure USB_DP,USB_DM resistors are close to RP2350
(5V-2.0V)/200Ohm=15mA
12MHz Crystal
Power SW
移動 GPIO8->10
GPIO pin changed
Bat Discharger For Battery Safety
2.2k to limit current
Modyfied
USB to Lipo Charger
移動 34->36
RP2354B
BAT IN
Grounding P-Ch FET Gate float at the same time
E220 M01 移動
Power
移動 35->37

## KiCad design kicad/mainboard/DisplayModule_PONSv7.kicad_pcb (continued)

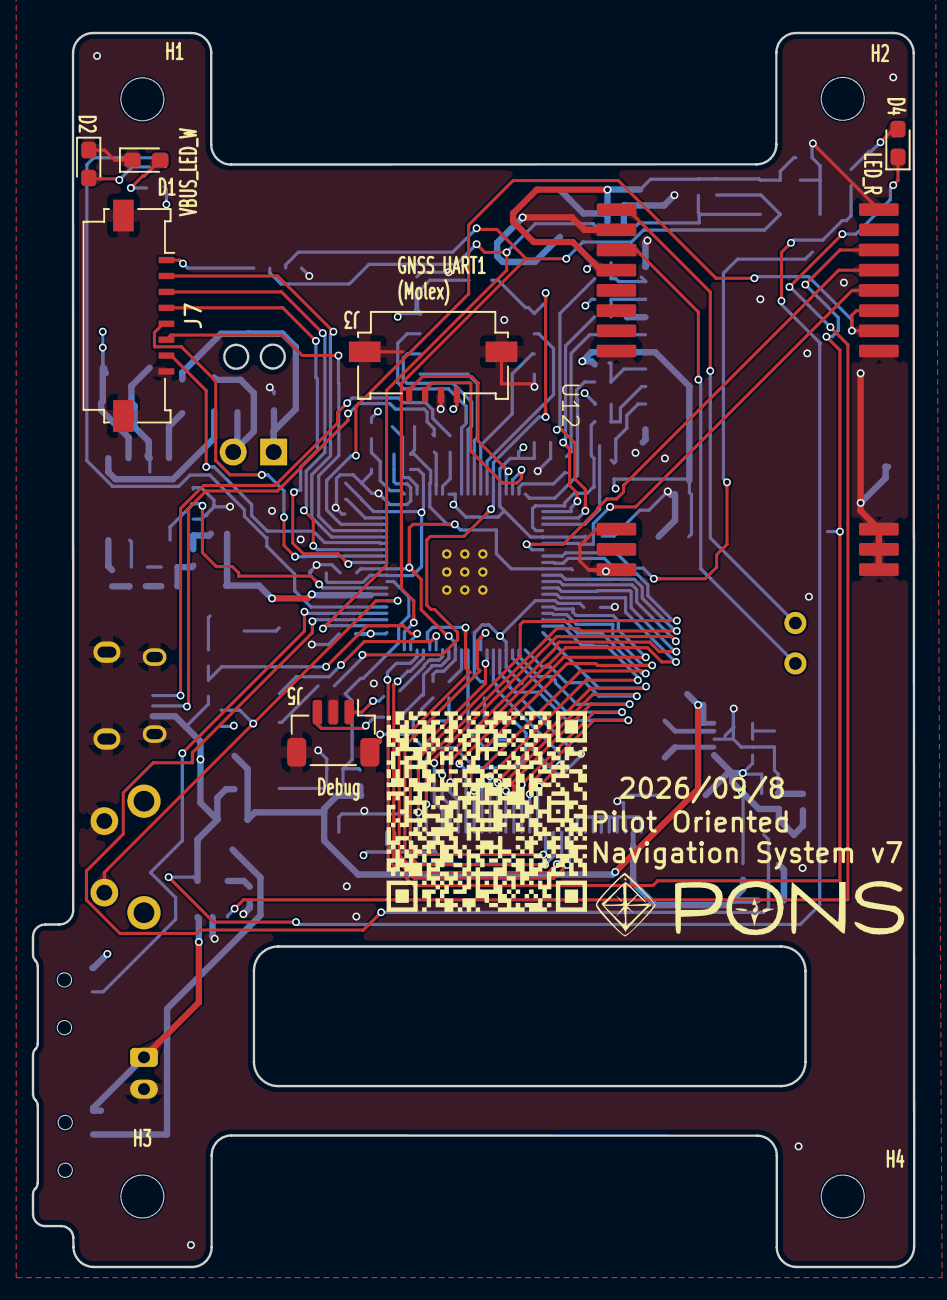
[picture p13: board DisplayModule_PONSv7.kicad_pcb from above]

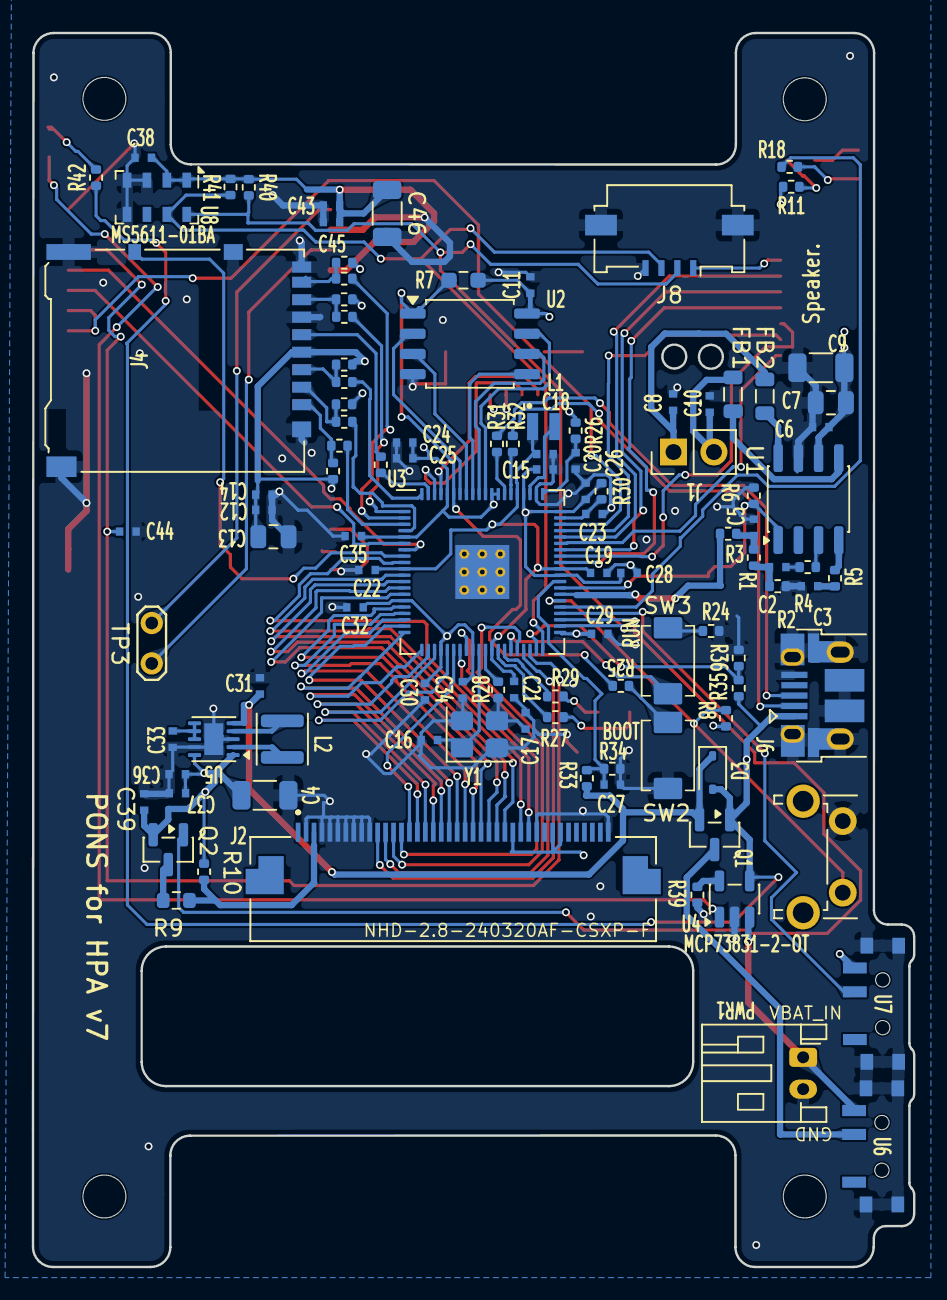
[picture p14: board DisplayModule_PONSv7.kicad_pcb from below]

Board: 4 copper layers, 55.4 x 77.6 mm, 119 parts (108 on the bottom side), 106 nets.

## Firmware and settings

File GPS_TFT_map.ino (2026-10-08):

// ============================================================
// File    : GPS_TFT_map.ino
// Project : PONS v7 (Pilot Oriented Navigation System for HPA)
// Role    : メインエントリポイント。
//           Core0: 画面描画・GNSS処理・ボタン入力・コース警告
//           Core1: SDカード操作・音声再生（タスクキュー経由）
//           地図背景はフラッシュ内蔵のベクタ地図（vectormap.cpp）を使う。
//           SDカード上のBMPタイル方式は廃止済み。
// Author  : MasaoC (@masao_mobile)
// Updated : 2026/10/08
// ============================================================
//
// ■ src/ に置いてあるもの
//   Arduino IDE はスケッチ直下のファイルを全部タブに出すので、
//   ファイルが増えるとタブが埋まって目的のものを探しづらくなる。
//   **仕様が固まっていて普段いじらないモジュール**は src/ へ移した。
//   src/ 配下もコンパイルはされるが、IDE のタブには出ない。
//     src/button.*     ボタン入力・メニュー
//     src/sound.*      音声出力（WAV・トーン）
//     src/vectormap.*  ベクタ地図の描画
//     src/imulog.*     生 IMU ロガー（姿勢 ESKF のオフライン開発用）
//     src/flashdata/   FLASH に置く大きな定数データ
//
//   ★ src/ の中からルート側のヘッダを参照するときは "../mysd.h" のように
//     1 段戻ること。スケッチ直下は include パスに入っていない。
// ============================================================

#include "navdata.h"
#include "display_tft.h"
#include "settings.h"
#include "mysd.h"
#include "src/button.h"
#include "gnss.h"
#include "src/sound.h"
#include "hardware/adc.h"
#include "airdata.h"
#include "imu.h"
#include "imu_sensor.h"   // imu_caps()（融合出力が有るかの判定）
#include "link.h"   // PONS Link（機体⇄ボート無線）
#include "src/imulog.h"
#include "attitude.h"
#include "src/vectormap.h"

// we need to do bool core1_separate_stack = true; to avoid stack running out.
// (Likely due to drawWideLine from TFT-eSPI consuming alot of stack.)
bool core1_separate_stack = true;  //DO NOT REMOVE THIS LINE.

// --- 画面更新タイミング管理 ---
unsigned long screen_update_time = 0;  // 最後に画面更新した時間 millis()
bool redraw_screen = false;            // true にすると次のループで画面を再描画する

// --- 旋回角速度 (deg/s) 計算用 ---
// GNSS の真方位 (truetrack) を NUM_SAMPLES 個のスライディングウィンドウで保持し、
// 連続サンプル間の変化量の合計を「最古サンプルと最新サンプルの経過時間」で割ることで
// GNSS レート（1Hz / 2Hz）に依存しない真の deg/s を算出する。
const int NUM_SAMPLES = 4;             // スライディングウィンドウのサンプル数
float truetrack_samples[NUM_SAMPLES];  // 過去の真方位サンプル配列
uint32_t truetrack_sample_times[NUM_SAMPLES];  // 各サンプルの millis() タイムスタンプ
int sampleIndex = 0;                   // 次に書き込むサンプルのインデックス
float degpersecond = 0;                // 算出された旋回角速度 [deg/s]

// --- 画面モード・スケール管理 ---
int screen_mode = MODE_MAP;  // 現在の画面モード（MODE_MAP / MODE_SETTING など）
int detail_page = 0;         // サブ画面（GNSSDetail / SDDetail）のページ番号
int replay_cursor = 0;       // リプレイ選択画面のカーソル位置（項目の通し番号）
int replay_list_page = 0;    // リプレイ選択画面で現在表示・読み込み済みのページ
// IMU/ESKF 画面（ページ1）のカーソル位置。display_tft.cpp の IMU_MENU_* と対応。
int imu_cursor = 0;
int imu2_cursor = 0;   // IMU/ESKF ページ2/3 のカーソル位置（BNO085 と校正）
int imu3_cursor = 0;   // IMU/ESKF ページ3/3 のカーソル位置（ESKF の調整）
// バンク角警告の有効/無効（IMU/ESKF 画面で切替、SD に保存）
double scalelist[6];         // 選択可能なスケール値リスト（ズームレベルに対応）
double scale;                // 現在のマップスケール [pixels/km]

// --- 設定画面カーソル状態 ---
// selectedLine == -1: 値変更モードでない（カーソル移動のみ）
// selectedLine >= 0:  その行の値を変更中
int selectedLine = -1;
int cursorLine = 0;

// --- コース警告 ---
// course_warning_index: 0〜900 の積算値（単位: 度・秒）。
// コースから外れているほど増加し、900 に達すると音声警告を発する。
// dt 乗算で小数加算が発生するため float 型で保持する。
float course_warning_index = 0;
// バンク角警告でミラー値を受けるための一時変数（判定式の中で使う）
static float bank_roll_tmp = 0.0f, bank_pitch_tmp = 0.0f;
unsigned long last_course_warning_time = 0;      // 直近の警告発報時刻 [millis]
unsigned long last_destination_toofar_time = 0;  // 直近の「目的地が遠すぎる」警告時刻 [millis]
double steer_angle = 0.0;  // 現在針路と目的地方位の差 (-180〜+180 度。正=右、負=左)

// --- 大気データ シリアル出力タイミング管理 ---
unsigned long last_airdata_print_time = 0;  // 最後に気温・気圧を Serial 出力した時間 [millis]
bool airdata_updated = false;               // airdata_update() が true を返した直後フラグ（VSI 更新トリガー）

// --- ユーザーLED 制御 ---
// userled_forced_on: タスクキュー溢れなど重篤エラー時に永続点灯させるフラグ（一度 true になったらリセットまで戻らない）
volatile bool userled_forced_on = false;

// ---- 処理時間計測変数（BNO085配置コア決定用、デバッグビルドのみ） ----
#ifndef RELEASE
TimingStat ts_redraw = TSTAT_INIT("C0_redraw");
volatile bool c0_is_redrawing = false;  // Core1側の重複検出用フラグ
#endif

// --- Core1 スタック残量計測用ベース SP ---
// setup1() の先頭で現在の SP をキャプチャし、以降の使用量計測の基準にする。
// core1_separate_stack=true のため Core1 のスタックはヒープから動的確保されており、
// リンカシンボルでは下限がわからないため、この方法で代替する。
volatile uint32_t _core1_base_sp = 0;

volatile int scaleindex = 3;    // scalelist のインデックス（初期値 3 = SCALE_LARGE_GMAP）
volatile int sound_volume  = 50; // 音量 0〜100
volatile int vario_volume  = 10; // バリオメーター音量 0〜100（設定画面から変更可）
volatile bool vario_inhibit = false; // true のとき vario は完全無効（SDカード settings.txt でのみ設定可）

extern volatile bool loading_sddetail;
extern bool sd_detail_loading_displayed;

void reset_degpersecond();
void update_degpersecond(float true_track);
void check_destination_toofar();
static void apply_auto10k_status(int st);
void update_course_warning(float degpersecond);
static void nav_alarm_tick(bool new_gnss_info);
// 最後にボタンが操作された時刻。設定画面の放置タイムアウト（下の SETTING_IDLE_TIMEOUT_MS）用。
// 3 つのコールバックの先頭で更新するので、押し方の種類によらず必ず記録される。
static unsigned long last_user_input_ms = 0;
void shortPressCallback();
void longPressCallback();
void doublePressCallback();
static void imu_execute();
void next_scaleindex();
// 設定画面のラベル用に、現在のスケールで画面横幅(240px)が何 km に相当するかを返す。
// 以前は Google タイルのズーム番号(zoom5〜13)を表示していたが、ベクタ地図に移行して
// タイルとの対応が無くなったため、実際の距離で表すようにした。
float scale_screen_km(int index);
// Create Button objects
Button sw_push(SW_PUSH, shortPressCallback, longPressCallback, doublePressCallback);

// USERLED フラッシュ制御（Core0 のループから毎回呼ぶ）。
// 条件ごとの LED 動作:
//   永続点灯 (userled_forced_on): タスクキュー溢れなどの致命エラー → 消灯しない
//   2 回点滅: SD エラー   → 1 秒に 2 回、各 20ms
//   1 回点滅: 衛星 0      → 1 秒に 1 回、20ms
//   正常時:   消灯
// **両方成立したら SD を優先する。** 衛星 0 は屋内なら普通に起きるうえ、直れば
// 何も失われない。SD エラーは「飛行が一切記録されていない」ことを意味し、
// 後から取り返せないので、そちらを見せる。
// （画面ヘッダーには sats バッジと SD バッジの両方が出ている。LED はそれを
//   見ていないとき用の手段なので、画面に出る／出ないは優先順位の理由にならない。）
//
// ★ 時間待ちをしない。delay() を入れると Core0 が止まり、BNO085 のレポートが溜まって
//   ジャイロが化ける（CLAUDE.md「BNO085 の読み出しを飢えさせない」）。
// ★ **「いま位相が点灯区間か」で判定してはいけない。** Core0 の 1 周は地図描画中に
//   数十 ms になる（60 秒ログの gapmax= が実測値。40ms 前後）。20ms の点灯区間を
//   サンプリングで当てに行くと**ほとんど素通りして光らない**。
//   そのため「周期が来たら点ける → 20ms 経ったら消す」の**立ち上がりラッチ方式**にしてある。
//   こうすると 1 周が 20ms を超えても、点灯が長引くだけで発数は必ず出る。
void loop_userled() {
  // 致命エラー時は永続点灯のまま。**ここで毎回 HIGH を打ち直すこと。**
  // 立てるのは Core1 の enqueueTask()（mysd.cpp）で、フラグを立ててから
  // digitalWrite(HIGH) する。Core0 がその直前にフラグを false と読んでいると、
  // 下の消灯がこの HIGH を**後から上書きして LED が消えたまま戻らない**
  // （以降は毎回この return で抜けるので二度と点かない）。打ち直せば次の周回で治る。
  if (userled_forced_on) {
    digitalWrite(USERLED_PIN, HIGH);
    return;
  }

  // 時刻はすべて符号なしの引き算で比べる（millis() の折り返しでも正しい）。
  static unsigned long cycle_start = 0;  // いまの点滅周期の開始時刻
  static unsigned long pulse_start = 0;  // いま出している 1 発の開始時刻
  static uint8_t       pulses_left = 0;  // この周期であと何発打つか
  static bool          led_on      = false;

  const bool sd_ng  = !good_sd();               // Core0 から呼ぶと状態を読むだけ（復旧は Core1 側）
  const bool no_sat = (get_gnss_numsat() == 0);

  if (!sd_ng && !no_sat) {
    digitalWrite(USERLED_PIN, LOW);
    led_on = false;  // 消したことを状態にも反映する（次にエラーへ落ちたとき点け直せるように）
    // 打ち残しも捨てる。残したまま同じ周期内でエラーへ戻ると、GAP を過ぎている分
    // **2 発目だけが即座に出て**、衛星 0（1 回点滅）が SD 異常（2 回点滅）に見える。
    pulses_left = 0;
    return;
  }

  const unsigned long now = millis();

  if (now - cycle_start >= USERLED_BLINK_PERIOD_MS) {
    // 新しい周期の先頭。ここで発数を決める（周期の途中で SD が壊れても、
    // パターンが変わるのは次の周期から。1 秒以内なので実用上の遅れは無い）。
    cycle_start = now;
    pulses_left = sd_ng ? 2 : 1;
    pulse_start = now;
    pulses_left--;
    led_on = true;
  } else if (led_on) {
    // 点灯中: 規定時間が過ぎたら消す。1 周が 20ms より長いと点灯もその分伸びるが、
    // 「光った」ことは必ず見える。
    if (now - pulse_start >= USERLED_BLINK_PULSE_MS) led_on = false;
  } else if (pulses_left > 0 && now - cycle_start >= USERLED_BLINK_GAP_MS) {
    // 2 発目（SD エラーのときだけ残っている）。
    pulse_start = now;
    pulses_left--;
    led_on = true;
  }

  digitalWrite(USERLED_PIN, led_on ? HIGH : LOW);
}

//===============SET UP CORE0=================
// Core0 の初期化処理。
// 初期化順の注意:
//   1. TFT を先に初期化しないとボタンピン設定が正常に動作しない（TFT_eSPI の制約）。
//   2. GNSS は TFT 初期化後に setup する（バッファオーバーフロー防止のため）。
void setup(void) {
  Serial.begin(38400);
  #ifndef RELEASE
    // デバッグ時はシリアルモニタが繋がるまで待機（RELEASE では即開始）
    while (!Serial) {
      delay(10);
    }
  #endif

  // ユーザーLED 初期化（起動時は消灯）
  pinMode(USERLED_PIN, OUTPUT);
  digitalWrite(USERLED_PIN, LOW);
  // バッテリー電圧監視用 ADC の初期化
  adc_gpio_init(BATTERY_PIN);
  pinMode(USB_DETECT, INPUT);
  pinMode(BATTERY_PIN, INPUT);
  pinMode(SD_DETECT, INPUT_PULLUP);  // SDカード検出ピン（挿入時 LOW）
  analogReadResolution(12);  // 12bit = 0〜4095

  //setup switch
  pinMode(sw_push.getPin(), INPUT_PULLUP);  // This must be after setup tft for some reason of library TFT_eSPI.
  setup_tft();
  // ★ **ここでタイトルを出しておく。**これが無いと起動画面が始まるまで画面が真っ白になる。
  //   白のままの区間は imu_setup()（BNO085 のリセット〜ブートで約 0.4 秒）と
  //   gnss_setup() で、**GNSS 未接続だと後者が約 3.7 秒**かかる
  //   （CFG の ACK 待ちが 5 コマンドぶん空振りする。log.txt の "GNSS CFG NO ACK"）。
  //   GNSS を繋げば ACK が即返るので 1 秒以下に縮む。**固まっているわけではない。**
  draw_boot_title();
  // BNO085 の NRST を早期に HIGH に固定する（内蔵プルアップ）。
  // RP2350 GPIO は電源投入直後フローティングになるため、imu_setup() が呼ばれるまでの間に
  // NRST が偶然 LOW になって BNO085 がリセット状態に入るのを防ぐ。
#if defined(IMU_RST_PIN) && IMU_RST_PIN >= 0
  pinMode(IMU_RST_PIN, INPUT_PULLUP);
#endif

  // ★★ **setup() の間は生 IMU ログを止める。**
  //   バッファの排出 imulog_take_pending() は **loop() からしか呼ばれない**ので、
  //   setup() 中に貯めるとバッファ 2 枚（IMULOG_RECS_PER_BUF × 2）で満杯になり、
  //   **それ以降は全部捨てられる**。捨てても seq は進むため、PC 側には
  //   「取りこぼし」として残り、decode_imulog.py のセッション分割を誤らせる。
  //   起動画面の間の生データは机上の値で使い道が無いので、記録しない。
  //   ★ 解除は明示的に書かない。loop() 冒頭の
  //     imulog_set_paused(getReplayMode()) が毎周回セットし直すので、
  //     loop() の 1 回目で自動的に解ける（リプレイ中なら正しく止まったまま）。
  imulog_set_paused(true);

  // I2C バス初期化（MS5611・BNO085 共用。両 setup より先に呼ぶ）
  airdata_wire_begin();
  // BNO085 を先に初期化する（リセット後のブート時間を確保するため）
  imu_setup();
  attitude_setup();   // 姿勢 ESKF（センサー入力は imu.cpp/gnss.cpp から流し込む）
  // ★ ここで一度描く。BNO085 の結果は分かった時点ですぐ出す
  //   （draw_boot_diag(0) まで待つと「INITIALIZING SENSORS ...」のまま約1秒固まって見える）。
  BootCheckState imu_check = get_imu_ok() ? BOOT_CHECK_OK : BOOT_CHECK_NG;
  draw_boot_progress(imu_check, BOOT_CHECK_PENDING, BOOT_CHECK_PENDING);

  // MS5611 初期化（BNO085 の後に呼ぶ）
  airdata_setup();
  BootCheckState airdata_check = get_airdata_ok() ? BOOT_CHECK_OK : BOOT_CHECK_NG;
  draw_boot_progress(imu_check, airdata_check, BOOT_CHECK_PENDING);

  // 両センサーの初期化完了後にセンサー組み合わせをログ出力する
  if (!get_imu_ok() && !get_airdata_ok()) {
    enqueueTask(createLogSdTask("VARIO: NO SENSORS - BNO085 and MS5611 both absent"));
  } else if (get_imu_ok() && !get_airdata_ok()) {
    enqueueTask(createLogSdTask("VARIO: BNO085 only - Kalman inactive, V/S=0"));
  } else if (!get_imu_ok() && get_airdata_ok()) {
    enqueueTask(createLogSdTask("VARIO: MS5611 only - baro-only fallback"));
  } else {
    enqueueTask(createLogSdTask("VARIO: BNO085+MS5611 Kalman fusion enabled"));
  }

  gnss_setup();
  draw_boot_progress(imu_check, airdata_check, get_gnss_cfg_ok() ? BOOT_CHECK_OK : BOOT_CHECK_NG);

  // ★ SD から読んだ設定が揃うのを待つ。**この下の 2 つが両方それを使う。**
  //     link_setup()       … CH / SF / 送受信モード
  //     startup_demo_tft() … 地図データ件数 / upward_mode
  //   Core1 が SD を初期化している間に Core0 が SD を触ると SDIO バスが競合して
  //   固まるので、待ちは必須。5 秒で打ち切るのは SD 不良の機体でも起動させるため
  //   （打ち切った場合は log.txt の LINK SETUP の settings=0 で後から判別できる）。
  {
    unsigned long t = millis();
    while (!sd_setup_complete && millis() - t < 5000) {
      gnss_loop(7);       // 待機中も GNSS FIFO を読み捨てて overflow 防止
      imu_service_if_due();  // ★ BNO085 も引き取る（CLAUDE.md「飢えさせない」）
      delay(10);
    }
  }

  // ★ **起動画面より先に無線を開く。** 起動画面の下段に E220 の結果を出すため
  //   （ここより後だと、結果が出る頃には loop() が画面を描き替えてしまう）。
  //   読み上げと送信前チェックはここではやらない。setup() 末尾を見ること。
  link_setup();

  startup_demo_tft();

  // スケールリストの初期化（Google Map のズームレベルに対応する pixel/km 値）
  scalelist[0] = SCALE_EXSMALL_GMAP;  //pixelsPerDegreeLat(5,35)/KM_PER_DEG_LAT; 最広域（日本全体スケール）
  scalelist[1] = SCALE_SMALL_GMAP;    //pixelsPerDegreeLat(7,35)/KM_PER_DEG_LAT;
  scalelist[2] = SCALE_MEDIUM_GMAP;   //pixelsPerDegreeLat(9,35)/KM_PER_DEG_LAT;
  scalelist[3] = SCALE_LARGE_GMAP;    //pixelsPerDegreeLat(11,35)/KM_PER_DEG_LAT;
  scalelist[4] = SCALE_EXLARGE_GMAP;  //pixelsPerDegreeLat(13,35)/KM_PER_DEG_LAT;
  scalelist[5] = 200.0;               // 最大拡大
  scale = scalelist[scaleindex];
  redraw_screen = true;
  {
    // get_input_voltage() のピーク追跡（max_adreading）を通した値を記録する。
    // analogRead() の 1 発読みだと ADC のノイズがそのまま乗り、USB を抜いた直後などに
    // 実際より低い値がログに残ることがあった。
    // 起動直後は max_adreading が 0 なので、数サンプル回して追跡を立ち上げてから読む。
    // ここは setup() の末尾なので、16ms 程度の待ちは起動時間に影響しない。
    // 併せて、この後の最初のヘッダー描画も落ち着いた値から始められる。
    float startup_voltage = 0.0f;
    for (int i = 0; i < 16; i++) {
      startup_voltage = get_input_voltage();
      delay(1);
    }
    enqueueTask(createLogSdfTask("SETUP DONE Battery: %.2fV", startup_voltage));
  }

  // 無線モードの読み上げ。起動音(opening.wav)の後に鳴らしたいので、
  // link_setup() を前へ移したあともここに残してある。
  link_announce_mode();

  // ★ 送信前チェックの監視窓は**ここで張り直す。必ず loop() の直前で。**
  //   窓(5 秒)は millis() 基準なので、link_setup() の中で開始したままだと
  //   startup_demo_tft() のアニメーション(約 8 秒)の間に窓が過ぎてしまい、
  //   雑音を 1 サンプルも取れずに NOT MEASURED で終わる。
  link_preflight_restart();
}
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
void loop() {
  // 無線モジュールとの UART。1Hz・数十バイトなので負荷は無視できる。
  // 無線モジュールが繋がっていなくても、link_module_alive() が false になるだけで無害。
  link_loop();
  //switch handling
  sw_push.read();
  // 地図画面以外（設定画面・リプレイ選択画面・各詳細画面）を開いている間は
  // リプレイを一時停止する。戻ってきたら続きから再生される。
  replay_set_paused(screen_mode != MODE_MAP);
  // 生 IMU ログを止めるのはリプレイ中だけ
  //（Euler ログと同じ理由: 再生日時のファイルを実センサ値で汚さない）。
  //
  // ※ GNSS 日時の有効性では止めないこと。
  //   以前は日時未確定でも止めていたが、それだと屋内など測位できない場所で
  //   IMU の生ログが一切取れず（wrote=0）、ベンチでの検証ができなかった。
  //   日時が無いときは下でファイル名を imuraw/nofix.bin にフォールバックする。
  //   レコードはすべてホスト時刻 t_us を持つので、日付が無くても解析はできる。
  imulog_set_paused(getReplayMode());
  gnss_loop(0);  // ループ先頭で GNSS データを受信
  loop_userled();  // USERLED フラッシュ制御（0衛星・SDエラー時）

  // GNSS モジュールの断線／復帰を log.txt に残す。
  // ★ 表示は draw_gnss_disconnect_warning()（地図の上にマゼンタの枠）だが、
  //   **画面を見ていなければ気づけない**。飛行 CSV には「位置が止まった」ことしか
  //   残らないので、原因が断線だったのかフィックス喪失だったのかを後から
  //   切り分けられるようにする。判定は get_gnss_connection()（gnss.cpp）。
  // ★ 起動直後（まだ 1 バイトも来ていない）では鳴らさない。一度でも繋がってから
  //   切れたときだけ残す。最初の接続そのものは基準を置くだけで記録しない。
  {
    static bool     ever_conn = false, prev_conn = false;
    static uint32_t lost_alert_ms = 0;
    const bool conn = get_gnss_connection();
    if (!ever_conn) {
      if (conn) { ever_conn = true; prev_conn = true; }
    } else if (prev_conn != conn) {
      prev_conn = conn;
      if (conn) {
        enqueueTask(createLogSdTask("GNSS connection restored"));
        // ★ 復帰は断線の**逆向き**（392 → 784）。同じ 2 音の上昇と下降で対にする。
        //   880 → 1318 は使わない。あれは**無線の電波復帰**で既に使っており、
        //   同じ音が 2 つの意味を持つと現場で取り違える（docs/pons_sound.md §10）。
        enqueueTask(createPlayMultiToneTask(392, 120, 1, 2));
        enqueueTask(createPlayMultiToneTask(784, 160, 1, 2));
        lost_alert_ms = 0;
      } else {
        enqueueTask(createLogSdTask("!!ERROR!! GNSS connection LOST"));
        lost_alert_ms = 0;   // 0 にしておくと下の繰り返しが即座に 1 回目を鳴らす
      }
    }
    // ★ 切れている間は GNSS_LOST_ALERT_MS ごとに繰り返す。
    //   **下降 2 音（784 → 392、1 オクターブ下降）**。他の警報はすべて上昇か
    //   同音の連打なので、下降は「何かが失われた」専用の形になる。
    if (ever_conn && !conn &&
        (lost_alert_ms == 0 || millis() - lost_alert_ms >= GNSS_LOST_ALERT_MS)) {
      lost_alert_ms = millis();
      enqueueTask(createPlayMultiToneTask(784, 200, 1, 3));
      enqueueTask(createPlayMultiToneTask(392, 300, 1, 3));
    }
  }

  // GNSS Fix 取得時に音声で通知（false→true の立ち上がりエッジを検出）
  // "wav/fixed.wav" は本体 FLASH にあるので SD の有無に関係なく鳴る
  // （0.982 まではここに SD が無いときのチャイム音（ド・ミ・ソ）の代替があった）。
  {
    static bool prev_gnss_fix = false;
    bool cur_fix = get_gnss_fix();
    if (!prev_gnss_fix && cur_fix) {
      enqueueTask(createPlayWavTask("wav/fixed.wav", 4));  // 優先度4: AUTO10Kトーン(p=3)より高くして埋もれないよう
      enqueueTask(createLogSdTask("GNSS FIX acquired"));
    }
    prev_gnss_fix = cur_fix;
  }

  // 大気データ更新（非ブロッキングのステートマシン。毎ループ呼ぶことで約50Hzで計測）
  airdata_updated = airdata_update();

  // IMU 更新（H_INT フラグ確認 → データ読み出し → Kalman predict。毎ループ呼んでよい）
  imu_update();

  // ROTATION_VECTOR 更新時（5Hz）かつ GNSS 日時有効時 → Euler角を JST 時刻で SD ログ
  // リプレイ中は記録しない。リプレイ中の日時は CSV 由来のため、そのまま記録すると
  // 「再生した飛行の日付」のファイルに現在の（静止した）IMU 値を追記してしまい、
  // 実際の飛行記録を汚してしまう。下の prev_jst_cs による単調増加チェックも
  // 再生日時に引きずられて、通常モードに戻ったあと記録が止まる原因になる。
  int jst_year, jst_month, jst_day, log_h, log_m, log_s, log_cs;
  bool jst_valid = get_jst_now(jst_year, jst_month, jst_day, log_h, log_m, log_s, log_cs);

  // ---- リプレイ用 ESKF 結果ログ（画面の再現に使う）----
  // ESKF が未収束の間は書かない。行が無い＝そのとき画面にも出ていなかった、を意味する。
  // 契機は BNO085 のレポート到着ではなく固定周期にする。ESKF の出力は連続なので、
  // レポートの到着ゆらぎで間隔がばらつくと再生が不均一になるため。
  // 保険として実測の GNSS フィックスも要求する。日時が再生由来のまま残っていると
  // 過去の日付のファイルへ机の上の値を書き込んでしまうため（set_replaymode() 参照）。
  static uint32_t last_replaydata_ms = 0;
  // ミラー中も記録しない（受信した機体の日時のファイルに、自機の姿勢を書いてしまう）
  if (!getReplayMode() && !link_mirror_active() &&
      jst_valid && get_gnss_fixok() && attitude_ready() &&
      attitude_get_rpy_enabled() &&
      (millis() - last_replaydata_ms) >= IMU_REPLAYDATA_INTERVAL_MS) {

    // モノトニック保証: GNSS パケット間の処理遅延の揺れでタイムスタンプが
    // 逆転することがあるため、前回より小さい場合はこの読み取りをスキップする。
    static int32_t prev_jst_cs = -1;
    int32_t this_jst_cs = (int32_t)log_h * 360000L + log_m * 6000 + log_s * 100 + log_cs;
    if (prev_jst_cs < 0 || this_jst_cs > prev_jst_cs) {
      prev_jst_cs = this_jst_cs;
      last_replaydata_ms = millis();

      char rd_fname[32];   // "imu_replaydata/20260316.txt" = 27文字
      snprintf(rd_fname, sizeof(rd_fname), "%s/%04d%02d%02d.txt",
               IMU_REPLAYDATA_DIR, jst_year, jst_month, jst_day);

      // 画面に出ているのと同じ値を残す（マウント補正・ゼロ点・自動トリム適用後）
      float a_roll, a_pitch, a_yaw;
      attitude_get_euler(a_roll, a_pitch, a_yaw);

      // 風は推定できていない区間があるので、有効フラグ付きで渡す（無効なら空欄で書かれる）
      float a_wspd = 0.0f, a_wdir = 0.0f;
      const bool a_wind_ok = attitude_get_wind(a_wspd, a_wdir);

      enqueueTask(createLogImuReplayTask(log_h, log_m, log_s, log_cs,
                                         a_roll, a_pitch, a_yaw,
                                         attitude_get_pitch_avg_deg(),
                                         attitude_pitch_avg_valid(),
                                         attitude_get_roll_trim_deg(),
                                         attitude_get_yaw_acc95_deg(),
                                         a_wspd, a_wdir, a_wind_ok,
                                         rd_fname,
                                         jst_year, jst_month, jst_day));
    }
  }

  // ---- 生 IMU ログ: 満杯になったバッファを Core1 へ引き渡す ----
  // imulog_take_pending() が 0/1 を返したら、そのバッファは「Core1 へ引き渡し済み」に
  // マークされているため、必ずタスクを enqueue しないとバッファが解放されず Core0 が詰まる。
  // リプレイ中は記録しない（Euler ログと同じ理由: 再生日時のファイルを実センサ値で汚さない）。
  if (!getReplayMode()) {
    int imulog_buf = imulog_take_pending();
    if (imulog_buf >= 0) {
      char imu_fname[24];
      bool queued;
      if (jst_valid) {
        snprintf(imu_fname, sizeof(imu_fname), IMULOG_DIR "/%04d%02d%02d.bin",
                 jst_year, jst_month, jst_day);
        queued = enqueueTask(createFlushImuLogTask(imulog_buf, imu_fname,
                                                  jst_year, jst_month, jst_day,
                                                  log_h, log_m, log_s));
      } else {
        // GNSS 未測位（屋内テスト等）。日付が決まらないので合言葉を渡す。
        // Core0 から SD は触れないので、実ファイル名（imuraw/nofixNNN.bin）の決定は
        // Core1 側の imulog_write_buffer() がやる。番号を振るのは、固定名 1 つだと
        // 複数日・複数起動が 1 ファイルに混ざって切り分けられなくなるため。
        // レコードはホスト時刻 t_us と BOOT レコードを持つので、これでも解析はできる。
        // ファイルのタイムスタンプは SdFat の下限（1980 年以降）を満たす固定値にする。
        // 書式文字列としてではなく %s で渡す（パスに % が混ざっても壊れないように）
        snprintf(imu_fname, sizeof(imu_fname), "%s", IMULOG_NOFIX_REQUEST);
        queued = enqueueTask(createFlushImuLogTask(imulog_buf, imu_fname,
                                                  2020, 1, 1, 0, 0, 0));
      }
      // キュー満杯でタスクが捨てられたらバッファを戻す。
      // 戻さないと busy のままになり、2 枚とも失った時点で記録が恒久停止する。
      if (!queued) imulog_release_pending(imulog_buf);
    }
  }

  // 気圧高度が更新されたタイミングで Kalman 観測ステップを実行する
  // ※ update の実レートは約 3.7Hz。~40Hz ではない（2026-08-18 に実ログで確認）。
  //   MS5611 自体は ~40Hz でサンプルするが、airdata_update() が true を返すのは
  //   VSPEED_WINDOW_MS(250ms) のトリム平均ウィンドウが完了したときだけのため
  //   （プロペラ干渉 ~4.5Hz を除去する意図的な設計。airdata.cpp 参照）。
  //   したがって predict:update の比はおよそ 33:3.7 ≒ 9:1 になる。
  if (airdata_updated) {
    imu_kalman_baro_update(get_airdata_altitude());
    // 生 IMU ログにも気圧を残す（ESKF の検証と高度の突き合わせ用）
    imulog_push(IMULOG_ID_BARO, 0, IMULOG_ACC_NONE,
                get_airdata_pressure(), get_airdata_altitude(), get_airdata_temperature());
  }

  // GNSS高度による気圧基準補正（3Dフィックス有効時のみ、内部で1秒レート制限）
  // Vertical speed は変更せず、高度の長期ドリフトをゆっくり修正する。
  //
  // リプレイ中は実行しない。リプレイ中の GNSS 高度は CSV 由来（再生した飛行場所の高度）
  // であり、GNSS 垂直速度に至っては更新されず直前の実測値のまま残る。これらを Kalman に
  // 入れると airdata_adjust_ground_alt() が実際の気圧基準を書き換え、_gnss_kf_offset も
  // ずれてしまう。どちらもリプレイ終了後まで残り、通常モードに戻っても V/S が
  // 再生中のように動き続ける原因になる。
  // ★ 無線のミラー中も同じ理由で通さない。ミラー中の get_gnss_altitude() は
  //   受信した「機体」の高度なので、これを自機のカルマンに入れると
  //   気圧基準と _gnss_kf_offset が壊れ、リプレイと同様に受信をやめた後まで残る。
  if (!getReplayMode() && !link_mirror_active() &&
      get_gnss_fixok() && get_gnss_fixtype() >= 3) {
    imu_kalman_gnss_update(
      (float)get_gnss_altitude(),
      get_gnss_vacc_mm() / 1000.0f
    );
    // GNSS 垂直速度を KF 速度観測として追加（vAcc ゲート、sAcc で R 計算）
    // BNO085 の有無によらず動作し、加減速中や BNO085 なし時のバリオ精度を補完する。
    imu_kalman_gnss_vel_update(
      get_gnss_veld_mps(),
      get_gnss_vacc_mm()   / 1000.0f,
      get_gnss_sacc_mmps() / 1000.0f
    );
  }

  // バリオメーター音更新（内部で 100ms レート制限。毎ループ呼んでよい）
  update_vario();
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

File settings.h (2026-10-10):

// ============================================================
#pragma once
// File    : settings.h
// Project : PONS v7 (Pilot Oriented Navigation System for HPA)
// Role    : プロジェクト全体の設定・定数・マクロ定義。
//           デバッグフラグ、GNSS/TFT種別選択、ハードウェアピン番号、
//           画面モード定数、バッテリー計算式など全設定の司令塔。
// Author  : MasaoC (@masao_mobile)
// Updated : 2026/10/10
// ============================================================
//====== 設定画面 =======
#include <stdint.h>  // uint32_t 等の整数型定義（DEBUG_STACK マクロで使用）

// ============================================================
//  リリース前に確認するスイッチ
// ============================================================
// ★ RELEASE が無いと setup1() が while(!Serial) で USB 接続を待ち、実機が起動しない。
//   RELEASE_GNSS 以外（DEBUG_GNSS_SIM_*）を選んだままだと GNSS が疑似値になる。
//   どちらかが抜けているとコンパイル時に #warning NOT RELEASE! が出る。これが唯一の保険。
// リリース時
#define RELEASE
//#define DEBUG_ESKF

#define BUILDDATE 20261010
#define BUILDVERSION "0.987"

// ============================================================
//  基板の世代（**ピン割り当てと IMU がまるごと変わる**）
// ============================================================
//   v7   … 初代。BNO085 を i2c1(GPIO34/35) で実装。E220 の M0/M1 は GPIO41
//   v7.1 … BNO085 を降ろし、SCH16T を J7（Molex 200528-0080・8pin FPC）で外付け。
//          GPIO41-44 が SPI1 一式になり、E220 の M0/M1 は GPIO47 へ移った
//
// ★★ **同じ GPIO が板によって逆の意味になる。** ピンを足すときは必ずここで分けること。
//   コメントで「新基板では〜」と断り書きを増やす形にすると、必ずどこかが追従漏れする
//   （0.986 の時点で 5 ファイル 20 箇所まで増えていた）。
//     GPIO41    v7: E220 M0/M1          → v7.1: SCH16T CS
//     GPIO42    v7: i2c1 と短絡（park 対象） → v7.1: SCH16T SCK
//     GPIO43    v7: BNO085 SA0          → v7.1: SCH16T MOSI
//     GPIO44    v7: i2c1 と短絡（park 対象） → v7.1: SCH16T MISO
//     GPIO45    v7: BNO085 H_INTN       → v7.1: SCH16T EXTRESN
//     GPIO46    v7: BNO085 NRST         → v7.1: SCH16T DRY(SYNC)
//     GPIO47    v7: BNO085 PS0/WAKE     → v7.1: E220 M0/M1
//     GPIO34/35 v7: i2c1 SDA/SCL        → v7.1: TFT バックライト（TFT_eSPI 側の設定）
//
// ★★ **park 処置（imu_bus_park_unused_pins）は v7 だけ。** v7.1 で GPIO42/44 を
//   INPUT_PULLUP のまま放置すると **SPI1 が死ぬ**。向きが逆になる唯一の約束。
//   0.986 の分割で実体は imu_bno08x.cpp の中だけになり、あのファイルは
//   #if IMU_SENSOR_DEFAULT == IMU_SENSOR_BNO085 で囲ってあるので v7.1 では消える。
//
// ★ 載っているセンサーは基板で決まるので、IMU_SENSOR_DEFAULT もここから導く
//   （SD の settings.txt では切り替えられない。理由は IMU_SENSOR_* の節）。
#define PONS_BOARD_V7    70   // 初代 v7（BNO085）
#define PONS_BOARD_V71   71   // v7.1（SCH16T 外付け）

// ★★ **いまはまだ V7。** V71 にすると SCH16T のドライバが無いので #error で止まる
//   （imu.cpp の分割は 0.986 で済んだ。残りは imu_sch16t.cpp だけ。計画書 §1）。
//   ドライバを実機で検証できたら、ここを PONS_BOARD_V71 にするのが切替点。
#define PONS_BOARD       PONS_BOARD_V7

#if PONS_BOARD != PONS_BOARD_V7 && PONS_BOARD != PONS_BOARD_V71
  #error "PONS_BOARD は PONS_BOARD_V7 か PONS_BOARD_V71 のどちらか"
#endif

// 起動画面に出す基板世代の表記。PONS_BOARD から導く（手で二重管理しない）。
#if PONS_BOARD == PONS_BOARD_V71
  #define VERSION_TEXT "Version 7.1"
#else
  #define VERSION_TEXT "Version 7"
#endif

//----------GNSS---------
// GNSS は u-blox SAM-M10Q 固定（v6 ハードウェア）。
// v5 以前の Quectel LC86G / Mediatek 対応コードは v0.947 で削除した。
//#define DEBUG_GBX_NMEA

//GNSSのデバッグ用途。ひとつだけ選択。【リリース版は、RELEASE_GNSSを選択】
  #define RELEASE_GNSS
  //#define DEBUG_GNSS_SIM_SHINURA         //新浦安固定座標
  //#define DEBUG_GNSS_SIM_BIWAKO         //琵琶湖固定座標
  //#define DEBUG_GNSS_SIM_SAPPORO         //札幌固定座標
  //#define DEBUG_GNSS_SIM_SHISHI         //しし固定座標
  //#define DEBUG_GNSS_SIM_SHINURA2BIWA    //新浦安座標から琵琶湖座標に置換
  //#define DEBUG_GNSS_SIM_OSAKA2BIWA      //阪大座標から琵琶湖座標に置換
  //#define DEBUG_GNSS_SIM_SHINURA2OSAKA   //新浦安座標から阪大座標に置換

#if !defined(TEMP)
  #define TEMP
  #if !defined(RELEASE) || !defined(RELEASE_GNSS)
    #warning NOT RELEASE!
  #endif
#endif

// ============================================================
//  ハードウェア — ピン割り当て
// ============================================================

// Hardware Ver6
#define SW_PUSH 37  // v7 35->37に変更
#define BATTERY_PIN 40 //A0
#define GNSS_SERIAL Serial1

// GNSS の UART 受信リングバッファ [バイト]。既定 32 では全く足りない。
// ★ 大きさの意味は「**Core0 が止まっても取りこぼさない時間**」。
//   実流量は UBX のみで約 550 B/s（NAV-PVT 100B×2Hz ＋ NAV-SAT 約320B×1Hz
//   ＋ NAV-DOP 26B×1Hz）。回線速度 38400bps(=3840 B/s) ではなく**これで割る**。
//     1024B → 約 1.9 秒   4096B → 約 7.4 秒
//   以前のコメントは 1024B ÷ 3840B/s = 267ms と書いていたが、それは
//   **回線が飽和している前提の最悪値**で、実態の 7 倍きつい見積りだった。
//   RAM は 4096B でも全体の 1% 未満。ここを削る理由が無い。
#define GNSS_SERIAL_FIFO_SIZE  4096
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

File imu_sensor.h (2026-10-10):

// ============================================================
// File    : imu_sensor.h
// Project : PONS v7 (Pilot Oriented Navigation System for HPA)
// Role    : IMU チップと、その上に乗る推定（姿勢 ESKF・バリオ KF）の境界。
//           「どのチップでも同じ形で生データを流し込む口」と、
//           「そのチップに何が有るか／無いか」を表す能力ビットを定義する。
// Author  : MasaoC (@masao_mobile)
// Updated : 2026/10/10
// ============================================================
//
// ★ **この境界を作った理由。**
//   BNO085 を SCH16T-K01（Murata）へ差し替える予定だが、両者は種類が違う:
//     BNO085 … 中で融合までやる。姿勢・重力除去済み加速度・地磁気方位が出てくる
//     SCH16T … ジャイロと加速度しか出ない。融合は無い
//   0.983〜0.984 で機上の推定（ESKF・バリオ）から BNO085 の融合出力を全部外したので、
//   **必要なのはジャイロと加速度だけ**になった。残っている融合出力（GRV/RV）は
//   比較表示と健全性カウンタ専用。その「無くてもよい」を**型で表す**のがこのヘッダ。
//
// ---- 使い方 ----
//   ドライバ側（imu_bno08x.cpp / 将来 imu_sch16t.cpp）
//     ・生データが届いたら imu_feed_gyro() / imu_feed_accel() を呼ぶ。
//       これだけで姿勢 ESKF の伝播とバリオの蓄積がつながる
//     ・自分に何が有るかを imu_caps() で申告する
//     ★ **生ログ（imulog_push）はドライバ側に残してある。** レコードの `s_us`
//       （センサー時刻）と `acc`（申告精度）がチップ固有で、ここへ移すと
//       BNO085 時代のログとバイト互換でなくなる。過去ログを同じツールで読み続けるため
//   呼び出し側（画面・ログ）
//     ・融合出力に触る前に imu_caps() を見る。**「有って当然」と書かないこと。**
//       SCH16T では GRV / RV / LACC / 動的校正のどれも無い
//
// ★ 0.986 でファイルを割った（imu.cpp = チップ非依存 / imu_bno08x.cpp = BNO085）。
//   下の imu_drv_* がその契約。`imu_sch16t.cpp` はまだ無い。
//   段取りは [docs/imu_sch16t_plan.md](docs/imu_sch16t_plan.md) §1。
//   そこに **`imu_service_if_due()` の意味が SCH16T で変わる**ことも書いてある
//   （飢餓対策が不要になるが、**対策コメントは消さないこと**）。
//
#ifndef IMU_SENSOR_H
#define IMU_SENSOR_H

#include <Arduino.h>

// ============================================================
//  能力ビット — そのチップから「何が出てくるか」
// ============================================================
// ★ ジャイロと加速度は**全チップ必須**なので能力ビットを持たない。
//   無ければ姿勢もバリオも成立しないので、分岐させる意味が無い。
#define IMU_CAP_QUAT    (1u << 0)   // 融合クォータニオン（BNO085 の GRV 相当）
#define IMU_CAP_MAGYAW  (1u << 1)   // 磁北基準クォータニオン（RV 相当）＋ヘディング精度
#define IMU_CAP_MAG     (1u << 2)   // 生地磁気（0.984 で購読をやめたので BNO085 でも 0）
#define IMU_CAP_LINACC  (1u << 3)   // 重力除去済み加速度（LACC 相当）
#define IMU_CAP_CAL     (1u << 4)   // 動的校正と申告精度（BNO085 の DCD / accuracy）
#define IMU_CAP_STATUS  (1u << 5)   // 故障・飽和ステータス（SCH16T の S1:S0 / CE）

// いま載っているチップの能力。**融合出力に触る前にこれを見る。**
uint32_t imu_caps();
// ログ・画面に出す短い名前（"BNO085" / "SCH16T"）。
const char* imu_sensor_name();

// ============================================================
//  ドライバ → 推定 への口
// ============================================================
// ★ **チップ固有のコードが推定へ触るのはこの 2 つだけ。** 中で
//   姿勢 ESKF（attitude_on_*）とバリオの蓄積へ配る。生ログの push だけは
//   チップ側に残してある（上の「使い方」参照）。
//
// 単位と座標系（**守らないと静かに壊れる**）:
//   g[3] : センサー軸の角速度 [rad/s]。**バイアス補正前の生の値**
//          （ESKF が自分でバイアスを推定するので、引いて渡してはいけない）
//   a[3] : センサー軸の比力 [m/s²]。**重力を含んだまま**
//          （重力を引いた値を渡すと ESKF の伝播と水平化の両方が壊れる）
//   t_us : そのサンプルを受け取った時刻 [µs]（time_us_32()）。
//          **チップが付けたタイムスタンプを使わないこと。** BNO085 の
//          sv.timestamp は sh2 のアンダーフローで壊れている（0.983 の調査）。
void imu_feed_gyro(const float g[3], uint32_t t_us);
void imu_feed_accel(const float a[3]);

// ドライバがチップをリセット／復旧したときに呼ぶ。溜めた比力の平均を捨てる。
// ★ 捨てないと、復旧直後の predict が**途絶前の古いサンプル**を混ぜて積分する。
void imu_feed_reset();

// ============================================================
//  推定 → ドライバ への口（imu_drv_*）
// ============================================================
// ★ **実装はチップごとに 1 ファイルだけ。呼ぶのは imu.cpp だけ。**
//   画面やログからは imu.h の公開 API を使うこと（ドライバ自身も、
//   自分の中では imu_drv_* を呼ぶ ― 公開 API を呼ぶと層が逆流する）。
// ★ 各ドライバは**ファイル全体を `#if IMU_SENSOR_DEFAULT == ...` で囲う**。
//   Arduino は .cpp を全部コンパイルするので、囲わないと多重定義になる。

// imu_drv_poll() の戻り値。**分割前の imu_update() の 3 分岐に 1 対 1 で対応する。**
typedef enum {
    IMU_DRV_DEAD = 0,   // 居ない／途絶中。呼び出し側は恒速モデル（a_k=0）へ落とす
    IMU_DRV_WAIT,       // 生きているが、この回はポーリング周期に達していない
    IMU_DRV_SERVICED,   // この回でサンプルを引き取った。predict へ進んでよい
} ImuDrvState;

// バス初期化とセンサー起動。**成否は imu_drv_present() が答える**ので戻り値は持たない。
void imu_drv_setup();
// 途絶検出・復旧・サンプルの引き取り・レート計測を 1 回分進める。
ImuDrvState imu_drv_poll();
// サンプルの引き取りだけ（長いブロッキング処理の中から呼ぶ。再入可・副作用なし）。
void imu_drv_service_if_due();
bool imu_drv_present();   // 初期化に成功して「載っている」状態か
bool imu_drv_alive();     // 直近 1 秒以内にサンプルが届いているか

// VARIO_USE_RAW_ACCEL=0（LACC ベースの predict）の旧経路用。既定では使わない。
bool imu_drv_lacc_predict_sample(float a_body[3], float q[4], uint32_t* lacc_last_us);

#endif // IMU_SENSOR_H

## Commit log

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2024-07-15 minor fix
    Single switch adaption.
    Removing old codes.
    [CopySetupFile_TFT_eSPI.h, GPS_TFT_map.ino, display_tft.h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]
2024-07-15 mapdata
    merge gps_function and latlon
    [mapdata.csv]
2024-07-18 Bug fix
    Font files into 1 file
    Bug fix. TFT SPI v.s. UART RX issue fixed.
    [GPS_TFT_map.ino, display_tft.cpp, display_tft.h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]
2024-07-19 Major bug fix
    Bug uart connection with GPS fix
    [CopySetupFile_TFT_eSPI.h, GPS_TFT_map.ino, display_tft.cpp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]
2024-07-30 tools folder
    [2024-07-27_0936_edited.csv, mapdata.csv]
2024-08-06 hardware v3 adjustments
    ublox GSV parse
    nmea display option
    Voltage detector
    and more
2024-08-15 Ver0.4
    SdFat library adaption.
    Map image display function now available.
    tools/googlemap_api.py added to fetch map image.
    Example mapdata kml, csv updated.
    [mapdata.csv]
2024-08-16 Release 0.4 rev
    Fixed bugs
    [2024-07-27_0936_edited.csv, mapdata.csv]
2024-08-17 0.4 rev
    MapImage with Track up mode now supported.
    Constelation map updated.
    Mapimage scroll bug fix.
    [GPS_TFT_map.ino, display_tft.cpp, mysd.cpp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]
2024-09-14 v0.49
    Fixed possible memory leak.
    Changed text size of deg/s.
    Displaying MC.
    Updated setting mode ( Added set destination function and set destination mode)
    Still debugging about loop1 crash after running 1,2 hours.
    [CopySetupFile_TFT_eSPI.h, GPS_TFT_map.ino, display_tft.cpp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]
2024-09-15 Squashed commit of the following:
    commit 273d3e12e4ce5dbd8457224d45a6498dea22b5f4
    Author: Masao Chiguchi <masaochiguchi@gmail.com>
    Date: Sun Sep 15 12:45:36 2024 +0900
    test
    Debugged Core0 lacking stack issue.
    commit c87be28fe4a5df6abd9722a4f1a12aef6a7d1488
    Author: Masao Chiguchi <masaochiguchi@gmail.com>
    Date: Sun Sep 15 12:21:28 2024 +0900
    a
    temp debug
    [GPS_TFT_map.ino, display_tft.cpp, mysd.cpp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]
2024-09-16 v0.5 release
    Bolder text bolder needle.
    Erased Core1 restart function (Core0 Stack overflow issue resolved)
    Fly away bearing bug at far distance issue fixed.
    Drawing stroke uncommented.
    Minor issue fix
    [GPS_TFT_map.ino, display_tft.cpp, display_tft.h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]
2024-10-07 v0.51
    ・GPS LC86G adaption.
    ・NMEA sentence storage 14 lines.
    ・Destination initalization without SD card.
2024-10-19 v0.52
    ・Display Seer_to function added.
    ・Beeping function added.
    ・Bug fix (Serial read hung up)
    [GPS_TFT_map.ino, display_tft.cpp, display_tft.h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]
2024-10-27 0.60
    release 0.60
    bug fix of false tone at +/-TT360
    [mysd.cpp, settings.h, sound.cpp]
2024-10-28 Document and Kicad for PONSv4 (Software v0.60)
    Document and Kicad for PONSv4 (Software v0.60)
    [DisplayModule_PONSv4.kicad_pcb, DisplayModule_PONSv4.kicad_sch]
2024-10-28 v4 case
    Hardware v4 case model added.
    [case_v33.f3d]
2025-04-13 PONS v5 major update Software ver0.7
    Build 20250412
    ・Hardware change from Raspberry pi pico to pico2. (Faster CPU and more RAM)
    ・SDIO adaption. Faster SD card. Library changed from SdFat to standard SD lib.
    ・Speaker adaption. Any wav file from sd card (16kHz 8bit) can be played.
    ・Shutdown pin of amplifier installed for saving power.
    ・Any frequency of sin wave can be played now.
    ・eSPI setting file relocated to folder.
    ・UART FIFO size for GPS changed to 256.
    ・removeDuplicateTask function bug fixed.
    ・debounce time change 10ms -> 5ms
    [CopySetupFile_TFT_eSPI.h, GPS_TFT_map.ino, display_tft.cpp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]
2025-04-22 ver 0.80
    ・No more flickering display by using backscreen buffer.
    ・Save load settings.
    ・Layout change of navigation display.
    ・Removed strokerManager and textManager related functions due to backscreen.
    ・Removed bank warning
    ・Refactor by removed unnecessary codes.
    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
2025-04-27 ver 0.81
    ・SD card file detail mode added.
    ・NAV 10km destination automatic update mode added.
    ・wav Voices added.
    ・Scale measure changed from circle to bar.
    ・Lake biwa demo mode updated (track display etc.).
    ・Num sats emphasis when 0. And red bar on header when 0.
    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
    [case_for_v5.f3z, case_v4.f3d, case_v5_body.stl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]
2025-04-27 Kicad
    Kicad for hardware v5
    [DisplayModule_PONSv4.kicad_pcb, DisplayModule_PONSv5.kicad_pcb, DisplayModule_PONSv5.kicad_sch]
2025-04-29 v0.83
    Course warning
    [case_v4_body.stl, case_v4_cap.stl]
2025-04-29 bug fix
    Cause of bug was stack out of bound.
    so core1_separate_stack = true added
    drawWideLine introduced.
    Course warning introduced.
    [GPS_TFT_map.ino, display_tft.cpp, display_tft.h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]
2025-04-30 v0.84
    ・fly into magenta arrow Bug fixed.
    ・SD initialize bug fixed by placing Serial.println(""); before setup_sd in setup1.
    ・Refactor code for readability, relocated setup1 loop1 etc....
    ・Replaced to SdFat library for no big reason. Debug purpose.
    [GPS_TFT_map.ino, display_tft.cpp, mysd.cpp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]
2025-05-02 0.85 for release
    ・Setting menu文言修正
    ・現在位置の表示の表現を三角形から飛行機に変更。
    ・電圧計算方法微調整。
    ・DEMOモードの飛行経路を微調整。
    ・コース警報でChimeが鳴らないバグ修正。
    ・sdフォルダ追加。SDカードのバックアップ。
    [destinations.csv, mapdata.csv]
2025-05-10 0.87
    ・Improve navigation display readability. Bolder needle. Bigger font.
    ・Refactor codes for readability.
2025-05-11 minor fix
    minor fix for text location
    [display_tft.cpp, sound.cpp]
2025-06-28 Coordinates fix (0.871)
    Change of Platform, pilon, circle coordinates due to official rule release of Japan Birdman rally 2025
    [display_tft.cpp, settings.h]
2025-07-17 大会本番前微調整. 0.872
    ・Auto10kmの折り返し判定時のパイロン誤差を500mとして設定(10.475kmで折り返しモードに入る）
    ・TAKESHIMA,N_PILON,W_PILON設定時に、Auto 10km設定の禁止（設定しようとするとエラー音）
    ・Stabd by ... を Stand by に。Spellミス修正
    [GPS_TFT_map.ino, display_tft.cpp, settings.h]
2025-08-05 0.88
    ・Replay mode added.
    ・python file to create NMEA replay file added.
    ・createmovie 2025ver
2025-09-23 Bug fixes and improvements for stability.
    ・GNSS CSV not saved every second bug fixed.
    ・SETTING screen modified. Color filled circle to check setting is properly set or not for Bird-man Rally.
    ・GPS setup changed (V_BCKUP low issue.) retry setup when no response.
    ・startup demo modified.
    ・saves GPS altitude.
    [GPS_TFT_map.ino, display_tft.cpp, gps.cpp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]
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2026-03-09 0.9: TRACKUP実装・SAM-M10Q対応・airdata・バグ修正多数
    ### 主な変更内容
    ---
    #### 1. TRACKUP モード 本格実装（display_tft.cpp / GPS_TFT_map.ino）
    - draw_triangle() の TRACKUP 分岐を実装
    - 機体アイコン（固定・常に上向き）
    - True Track 維持針三角形（last_tone_tt を TRACKUP 座標系に変換して表示）
    - コース逸脱アーク（(millis/1000)%3≠0 の間、steer_angle に比例した赤弧）
    - 誘導三角形（15°/55°/100° の3段階）
    - draw_headertext(degpersecond) を draw_gs_track() にリネーム（引数不要になったため）
    - draw_replay_indicator() を追加（リプレイ中に赤枠 "REPLAY" を表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
    [GPS_TFT_map.ino, airdata.cpp, display_tft.cpp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]
2026-03-10 0.901: GSA解析・垂直速度・SDIO/SPIフォールバック・10bit音声PWM・WAVキュー 他
    新機能
    GPS / NMEA
    gps.cpp/h: GSA文を解析する parseGSA() を実装。フィックス種別（1/2D/3D）・PDOP/HDOP/VDOP・使用PRN（最大12）を取得・格納するgetter群を追加
    gps.cpp: UBLOX専用 UBX-CFG-RATE コマンドで測位レートを2Hz化。ナビ画面では GSV/GSA を0.1Hz、星図画面では1Hzに切り替え
    gps.cpp: GPS FIX 取得時に fixed.wav 再生（SDなければ ド-ミ-ソ 代替チャイム）、SDへのイベントログも追加
    GPS_TFT_map.ino: setup_sd(5→1) に変更。起動時の接触不良による長時間ブロックを防止（回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
    [GPS_TFT_map.ino, airdata.cpp, display_tft.cpp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]
2026-03-11 0.902: バリオメーター音声・VSI・トリム平均・SD_DETECT修正・バッテリー%表示 他
    ### バリオメーター音声（sound.cpp/h, GPS_TFT_map.ino, button.cpp）
    - update_vario() を新規追加。鉛直速度に応じた音をCore0から100msごとに更新
    - 上昇（>+0.4m/s）: 断続ビープ（700+vspeed*300 Hz、上限2200Hz）
    - 下降（<-0.4m/s）: 連続低音（480-|vspeed|*30 Hz、下限300Hz）
    - タイマー割り込みをWAV > Sinトーン > バリオの優先順位つき構造に変更
    - stopPlayback() / myTone() でバリオ使用中はアンプをOFFにしない
    - 旋回トーンを固定2093Hz 2回に変更（バリオ音との混同防止）
    - v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
    [GPS_TFT_map.ino, airdata.cpp, display_tft.cpp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]
2026-03-12 0.904: 最大G/S表示（5分保持/全時間）追加・DEMOモード対応
    ## 最大 G/S 表示機能の追加 (gps.cpp / gps.h / display_tft.cpp)
    - 起動後の全時間最大 G/S（maxgs）と直近 5 分保持最大 G/S（maxgs_5min）を追跡
    - 記録時の JST 時刻（時・分）も保持
    - マップ画面フッターの JST 時刻の 1 行上に表示
    - 両者が同値の場合は全時間最大のみ表示（冗長表示を抑制）
    - 異なる場合は「5分保持値@時刻 全時間最大値@時刻」の2項目表示
    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
2026-03-13 0.905
    ・DOPログ追加
    ・電圧低下時の電圧を修正。低電圧の警告音の再生ボリュームを強制。
2026-03-13 0.906
    ・Slow opening demo bug fix
    ・README update
    [display_tft.cpp, settings.h, sound.cpp]
2026-03-18 0.91 BNO085 IMU の Kalman バリオ統合・Euler角ログ・Vario詳細画面・処理時間計測を追加し、アーキテクチャを整備した。
    1. BNO085 IMU 統合（Core0バリオメーター）
    GPS_TFT_map.ino の loop() に imu_update() / imu_kalman_baro_update() を追加し、BNO085+MS5611 Kalman融合バリオが動作するようになった
    airdata_wire_begin() を airdata.cpp から独立させ、I2Cバス初期化を imu_setup() より先に呼ぶ構成に変更（BNO085のブート順序保証）
    I2Cクロックを 100kHz → 400kHz に変更（BNO085の起動時クロックストレッチング対応）
    setup() 内のセンサー初期化順序を TFT→IMU→Airdata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
2026-03-22 v0.911 — TRACKUP自機位置の下寄り化・GPS fix/HDOP状態別マーカー・トーン非ブロッキング化・SD初期化完了通知の4本柱。
    0.911: TRACKUP下寄り・HDOP不確かさ円・トーン非ブロッキング化・SD初期化完了通知
    ■ display_tft.cpp / .h
    - TRACKUP モードで自機Y位置を画面中央(cy=120)から下3/4(cy=180)に変更し、
    前方視界を広げた（get_self_cy() / get_needle_len() で一元管理）
    - GPS fix なし → グレーの × (draw_nofix_cross())
    HDOP ≥ 5.0 → 青い不確かさ円 (draw_hdop_circle()) を表示。
    リプレイ・デモ時は常に飛行機マーカーを使用
    - コース警告ボックス・コ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
    [GPS_TFT_map.ino, display_tft.cpp, display_tft.h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]
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2026-03-28 case 3D model for v6
    ・Removed case for v4 and v5 (Seek branch for older version please)
    ・Added v6 case 3D print data
    ・Removed unnecessary log2.txt file.
    [case_for_v5.f3z, case_for_v6.f3z, case_v4.f3d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]
2026-03-28 Kicad data for PONS v6 upload
    ・Removed v5 Kicad data (Refer Branch for v5)
    ・Add all v6 Kicad data.
    [DisplayModule_PONSv5.kicad_pcb, DisplayModule_PONSv5.kicad_sch, DisplayModule_PONSv6.kicad_pcb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]
2026-03-28 Add GNSS board kicad data.
    [DisplayModule_PONSv6.kicad_pcb, DisplayModule_PONSv6.kicad_sch, SAM-M10Q PONSv6 GNSS module.kicad_pcb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]
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2026-04-05 FPC connector upload
    FPC connector between boards
    [FPC.kicad_pcb, FPC.kicad_sch]
2026-07-14 0.920 PONS for v7 branch
    コース警報の頻度の修正
    [GPS_TFT_map.ino, display_tft.cpp, gps.cpp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]
2026-07-14 0.917 2026大会ルールへ座標修正
    北パイロン、竹生島側の座標が大きく変わったため。
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2026-08-01 0.922 リプレイ機能の拡充とリプレイに関するバグなど修正とツール追加
    ・パイロンまでの線の色の変更
    ・リプレイポーズ機能追加
    ・リプレイバグ（バリオ音止まらない）を修正
    ・tools/flightanalysis 追加
    [GPS_TFT_map.ino, display_tft.cpp, gps.cpp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]
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2026-08-06 0.923 WAV再生の巻き戻り不具合を修正、タスクキューの排他とバッファ安全性を強化
    ■ WAV再生の巻き戻り再生を修正（本件の主目的）
    track.wav などが1回だけの再生のはずが、稀に先頭に戻って1秒未満の再生を
    繰り返す問題を修正。原因は割り込み(timerCallback)がバッファ末尾で bufferPos を
    0 に戻すだけで bufferReady を落とさず、Core1 の loop_sound() が停止処理に
    来るまでの間、同じバッファの先頭から鳴らし直していたこと。
    track.wav は 0.571秒で1チャンク(16KB=1.024秒)に収まるため、巻き戻り位置が
    そのままファイル先頭にな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
    [GPS_TFT_map.ino, display_tft.cpp, gps.cpp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]
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2026-08-17 0.93 地図をSD BMPからフラッシュ内蔵OSMベクタへ移行
    SDカード上のGoogle Maps由来BMPタイルを廃止し、OpenStreetMap由来の
    ベクタ地図(1.4MB)をフラッシュに内蔵する方式へ移行。
    SD・APIキー不要、TRACKUPで画面四隅まで描画、座標更新時のI/Oゼロ。
    地図
    - vectormap.h/.cpp/_data.cpp を追加。LOD 4段・タイル分割・bbox早期リジェクト
    - 飛行7地点(琵琶湖/白浜/笠岡/富士川/東京湾/阪大/烏)を高精細＋本州広域＋全国
    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
    [mapdata.csv]
2026-08-17 0.931 微調整
    削除忘れの修正
    細かなバグ守成
    [GPS_TFT_map.ino, display_tft.cpp, display_tft.h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]
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2026-08-23 0.944
    ・南パイロンを西パイロンに改名
    ・リプレイモード中に不要な表示"ESKF CALIBRATION REQUIRED"が出ないよう修正
    [display_tft.cpp, settings.h]
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2026-08-28 0.947
    0.947 未使用コードを整理、リプレイに電圧・衛星数を追加、ロールトリム窓数を設定可能化
    コードとコメントの棚卸しを行い、使われなくなった定義・関数と、実装と
    食い違っている説明を整理した。あわせて、その過程で見つかった
    「実装が足りていない箇所」を修正した。
    ■ 削除（挙動は変わらない）
    - Mediatek GPS 対応: MEDIATEK_GPS は一度も define されたことがない死にコード
    - Quectel GPS 対応: v6 は u-blox SAM-M10Q 固定。PAIR_* と分岐一式を削除
    （PAIR_SET_38400 は二重定義になっていた）
    - 輝度調整一式: BRIGHTNESS_SET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
    [GPS_TFT_map.ino, airdata.cpp, display_tft.cpp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]
2026-08-28 0.948 飛行中の再起動でナビが逆を向く問題を修正、警告の取りこぼしとヨー表示のばたつきを対策
    「短い試験飛行では踏めず、本番でだけ動く経路」を洗い出し、そこに残っていた
    不具合を潰した。0.947 の棚卸しで見つかったものの続き。
    ■ AUTO10K の折返しフェーズを SD に保存する
    飛行中に再起動すると auto10k_status が AWAY に戻る。復路（INTO）で再起動すると、
    AWAY はナビ方位を 180 度反転させるフェーズなので矢印が真逆を指し、しかも距離は
    縮まる一方なので 10.475km の判定に二度と掛からず自動復帰しない。
    距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
    [GPS_TFT_map.ino, display_tft.cpp, gps.cpp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]
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2026-09-06 0.960 ソフトウェア＋ドキュメント KiCad v7 基板
    普段編集しないモジュールを src/ へ移動し、README を v7 に更新
    ■ src/ への移動（Arduino IDE のタブ削減）
    Arduino IDE はスケッチ直下のファイルを全部タブに出すため 28 個まで増え、
    目的のファイルを探しづらくなっていた。仕様が固まっていて普段いじらない
    4 モジュールを src/ へ移し、タブを 20 個に減らした。
    src/button.* ボタン入力・メニュー
    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
    [DisplayModule_PONSv6.kicad_pcb, DisplayModule_PONSv7.kicad_pcb, DisplayModule_PONSv7.kicad_sch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]
2026-09-06 kicadデータ更新
    KiCad プロジェクトを自己完結化（ライブラリテーブルと独自シンボルの取り込み）
    クローンしただけでは GPS_TFT: などのライブラリが解決できず、また一部の
    シンボルが KiCad 標準ライブラリ本体を書き換えて作られていたため、他の環境
    では正しく再現できない状態だった。プロジェクト内で完結するよう整理した。
    ■ ライブラリテーブルを追加
    fp-lib-table / sym-lib-table がリポジトリに一度も入っていなかった。
    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
    [MS5611BNO085.kicad_sch, SHT_RP2354B.kicad_sch]
2026-09-08 0.961 PONS Link の総点検。実機検証前に見つかった不具合を修正
    コンパイルが通っているだけで実機未検証だったため、コードとコメントの
    突き合わせを行った。実害のある不具合が 6 件見つかった。
    ■ 無線設定画面を開くと受信が止まる
    e220_read_noise() が先頭で受信バッファを捨てていた。この関数は mode 0 の
    まま、テレメトリと同じ UART で問い合わせる。受信モードで無線画面を開くと
    1Hz で呼ばれ、テレメトリも 1Hz で届くため、電波を確かめようとした画面が
    受信を殺していた。応答とテレメトリを同じ組み立て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
    [GPS_TFT_map.ino, display_tft.cpp, e220.cpp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]
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2026-09-08 0.961 KiCad更新 wav更新
    wav雑音除去
    kicad更新（スイッチ背面、DocへのQRコード更新）
    [DisplayModule_PONSv7.kicad_pcb, DisplayModule_PONSv7.kicad_sch, FPC.kicad_pcb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]
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2026-09-10 0.962 README を整理し、PONS Link 仕様書を実装に合わせた
    ■ README.md
    貼り付けで重複していた 4 か所（マスタースイッチの表示項目・内蔵地図・
    WAV ファイル名・SD ログ記録項目）を 1 か所ずつに統合。開発者向けの読み順に
    並べ替えた: 役割 → 概要 → スペック → 設計と根拠 → 画面と機能 → 警告音 →
    大会運用 → ハードウェア → SD カード → ツール → ライセンス。
    Google Doc（利用者向け説明書）と役割が被っていた設定画面の項目一覧と
    リプレイの操作手順は削り、しきい値と設計理由だけ残した。
    事実の修正:
    - 2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
    [display_tft.cpp, settings.h]
2026-09-10 0.962 SD カードまわりの不具合をまとめて修正
    ■ 受信ログのリプレイでヨーと風が出なかった
    received/ のヘッダは 180 文字あるのに init_replay() が char header[160] で
    読んでいた。末尾が "...,roll_trim,yaw_ac" で切れ、yaw_acc95 / wind_mps /
    wind_dir が拾えていなかった。列名で解釈する仕組みなのでエラーにならず、
    気づきにくい壊れ方をしていた。256 に広げ、実測の文字数をコメントに残した。
    ■ SD 復旧のたびに目的地が増え、選択が PLATHOME に戻っていた
    setup_sd() は try_sd_recovery() から飛行中にも呼ばれるのに、init_mapdata() と
    違っ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
    [GPS_TFT_map.ino, gps.cpp, mysd.cpp]
2026-09-10 0.962 BNO085 の復旧で Core0 を止めない。SPI 不在時のハングを塞ぐ
    ■ 復旧のたびに Core0 が 410ms 止まっていた
    imu_try_recovery() が delay(10)+delay(400) を直に通していた。GPS は 38400bps・
    FIFO 1024B なので約 270ms でバッファが溢れ、NAV-PVT を丸ごと取りこぼす。
    地図もボタンもバリオも同時に止まり、BNO085 が死んでいる限り 1 分ごとに繰り返す。
    NRST リセットと復旧手順の両方をステートマシンにして 1 ループ 1 段ずつ進める。
    IDLE ─(1分)─▶ RESET ─(410ms)─▶ WAITINT ─(H_INTN LOW)─▶ BEGIN ─▶ IDLE
    └─(300m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
    [settings.h]
2026-09-10 0.962 KiCad 更新、production を git 管理から外す
    fabrication-toolkit が生成する production/ は発注のたびに作り直せるうえ、
    基板を直すたびに巨大な差分になるので .gitignore に追加した。
    [DisplayModule_PONSv7.kicad_pcb, DisplayModule_PONSv7.kicad_sch, MS5611BNO085.kicad_sch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]
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2026-09-10 0.963 電池低下警告の穴を塞ぎ、点検で見つかった不具合をまとめて修正
    ■ 自機の電池低下警告が鳴らない場面があった
    発報が draw_footer() の中にあったため、2 つの穴が開いていた。
    1. draw_footer() は地図画面からしか呼ばれない。設定画面・WIRELESS 画面・
    IMU/ESKF 画面を開いている間は電圧が下がっても鳴らなかった。
    2. 受信モードでは電池表示が別の分岐（S/R の 2 台ぶん表示）に入るため、
    **一度も鳴らなかった**。追走ボートとプラットフォームは常に受信モードなので、
    実質「ボートの電池切れは警告さ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
    [DisplayModule_PONSv7.kicad_pcb]
2026-09-10 ヘッダ調整
    全ファイルのヘッダ修正
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2026-09-11 README の文章配置と言い回しを読みやすく修正
    - 画面レイアウト説明で『画面中央』の子項目として書かれていた『姿勢表示』(実際は画面左下)を独立項目に修正し、記述位置と実際の表示位置の不一致を解消
    - 警告音・警報の一覧を『旋回・航路系/目的地系/電源系』でグルーピングし直し、テーマが混在していた並びを整理
    - 発注受付の価格説明を1段落の羅列から箇条書きに変更
    - 『以下推奨設定PCB推奨発注設定』という壊れた言い回しを修正
    - ドキュメントの役割の冒頭説明の重複を整理、不要な空行を削除
    内容(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
2026-09-13 0.965 ナビゲーションの点検と修正、仕様書を追加
    ナビゲーション周りを通しで点検し、見つかった不具合を直した。
    ■ 判断が地図画面を出している間しか動かなかった
    Auto10km の折返し判定・コース逸脱警報・旋回角速度の更新が MODE_MAP の
    分岐の中にあり、設定画面や各詳細画面を開いている間は全部止まっていた。
    とくに INTO→AWAY（目的地から 1.5km 以内）は「そのとき近くにいるか」で
    判定するので、地図画面を離れている間に通り過ぎると二度と成立しない。
    nav_alarm_tick() に切り出して loop() の最上位へ移した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
    [GPS_TFT_map.ino, display_tft.cpp, mysd.cpp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]
2026-09-13 0.965 README の旋回角速度・修正矢印の記述を実装に合わせた
    README が 1Hz GPS 時代の値のままだった。
    ・旋回角速度の平均窓は 4 サンプル＝GNSS 3 間隔。2Hz なので 3 秒ではなく 1.5 秒。
    ・着色のしきい値は 2.0deg/s ではなく 1.0deg/s（別途 対地速度 2.0m/s のゲートがある）。
    ・修正矢印は 55° 超で 2 本目が出るが、記載が無かった。
    あわせて、真方位へ統一したときに消し忘れていた
    nav_update() 呼び出し箇所のコメント「磁気コース(MC)」を「真方位コース(TC)」に直した。
    [GPS_TFT_map.ino]
2026-09-13 0.965 ナビの数値の丸めを直し、航跡描画の無駄を削った
    ■ 旋回角速度に ±0.67deg/s の量子化ノイズが乗っていた
    update_degpersecond() が真方位を int で受けていた。窓の中で差分を積むと
    切り捨て誤差は両端の 2 つだけが残るため、誤差 1 度 ÷ 窓 1.5 秒 = ±0.67deg/s。
    真値 1.00deg/s が開始位相によって 0.67 にも 1.33 にもなる計算で、
    着色 1.0 / 強調 3.0 / コース警報の「修正中」判定 0.5deg/s に対して無視できない。
    配列は元から float、GNSS も NAV-PVT の headMotion（分解能 1e-5 度）なので
    捨てていたのはここだけだった。float で受け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
    [GPS_TFT_map.ino, display_tft.cpp, display_tft.h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]
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2026-09-16 0.965 音量0の間、次のWAVの優先度判定が壊れていたのを修正
    startPlayWav() は wav_playing_priority を代入する前に、音量 0 のときの
    早期 return（アンプを ON にしないためのポップノイズ対策）を通っていた。
    音量 0 の WAV も wav_playing=true のまま「無音で再生中」になる
    （バッファは回り、SD も読み、EOF で正常に終わる）。その間
    wav_playing_priority が前に鳴った WAV の値のまま残るため、
    次に来た WAV の割り込み判定が狂っていた。
    実害は最低保証音量を入れた目的そのもので、音量 0 でも鳴るはずの
    battery_low.wav（優先度 1・最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
    [sound.cpp]
2026-09-17 0.966 BNO085 SPI 経路の実機投入前修正（ハング・ブロック・リトライ）
    SPI 化してから一度も実機に通していないため、ライブラリと SH2 スタックまで
    追って点検した。4 件直した。
    ■ sh2_getMetadata() で起動しなくなる経路があった（最重要）
    settings.h のコメントは getProdIdOp だけが timeout_us を持たないと書いていたが、
    実際は sh2.c の sh2_Op_t 初期化子 17 個すべてが timeout_us を省略している
    （= 0 = 無期限）。INT の生存確認は begin_SPI() の手前までしか守らないので、
    その後に呼ぶ sh2_getMetadata() は無防備だった。getFrsOp は .rx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
    [settings.h]
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2026-09-17 0.966 気圧センサーの不調が音響警報を全停止させる問題を修正
    ■ MS5611 が起動後に無応答になるとタスクキューが溢れていた（最重要）
    ms5611_ok は airdata_setup() でしか書かれず、実行中に false にならない。
    airdata_update() は毎ループ呼ばれるので、無応答になると IDLE →
    ms5611_start_convert() → ms5611_write_cmd() が失敗するたびにログタスクを積み、
    ループ 100Hz でも 0.5 秒足らずでキュー(40)が溢れる。溢れると USERLED 永続点灯に
    加えて**以降のタスクが全部捨てられる**ので、バンク角警告もコース警報も
    電池警告も鳴らなくな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
    [airdata.cpp, settings.h]
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2026-09-18 0.967 PONS Link の不具合修正と、立ち上げ試験に効く機能追加
    ■ 送信機 2 台を検出しても受信機の画面に何も出ていなかった
    link_dup_sender() が宣言・定義されているのにどこからも呼ばれておらず、
    音が 1 回鳴るのと 60 秒ログに残るだけだった。送信機は送信の合間 mode 3 で
    寝ていて受信できないので、飛行中にこれを検出できるのは受信機だけ。
    にもかかわらず TX 側のプリフライトには表示があり、飛行中に効く RX 側に
    無いという逆転が起きていた。地図に赤いポップアップ
    （DUP SENDER !! / 2 TX ON SAME CH/GROUP）を出す。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
    [GPS_TFT_map.ino, display_tft.cpp, display_tft.h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]
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2026-09-22 0.972 BNO085 のマウント変換を四元数化し、設定画面のフリーズを修正
    v7 実機で BNO085 が動き出したことで出てきた不具合をまとめて直した。
    - マウント補正を Euler の組み替えからクォータニオン回転へ。v7 は IC が基板裏面・
    1 番ピンが天という配置で、機体が水平のときセンサーがジンバルロック
    (sensor_pitch = ±90) に入る。角を入れ替える旧方式では原理的に直らない。
    変換は実機で静止時の生加速度（＝重力ベクトル）を 3 姿勢測って決め、
    settings.h の IMU_MOUNT_Q* 4 つに集約した。マウントを変えたら測り直して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
    [MS5611BNO085.kicad_sch]
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2026-09-23 0.975 BNO085 の復旧不能バグを修正し、E220 の設定変更と送信を作り直した
    ■ BNO085 の通信途絶からの復旧が、一度も成功していなかった
    取り込んだ SH-2 ドライバの SHTP インスタンスプールは MAX_INSTANCES=1 で、
    空き判定は instances[n].pHal == 0。これを 0 に戻すのは shtp_close() だけなのに、
    Adafruit_BNO08x::_init() は sh2_open() を呼ぶだけで close しない。
    そのため **2 回目以降の begin_SPI() は構造的に必ず失敗する**。
    症状は「リセット後に INT は返る（＝チップは生きている）のに recovery FAILED」。
    imu_bus_begin() が再オープンの前に sh2_clo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
    [GPS_TFT_map.ino, airdata.cpp, display_tft.cpp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]
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2026-09-27 0.978 リプレイ中の送信を止め、VSI と重なる枠の点滅と RX バッジの重なりを直した
    ■ リプレイ中は送信しない（TX）
    apply_replay_row()（gnss.cpp）は stored_latitude / stored_fixtype など
    **実センサーの格納変数そのものを上書きする**ので、TX のまま再生すると
    **過去の飛行を「いまの飛行」としてボートへ流していた**。fixflags も立つため、
    受信側からは正常な現在位置と見分けがつかない。docs/pons_link.md が一貫して
    避けている壊れ方（画面上は正常なまま間違った値が出る）そのもの。
    地上での確認作業で電波を出す理由も無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
    [GPS_TFT_map.ino, display_tft.cpp, display_tft.h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]
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2026-10-08 0.986 新基板（SCH16T 外付け）の kicad を追加し、ガーバー出力を git から外した
    kicad/IMU_murata/ — SCH16T-K01-10 のブレイクアウト（新規）
    本体の J7（Molex 200528-0080・8pin FPC）へ 1:1 ケーブルで繋ぐ外付け基板。
    J1 のピン順を本体 J7 と一致させてある（1=+3V3 2=RESET 3=MOSI 4=CS 5=SCK
    6=SYNC 7=MISO 8=GND）。シンボルとフットプリントも同梱。
    - ★ R2（CS-GND の 4.7k）は実装しない。CS は負論理なので、プルダウンすると
    MCU が駆動していない間セレクト状態になる。R1（EXTRESN プルアップ）は実装する
    - 本体側の GPIO 割り当ては settings.h の SCH1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
    [DisplayModule_PONSv7.kicad_pcb, DisplayModule_PONSv7.kicad_sch, FPC.kicad_pcb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]
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2026-10-11 0.988 受信機のナビ判定を電波の刻みで回し、地上チェックの音声・縮尺・MAX G/S を送信機に合わせた
    受信機のナビ判定が自機の GNSS で止まっていた（実機で発覚）
    ミラー中の「値」は accessor が機体のものに差し替えるが、**「新しい位置が来た」
    という刻みは自機の GNSS だけが作っていた**。そのため受信機の GNSS が不調だと
    ナビの判定が丸ごと止まり、画面だけが生きているように見えていた。
    - fix 未確定（`ubx_pos_valid` が立たない）: Auto10km の INTO/AWAY、
    `100km 以上離れています`、緑の航跡が止まる
    - 配線が抜けて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
2026-10-13 0.990 送信機の GNSS 断線を受信機へ伝え、巨大関数とファイルを分割した
    送信機の GNSS モジュール断線を受信機へ（安全の穴）
    送信機の GNSS が抜けると `stored_*` が凍ったまま送信は続き、`fixflags` も
    `numsat` も最後の値のまま、`seq` は進むので `NO SIGNAL` にもならない。つまり
    **ボートからは「止まった正常な機体」に見え**、音も画面も出なかった。
    - `LINK_ST_GNSS_LOST`（0x0080）を追加。受信側は**送信機と同じ下降 2 音**
    （784→392）を同じ間隔（30 秒）で鳴らし、復帰時は上昇 2 音を 1 回。
    WIRELESS 画面の `Sender :` 行にも `G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
2026-10-15 安全上の重要なお知らせ: MCP73831 充電回路のコンデンサ抜けについて
    充電IC MCP73831(本バージョンではU4)の VDD/VBAT に必要な 4.7uF コンデンサが設計上入っていなかった
    不具合を発見。電源スイッチ投入時のチャタリングで IC に過電圧が加わり、ごく稀に IC が故障し、
    発熱・電源が切れなくなる可能性がある。改修が完了するまで使用中止を呼びかける注意書きと
    修正方法(kicad/mainboard/SHT_RP2354B.kicad_sch の U4)を README 先頭にまとめて記載。
    Claude-Session: https://claude.ai/code/session_014mWt2rX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
2026-10-22 0.994 GNSS の翌日起動を速くし、本番前チェック・高温充電の警告・電池低下の点滅を入れ、v7.1 基板の逆接保護と発注前の修正を仕上げた
    - GNSS: AssistNow Autonomous を有効化（CFG-VALSET で RAM と BBR。settings.h の
    GNSS_USE_ANA。0 でも OFF を書き込む＝BBR に残った ON を消すため）。前日と同じ時間帯の
    起動が 23〜28 秒 → 3〜4 秒（BT1 が生きていること）。NAV-AOPSTATUS を 1Hz で受け、
    GNSS DETAIL 3 に ANA:ON data/use/calc、log.txt に「... after boot」（TTFF）・最初の
    測位の軌道の出どころ・10 分ごとの計算時間。ACK 待ちの間も imu_service_if_due(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
2026-10-23 0.995 ブランチ分離の消し忘れを直した（無線立ち上げ手順書の M0/M1 を GPIO31 に・IMU を SCH16T に、SCH16T では選べない切り替え 2 つを #error に、BNO085 前提のコメントと文書を直し、使われていない link_rx_telem を消し、README から v7 の MCP73831 の注記を外した）
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2026-10-31 1.00 Flight Viewer風向・WebSerial転送の修正、受信CSVの欠損空欄化、過放電・充電推定の整合、ドキュメント復元
    - Flight Viewer（tools/flight_viewer/index.html）:
    - 風向（wind_dir）の物理定義（風が吹いていく方位）に合わせ、推定TASを減算（gs - cos(yaw - wdir) * wspd）に、風矢印の +180 を削除。
    - WebSerialデータ転送時のCRC32照合をファイル本体データのみで計算するよう修正し、行末完全性チェックを追加。
    - 再接続時のファイル一覧取得不具合を解消（CONNECT/LIST開始時にキャンセル要求フラグをクリア）。
    - 転送中・一覧表示中の60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
2026-11-02 1.01 メイン画面充電ポップアップ新設・RTC電池4段階安全評価、回路修正（NCP360・Q3/Q4ゲート共通化・LEDコンデンサ）、SCH16T/ESKFクリーンアップ
    - 電源・充電ダッシュボード・RTCバックアップ管理:
    - メイン画面（NAV地図画面）にUSB充電・地上静止時の通知ポップアップ（draw_charge_popup）を新設。残量%、残り時間、90%確実目安時間、通電経過時間、RTCバックアップ目安、赤LED消灯案内を表示。
    - ボタン操作時に15秒間ポップアップを一時非表示（スヌーズ）にする処理を追加。
    - 満充電到達時刻ラッチ（s_chg_full_since_ms）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
2026-11-10 1.04 コード監査のバグリスト（docs/pons_bug_list.md・72 件）を 1 件ずつ確かめ、本当だったものを直した（誤検出は直さず理由を記録。実機未確認）
    結果の一覧は docs/pons_bug_list.md の「第0部：検証結果」。誤検出は BUG-01・02・10・13・22・27・31・33・45・55・56・67 と、
    一部の項目（BUG-57(2)・68(4)・72(2)(3) など）。主な直し:
    - 無線: ミラー中は電波のフレームだけを刻みにし、送信機が fix していないフレームでは位置を進めない
    （(0,0) で Auto10km が復路へ切り替わり SD に保存していた）。航跡の間隔は機体の速度で。
    グル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
2026-11-12 1.05 2026-11-11〜12 の実機ログからの直しをまとめた。USB を抜くと電池の % が 8〜10% 下がるのを直し（CHG_*）、PC の時刻を入れたあと BT1 の記録が残らないのを直し、SCH16T をタイマー割り込みで読むようにして（250Hz・gapmax 4ms）描画の中でも IMU を受け取りに行くようにし、動いているときに 60° 以上ずれた傾きを比力で置き直す（方位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
2026-11-13 1.06 1.05 から上げた（Build 20261113）。バリオは GNSS の上下の速度を V/S に入れないようにした（KF_GNSS_VEL_ENABLED 0。GNSS の高度で気圧の基準を直す処理は残す）。IMU / ESKF 監査の追加リストを確かめて直した（BUG-60 割り込み読みで加速度の鮮度の安全網が働いていなかった、BUG-62 IMU の途絶明けは傾き・方位の不確か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
2026-11-14 1.07 1.06 から上げた（Build 20261114）。全 9 カテゴリのコード監査（BUG-67〜130）を実施して修正し、ホスト単体テスト 3 本（wire2_test・vario_test・dbd_test）とリリース前の一括チェックスクリプト（tools/check_release.py）および GNSS 基板の合否チェックリストを追加した。ほかに BeiDou B1I 切り替え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
